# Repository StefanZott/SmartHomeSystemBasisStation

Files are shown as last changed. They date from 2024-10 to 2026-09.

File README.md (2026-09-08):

# SmartHomeSystemBasisStation

## Kurzbeschreibung

SmartHome-Basisstation auf Basis des **ESP32-S3** mit eigener Platine, ESP-IDF-Firmware und Web-Oberfläche zur WLAN-Konfiguration und Gerätediagnose. Das Repository bündelt Hardware (KiCad), Firmware und SPIFFS-Web-Assets in einem Projekt.

## Architektur-Überblick

| Pfad | Inhalt |
|---|---|
| `main/` | Firmware (ESP-IDF), Einstieg `main.c` |
| `spiffs/` | Web-UI (HTML, CSS, JS) → SPIFFS-Image |
| `pcb/` | KiCad-Schaltplan und Layout der Basisstation |
| `docs/` | Projektdokumentation und Anwenderdoku |

Stückliste und Pinout: [docs/project/hardware.md](docs/project/hardware.md)

## Toolchain

- **Firmware:** [ESP-IDF](https://docs.espressif.com/projects/esp-idf/) **v5.5.2** für ESP32-S3, Build über `idf.py`
- **IDE:** VS Code mit ESP-IDF-Erweiterung; optional Dev Container (`.devcontainer/`)
- **Hardware:** KiCad 8/9 — Projekt unter `pcb/BasisStation/`

## Deep Dive

Technische Architektur, Module, Startablauf und Verzeichnisstruktur:

→ [docs/project/architecture.md](docs/project/architecture.md)

Weitere Themen: [Kommunikation](docs/project/communication.md) · [Sicherheit](docs/project/security.md) · [Speicher-Layout](docs/project/memory_map.md)

## Deployment

Build, Flash und Monitor (Kurzfassung):

```text
idf.py set-target esp32s3
idf.py build
idf.py flash monitor
```

Ausführliche Anleitung, Partitionierung und Voraussetzungen:

→ [docs/project/architecture.md#deployment](docs/project/architecture.md#deployment)

## Release & Tags

Aktuelle Firmware-Version: siehe Datei [`version`](version) (Format `X.XX.XXX`, derzeit `0.00.001`).

| Tag (Beispiel) | Bedeutung |
|---|---|
| `v0.00.001` | Veröffentlichte bzw. testbare Firmware-Version |
| `release` | Marker für den aktuellen Release-Stand im Repository |

Kundenspezifische Builds: `v0.00.005-kundexyz`. Details: [docs/userdoc/git_guidelines.md](docs/userdoc/git_guidelines.md).

Agenten-Regeln und Workflow: [CLAUDE.md](CLAUDE.md)

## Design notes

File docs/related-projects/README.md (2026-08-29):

---
status: active
last_updated: 2026-06-02
type: placeholder
---

# Verzahnte Projekte

Schnittstellenverträge zu anderen Projekten (gemäß CLAUDE.md §7).

| Datei | Thema |
|---|---|
| [project-scope.md](project-scope.md) | Produktscope, Entscheidung NRT/UART, dokumentierte Schnittstellen |

Weitere Dateien (z. B. Cloud-Backend) folgen bei Bedarf.

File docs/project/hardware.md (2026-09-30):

---
status: active
last_updated: 2026-09-30
type: project-doc
---

# Hardware — SmartHome-Basisstation

KiCad-Layout und physische Schnittstellen der SmartHome-Basisstation auf Basis **ESP32-S3-WROOM-1U-N16R8**.

## Zielbild

Smart-Home-Basisstation mit Tastern, USB-C-Debuganschluss, PROG-Header, WLAN-Antenne, vier LEDs (Rot, Grün, Blau, Gelb) und **Ethernet** über W5500.

## Physische Schnittstellen

| Schnittstelle | Zweck |
|---|---|
| USB-C (`J1`) | Debug- und Datenanschluss: natives USB-Serial-JTAG des ESP32-S3. Flashen und On-Chip-Debugging über einen Stecker. Keine Stromversorgung über diesen Port. |
| PROG (`J6`) | 6-poliger Header: Firmware flashen über UART (alternativ über `J1`) |
| WLAN | Externe 2,4-GHz-Antenne über U.FL-Pigtail und RP-SMA-Gehäusebuchse (Modul **1U**) |
| Ethernet | Kabelgebundene Netzwerkverbindung über **WIZnet W5500** (SPI). Architektur und Begründung: [ethernet.md](ethernet.md). Schaltplan in Arbeit (SHBS-5), Layout offen (SHBS-10), Firmware offen (SHBS-11) |

**Separater JTAG-Header entfallen.** Der ESP32-S3 bringt USB-Serial-JTAG im Chip mit; On-Chip-Debugging läuft über `J1`. Der frühere 10-polige Header `J5` wurde deshalb aus dem Schaltplan entfernt — ein Steckverbinder und dessen Platinenfläche weniger.

## Steckverbinder (KiCad / BOM)

Im BOM werden u. a. Würth-Stecker **61201021621** (10-pol) und **61200621621** (6-pol) genannt — Details und Signalbelegung im jeweiligen KiCad-Schaltplan bzw. Datenblatt.

Ausführliche Stückliste mit Links: `README.md` (Abschnitt Hardware) — bei Änderungen auf **ESP32-S3-WROOM-1U-N16R8** abstimmen (README enthält teils gemischte Modulreferenzen).

## WLAN-Antenne (U6, ESP32-S3-WROOM-1U-N16R8)

Das Modul **1U** hat **keine PCB-Antenne**; der RF-Anschluss ist ein **IPEX/U.FL**-Stecker am Modul. Ohne externe Antenne ist WLAN nicht nutzbar.

### RF-Kette (mechanisch, kein Kupfer-RF auf der Platine)

```
U6 (IPEX) ←steckt→ ANT1 Pigtail ←SMA-Bulkhead→ Gehäusewand ←schraubt→ ANT2 Antenne (außen)
```

| Referenz | Teil | Funktion |
|---|---|---|
| **ANT1** | Taoglas **CAB.6061** | U.FL → RP-SMA female bulkhead, 100 mm Koax, mit O-Ring |
| **ANT2** | Taoglas **GW.20.A151** (Nachfolger der abgekündigten GW.20.5150) | 2,4 GHz Dipol, 2 dBi, RP-SMA male |

Beide Teile sind im Schaltplan `BasisStation_Layout.kicad_sch` als **mechanische BOM-Einträge** (`on_board no`) dokumentiert — sie werden **nicht** auf die Leiterplatte gelötet.

**Polarität:** Pigtail und Antenne müssen **RP-SMA** (Reverse Polarity) sein — nicht mit Standard-SMA mischen.

### Montage

1. Nach SMD-Bestückung: U.FL-Stecker von ANT1 vorsichtig auf den IPEX am Modul U6 aufklicken (gerade, ohne Zug auf dem Kabel).
2. RP-SMA-Bulkhead von ANT1 durch die **Gehäusebohrung** führen und mit der mitgelieferten Mutter fixieren (O-Ring zur Dichtung).
3. ANT2 von außen auf die Bulkhead-Buchse schrauben.

### Gehäuse und PCB — Platzierung

| Thema | Empfehlung |
|---|---|
| **SMA-Bohrung** | Ca. **6,5 mm** Durchmesser für RP-SMA-Bulkhead (exakter Wert im Datenblatt CAB.6061 prüfen). |
| **Bulkhead-Position** | **Rechte Gehäusewand**, auf Höhe des U.FL-Steckers (Platine y ≈ 96, seit SHBS-52). Der Kabelweg ist dann ca. 18 mm lang und gerade. Weit weg von Metallflächen und anderen HF-Quellen |
| **Abstand U6** | Kein dichtes Metall/Kupfer direkt am IPEX-Anschluss; Kabel nicht über USB-, Ethernet- oder Magnetics-Bereiche führen. |
| **PCB-Layout** | Kein RF-Routing auf der Platine nötig. U6 sitzt seit SHBS-52 rechts auf halber Höhe, der U.FL-Stecker zeigt zur rechten Wand. Zwischen Stecker und Wand liegt kein Bauteil, J6 sitzt 6 mm tiefer |

### BOM / Beschaffung

Mouser-Referenzen: CAB.6061 → **`960-CAB.6061`** (845 ab Lager, Stand 2026-09-22). Alternativ gleichwertige U.FL→RP-SMA-Bulkhead- und 2,4-GHz-RP-SMA-Antennen-Kombinationen — **Polarität und Steckertyp beibehalten**.

`ANT2` ist seit 2026-09-23 (SHBS-16) der Taoglas-Seriennachfolger
**`GW.20.A151`** (`960-GW.20.A151`); der ursprünglich vorgesehene `GW.20.5150`
ist abgekündigt. Form, Anschluss und Gewinn sind gleich (2 dBi, 2,4 GHz,
RP-SMA(M) gerade), eine weiße Variante `960-GW.20.A151W` gibt es ebenfalls.
Taoglas führt bei Mouser inzwischen das Präfix `960-` statt `742-`. `ANT1` und
`ANT2` sind mit `on_board no` reine BOM-Einträge; kein Footprint betroffen.
Aktuelle Preise und Lager: bestellfähige Stückliste (Abschnitt unten).

Symbol-Bibliothek: `pcb/Bauteile/Mechanical/mechanical.kicad_sym` (`WLAN_Pigtail`, `WLAN_Antenna`).

## Debug-/Datenanschluss J1 (SHBS-6)

`J1` ist eine **USB-C-Buchse** (Amphenol **12401598E4#2A**, dieselbe Bauform wie der Versorgungsport `J_PWR1` — eine BOM-Position für beide). Symbol: `Connector:USB_C_Receptacle_USB2.0_16P`, Footprint: `shbs_power:USB_C_Receptacle_Amphenol_12401598E4-2A`. Bis 2026-09-23 war die inzwischen abgekündigte `12401548E4#2A` vorgesehen; Unterschiede und Folgen fürs Layout siehe [power_supply.md](power_supply.md) (Abschnitt Buchsenwechsel).

| Eigenschaft | Umsetzung |
|---|---|
| Datenpfad | `J1` → ESD-Array `U1` (D3V3XA4B10LP-7) → `U6.14`/`U6.13` (GPIO20/GPIO19, USB_D+/USB_D−) |
| Steckrichtung | Beide Datenpaare gebrückt (`A6`+`B6` = D+, `A7`+`B7` = D−) — Stecker funktioniert in beiden Orientierungen |
| Rolle | **Sink/UFP**: je 5,1 kΩ **Rd** von `CC1` (`R21`) und `CC2` (`R22`) gegen GND |
| VBUS | Netz `VBUS_J1`, endet am ESD-Array. **Keine Versorgung über diesen Port** |
| SBU1/SBU2 | Unbeschaltet (No-Connect) |

**Zwei getrennte Ports.** Versorgung läuft ausschließlich über `J_PWR1` (siehe [power_supply.md](power_supply.md)), `J1` ist reiner Datenanschluss. Zum Flashen sind daher **zwei Kabel** nötig. Ein gemeinsamer Port und eine ORing-Lösung wurden verworfen; da `VBUS_J1` nirgends auf die Versorgungsschiene führt, besteht kein Rückspeise-Risiko zwischen den Ports.

Schaltplan: `pcb/BasisStation/BasisStation_Debugging.kicad_sch`.

**Layout (SHBS-22, 2026-09-27):**

- **U1 als Durchgangs-Bauteil:** Jede Leitung läuft gerade unter dem
  Gehäuse durch, von Pad 10→1 (USB−), 9→2 (USB+) und 7→4 (VBUS_J1). Neben
  den breiten GND-Pads 3/8 sind die Durchgänge für USB+ und VBUS_J1 nur
  0,15 mm breit. Der Footprint selbst hat nur 0,15 mm Padabstand; die
  5 DRC-Meldungen dazu sind footprint-bedingt und werden ausgeschlossen.
- **Brücken im Pad-Feld von J1:** D+ B6→A6 auf F.Cu. D− B7→A7 kreuzt D+
  geometrisch und läuft daher über ein Via oberhalb der B-Reihe
  (89,5 / 33,8) auf B.Cu zum USB−-Via (88,5 / 38,0). VBUS_J1: B4→A9 und
  B9→A4. Die Gruppe A4/B9 ist von CC1 eingeschlossen und geht über ein Via
  (90,85 / 37,6) auf B.Cu zu einem Via unter U1-Pin 4 (87,8 / 44,0).
- USB D+/D− sind seit der Verlegung von U6 (SHBS-52) 138 bzw. 124 mm lang,
  mit je 3 Vias. Für USB Full-Speed (12 Mbit/s, Anstiegszeit einige ns) sind
  Länge und Längenunterschied (14 mm, ca. 0,1 ns) unkritisch.

## Stromversorgung (SHBS-4)

Primäre Versorgung: **USB-C 5 V → AP3211 Buck → 3,3 V** (bis SHBS-17: MP2359, abgekündigt). PS2/+12V entfernt.

Ausführliche Dokumentation (Schaltplan, BOM, Pinbelegung, Verdrahtung): **[power_supply.md](power_supply.md)**.

**Layout-Stand (2026-09-26, SHBS-21):** Buck-Wandler kompakt um PS1 platziert, +3V3 zu U6 und zu den LED-Anoden geroutet. Details und Begründung der Leitungsführung: [power_supply.md](power_supply.md), Abschnitt „Platzierung Buck-Wandler“.

## Status-LEDs (SHBS-9)

Vier Status-LEDs, **direkt vom GPIO getrieben**: GPIO → Vorwiderstand →
LED-Anode, Kathoden gemeinsam auf GND. Ein GPIO auf **High** schaltet die
zugehörige LED **ein**.

| LED | Farbe | GPIO (Modul-Pad) | Vorwiderstand (0805) |
|-----|---|---|---|
| `D7` | Gelb | GPIO21 (23) | `R13`, 220 Ω |
| `D9` | Rot | GPIO38 (31) | `R15`, 220 Ω |
| `D10` | Grün | GPIO47 (24) | `R16`, 220 Ω |
| `D8` | Blau | GPIO48 (25) | `R14`, 100 Ω |

**Warum ohne Transistoren (SHBS-40, 2026-09-30):** Bis dahin schaltete je
ein NPN-Transistor BC337 (Q1–Q4, Basiswiderstände R23–R26) die LED gegen
GND, Vor- und Basiswiderstände waren 2-W-THT-Typen (DIN0617, 17 mm). Ein
Hardware-Review hat beides als überdimensioniert bewertet. Ein GPIO des
ESP32-S3 liefert bei der Standard-Treiberstufe rund 20 mA, bei der höchsten
rund 40 mA. Eine LED braucht hier etwa 5 mA, alle vier zusammen 20 mA. Der
Treiber entfällt damit ersatzlos; an den Widerständen fallen nur einige mW
ab, 0805 reicht mit großer Reserve.

**Symbol und Polarität (SHBS-16, 2026-09-23):** Alle vier LEDs nutzen
`Device:LED` (Pin 1 = Kathode, Pin 2 = Anode). Die beiden Würth-Footprints
`WL-TMRC_3MM` (D7, D10) und `WL-TMRW_3MM` (D8, D9) sind gleich nummeriert:
Pad 1 = Kathode (abgeflachte Seite), Pad 2 = Anode (`+` im Bestückungsdruck).
Das war nicht immer so — `WL-TMRC_3MM` kam vom Hersteller mit vertauschter
Nummerierung (Pad 1 = Anode). Zusammen mit `Device:LED` war **D10 dadurch
verpolt** und hätte nie geleuchtet; D7 war nur deshalb richtig, weil es das
Würth-eigene Symbol nutzte. Der Footprint ist jetzt umnummeriert, das
Würth-Symbol `WL-TMRC_3MM` entsprechend mitgezogen. Die Platine nutzt die
korrigierte Nummerierung (beim PCB-Abgleich SHBS-42 geprüft).

**Dimensionierung:** Am GPIO liegen bei High und rund 5 mA Last etwa 3,2 V.
Rot, Gelb und Grün haben ca. 2,0–2,2 V Flussspannung, 220 Ω ergeben rund
5 mA. Die blaue LED `151033BS03000` hat typ. 2,8 V (max. 3,6 V). Mit 220 Ω
blieben nur etwa 1–2 mA, sie leuchtete kaum (das galt schon mit Transistor
an +3V3). Mit 100 Ω fließen typ. 3–5 mA. Die blaue LED ist mit 3,8 cd
trotzdem deutlich heller als die anderen. Helligkeit per PWM (LEDC) in der
Firmware angleichen. Liegt ein Exemplar nahe an der maximalen
Flussspannung, bleibt es dunkel. Am Prototyp prüfen.

**Pinwahl:** Bewusst auf GPIOs **ohne** Strapping-, ADC- oder Touch-Funktion gelegt. Die Strapping-Pins GPIO3, GPIO45 und GPIO46 waren zuvor belegt und sind jetzt frei — ein an der LED hängender Pegel hätte beim Reset die Boot-Konfiguration beeinflussen können (GPIO45 = VDD_SPI-Spannung, GPIO46 = ROM-Log, GPIO3 = JTAG-Quellenwahl). GPIO3 bleibt auch nach dem Wegfall von `J5` unbelegt: Das Strapping wählt zwischen internem USB-Serial-JTAG und externen JTAG-Pins und darf beim Reset nicht verzogen werden.

**Nicht verwenden:** GPIO35, GPIO36 und GPIO37 erscheinen in der Netzliste als frei, sind beim Modul **N16R8** aber intern vom Octal-PSRAM belegt.

**Firmware:** Die Pinzuordnung in `main/LED.h` entspricht noch der alten
Belegung (GPIO46/3/45/21) und muss nachgezogen werden. Die Logik (High = an)
bleibt gleich.

**Liegende Montage (SHBS-42, 2026-09-30):** Die LEDs schauen durch die
Gehäusewand an der Unterkante heraus. Dazu werden die Beine um 90° gebogen,
die LED liegt parallel zur Platine. Footprint:
`LED_THT:LED_D3.0mm_Horizontal_O1.27mm_Z2.0mm` aus der KiCad-Bibliothek, mit
3D-Modell.

| Maß | Wert |
|-----|---|
| Biegung | 1,27 mm hinter der Pad-Reihe (Abstand Pad – Kragen) |
| LED-Mitte über Platine | 2,0 mm |
| Pad-Reihe | y 155,43, Kathode (Pad 1, eckig) links |
| Linsenspitze | y 162,0 = 2,0 mm vor der Kante, bündig mit der Außenseite der 2 mm dicken Wand |
| Lichtaustritt (x) | 112,0 / 123,73 / 134,73 / 144,73 (unverändert) |
| Gehäusebohrung | je LED ca. 3,2 mm, Mitte 2,0 mm über der Platinenoberseite |

Die Würth-LEDs bleiben, nur die Beine werden gebogen. Die Maße gehen von
der üblichen Bauform aus (5,3 mm vom Kragen bis zur Linsenspitze). Am
Muster prüfen und die Pad-Reihe notfalls verschieben.

Schaltplan: `pcb/BasisStation/BasisStation_Layout.kicad_sch`. Layout: die
Vorwiderstände (0805) sitzen direkt über der jeweiligen LED-Anode, die
Kathoden hängen an der GND-Fläche (SHBS-42).

## Ethernet (SHBS-5)

Kabelgebundene Netzwerkanbindung über **WIZnet W5500** am SPI-Bus, RJ45-Buchse
**Würth 7499011121A** mit integrierten Magnetics. Schaltplanblatt
`pcb/BasisStation/ethernet.kicad_sch`.

**Warum SPI und nicht RMII:** Der ESP32-S3 besitzt — anders als der
ursprüngliche ESP32 — keine EMAC-Peripherie. Ein RMII-PHY findet im SoC keine
Gegenstelle. Der W5500 bringt MAC und PHY selbst mit und hängt am SPI-Bus.

| Netz | W5500-Pin | GPIO | Modul-Pad |
|---|---|---|---|
| `ETH_RST` | 37 `RSTn` | 9 | 17 |
| `ETH_SCSn` | 32 `SCSn` | 10 | 18 |
| `ETH_MOSI` | 35 `MOSI` | 11 | 19 |
| `ETH_SCLK` | 33 `SCLK` | 12 | 20 |
| `ETH_MISO` | 34 `MISO` | 13 | 21 |
| `ETH_INT` | 36 `INTn` | 14 | 22 |

Gewählt wurden die nativen **FSPI-Pins** (IO-MUX statt GPIO-Matrix), die am
Modul zudem auf den zusammenhängenden Pads 17–22 liegen. Dadurch belegt sind
ADC1_CH8 und ADC1_CH9; **GPIO1–GPIO8 bleiben frei** für analoge Sensorik.

Die Versorgung ist in `+3V3` (digital) und `+3V3A` (analog) getrennt,
verbunden über eine Ferritperle.

Architektur, Bauteilliste, Beschaltung und Begründungen: **[ethernet.md](ethernet.md)**.

## Gesamt-Layout (SHBS-23, SHBS-10, SHBS-42 — Stand 2026-09-30)

Platine **160 × 132,55 mm** (Kontur x 50–210, y 27,45–160), 2 Lagen, 1,6 mm.
Fest vorgegeben waren T1, J1, J_PWR1 und D7–D10.

**Buchsen-Überstand für das Gehäuse:** Die obere Kante liegt so, dass
J_PWR1, J1 (Front bei y 26,22) und T1 (26,14) **1,2–1,3 mm über die
Platinenkante** hinausragen. Mehr lassen die USB-C-Buchsen nicht zu: Ihre
vorderen Befestigungslaschen (S1, Kupfer ab y 27,96) brauchen 0,5 mm
Randabstand. Mit 0,3 mm Randabstand (übliches Fertigungsminimum) wären
1,44 mm möglich, dafür müsste die Projektregel gelockert werden. Die
RJ45-Buchse allein könnte bis etwa 5,5 mm überstehen, bräuchte dafür aber
eine Stufe in der Kontur. Die Montagelöcher H1/H2 sind mit der Kante um
2,45 mm nach unten gewandert. Der Silkscreen-Umriss von T1 läuft über die
Kante und wird bei der Fertigung abgeschnitten.

| Bereich | Lage | Begründung |
|---|---|---|
| **U6** (ESP32-S3) | rechts, halbe Höhe (185 / 90), um 90° gedreht | U.FL zur rechten Wand, SPI-Pins nach links zum W5500, USB/EN nach oben. Verlegt mit SHBS-52 |
| **U7** (W5500) | rechts neben T1 | TX/RX-Pins zeigen zu T1, SPI und Quarz zu U6 |
| Y1, C25/C26 | rechts an U7 | Kurze XI/XO-Leitungen |
| Abblock-C, FB1 | unter U7 | Zwei Reihen, Spalten 4 mm, Reihen 5,5 mm (Handlötung), TOCAP/1V2O am nächsten an den Pins |
| Pull-ups R28–R32 | Reihe über U7 | Raster 4 mm |
| S2 | obere Kante zwischen T1 und U6, liegend | Reset von außen durch die Gehäusewand (SHBS-25, siehe unten) |
| R9 | links neben C7 über U6 | Pull-up EN, seit SHBS-42 0805 statt THT |
| J6 | rechter Rand, untere Hälfte (203 / 110) | Programmierstecker, von außen gut erreichbar; Leitungen zu U6 auf B.Cu |
| C8 | über U6 am 3V3-Pin | Lokaler Puffer am 3V3-Pin des Moduls |
| C10, C12 | unter U6 (178 / 108 und 118,5) | Puffer für +3V3 |
| C7 (EN-Kondensator) | über U6 am EN-Pin (178 / 74) | RC-Glied mit R9, Filter direkt am Pin. Die EN-Leitung zu S2 an der Oberkante ist dadurch lang, aber am Pin gefiltert |
| Buck-Wandler | linke Hälfte (PS1 bei 68 / 87,5) | Weg von den Buchsen, siehe [power_supply.md](power_supply.md) |
| R13–R16 | direkt über der LED-Anode | Vorwiderstände, seit SHBS-42 ohne Transistorstufe |
| D7–D10 | Unterkante, liegend | Schauen durch die Gehäusewand, siehe „Status-LEDs“ |

**Ethernet-Paare:** TX± und RX± sind von Hand geroutet und gesperrt. RX
verlässt T1 durch den Kanal zwischen den beiden Pad-Reihen, die
Koppel-Kondensatoren C30/C29 sitzen versetzt hintereinander. So kreuzen sich
die Paare nicht. Länge unter 20 mm. **Keine definierte Impedanz:** 100 Ω
differenziell ist auf 2 Lagen mit 1,6 mm Dielektrikum nicht einstellbar. Bei
diesen kurzen Wegen ist das für 100BASE-TX unkritisch, bei Problemen am
Prototyp wäre ein 4-Lagen-Aufbau die Abhilfe. Der Abschluss R36 (TD+) ist
über ein Via-Paar angebunden, weil TD− darüber liegt.

**Chassis-Fläche:** Zone `CHASSIS_RJ45` (beide Lagen, Priorität 5) unter der
Buchsenfront, x 104–130 / y 25,5–41,5. GND-Flächen halten 0,5 mm Abstand.
Die Kopplung erfolgt nur über R35 ‖ C28 links unter T1.

**Routing:** Die übrigen Netze hat Freerouting 2.4.1 geroutet, vorhandene
Leitungen waren gesperrt. Ein zweiter Durchgang (alles andere gesperrt)
hat USB− ergänzt. RXN → R40 ist von Hand über ein Via-Paar auf B.Cu
angebunden, weil R40.1 auf F.Cu von RCT eingeschlossen ist. Isolierte GND-Pads und Flächeninseln (vor allem die
inneren GND-Pins des W5500) sind über kurze Stiche auf GND-Vias zur
durchgehenden Rückseitenmasse angebunden. Unter U7 verbindet eine
Sammelleitung die +3V3A-Pins. DRC: **keine offenen Verbindungen**, keine
Abstandsfehler außer den footprint-bedingten an U1/J1.

**Verteilung (SHBS-42, 2026-09-30):** Nach einem Hardware-Review war die
Bestückung zu gedrängt: Fast alles saß in der oberen Hälfte, 22
Bauteilpaare lagen enger als 1 mm, mehrere berührten sich. Jetzt:

- Die Blöcke sind über die Platine verteilt. Der Buck-Wandler sitzt in der
  linken Hälfte, C7/C10/C12, R9 und J6 in der rechten Hälfte darunter.
- Oben bleibt nur, was an Buchsen oder ICs gebunden ist: T1, J1, J_PWR1, S2,
  U7 mit Abblock-Cs, Quarz und Pull-ups. U6 sitzt seit SHBS-52 rechts auf
  halber Höhe (siehe Tabelle). Die SPI-Leitungen zum W5500 sind dadurch
  61–66 mm lang. Den SPI-Takt in der Firmware zunächst auf 20 MHz setzen und
  höhere Takte am Prototyp prüfen.
- Zwischen den Bestückungsflächen sind überall mindestens 1 mm frei, meist
  1,5 mm und mehr. Die einzige Ausnahme außerhalb der MDI-Gruppe ist C16 an
  Y1 (1,03 mm): Er ist Abblock-C am W5500 und bleibt am Pin.
- Transistorstufe der LEDs entfallen, R9 und R13–R16 als 0805.

**Bewusst unverändert:** die Ethernet-MDI-Gruppe an T1 (R35–R40, C28–C30).
Dort liegen die von Hand gerouteten, gesperrten Paare. R36/R37 (0,2 mm) und
C29/C30 (0,45 mm) bleiben enger als 1 mm. Ein Verschieben hätte die
Paarführung aufgebrochen.

**Neu-Routing:** Die getrennten Netze (u. a. +3V3, +5V, SW, LED, EN, Quarz,
SPI zum W5500) hat Freerouting 2.4.1 neu geroutet. Die übrigen Leitungen des
alten Stands blieben erhalten, weil sie an unveränderten Bauteilen hängen.
Die GND-Stiche an U7 und J1/U1 sowie die +3V3A-Sammelleitung unter U7 sind
aus dem alten Stand übernommen. Unter U7 schloss die +3V3-Hauptleitung auf
B.Cu zusammen mit der XO-Leitung eine GND-Insel ein, in der Pin 29 und C16
hingen. Die Hauptleitung läuft deshalb dort auf y 53, das +3V3-Via für C16
und Pin 28 sitzt direkt unter C16. Pin 29 geht auf F.Cu an C16.2. Freerouting läuft im Dev-Container ohne
Installation: JRE 25 und das JAR in einem temporären Verzeichnis. Beim
Einlesen der SES-Datei ersetzt KiCad **alle** Leiterbahnen und verliert dabei
Handrouten. Deshalb wurden nur die neuen Leiterbahnen übernommen.

Montagelöcher heißen im PCB **H1–H4** (vorher alle `REF**`). Der
Specctra-Export braucht eindeutige Referenzen. Sie sind als
„nur Platine" markiert (kein Schaltplan-Symbol nötig).

### DRC: Regeln und Ausschlüsse (Stand 2026-09-30)

`kicad-cli pcb drc --schematic-parity`: **0 offene Verbindungen, 0
Schaltplan-Abweichungen, 0 offene Fehler.** Übrig sind 17 bewusst
ausgeschlossene Meldungen. Die Begründung steht jeweils als Kommentar in
`BasisStation.kicad_pro`:

| Meldung | Anzahl | Grund |
|---|---:|---|
| `copper_edge_clearance` J_PWR1, J1 | 4 | Hersteller-Landepattern Amphenol: A12/S1 liegen 0,30 mm am ovalen NPTH, KiCad behandelt NPTH als Kante |
| `starved_thermal` J1, J_PWR1 | 3 | Pad hat nur einen Thermal-Steg, ist aber zusätzlich per Leiterbahn oder Via an GND angebunden. Sechs weitere Ausschlüsse sind mit SHBS-42 entfallen, weil die Bauteile verschoben oder anders angebunden sind |
| `silk_edge_clearance` T1 | 2 | Silkscreen-Umriss ragt mit der Buchse über die Kante, wird bei der Fertigung abgeschnitten |
| `silk_edge_clearance` D7–D10 | 8 | Liegende LEDs ragen mit der Linse 2 mm über die Kante in die Gehäusewand, die Kontur wird abgeschnitten |

**Regeln statt Ausschluss:** Die Thermal-Stege an S2 siehe „Reset-Taster S2". Die fünf Padabstände von 0,15 mm am ESD-Array U1
sind eine Eigenschaft seines Landepatterns. `BasisStation.kicad_dru` erlaubt
sie ausschließlich innerhalb von U1.

**Hinweis für Skripte:** Ausschlüsse greifen nur bei exakter Marker-Position.
Diese liegt nicht immer auf einer Pad-Position, bei `starved_thermal` aber
schon.

### Reset-Taster S2 von außen (SHBS-25, 2026-09-29)

S2 (EN, Reset) ist ein **liegender Taster C&K PTS645VL58-2 LFS** an der oberen
Kante, auf derselben Seite wie USB-C und RJ45. Sein Stößel zeigt zur Kante und
wird **bündig mit der Gehäuseaußenseite** gedrückt.

| Maß | Wert |
|-----|---|
| Wandstärke Gehäuse | 2,0 mm, Innenseite an der Platinenkante (y 27,45) |
| Stößelspitze | y 25,45 = 2,0 mm vor der Kante, also in der Außenwand |
| Pins | (169,5 / 31,35) und (174,0 / 31,35), Stößelspitze 5,9 mm vor den Pins |
| Gehäusefront des Tasters | 1,05 mm hinter der Platinenkante |

Vorher war S2 ein stehender Bourns 1543-650-149 mitten auf der Platine, im
Gehäuse nicht erreichbar. Der PTS645 wurde gewählt, weil es für ihn Footprint
und Herstellermodell in der KiCad-Bibliothek gibt und er breit lieferbar ist
(Mouser 611-PTS645VL582, DigiKey CKN9116-ND). Die Bibliothek liegt in
`pcb/Bauteile/PTS645VL58-2LFS/`. Das Schaltsymbol `1543-650-149` (Taster,
2 Pins) wird weiterverwendet, nur Footprint und Bestellfelder sind umgestellt.

Das GND-Pad hat auf F.Cu nur einen Thermal-Steg, weil EN und USB− dicht
daneben laufen. Es ist durchkontaktiert und auf B.Cu voll angebunden.
`BasisStation.kicad_dru` erlaubt deshalb für S2 einen Steg. Ein Ausschluss war
nicht möglich: Bei diesem Pad liegt der DRC-Marker nicht auf der Pad-Mitte.

### 3D-Modelle (SHBS-24, 2026-09-29)

Alle Bauteile haben ein 3D-Modell, eingetragen im Bibliotheks-Footprint unter
`pcb/Bauteile/` und in der Platine.

| Bauteile | Modell | Hinweis |
|---|---|---|
| C7, C10, C12 | `Bauteile/WCAP-FTXX_P10/WCAP-FTXX_P10.step` | Hersteller-Modell, war vorhanden, aber nicht verknüpft. Ursprung in Bauteilmitte, daher **Z-Versatz 6 mm** (vom Bediener ermittelt) |
| J6 | `Bauteile/wuerth_6120XX21621/6120XX21621_61200621621.step` | dito, **Z-Versatz 4,5 mm** |
| S2 | `Bauteile/PTS645VL58-2LFS/SW_Tactile_SPST_Angled_PTS645Vx58-2LFS.step` | Herstellermodell aus der KiCad-3D-Bibliothek (seit SHBS-25). Das selbst erstellte Modell des früheren Bourns 1543-650-149 liegt weiter unter `Bauteile/1543-650-149/`, wird aber nicht mehr verwendet |
| C8 | KiCad `CP_Radial_D6.3mm_P2.50mm` | Ersatz mit passenden Maßen. Pin 1 (+) des Footprints liegt rechts, daher 180° gedreht und 1,25 mm versetzt |
| D7–D10 | `Bauteile/WL-TMRC_3MM/…step`, `Bauteile/WL-TMRW_3MM/…step` | Würth-Originalmodelle (waren vorhanden), ohne Versatz, mit ungekürzten Anschlussdrähten |
| PS1 | KiCad `SOT-23-6.step` | vorher veraltete Variable `KISYS3DMOD` mit `.wrl` |
| J1, J_PWR1 | KiCad `USB_C_Receptacle_Amphenol_12401610E4-2A` | Nachbarvariante, für die Gehäusepassung nur eine Näherung |

Die KiCad-Standardmodelle lassen sich im Dev-Container nicht rendern
(3D-Bibliothek nicht installiert); geprüft werden sie im 3D-Viewer unter
Windows.

## Repository-Ist-Stand (KiCad)

| Bereich | Pfad / Artefakt |
|---|---|
| Hauptprojekt | `pcb/BasisStation/BasisStation.kicad_pro` |
| Schaltpläne | `BasisStation.kicad_sch` (Root) mit den Unterblättern `BasisStation_Layout.kicad_sch`, `BasisStation_Debugging.kicad_sch`, `Stromversorgung.kicad_sch`, `ethernet.kicad_sch` |
| Leiterplatte | `BasisStation.kicad_pcb` |
| Bauteilbibliotheken | `pcb/Bauteile/<Bauteil>/` — **ein Ordner je Bauteil** mit Symbol, Footprint und 3D-Modell (SHBS-12) |
| Mechanische BOM-Teile | `pcb/Bauteile/Mechanical/mechanical.kicad_sym` (ANT1, ANT2) |
| Power (USB-C, Buck) | `pcb/Bauteile/Power/` (J_PWR, PS1) |
| Ethernet | `pcb/Bauteile/W5500/`, `pcb/Bauteile/wuerth_7499011121A/`, `pcb/Bauteile/wuerth_830059532/` (SHBS-5) |
| ERC-Bericht | `pcb/BasisStation/ERC.rpt` (Stand 18.09.2026 nach SHBS-5: **0 Fehler, 7 Warnungen**) |
| Architektur-Diagramm | `pcb/architektur_basisStation.drawio` (Neuauflage 2026-09-24) als Blockskizze; Kurzfassung als Textdiagramm in [architecture.md](architecture.md). Nur die `.drawio` wird versioniert — PNG/PDF-Exporte nicht einchecken, sonst laufen die Kopien wieder auseinander (so geschehen bei der ersten Fassung). Das Bild im Root-Blatt `BasisStation.kicad_sch` ist ein Export davon und bei Änderungen neu einzufügen |

## Abgrenzung Firmware

Die Firmware in `main/` beschreibt das **Laufzeitverhalten** (WLAN, Webserver, LEDs). Ethernet ist **schaltplanseitig fertig** (SHBS-5); das **PCB-Layout** steht als **SHBS-10** aus, die **Firmware-Anbindung** über `esp_eth` als **SHBS-11**. In der aktuellen Firmware gibt es keine Ethernet-Nutzung. Hintergrund: [ethernet.md](ethernet.md).

Netzwerk-Konfiguration über HTTP: [communication.md](communication.md).

## Bibliotheksstruktur (SHBS-12)

Symbol, Footprint und 3D-Modell eines Bauteils liegen **gemeinsam** in
`pcb/Bauteile/<Bauteil>/`. Die früheren Sammelordner `pcb/Symbol/`,
`pcb/Footprints/` und `pcb/3D-Model/` gibt es nicht mehr.

Je Bauteilordner ist ein Eintrag in `sym-lib-table` (falls ein eigenes Symbol
existiert) und in `fp-lib-table` gesetzt. Alle Pfade sind über `${KIPRJMOD}`
projektrelativ — absolute Pfade sind unzulässig, weil sie nur auf einem
Rechner funktionieren.

Neues Bauteil anlegen:

1. Ordner `pcb/Bauteile/<Bauteil>/` mit Symbol, Footprint und 3D-Modell.
2. 3D-Referenz im Footprint auf `${KIPRJMOD}/../Bauteile/<Bauteil>/<Datei>`.
   Modelle aus der KiCad-Standardbibliothek werden über
   `${KICAD10_3DMODEL_DIR}/…` referenziert (SHBS-32).
3. Eintrag in `sym-lib-table` und `fp-lib-table` ergänzen.
4. Footprint-Vorgabe im Symbol auf `<Bibliothek>:<Footprint>` setzen.
5. Symbol im **aktuellen KiCad-Dateiformat** ablegen (siehe unten).

### Dateiformat der Symbolbibliotheken (SHBS-14)

Alle `.kicad_sym` im Projekt liegen im KiCad-9-Format (`version 20241209`).
Seit dem Umstieg auf KiCad 10 (SHBS-30) gilt die Regel sinngemäß für das
KiCad-10-Format: Sobald der Schaltplan in KiCad 10 gespeichert ist, die
Bibliotheken mit `kicad-cli sym upgrade` nachziehen.

Das ist keine Kosmetik: Liegt eine Bibliothek in einem älteren Format vor,
während der Symbol-Cache im Schaltplan schon KiCad 9 ist, meldet die ERC für
jedes betroffene Bauteil `lib_symbol_mismatch` — auch wenn Pins und Geometrie
identisch sind. Die Warnungen verdecken dann echte Befunde.

Von Herstellern oder SnapEDA bezogene Symbole kommen häufig im Format
`20211014` (KiCad 6) oder `20220914` (KiCad 7). Vor dem Einchecken umwandeln:

```
kicad-cli sym upgrade --force pcb/Bauteile/<Bauteil>/<Datei>.kicad_sym
```

Der Befehl ändert ausschliesslich die Syntax — Pins, Pinnummern, Pintypen und
Geometrie bleiben unangetastet. Bei der Umstellung der sechs Altbestände
(SHBS-14) wurden Netzliste und Stückliste vorher und nachher verglichen und
waren bitweise identisch.

**Nicht ausreichend:** Der Upgrade der Bibliothek allein räumt eine bereits
bestehende `lib_symbol_mismatch`-Warnung nicht ab. Der Symbol-Cache im
Schaltplan muss zusätzlich über *Werkzeuge > Symbole aus Bibliothek
aktualisieren* in der GUI aufgefrischt werden — dafür gibt es keinen
CLI-Befehl. Dabei darf das Footprint-Feld **nicht** zurückgesetzt werden,
sonst gehen die instanzweise gesetzten Footprint-Zuweisungen verloren.

Nicht umgestellt sind zwei Archivdateien, die in keiner `sym-lib-table`
registriert sind und nirgends verwendet werden:
`pcb/Bauteile/W5500/KiCADv6/2026-09-17_19-45-49.kicad_sym` und
`pcb/Bauteile/wuerth_7499011121A/WE-RJ45_7499011121A.kicad_sym`.

## ERC: hinterlegte Ausnahmen und Entwurfsregeln (SHBS-14)

Der Schaltplan ist so gebaut, dass `kicad-cli sch erc` **0 Fehler und
0 Warnungen** meldet. Nur so fällt ein neuer Befund sofort auf.

### Prüfe immer beide Werkzeuge

GUI und CLI können auseinanderlaufen. Am 22.09.2026 meldete die GUI 0
Verstöße, während das CLI noch eine Warnung führte — die GUI hatte schlicht
eine andere Instanz derselben Warnung erzeugt als das CLI. Ein grünes
Ergebnis aus nur einem der beiden Werkzeuge ist kein Nachweis.

Alle Verstöße einschließlich der ausgeschlossenen sichtbar machen:

```
kicad-cli sch erc --severity-all --format json -o erc.json BasisStation.kicad_sch
```

### Einzige hinterlegte Ausnahme

`pin_to_pin` an `S2` Pin 1 (Bidirectional) gegen `#FLG04` (Power output).
Das ist das GND-`PWR_FLAG`. Mit dem Wechsel von `Connector:USB_B_Micro` auf
`Connector:USB_C_Receptacle_USB2.0_16P` (SHBS-6) entfiel der einzige
ERC-Treiber des globalen GND-Netzes — das alte Steckersymbol deklarierte
seinen GND-Pin als *Power output*, das neue als `power_in`. `#FLG04` stellt
den Treiber wieder her; das ist der KiCad-Standardweg.

### Keine versteckten Power-Pins mit abweichendem Namen

Ein **versteckter** `power_in`-Pin verbindet sich in KiCad implizit mit einem
globalen Netz, das nach dem **Pinnamen** heißt. Ist derselbe Pin zusätzlich
explizit verdrahtet, kollidieren zwei Netznamen → `multiple_net_names`.

Aufgetreten an `U6` Pin 41, das Exposed Pad des ESP32-S3-WROOM-Moduls: Der
Pin hieß `EPAD` und war zugleich auf GND verdrahtet. Erschwerend erzeugte
KiCad **mehrere Instanzen** dieser Warnung, die den Pin je nach
Durchlaufreihenfolge mit unterschiedlichen GND-Power-Symbolen paarten —
ein Ausschluss per UUID hätte also nie dauerhaft getragen.

Behoben durch Umbenennung des Pins auf `GND` in
`pcb/Bauteile/ESP32-S3-WROOM-1U-N16R8/`. Das implizite Netz heißt seitdem
`GND` und deckt sich mit der Verdrahtung. Die Pin**nummer** 41 ist
unverändert, die Zuordnung zum Footprint-Pad also ebenfalls. Dass Pin 41 das
Exposed Pad ist, steht jetzt in der Symbolbeschreibung.

**Regel für neue Symbole:** Versteckte Power-Pins tragen den Namen des Netzes,
auf dem sie tatsächlich liegen. Ein abweichender, sprechender Name gehört in
die Symbolbeschreibung, nicht in den Pinnamen.

## KiCad-CLI im Dev-Container (SHBS-13)

`kicad-cli` ist das Kommandozeilen-Binary von KiCad. Es erzeugt ERC-, DRC-,
Netzlisten- und BOM-Ausgaben ohne GUI und macht damit prüfbar, ob eine
Schaltplan-Änderung tatsächlich fehlerfrei ist — vorher mussten diese
Artefakte manuell in der KiCad-GUI erzeugt und eingecheckt werden.

Installation und Versionsbindung stehen im [Dockerfile](../../.devcontainer/Dockerfile).
Zwei Punkte sind dort entscheidend:

- **KiCad 10 ist Pflicht (SHBS-30).** Nur KiCad 10 erzeugt PDFs mit
  eingebettetem 3D-Modell (siehe unten). Container und Arbeitsplätze müssen
  dieselbe Hauptversion haben: Eine in KiCad 10 gespeicherte Datei kann
  KiCad 9 nicht mehr lesen. Ubuntu 24.04 liefert nur KiCad 8, deshalb das
  PPA `kicad/kicad-10.0-releases`.
- **`kicad-packages3d` ist installiert.** Das Paket wiegt 3,2 GB, liefert
  aber die Standard-3D-Modelle (Widerstände, Kondensatoren, USB-C, …). Ohne
  es fehlen diese Bauteile im 3D-Export stillschweigend — `kicad-cli` meldet
  fehlende Modelle nicht. Symbole und Footprints werden für ERC, Netzliste
  und BOM benötigt.
- **Globale Bibliothekstabellen werden vorbelegt.** `kicad-cli` legt beim
  ersten Aufruf nur `fp-lib-table` selbst an, nicht `sym-lib-table`. Ohne diese
  Datei gelten sämtliche Standardbibliotheken (`power`, `Device`, …) als
  unbekannt und der ERC-Report füllt sich mit `lib_symbol_issues`. Das
  Dockerfile kopiert deshalb beide Vorlagen aus `/usr/share/kicad/template/`
  nach `~/.config/kicad/10.0/`. In KiCad 10 stammen die Vorlagen aus den
  Paketen `kicad-symbols` und `kicad-footprints`.

Typische Aufrufe gegen `pcb/BasisStation/`:

| Zweck | Befehl |
|---|---|
| ERC prüfen | `kicad-cli sch erc --output ERC.rpt BasisStation.kicad_sch` |
| Netzliste | `kicad-cli sch export netlist --output BasisStation.net BasisStation.kicad_sch` |
| Stückliste | siehe unten (`sch export bom` mit Feldliste) |
| DRC prüfen | `kicad-cli pcb drc --output DRC.rpt BasisStation.kicad_pcb` |

Die Stückliste muss die GUI-Voreinstellungen explizit mitbekommen, sonst
weichen Spalten und Gruppierung von der eingecheckten `BasisStation.csv` ab:

```
kicad-cli sch export bom \
  --fields 'Reference,Value,Datasheet,Footprint,${QUANTITY},${DNP}' \
  --labels 'Reference,Value,Datasheet,Footprint,Qty,DNP' \
  --group-by 'Value,Footprint' --ref-range-delimiter '' \
  --output BasisStation.csv BasisStation.kicad_sch
```

Einziger verbleibender Unterschied zur GUI-Ausgabe ist die DNP-Spalte: die
deutschsprachige GUI schreibt dort `Nicht bestücken`, die CLI `DNP`.

### Bestellfähige Stückliste (`tmp/bom/`)

Für den Abgleich gegen den Schaltplan reicht der CLI-Export oben. Für eine
**bestellfähige** Stückliste reicht er nicht, aus einem Grund: Teilenummern
liegen in diesem Projekt unter uneinheitlichen Feldnamen, je nachdem woher ein
Symbol stammt (SnapEDA, Würth-Generator, handgepflegt). Dieselbe Information
heißt mal `Manufacturer_Part_Number`, mal `MP`, mal `Part Number`;
Mouser-Nummern mal `Mouser Part Number`, mal `MOUSER_PART_NUMBER`.
`--fields` nimmt aber nur einen festen Namen und liefert für die übrigen
still eine leere Spalte — der erste Export blieb deshalb ohne Teilenummern.

[`tmp/bom/generate_bom.py`](../../tmp/bom/generate_bom.py) liest die
Schaltplanblätter daher direkt (eigener S-Expression-Parser in
[`sexp.py`](../../tmp/bom/sexp.py)), löst die Feld-Aliase auf, fragt Preis,
Lagerbestand und Lebenszyklus **bei Mouser und DigiKey** ab
([`digikey.py`](../../tmp/bom/digikey.py), Product Information V4, 2-legged
OAuth) und schreibt die Mappe über
[`write_xlsx.py`](../../tmp/bom/write_xlsx.py) nach
`pcb/BasisStation_Stueckliste.xlsx` — fester Name neben `BasisStation.pdf`,
jeder Lauf überschreibt sie, der Verlauf steht in Git (bis SHBS-19 unter
`tmp/report/`; die frühere Handliste `pcb/STL.xlsx` ist entfernt). Zugangsdaten:
`secrets/mouser_api_key` und `secrets/digikey_api.json`.

```
python3 tmp/bom/generate_bom.py            # mit API-Abfrage
python3 tmp/bom/generate_bom.py --no-network   # nur aus dem lokalen Cache
```

Zwei Entwurfsentscheidungen, die beim Lesen sonst überraschen:

- **Gruppiert wird nach Herstellerteilenummer, nur ohne Nummer nach Wert +
  Footprint — nie nach `lib_id`.** `J1` und `J_PWR1` nutzen verschiedene
  Symbole für dieselbe Amphenol-Buchse; für eine Bestellung ist das eine
  Position mit Menge 2. Die Teilenummer hat Vorrang, weil Werte über die
  Blätter uneinheitlich geschrieben sind (`100 nF` / `100nF`, `10uF` / `10 µF`).
- **Antworten werden in `tmp/bom/mouser_cache.json` und
  `tmp/bom/digikey_cache.json` zwischengespeichert.** Das schont die
  Tageskontingente und macht Läufe ohne Netz reproduzierbar. `--refresh`
  verwirft die Caches.
- **Gerechnet wird mit dem günstigsten lieferbaren Angebot (SHBS-17).** Die
  Spalte „Bezugsquelle“ steht auf dem Anbieter mit dem niedrigeren Preis, der
  die Menge ab Lager liefern kann; bei Gleichstand auf DigiKey. Sie ist per
  Auswahlliste änderbar; Einzelpreis, Gesamtpreis und die Teilsummen je
  Anbieter rechnen sich daraus. Wer alles über einen Anbieter bestellen will,
  um Versandkosten zu sparen, stellt die Spalte entsprechend um. Dauerhafte Festlegungen, die
  die Preisregel übersteuern, stehen mit Begründung in `SOURCE_OVERRIDES` in
  `generate_bom.py` und erscheinen in der Hinweisspalte — derzeit `U6` →
  Mouser (DigiKey mit nur zweistelligem Lager, Mouser mehrere Tausend;
  Bediener 2026-09-24).
- **Beide Anbieter werden zweistufig abgefragt:** erst die exakte Nummer, dann
  eine Stichwortsuche, die Verpackungssuffixe (`D3V3XA4B10LP` → `-7`) und
  herstellerneutrale Typen (`SS34`) auflöst. Nennt der Schaltplan einen
  Hersteller, bevorzugt die DigiKey-Suche dessen Treffer — sonst landet bei
  Typen wie `SMAJ5.0A`, die ein Dutzend Hersteller fertigen, der billigste
  Doppelgänger in der Bestellung. Verpackungen, deren
  Mindestbestellmenge über der Stückzahl liegt (Rollen), zählen nicht als
  Angebot.
- **Teilevorschläge stehen im Skript, bis sie freigegeben sind.** Für
  Positionen, die im Schaltplan nur einen Wert oder ein abgekündigtes Teil
  tragen, kann `PROPOSED_PARTS` in `generate_bom.py` einen Vorschlag halten;
  die Mappe markiert ihn mit Status „Vorschlag“. Nach Freigabe wandern die
  Teile als Felder `Manufacturer`, `Manufacturer_Part_Number` und
  `Mouser Part Number` in den Schaltplan, und der Eintrag im Skript entfällt
  — der Schaltplan bleibt die maßgebliche Quelle. Die Liste ist seit
  2026-09-23 leer: alle 29 Vorschläge aus SHBS-17 sind übernommen.
- **Hausstandard für Passivteile (SHBS-17, freigegeben 2026-09-23):**
  Widerstände Dickschicht 0805, 1 %, 0,125 W; Kondensatoren bis 100 nF X7R
  50 V, ab 1 µF X5R/X7R 16–25 V; C0G für die Quarz-Lastkondensatoren
  `C25`/`C26` (27 pF, gegen C<sub>L</sub> = 18 pF von `Y1` nachgerechnet);
  `C28` 1 nF/2 kV in 1206 für den Ethernet-Schirmabschluss.

Gefundene Abweichungen überschreiben die Schaltplan-Felder **nicht**, sondern
landen als Befund im Blatt „Offene Punkte“ — eine veraltete Teilenummer gehört
im Schaltplan korrigiert, nicht bei jedem Export stillschweigend übertüncht.

Schlägt ein Export mit einem Display-Fehler fehl, hilft `xvfb-run kicad-cli …`
— einzelne Unterbefehle erwarten je nach Version noch einen X-Server.

### Stand der Verifikation

Gegen die eingecheckten Artefakte geprüft (2026-09-19):

| Artefakt | Ergebnis |
|---|---|
| ERC | deckungsgleich — 7 Verstöße, 0 Fehler, 7 Warnungen |
| Netzliste | deckungsgleich — 102 Netze, identische Namen |
| Stückliste | deckungsgleich bis auf die DNP-Beschriftung (Sprache) |
| DRC | **abweichend** — CLI meldet 418 Verstöße gegen 8 im eingecheckten Report |

Die DRC-Abweichung betrifft ausschließlich Konflikte mit den beiden
GND-Zonen (`clearance`, `solder_mask_bridge`, `hole_clearance`). Naheliegende
Ursache: die GUI füllt Zonen vor dem DRC neu, `kicad-cli` rechnet mit dem im
Board gespeicherten — inzwischen veralteten — Füllstand. Bis das geklärt ist,
bleibt der DRC in der GUI die verbindliche Quelle; die CLI wird für ERC,
Netzliste und Stückliste genutzt.

Nach einem Update des Dockerfiles muss der Container neu gebaut werden
(*Rebuild Container*), sonst fehlt das Binary weiterhin.

### Umstieg auf KiCad 10: Befunde und Behebung (SHBS-30, SHBS-35)

Mit KiCad 9 waren ERC und DRC ohne Befund. `kicad-cli` 10.0.6 meldete gegen
den unveränderten Stand neue Befunde; alle sind behoben, ERC und DRC stehen
wieder auf **0 Fehlern und 0 Warnungen**. Die Platine liegt seitdem im
KiCad-10-Format (`version 20260206`) und lässt sich mit KiCad 9 nicht mehr
öffnen.

| Befund unter KiCad 10 | Ursache | Behebung |
|---|---|---|
| 2× `copper_edge_clearance`: NPTH-Loch von J1 zur GND-Zone 0,25 mm statt 0,5 mm | KiCad 10 wertet NPTH-Bohrungen als Platinenkante; die Zonen waren noch mit KiCad 9 gefüllt | Zonen mit KiCad 10 neu gefüllt (`pcb drc --refill-zones --save-board`) |
| 56× `footprint_symbol_field_mismatch` `Datasheet` | Board `~`, Schaltplan leer | Board-Feld auf den Schaltplanwert gesetzt |
| 1× `footprint_symbol_field_mismatch` an S2 | Footprint trug keines der SnapEDA-Felder des Symbols | Felder aus dem Schaltplan übernommen (verborgen, F.Fab) |
| 1× `lib_symbol_mismatch` an J1 | Siehe unten | J1 auf projekteigenes Symbol umgestellt |

Die DRC meldet `footprint_symbol_field_mismatch` **nur für das erste
abweichende Feld** eines Bauteils. Nach jeder Korrektur erneut prüfen, bis
0 Abweichungen übrig sind.

#### J1: Schirm-Pin in KiCad 10 umnummeriert

KiCad 10 hat im Standardsymbol `Connector:USB_C_Receptacle_USB2.0_16P` den
Schirm-Pin von `S1` auf `SH` umnummeriert. Der Footprint
`shbs_power:USB_C_Receptacle_Amphenol_12401598E4-2A` hat vier Schirm-Pads
`S1`. *Symbol aus Bibliothek aktualisieren* hätte den Schirm von J1
stillschweigend von GND getrennt.

J1 verweist deshalb auf `shbs_power:USB_C_Receptacle_USB2.0_16P` — eine Kopie
des bisherigen Symbols mit Pin `S1` in
[`power.kicad_sym`](../../pcb/Bauteile/Power/power.kicad_sym). Netzliste vorher
und nachher identisch, `J1.S1` an GND.

**Regel:** Vor *Symbole aus Bibliothek aktualisieren* nach einem
KiCad-Update die Pinnummern von Standardsymbolen gegen die Footprints
prüfen. Ein Symbol, das eng an einen eigenen Footprint gebunden ist, gehört
in die Projektbibliothek.

## Dokumentations-PDF mit 3D-Modell (SHBS-30)

[`pcb/export_pdf.sh`](../../pcb/export_pdf.sh) erzeugt ein einziges PDF unter
`pcb/export/BasisStation.pdf` (git-ignoriert):

1. Schaltplan, alle Blätter (`sch export pdf`)
2. Leiterplatte, eine Seite je Lage (F.Cu, B.Cu, Bestückungsdruck, Fab),
   Platinenumriss auf jeder Seite (`pcb export pdf --mode-multipage`)
3. Interaktives 3D-Modell (`pcb export 3dpdf`, U3D) — ohne DNP-Bauteile

Zusammengeführt wird mit `qpdf`, das Seiten samt Annotationen kopiert; das
3D-Modell überlebt den Merge. KiCad 10.0.6 schreibt in die 3D-PDF fehlerhafte
xref-Einträge, die `qpdf` beim Merge repariert (Warnung, kein Fehler).

Das 3D-Modell lässt sich nur in **Adobe Acrobat Reader** oder **Foxit**
drehen. Browser, Poppler (Evince, Okular) und macOS Vorschau zeigen auf der
letzten Seite eine leere Fläche.

## Pflege

Änderungen an Schaltplan, BOM oder Schnittstellen hier und in [communication.md](communication.md) nachziehen.

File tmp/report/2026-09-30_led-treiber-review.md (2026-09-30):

---
type: code-review
created: 2026-09-30
jira: SHBS-40
status: final
---

# Review LED-Treiber und Layout (Hinweise Hardwareentwickler)

## Ausgangslage

Ein Hardwareentwickler hat drei Punkte angemerkt:

1. R13–R16 und R23–R26 sind viel zu groß.
2. Das Layout ist trotzdem sehr gequetscht.
3. Q1–Q4 sind unnötig, weil die GPIOs genug Strom liefern. Das soll geprüft werden.

## Befunde

### 1. Widerstände R13–R16, R23–R26

- Footprint `Resistor_THT:R_Axial_DIN0617_L17.0mm_D6.0mm_P20.32mm_Horizontal`,
  Bauteil Vishay **PR02** (2-W-Metallschicht, 17 mm Körper, 20,32 mm Raster).
- Tatsächliche Verlustleistung: 220 Ω bei 5 mA ≈ 5,5 mW, 4,7 kΩ bei 0,55 mA
  ≈ 1,4 mW. Überdimensioniert um Faktor > 300.
- Alle übrigen 20 Widerstände sind SMD 0805. R9 (EN-Pull-up) ist als einziger
  weiterer THT-Widerstand (DIN0207) bestückt.
- **Bestätigt.** 0805 (125 mW) reicht mit großer Reserve und passt zum Rest.

### 2. Layout

Render der Oberseite: Die obere Hälfte (Versorgung, USB, Ethernet, U6) ist
dicht gepackt (Raster 3,5 mm, Beschriftungen überlappen teils). Die untere
Hälfte der Platine (160 × 132,55 mm) enthält nur die LED-Treiberkette und ist
sonst leer. Die Enge ist also eine Frage der Verteilung, nicht der Fläche.

- **Bestätigt.** Nach Wegfall der LED-Treiber wird zusätzlich Platz frei.

### 3. Transistoren Q1–Q4

- ESP32-S3 GPIO (Datenblatt ESP32-S3, DC-Kennwerte): Source-Strom bis ca.
  40 mA bei höchster Treiberstufe, Sink bis ca. 28 mA. Standard-Treiberstufe
  (Stufe 2) ca. 20 mA.
- Benötigt: ca. 5 mA je LED, 4 LEDs = 20 mA gesamt. Deutlich unter den Grenzen.
- Direktansteuerung `GPIO → Vorwiderstand → LED → GND` bleibt **aktiv High**,
  die Firmware-Logik ändert sich nicht.
- **Bestätigt: Q1–Q4 und R23–R26 können entfallen.**

### Nebenbefunde

- **Blaue LED D8 (151033BS03000):** Flussspannung blauer LEDs liegt typ. bei
  ca. 3 V. An 3,3 V (bisher über Q, künftig über GPIO-High ≈ 3,2 V) bleibt am
  Vorwiderstand kaum Spannung — D8 leuchtet mit 220 Ω nur sehr schwach. Das
  Problem besteht bereits im heutigen Entwurf. Vorwiderstand für Blau kleiner
  wählen (Wert nach Datenblatt, am Prototyp prüfen).
- **Firmware passt nicht zur Hardware:** `main/LED.h` nutzt noch GPIO46/3/45/21
  (alte Strapping-Pin-Belegung), der Schaltplan seit SHBS-9 GPIO48/21/47/38.
  Separates Ticket nötig.

## Empfehlungen

- Q1–Q4, R23–R26 entfernen, LEDs direkt über Vorwiderstand am GPIO.
- R13–R16 als 0805 SMD, Blau mit angepasstem Wert. Optional R9 ebenfalls 0805.
- Layout entzerren: Bauteilgruppen der oberen Hälfte in den freien Bereich
  verteilen; feste Positionen (T1, J1, J_PWR1, D7–D10) bleiben.

## Umsetzung (SHBS-41 bis SHBS-44)

- Schaltplan: Q1–Q4, R23–R26 entfernt, LEDs direkt am GPIO. R13/R15/R16
  220 Ω, R14 (blau) 100 Ω, R9 10 kΩ, alle YAGEO RC0805. ERC 0/0.
- Layout, erste Fassung: nur Abstände auf ≥ 1 mm gebracht. Der Bediener hat
  bemängelt, dass die Bauteile weiter in der oberen Hälfte sitzen.
- Layout, zweite Fassung: Blöcke über die Platine verteilt (Buck-Wandler
  links, C7/C10/C12/R9/J6 rechts unten). Oben bleiben nur Bauteile, die an
  Buchsen oder ICs gebunden sind. U7 und die MDI-Gruppe bleiben nach Wahl des
  Bedieners unverändert.
- LEDs D7–D10 liegend (Beine 90° gebogen), Linse bündig in der 2 mm dicken
  Gehäusewand an der Unterkante.
- DRC mit Schaltplanabgleich 0/0/0. 17 begründete Ausschlüsse (vorher 15:
  sechs starved_thermal entfallen, acht silk_edge_clearance für die LEDs neu).
- Draufsicht: [2026-09-30_layout-top-shbs42.png](2026-09-30_layout-top-shbs42.png)
- Doku: `docs/project/hardware.md`, `docs/project/power_supply.md`,
  Stückliste neu erzeugt.
- `pcb/export/BasisStation.pdf` neu erzeugt (nicht versioniert).

## Nachtrag SHBS-52: U6 in die rechte Hälfte

- U6 sitzt jetzt bei 185 / 90 und ist um 90° gedreht. Der U.FL-Stecker zeigt
  zur rechten Wand (Kabelweg ca. 18 mm).
- C8 und C7/R9 sitzen über U6, C10/C12 darunter.
- USB 124–138 mm, SPI 61–66 mm. Für USB Full-Speed ist das unkritisch, den
  SPI-Takt zunächst auf 20 MHz setzen.
- Neu entstandene GND-Inseln an U1 (USB+ auf B.Cu) sind behoben, J6-Pad 4
  ist über ein Via angebunden. DRC 0/0/0, 17 Ausschlüsse (unverändert).
- Draufsicht: [2026-09-30_layout-top-shbs52.png](2026-09-30_layout-top-shbs52.png)

## Offen

- Firmware `main/LED.h` nutzt noch GPIO46/3/45/21 (eigenes Ticket, vom
  Bediener zurückgestellt).
- Blaue LED D8 am Prototyp prüfen (Helligkeit, Exemplarstreuung der
  Flussspannung).
- Biegemaß und Länge der liegenden Würth-LEDs am Muster prüfen (Annahme:
  5,3 mm vom Kragen bis zur Linsenspitze).
- Gehäuse: RP-SMA-Buchse an die rechte Wand, auf Höhe des U.FL-Steckers.

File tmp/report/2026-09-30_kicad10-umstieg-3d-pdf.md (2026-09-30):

---
type: investigation
created: 2026-09-30
jira: SHBS-30
status: final
---

# Umstieg auf KiCad 10 und 3D-PDF-Export

## Ausgangslage

Gewünscht ist ein PDF mit Schaltplan, Leiterplatte und interaktivem 3D-Modell.
KiCad 9 kann kein 3D-PDF erzeugen; KiCad 10 bringt `pcb export 3dpdf` (U3D) mit.
Host läuft auf KiCad 10.0.6, der Devcontainer noch auf 9.0.9. Ohne Root-Rechte
im Container wurden die KiCad-10-Pakete aus dem PPA im Scratchpad entpackt und
`kicad-cli` 10.0.6 damit gegen das Projekt ausgeführt.

## Ergebnis / Befunde

- **PPA:** `ppa:kicad/kicad-10.0-releases` liefert für noble `10.0.6~ubuntu24.04.1`
  (= Host-Version). `kicad-packages3d`: 280 MB Download, 3,2 GB installiert.
- **Bibliothekstabellen:** `/usr/share/kicad/template/{sym,fp}-lib-table` kommen
  in KiCad 10 aus `kicad-symbols`/`kicad-footprints` — der Config-Seed im
  Dockerfile funktioniert unverändert (nur Pfad `10.0`).
- **Abhängigkeit:** `_eeschema.kiface` benötigt in KiCad 10 WebKitGTK
  (`libwebkit2gtk-4.1-0`); `apt` zieht das im Container automatisch nach.
- **Modellpfade:** KiCad 10 löst `${KICAD9_3DMODEL_DIR}` weiterhin auf
  (identisches 3D-PDF, 792 902 Byte). Umstellung auf `KICAD10_3DMODEL_DIR`
  daher nur Konsistenz. Vergleich: nur Platine 79 KB, ohne Standardmodelle
  612 KB, vollständig 793 KB. `kicad-cli` meldet fehlende Modelle **nicht**.
- **3D-PDF:** KiCad 10.0.6 schreibt xref-Einträge mit Offset 0 (`qpdf --check`
  warnt). `qpdf`-Merge repariert das; Exit-Code 3 → `--warning-exit-0`.
  3D-Annotation (`/3DA /A /PO`, Toolbar) und U3D-Stream mit 4 Ansichten bleiben
  erhalten, `/P` zeigt auf die richtige Seite. Gesamt-PDF: 12 Seiten, 1,8 MB.
- **ERC/DRC unter KiCad 10** (gegen unveränderten KiCad-9-Stand):
  - ERC: 1× `lib_symbol_mismatch` J1 (Standardsymbol USB-C geändert)
  - DRC: 2× `copper_edge_clearance` NPTH J1 ↔ GND-Zone 0,25 mm < 0,5 mm
  - DRC: 57× `footprint_symbol_field_mismatch` (fast alle `Datasheet` `~` vs. leer)

## Empfehlungen

- In KiCad 10: Zonen neu füllen, *Leiterplatte aus Schaltplan aktualisieren*,
  J1-Symbol aus Bibliothek aktualisieren; danach ERC/DRC erneut bewerten.
  Eigenes Ticket.
- Projektdateien erst in KiCad 10 speichern, wenn alle Rechner und der
  Container auf KiCad 10 stehen.

## Nächste Schritte

- Container-Rebuild durch Bediener, Done-Bedingung SHBS-31 prüfen.
- 3D-Seite in Acrobat Reader prüfen (SHBS-33).

## Nachtrag: Behebung (SHBS-35)

- Zonen per `kicad-cli pcb drc --refill-zones --save-board` neu gefüllt →
  `copper_edge_clearance` weg; Board jetzt Format `20260206`.
- Speichern über die `pcbnew`-Python-API verworfen: sortiert Segmente um
  (≈6400 Zeilen Diff) und schreibt KiCad-10-Defaults in `.kicad_pro`.
  Feldabgleich stattdessen textbasiert (389 Zeilen Diff).
- DRC meldet `footprint_symbol_field_mismatch` nur für das erste
  abweichende Feld je Footprint — S2 fehlten tatsächlich 22 Felder.
- **J1-Falle:** KiCad 10 nummeriert im Standardsymbol den Schirm-Pin
  `S1` → `SH`; der Footprint hat 4 Pads `S1`. Bibliotheks-Update hätte den
  Schirm von GND getrennt. Lösung: Symbol-Kopie mit `S1` in `shbs_power`.
  Netze vorher/nachher byte-identisch, `J1.S1` an GND.
- Endstand: ERC 0/0, DRC 0 Verstöße, 0 Paritätsabweichungen; mit
  `--severity-all` nur hinterlegte Ausnahmen (ERC 1, DRC 14; vorher 17).

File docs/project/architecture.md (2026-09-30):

---
status: active
last_updated: 2026-09-30
type: project-doc
---

# Architektur — SmartHomeSystemBasisStation

ESP-IDF-Firmware auf **ESP32-S3**, KiCad-Hardware und SPIFFS-Web-UI für die Konfiguration der SmartHome-Basisstation.

## Systemüberblick

```text
Stromversorgung              Rechenkern / Peripherie
─────────────────            ─────────────────────────────────────────

  [USB-C J_PWR1 → Buck
   AP3211 auf 3,3 V] ───────► ESP32-S3-WROOM-1U-N16R8
                                      │
  [Reset-Taster S2] ──────────────────┤
                                      ├──► [4 LEDs, RGBY]
  [USB-C J1, Debug] ──────────────────┤
  [PROG J6] ──────────────────────────┤
                                      ├──► [WLAN-Antenne am Modul 1U]
                                      │
                                      └─SPI─► [W5500] ──► [RJ45 T1] ──► Netzwerk
```

Der separate JTAG-Header ist entfallen — der ESP32-S3 bringt USB-Serial-JTAG
im Chip mit, On-Chip-Debugging läuft über `J1`.

Blockskizze: `pcb/architektur_basisStation.drawio`. Hardware-Details: [hardware.md](hardware.md). Kommunikation (WLAN, HTTP): [communication.md](communication.md).

## Verzeichnisstruktur (Repository)

| Pfad | Rolle |
|---|---|
| `main/` | ESP-IDF-Firmware (Ausnahme: statt `embedded/` laut CLAUDE.md) |
| `spiffs/` | Web-Assets (HTML, CSS, JS) → SPIFFS-Image |
| `pcb/` | KiCad-Projekt Basisstation; Bauteildaten je Bauteil in `pcb/Bauteile/<Bauteil>/` (SHBS-12) |
| `docs/project/` | Technische Projektdokumentation |
| `docs/userdoc/` | Anwenderdokumentation |
| `partitions.csv` | Flash-Partitionen (App, SPIFFS, NVS) |
| `version` | Zentrale Versionsnummer (`X.XX.XXX`), Sync mit CMake und sdkconfig |
| `tests/` | Unity-Tests (ESP-IDF, `idf.py -T tests`) — siehe unten |

## Firmware — Laufzeitdiagramm

Startsequenz in `app_main`, persistente Konfiguration und Tasks. **Nur Standard-Markdown:** Diagramm als Text im Code-Block (kein Mermaid).

```text
app_main – Startsequenz (von oben nach unten)
──────────────────────────────────────────────
  NVS Flash
       |
       v
  esp_netif + Default Event Loop
       |
       v
  SPIFFS (/spiffs)
       |
       v
  startWebServer
       |-------------------------> WebServer.c --> FileManagement.c
       |                                                    |
       v                                                    v
  xTaskCreatePinnedToCore (3 Tasks)              configuration.json
       |
       +-- ledControlTask -----> LED.c
       +-- executeTaskControl --> TaskControl.c
       +-- wifiControlTask ---> WLAN.c --> FileManagement.c --> configuration.json
       |
       v
  configuration.json laden oder anlegen
       |
       v
  wifi_init_sta_and_softap()
```

## Entwicklungsumgebung (Dev Container)

Die Toolchain ist vollständig im Dev Container unter `.devcontainer/` beschrieben:
ESP-IDF 5.5.2, KiCad 10 (`kicad-cli` für ERC/DRC/BOM und Dokumentations-PDF
inkl. 3D-Bibliothek, `qpdf`), LibreOffice Calc (headless,
rechnet erzeugte Mappen durch) und der Claude-Code-CLI.

**Persistenz über Rebuilds hinweg.** Das Home-Verzeichnis `/home/esp` liegt im
Container-Dateisystem und wird bei jedem Rebuild neu aus dem Image erzeugt.
Persistiert wird gezielt nur `/home/esp/.claude` über das Named Volume
`shbs-claude-state` — dort liegen Login-Token, Sitzungsprotokolle und
Shell-Snapshots des Agenten. Das übrige Home bleibt bewusst flüchtig, weil das
Dockerfile `~/.bashrc` und `~/.config/kicad/10.0/` seedet; diese Dateien müssen
bei Image-Änderungen neu entstehen dürfen.

Nicht persistiert wird `~/.claude.json`. Darin stehen unter anderem die pro
Projekt erteilten Werkzeug-Freigaben — diese gehören stattdessen versioniert in
`.claude/settings.json`, damit sie einen Rebuild überstehen und für alle
Beteiligten gleich sind. Secrets kommen über `secrets/.env` (git-ignoriert) per
`--env-file` in den Container.

## Build & Metadaten

- Root: `CMakeLists.txt` — `PROJECT_VER` aus `version` (aktuell **0.00.001**), `project(SmartHomeSystemBasisStation)`.
- UI/Laufzeit: `sdkconfig` — `CONFIG_APP_PROJECT_VER` (identisch zu `version`).
- Komponente: `main/CMakeLists.txt` — Quellen und eingebettete SPIFFS-Assets (HTML/CSS/JS/Icons).

Versions-Sync: siehe [struktur-anpassung-agents.md](struktur-anpassung-agents.md) §6.

## Deployment

Voraussetzung: [ESP-IDF](https://docs.espressif.com/projects/esp-idf/) für **ESP32-S3**.

```text
idf.py set-target esp32s3
idf.py build
idf.py flash monitor
```

Partitionierung und SPIFFS: `partitions.csv`, `sdkconfig`.

## Testing

Unity-Tests unter `tests/` (Smoke-Tests, eigenständige Test-Komponente ohne `main/`).

```text
idf.py set-target esp32s3
idf.py -T tests build
idf.py -T tests flash monitor
```

Details: [tests/README.md](../../tests/README.md).

## Code style (C/C++)

Formatting and static analysis: `.clang-format` and `.clang-tidy` in the project root (`main/`, excluding vendored `cJSON`).

## Startablauf (`main/main.c`)

1. **NVS** initialisieren (ggf. Erase bei Versions-/Seitenkonflikt).
2. **Netzwerk-Stack:** `esp_netif_init()`, Default-Event-Loop.
3. **Synchronisation:** Mutex und Binary-Semaphore für LED-Logik.
4. **SPIFFS** unter `/spiffs` mounten (`initSpiffs`).
5. **HTTP-Server** starten (`startWebServer("/spiffs", &http_server)` → `esp_err_t`).
6. **FreeRTOS-Tasks** (Core-Zuordnung über `PRO_CPU` / `APP_CPU` in `main.h`):
   - `ledControlTask` — LED-Steuerung
   - `executeTaskControl` — TaskControl
   - `wifiControlTask` — WLAN
7. **WLAN-Konfiguration:** Datei `/spiffs/configuration.json` anlegen oder laden, danach `wifi_init_sta_and_softap()`.

## Module (Überblick)

| Modul | Rolle |
|---|---|
| `main.c` | Einstieg, SPIFFS, Task-Start, Config-Bootstrap |
| `WLAN.c` / `WLAN.h` | Station + SoftAP, Scan, Persistenz in `configuration.json` |
| `WebServer.c` / `WebServer.h` | `esp_http_server`, statische Inhalte + REST-ähnliche URIs |
| `LED.c` / `LED.h` | LED modes (`led_mode_t` in `main.h`) |
| `TaskControl.c` / `TaskControl.h` | Steuerlogik (siehe Quellcode) |
| `FileManagement.c` | Dateizugriff auf SPIFFS (Existenz, Lesen, JSON schreiben) |
| `cJSON` | JSON für Konfiguration |
| `ProjectConfig.h` | Projektweite Schalter (derzeit u. a. `TaskListOutput`) |

## Globale Symbole (Auszug)

- `productName` in `main.c` (SoftAP SSID: `"SmartHome-Basisstation"`). `CONFIG_LWIP_LOCAL_HOSTNAME` in `sdkconfig` identisch. HTTP `/FWversion` liefert `app_desc->version` aus `CONFIG_APP_PROJECT_VER` / `version`.
- `config` (`cJSON*`) — WLAN-Konfiguration im RAM, synchron mit Datei.

## Bekannte Code-Stelle (Review-Hinweis)

In `main.c` wird nach `file_isExisting(wifiConfigFile)` zwischen `cJSON_IsNull(config)` und einem `else`-Zweig verzweigt. **Review empfohlen:** Logik und gewünschtes Verhalten bei fehlender/ungültiger Datei explizit festlegen.

## Ethernet

Angebunden über **WIZnet W5500** am SPI-Bus — der ESP32-S3 hat keine
EMAC-Peripherie, RMII ist deshalb nicht möglich. ESP-IDF betreibt den Baustein
im MACRAW-Modus unter lwIP; firmwareseitig entsteht ein reguläres
`esp_netif`-Interface neben WLAN. Erwarteter Durchsatz 15–20 Mbit/s, begrenzt
durch den SPI-Bus.

| Thema | Ticket | Stand |
|---|---|---|
| Schaltplan und BOM | SHBS-5 | fertig |
| PCB-Layout | SHBS-10 | fertig (2026-09-29, siehe [hardware.md](hardware.md) „Gesamt-Layout") |
| Firmware-Anbindung | SHBS-11 | offen — keine `ETH_`-Nutzung in `main/` |

Architektur und Begründung: **[ethernet.md](ethernet.md)**. Hardware-Stand:
[hardware.md](hardware.md).

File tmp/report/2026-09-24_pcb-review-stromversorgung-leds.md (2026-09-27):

---
type: code-review
created: 2026-09-24
status: draft
---

# PCB-Review: Stromversorgung und Status-LEDs

## Ausgangslage

Der Bediener hat im Leiterplatteneditor die Stromversorgung (J_PWR1, F1, D12,
PS1, L1, D11, C13–C15, R17–R20) und die Status-LEDs (D7–D10, Q1–Q4, R13–R16,
R23–R26) platziert und geroutet. Geprüft wurde
`pcb/BasisStation/BasisStation.kicad_pcb` (Stand 2026-09-24 19:55) mit
`kicad-cli pcb drc --schematic-parity --severity-all` (KiCad 9.0.9, CLI) und
einer Auswertung der Leiterbahnen direkt aus der Datei.

Die Zonen ließen sich per CLI nicht neu füllen: `kicad-cli` hat dafür keine
Option, und das Python-Modul `pcbnew` ist im Container nicht installiert.

## Ergebnis / Befunde

### DRC-Gesamtbild (561 Meldungen)

| Kategorie | Anzahl | Bewertung |
|---|---:|---|
| `clearance` (Zone, Abstand 0 mm) | 268 | Artefakt: GND-Füllung stammt von vor dem Routing |
| `hole_clearance` (Zone) | 76 | dito |
| `solder_mask_bridge` (Zone) | 144 | dito |
| `unconnected_items` | 144 | Großteil: Bauteile noch außerhalb der Platine (x < 50 mm) |
| `silk_*`, `text_height` | 63 | Kosmetik, außerhalb des Review-Bereichs |
| `extra_footprint` / `duplicate_footprints` | 7 | 4 Montagelöcher `REF**` ohne Schaltplan-Symbol |
| `copper_edge_clearance` | 4 | USB-C-Buchsen J1/J_PWR1 am Rand — konstruktionsbedingt |
| `clearance` 0,15 < 0,2 mm | 5 | U1 (ESD-Array, Debug-USB) — Pad-Pitch des Footprints |

Die GND-Zonen (F.Cu und B.Cu) enthalten nur Aussparungen für die Montagelöcher.
Die Füllung ist also veraltet. Nach **`B`** (alle Zonen füllen) verschwinden
die rund 490 Zonenmeldungen oder werden zu echten Befunden.

### B1 — USB-C J_PWR1: B4/B9 (VBUS) und A12/B12 (GND) nicht angeschlossen — hoch

Das Symbol `shbs_power:USB_C_Receptacle_Power` hat nur die Pins A1, B1, A4,
A9, A5, B5 und S1. Auf dem PCB sind deshalb **B4, B9, A12 und B12 ohne Netz**.
In Standard-Steckern sind die VBUS- und GND-Kontakte zwar intern verbunden,
die Versorgung funktioniert also. Der Strom verteilt sich aber nur auf die
Hälfte der Kontakte, und das entspricht nicht der USB-C-Spezifikation.

Empfehlung: Im Symbol B4/B9 als gestapelte VBUS-Pins und A12/B12 als GND-Pins
ergänzen (oder die Pins als `passive` stacken), danach mit F8 übernehmen.

### B2 — Alle Leiterbahnen 0,2 mm, nur Netzklasse `Default` — hoch

VBUS, +5V, +3V3, GND und der Schaltknoten sind mit 0,2 mm geroutet. Die
Last liegt bei bis zu ca. 0,5 A (ESP32-S3 beim WLAN-Senden, dazu W5500
ca. 130 mA). Der AP3211 kann bis 1,5 A liefern. 0,2 mm bei 35 µm sind grenzwertig
und erzeugen unnötigen Spannungsabfall. Beim Buck-Wandler kommt die
Induktivität langer, dünner Leitungen hinzu.

Empfehlung: Netzklasse **`Power`** anlegen (0,6–0,8 mm, Abstand 0,2 mm) und
per Muster zuweisen: `/Stromversorgung/VBUS`, `/Stromversorgung/+5V`, `+3V3`,
`GND`, `Net-(D11-K)` (SW). Danach die Leiterbahnen neu verlegen oder
per *Bearbeiten → Leiterbahn- und Via-Eigenschaften bearbeiten* aufweiten.

### B3 — Buck-Wandler zu weit auseinander platziert — hoch

Abstände zum Mittelpunkt von PS1 (66,0 / 53,5):

| Bauteil | Funktion | Abstand | Soll |
|---|---|---:|---|
| C13 | Eingangskondensator VIN–GND | 10,7 mm | < 3 mm, direkt an VIN/GND |
| C15 | Bootstrap BST–SW | 9,0 mm | direkt an den Pins |
| D11 | Freilaufdiode | 10,3 mm | direkt an SW |
| L1 | Speicherdrossel | 17,7 mm | direkt neben SW/D11 |
| C14 | Ausgangskondensator | 16,1 mm | nahe L1 und D11-Anode (GND) |

Leiterbahnlänge des Schaltknotens `Net-(D11-K)` (SW): **40,7 mm**, BST 12,8 mm,
FB 15,5 mm. Der Schaltknoten ist die Hauptquelle für Störabstrahlung und
sollte nur wenige Millimeter lang, dafür breit sein. Die heiße Schleife
C13 → PS1 → D11 → GND muss möglichst klein ausfallen. Die FB-Leitung gehört
kurz und weg vom Schaltknoten (R17/R18 nahe am FB-Pin).

### B4 — +3V3 noch nicht vollständig geroutet — mittel (erwartet)

Offene Luftlinien: vom Buck-Ausgang (Track bei 73,5 / 66,5) zu `U6.2` sowie
zwischen den LED-Anoden D7, D10, D8 und D9 (je Pin 2) und zu U6.2.

### B5 — LED-Zweig — niedrig

- Die LED-Pins sind nach dem F8-Abgleich korrekt: GPIO21, GPIO47, GPIO48 und
  GPIO38 (Pads 23, 24, 25, 31). Die Leitungen R23–R26 → Q-Basis sowie
  Q-Kollektor → R13–R16 → LED-Kathode sind geroutet.
- Die Emitter hängen über THT-Pads an der GND-Zone. Nach dem Füllen prüfen,
  ob Thermal-Spokes entstehen.
- R13–R16 und R23–R26 sind laut Stückliste **Vishay PR02** (2 W) mit dem
  Footprint DIN0617 (Rastermaß 20,32 mm). Bei ca. 5 mA bzw. 0,55 mA sind
  0207/0,25 W oder SMD 0805 ausreichend und sparen viel Fläche. Die
  Mischbestückung steht bereits als offener Punkt in der Stückliste.

### B6 — Kosmetik / Hinweise

- Footprint von PS1 heißt noch `shbs_power:MP2359DJ`. Das Gehäuse (SOT-23-6)
  passt, der Schaltplan-Abgleich (Parity) ist fehlerfrei. Die Pad-Zuordnung
  sollte trotzdem einmal gegen das AP3211-Datenblatt geprüft und der
  Footprint für die Nachvollziehbarkeit umbenannt werden.
- Die vier Montagelöcher erzeugen `extra_footprint`: im Footprint
  *Nicht in Schaltplan* setzen oder Symbole `MountingHole` ergänzen.
- `track_dangling` GND bei (21,76 / 90,33): 0,07-mm-Stummel löschen.

## Empfehlungen

1. Zonen füllen (`B`), DRC erneut laufen lassen.
2. Symbol J_PWR1 um B4/B9/A12/B12 ergänzen (B1).
3. Netzklasse `Power` anlegen und Versorgungsleitungen aufweiten (B2).
4. Buck-Wandler kompakt um PS1 neu platzieren: C13 und C15 direkt an den
   Pins, D11/L1 am SW-Pin, C14 dicht dahinter (B3).
5. +3V3 zu U6 und zu den LED-Anoden routen (B4).

## Nächste Schritte

- Die Punkte B1 (Symboländerung) und B2 (Netzklasse) betreffen Projektdateien.
  Die Umsetzung erfolgt nach Freigabe über JIRA-Ticket und Task.
- Nach der Umplatzierung erneut reviewen.

## Nachtrag 2026-09-27: Debug-USB J1, U1, R21, R22

Der Bediener hat J1, das ESD-Array U1 und die CC-Widerstände R21/R22
platziert und verdrahtet. Die Prüfung erfolgte per `kicad-cli` (DRC mit
Schaltplan-Abgleich) und durch Auswertung der Leiterbahnen. Die Zonenfüllung
war erneut veraltet (82 Zonenmeldungen).

### D1 — Durchgangs-Pads an U1 nicht verbunden — hoch

U1 (UDFN-10) ist als Durchgangs-Bauteil beschaltet: 10/1 = USB−, 9/2 = USB+,
7/4 = VBUS_J1. Von J1 kommend endet jede Leitung am oberen Pad (10, 9, 7),
zu U6 geht jeweils eine Leitung ab dem unteren Pad (1, 2). Die kurze
Verbindung **quer durch das Bauteil** (10→1, 9→2, 7→4) fehlt. Damit ist der
USB-Datenpfad zwischen J1 und U6 unterbrochen.

### D2 — Brücken im Pad-Feld von J1 fehlen — hoch

- **D+ B6→A6** und **D− B7→A7** fehlen. Ohne diese Brücken funktioniert
  USB nur in einer Steckrichtung. Die beiden Paare kreuzen sich
  geometrisch (B6 links von B7, A6 rechts von A7), eines braucht deshalb ein
  Via. Vorschlag: D+ direkt auf F.Cu, D− von B7 kurz nach oben auf ein Via,
  auf B.Cu zum vorhandenen USB−-Via (88,5 / 38,0).
- **VBUS_J1:** B4→A9 fehlt, A4 und B9 sind nicht angebunden. Die
  Gruppe A4/B9 kommt nur über B.Cu an den übrigen VBUS_J1-Zweig, weil CC1
  (A5) zwischen A4 und dem Rest liegt.

### D3 — Hinweise ohne Handlungsbedarf

- Die USB-Leitungen haben je 4 Vias und 76–78 mm Länge. Für USB
  Full-Speed (12 Mbit/s) ist das unkritisch. Die Lagenwechsel kreuzen die
  +3V3-Leitung bei y 62,1.
- R21/R22 (CC, 5,1 kΩ) korrekt angeschlossen. Die GND-Leitungen laufen
  über (102 / 34,0) bzw. (102 / 37,5) zu einem GND-Via bei (102 / 36,0).
- 5× Abstand 0,15 mm an U1 (Pad-Raster des Footprints) und 2× Kantenabstand
  an J1 (Hersteller-Landepattern, wie J_PWR1) → im DRC ausschließen.

### Umsetzung (SHBS-22)

D1 und D2 hat der Agent per Skript geroutet (21 Segmente, 3 Vias; Details
in `docs/project/hardware.md`, Abschnitt Debug-/Datenanschluss J1). DRC:
offene Verbindungen 120 → 112, an J1/U1 keine mehr. Keine neuen
Abstandsfehler außer gegen die veraltete Zonenfüllung.

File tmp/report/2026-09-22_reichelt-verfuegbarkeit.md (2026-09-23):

---
type: analysis
created: 2026-09-22
jira: SHBS-15
status: final
---

# Reichelt als Bezugsquelle: Abdeckungsprüfung

## Ausgangslage

Nach dem Mouser-Abgleich ([2026-09-22_mouser-abgleich-stueckliste.md](2026-09-22_mouser-abgleich-stueckliste.md))
blieben 29 Positionen ohne Teilenummer, dazu `ANT2` ohne Bezugsweg und `PS1`
mit Lagerbestand 0. Frage des Bedieners: Deckt Reichelt die fehlenden Teile ab,
und ist einer der Taoglas-Nachfolger dort gelistet?

Geprüft am 2026-09-22 über die Reichelt-Shopsuche aus dem Dev-Container.
Werkzeug: [check_reichelt.py](../bom/check_reichelt.py). Reichelt bietet keine
öffentliche API; die Prüfung liest die Trefferzahl aus dem Seitentitel und ist
damit eine **Abdeckungsprüfung, keine Preisquelle**.

## Ergebnis / Befunde

### B1 — Reichelt führt keine Taoglas-Produkte

Die Suche nach „Taoglas" liefert **einen** Treffer, und der ist ein
Video-Übertragungssystem, keine Antenne. Weder `GW.20.5150` noch die
Nachfolger `GW.20.A151` oder `GW.22.5151` sind gelistet.

Damit ist die Frage beantwortet: **Nein**, kein Taoglas-Nachfolger bei
Reichelt. Reichelt führt allerdings 147 Treffer unter „WLAN Antenne RP-SMA
2,4" — ein gleichwertiger Ersatz ist dort also beschaffbar, nur eben nicht von
Taoglas. Das ist eine Produktentscheidung, keine reine Beschaffungsfrage.

### B2 — Der ESP32 ist bei Reichelt die falsche Variante

Das ist der Befund mit der größten Tragweite. Reichelt führt zwei
ESP32-S3-Module:

| Artikel | Teilenummer | Preis |
| --- | --- | ----- |
| WiFi-Modul 802.11/BT (364574) | `ESP32-S3-WROOM-1-N16R8` | 4,94 € |
| WiFi-Modul 802.11/BT (364571) | `ESP32-S3-WROOM-1-N16R2` | 5,12 € |

Beide sind die **`-1`-Variante mit PCB-Antenne**. Das Projekt verwendet
`ESP32-S3-WROOM-1U-N16R8`, also die Ausführung mit **U.FL-Anschluss für eine
externe Antenne** — daran hängt die gesamte Antennenkette `ANT1` (Pigtail) und
`ANT2` (RP-SMA-Antenne).

Ein Tausch auf die `-1`-Variante wäre keine Beschaffungsoptimierung, sondern
eine Designänderung: Pigtail und Antenne entfielen, dafür bräuchte die
Leiterplatte Freiraum für die PCB-Antenne und das Gehäuse dürfte an der Stelle
nicht abschirmen. **Nicht stillschweigend tauschen.**

### B3 — Herstellerspezifische Teile fehlen durchgängig

Keine Treffer für: Würth `890334023023`, `870235673001`, `151031YS05900`,
`7499011121A`, `830059532`, `61200621621`; Amphenol `12401548E4#2A`; Bourns
`1543-650-149`; MPS `MP2359`; Diodes `D3V3XA4B10LP`.

Das ist erwartbar — Reichelt ist kein Katalogdistributor im Sinne von Mouser
oder DigiKey. Für diese Positionen bleibt Mouser beziehungsweise eine
Zweitquelle nötig.

### B4 — Generische Passivteile und Standard-Halbleiter sind gut abgedeckt

Genau der Bereich, in dem die 29 offenen Positionen liegen:

| Suchbegriff | Treffer |
| --- | --- |
| Widerstand SMD 0805 | 632 |
| X7R 0805 100n | 4 |
| WLAN Antenne RP-SMA 2,4 | 147 |
| RP-SMA | 442 |
| BC337 | 7 |
| SS34 | 4 |
| SMAJ5.0A | 2 |
| Quarz 25 MHz SMD | 7 |
| SMD Induktivität 10 µH | 1 |
| W5500 (Ethernet-IC, nicht nur Boards) | 11 |

### B5 — Methodischer Hinweis: die Suche erzeugt leicht Fehlalarme

Erste Durchläufe meldeten 0 Treffer für „SMD 0805 10k" und „SMD-Widerstand
0805 10K", während „Widerstand SMD 0805" 632 Treffer liefert. Reichelts Suche
versteht bei generischen Teilen keine Wertangaben in Kombination mit der
Bauform. **Eine Null ist erst nach einer zweiten, breiteren Formulierung
belastbar** — dieser Hinweis steht auch im Kopf des Prüfskripts.

## Empfehlungen

1. **Reichelt als Zweitquelle für Passivteile nutzen**, nicht als Hauptquelle.
   Die 29 offenen Positionen sind dort beschaffbar und in Prototypenmengen
   häufig günstiger.
2. **`U6` weiterhin über Mouser** (`356-ESP32S3WM1UN16R8`, 5,93 €, 6174 ab
   Lager) — die `-1U`-Variante gibt es bei Reichelt nicht, und ein Wechsel auf
   `-1` wäre eine Designänderung.
3. **Antennenkette bewusst entscheiden:** entweder Taoglas-Nachfolger über
   Mouser/DigiKey, oder ein gleichwertiges RP-SMA-Set von Reichelt. Beides ist
   möglich, aber es ist eine Produktentscheidung (Gewinn, Abstrahlverhalten,
   Zulassung).
4. **Keine Einquellen-Strategie.** Keiner der geprüften Distributoren deckt die
   Stückliste allein ab: Reichelt fehlen die Herstellerteile, Mouser fehlt die
   Antenne.

## Nächste Schritte

- Zweiten Distributor mit API anbinden (TME oder DigiKey), damit Preis- und
  Verfügbarkeitsvergleich automatisch läuft — siehe Folge-Ticket.
- Reichelt bleibt manuell: ohne öffentliche API ist nur die Abdeckungsprüfung
  automatisierbar, keine Preisübernahme.

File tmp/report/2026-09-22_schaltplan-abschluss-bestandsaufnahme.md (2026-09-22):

---
type: analysis
created: 2026-09-22
status: draft
---

# Schaltplan-Abschluss: Bestandsaufnahme

## Ausgangslage

Der Bediener will den Schaltplan vollstaendig abschliessen, bevor das
PCB-Layout begonnen wird. Diese Analyse erfasst, was dafuer noch offen ist.

Werkzeug: `kicad-cli` 9.0.9 im Dev-Container (SHBS-13). Geprueft wurden ERC,
Netzliste, Stueckliste, Symbolbibliotheken und die Projekteinstellungen.

## Ergebnis / Befunde

### Gesamtbild: der Schaltplan ist elektrisch fertig

| Pruefung | Ergebnis |
| --- | --- |
| ERC | **0 Fehler**, 7 Warnungen |
| Netze | 102, davon 0 ohne Pin |
| Bauteile | 76 auf dem Board, alle mit Footprint |
| Werte | vollstaendig gesetzt |
| ERC-Schweregrade | KiCad-Standard, **keine Ausnahmen** hinterlegt |

Die 4 auf `ignore` gesetzten ERC-Regeln (`footprint_filter`,
`four_way_junction`, `simulation_model_issue`, `single_global_label`) sind
KiCad-9-Standardwerte. Es wurde nichts unterdrueckt, um Probleme zu
verstecken — die Null bei den Fehlern ist belastbar.

Alle 40 Ein-Pin-Netze tragen den automatisch vergebenen Namen
`unconnected-*`, sind also bewusst unbeschaltete Pins (freie GPIOs an `U6`,
NC/RSVD an `U7`, `SBU1`/`SBU2` an `J1`). Kein einziges regulaer benanntes Netz
haengt in der Luft.

### Die 7 ERC-Warnungen im Einzelnen

**A — 4x `lib_symbol_mismatch` (`S2`, `C7`, `C10`, `C12`)**

Ursache gefunden: Die Bibliotheken `1543-650-149` und `WCAP-FTXX_P10` liegen
noch im **KiCad-6-Dateiformat** (`version 20211014`), der Symbol-Cache im
Schaltplan dagegen im KiCad-9-Format. Ein Vergleich der beiden Fassungen
zeigt ausschliesslich Formatunterschiede — `(id N)` in den Properties,
`hide` statt `(hide yes)`, fehlendes `exclude_from_sim`/`embedded_fonts`,
`Description` statt `Description_1`. **Pins und Geometrie sind identisch**,
elektrisch aendert sich nichts.

Betroffen vom alten Format sind insgesamt sechs Bibliotheken:

| Bibliothek | Format | Meldet aktuell Mismatch |
| --- | --- | --- |
| `1543-650-149` | 20211014 (v6) | ja (`S2`) |
| `WCAP-FTXX_P10` | 20211014 (v6) | ja (`C7`, `C10`, `C12`) |
| `WCAP-PT5H_6.3X5.2` | 20211014 (v6) | nein |
| `WL-TMRC_3MM` | 20211014 (v6) | nein |
| `wuerth_7499011121A` | 20220914 (v7) | nein |
| `wuerth_830059532` | 20220914 (v7) | nein |

Testlauf mit `kicad-cli sym upgrade --force` auf `WCAP-FTXX_P10`: das Ergebnis
deckt sich bis auf drei Restpunkte mit dem Cache im Schaltplan — das
`Footprint`-Feld (Cache leer, Bibliothek gefuellt), ein `justify bottom` und
umgebrochene Zeilenumbrueche im `Description_1`. Der Upgrade allein raeumt die
Warnung also **nicht** ab; der Cache im Schaltplan muss zusaetzlich aus der
Bibliothek aufgefrischt werden (GUI: *Werkzeuge > Symbole aus Bibliothek
aktualisieren*). Dabei darf das Footprint-Feld **nicht** ueberschrieben
werden, weil die Zuweisungen pro Instanz gewollt sind.

**B — 1x `unconnected_wire_endpoint`** in `BasisStation_Layout.kicad_sch`

Am Netz `EN` haengt ein Leitungsstummel: Die Leitung laeuft von
(52,07 / 55,88) nach (62,23 / 55,88), das Label `EN` sitzt bei
(59,69 / 55,88). Die letzten 2,54 mm stehen ins Leere. Rein kosmetisch,
elektrisch folgenlos — als Textaenderung korrigierbar (Endpunkt auf die
Label-Position ziehen).

**C — 1x `pin_to_pin`: `S2` Pin 1 (Bidirectional) + `#FLG04` (Power output)**

Das ist das GND-`PWR_FLAG`, das in Task 0003 (SHBS-6) bewusst gesetzt wurde,
nachdem mit dem Wechsel von `USB_B_Micro` auf `USB_C_Receptacle` der einzige
ERC-Treiber des GND-Netzes entfallen war. Verhalten by design.

**D — 1x `multiple_net_names`: GND und EPAD an `U6`**

Der versteckte Pin 41 (`EPAD`) des ESP32-S3-Moduls traegt einen eigenen
Netznamen und liegt auf GND. KiCad nimmt GND in die Netzliste — korrekt.
Verhalten by design.

### Weitere Befunde (ausserhalb der ERC)

**E — verwaiste Schaltplan-Datei**

`pcb/BasisStation/BasisStation_architektur.kicad_sch` (1271 Zeilen) ist in
der Hierarchie **nicht referenziert**. Die Datei wurde zuletzt bei der
Verzeichnis-Umbenennung (`27de25b`, SHBS-1) mitgenommen. Sie geht weder in
ERC noch in Netzliste oder Stueckliste ein. Zu klaeren: Altlast (loeschen)
oder bewusst aufgehobener Entwurf (dann als solcher kennzeichnen).

**F — Zeilenenden `ethernet.kicad_sch`**

Die Datei steht im Arbeitsverzeichnis als geaendert, der Diff enthaelt
**keine inhaltliche Aenderung** — nur CRLF gegen LF. Alle sechs
Schaltplan-Dateien sind im Arbeitsverzeichnis CRLF (KiCad unter Windows);
`.gitattributes` normalisiert auf LF. Bei `ethernet.kicad_sch` liegt noch
eine CRLF-Fassung im Index. Ein `git add` normalisiert das einmalig.

**G — offene Detailfrage `U7` Pin 18 (`VBG`)**

Der Bandgap-Pin des W5500 ist unbeschaltet. In den WIZnet-Referenzdesigns ist
das ueblich, sollte vor dem Layout aber einmal gegen das Datenblatt
gegengeprueft werden — im Layout ist es nachtraeglich teurer.

**H — `R35` (0 Ohm) ist als DNP markiert**

Bewusst? Falls der Bestueckungsausschluss nicht mehr gewollt ist, jetzt
klaeren — die Stueckliste fuer die Fertigung haengt daran.

## Empfehlungen

Einzig **A** und **B** sind echte Restarbeiten am Schaltplan; **C** und **D**
sind gewolltes Verhalten und sollten als ERC-Ausnahme dokumentiert werden,
damit kuenftige Laeufe eine saubere Null zeigen. **E**–**H** sind
Klaerungen, keine Konstruktionsfehler.

Reihenfolge:

1. **A** — sechs Bibliotheken per `kicad-cli sym upgrade` auf v9 heben
   (Agent), danach Symbol-Cache in der GUI auffrischen (Bediener).
2. **B** — Leitungsstummel am `EN`-Netz kuerzen (Agent, Textaenderung).
3. **C**/**D** — als ERC-Ausnahme im Projekt hinterlegen, mit Begruendung in
   `docs/project/hardware.md` (Bediener in der GUI, da Ausnahmen an
   UUIDs haengen).
4. **E**–**H** — Entscheidungen des Bedieners einholen.
5. Abschluss-ERC: Ziel **0 Fehler, 0 Warnungen**.

## Naechste Schritte

Nach Freigabe: Jira-Ticket anlegen, Tasks unter `tmp/tasks/open/` erzeugen.
Erst danach beginnt das PCB-Layout — die Netzliste wird dann genau einmal
ins Board uebernommen.

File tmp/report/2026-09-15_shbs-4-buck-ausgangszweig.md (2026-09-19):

---
type: investigation
created: 2026-09-15
jira: SHBS-4
status: final
---

# Buck-Ausgangszweig MP2359 — Ist/Soll-Verdrahtung (Befund B12)

## Ausgangslage

Nach Behebung von B1, B3, B9, B10, B11 und C8 meldet der ERC-Lauf vom
2026-09-15 21:43 noch **einen** Fehler:

```
[pin_to_pin] Pins vom Typ Output und Power output sind verbunden ; error
    Symbol PS1 Pin 6 [SW, Output, Line]
    Symbol #FLG03 Pin 1 [Power output, Line]
```

Dieser Fehler ist ein Symptom, keine Ursache. Der Ausgangszweig des
MP2359-Buckwandlers in `pcb/BasisStation/Stromversorgung.kicad_sch` ist
falsch verdrahtet. Der Bericht hält die vollständige Ist-Verdrahtung fest,
damit die Korrektur in der KiCad-GUI zielgerichtet erfolgen kann.

Methode: Pinpositionen aus den eingebetteten `lib_symbols` mit der
Platzierungstransformation (`at`, Rotation, Spiegelung) in Blattkoordinaten
umgerechnet und gegen alle 48 Drahtsegmente geschnitten.

## Ergebnis / Befunde

### Der Knoten `SW` schluckt den halben Ausgangszweig

Alle folgenden Pins liegen auf **einem** Netz — dem Schaltknoten `SW`:

| Pin | Position (mm) | Soll-Netz |
| --- | --- | --- |
| `PS1.6` (SW, Output) | 158,75 / 86,36 | SW ✅ |
| `PS1.1` (BST, Input) | 138,43 / 83,82 | **BST** |
| `C15.2` | 147,32 / 113,03 | SW ✅ |
| `L1.2` | 177,8 / 113,03 | SW ✅ |
| `C14.2` | 182,88 / 129,54 | **GND** |
| `R17.1` | 124,46 / 101,6 | **VOUT** |
| `#PWR100` (`+3V3`) | 190,5 / 138,43 | **VOUT** |
| `#FLG03` (PWR_FLAG) | 181,61 / 143,51 | **VOUT** |

Die Verbindung `PS1.1` → SW entsteht über den Draht
(138,43 / 83,82) → (109,22 / 83,82) → (109,22 / 113,03) und dort in die
horizontale Schiene bei y = 113,03.

### Hinter `L1` hängt nichts als die Diode

| Pin | Position (mm) | Ist |
| --- | --- | --- |
| `L1.1` | 185,42 / 113,03 | nur `D11.2` |
| `D11.2` (A, Anode) | 191,77 / 113,03 | `L1.1` |
| `D11.1` (K, Kathode) | 199,39 / 113,03 | GND (`#PWR013`) |

Der eigentliche Ausgangsknoten **existiert nicht**. Was als `+3V3` benannt
ist, ist elektrisch `SW`.

### Vier konkrete Defekte

1. **`D11` verpolt und am falschen Knoten.** Anode am Induktivitätsausgang,
   Kathode an GND. In dieser Lage leitet die Schottky-Diode vom Ausgang nach
   GND — Dauerkurzschluss, sobald der Wandler anläuft.
   *Soll:* Kathode an `SW`, Anode an GND.
2. **`C15` liegt gegen GND** (Pin 1 → `#PWR011`), statt zwischen `BST` und `SW`.
3. **`BST` liegt direkt auf `SW`.** Ohne Bootstrap-Kondensator kann der
   MP2359 sein High-Side-Gate nicht treiben — der Wandler schaltet nicht.
4. **`C14` und `R17` hängen am Schaltknoten.** Die Ausgangsglättung fehlt,
   und der Feedback-Teiler regelt auf die ungeglättete Rechteckspannung.

Der Spannungsteiler selbst ist korrekt aufgebaut: `R17.2` und `R18.2` treffen
sich mit `PS1.3` (FB) bei y = 86,36, `R18.1` geht auf GND. Nur sein oberer
Abgriff sitzt am falschen Knoten.

## Empfehlungen

Ziel-Topologie (asynchroner Buck, MP2359-Datenblatt):

```
PS1.6 SW ──┬── C15 ── PS1.1 BST
           ├── D11 Kathode (Anode → GND)
           └── L1 ──┬── C14 ── GND
                    ├── R17 ── FB ── R18 ── GND
                    └── +3V3  (#PWR100, #FLG03)
```

Daraus die Soll-Netze:

| Netz | Pins |
| ---- | ---- |
| `SW` | `PS1.6`, `C15.2`, `D11.1` (K), `L1.2` |
| `BST` | `PS1.1`, `C15.1` |
| `VOUT` = `+3V3` | `L1.1`, `C14.1`, `R17.1`, `#PWR100`, `#FLG03` |
| `GND` | `D11.2` (A), `C14.2`, `R18.1`, `PS1.2` |
| `FB` | `PS1.3`, `R17.2`, `R18.2` (bereits korrekt) |

Umsetzung **in der KiCad-GUI**, nicht per Skript: der Eingriff verschiebt ein
Bauteil und ersetzt rund zehn Drahtsegmente. Ein Skript könnte das erzeugen,
das Ergebnis wäre aber visuell nicht mehr nachvollziehbar prüfbar — und bei
einem Topologiefehler ist genau die Sichtprüfung der Punkt.

Alle Koordinaten in mm, Blatt `Stromversorgung.kicad_sch`. Raster **1,27 mm**
einstellen, sonst rasten die Punkte nicht ein. Der Stand vor dem Eingriff ist
mit Commit `5cc0191` gesichert — bei einem Fehlgriff `git checkout` darauf.

### Schritt 1 — Löschen (8 Elemente)

Jeweils anklicken und `Entf`.

| # | Element | Von | Bis | Warum |
| - | --- | --- | --- | ----- |
| L1 | Draht | 172,72 / 113,03 | 172,72 / 129,54 | Trunk, verbindet SW mit C14 |
| L2 | Draht | 172,72 / 129,54 | 182,88 / 129,54 | zu C14 Pin 2 |
| L3 | Draht | 172,72 / 129,54 | 172,72 / 138,43 | Trunk zur `+3V3`-Schiene |
| L4 | Draht | 109,22 / 113,03 | 147,32 / 113,03 | zieht BST auf die SW-Schiene |
| L5 | Draht | 147,32 / 120,65 | 147,32 / 125,73 | C15 gegen GND |
| L6 | GND-Symbol `#PWR011` | 147,32 / 125,73 | — | gehört zu L5 |
| L7 | Draht | 185,42 / 113,03 | 191,77 / 113,03 | L1-Ausgang zur D11-Anode |
| L8 | Draht | 199,39 / 113,03 | 204,47 / 113,03 | D11-Kathode nach GND |

Nach L1–L3 verschwindet der Knoten bei 172,72 / 129,54 vollständig. Die
`+3V3`-Schiene bei y = 138,43 (mit `R17`, `#PWR100`, `#FLG03`) hängt jetzt
frei — das ist beabsichtigt, sie wird in Schritt 4 zum Ausgangsknoten.

### Schritt 2 — `D11` an den Schaltknoten setzen

`D11` anklicken, `M` (verschieben), **einmal `R`** (dreht gegen den
Uhrzeigersinn: Kathode zeigt danach nach oben), absetzen bei:

| Pin | Ziel |
| --- | ---- |
| Kathode (`K`, Pin 1) | **160,02 / 113,03** — auf der SW-Schiene |
| Anode (`A`, Pin 2) | 160,02 / 120,65 |

Das freigewordene GND-Symbol `#PWR013` (204,47 / 113,03) nach
**160,02 / 123,19** verschieben und mit einem Draht an die Anode hängen
(N3 unten). Position ist frei: `C15` sitzt bei x = 147,32, der Trunk bei
x = 172,72.

### Schritt 3 — `C15` als Bootstrap zwischen BST und SW

`C15` bleibt, wo es ist. Pin 2 (oben, 147,32 / 113,03) liegt bereits auf der
SW-Schiene. Pin 1 (unten) bekommt eine Leitung zu `BST` — der Draht von
`PS1.1` nach unten existiert noch und endet nach L4 frei bei 109,22 / 113,03.

### Schritt 4 — Ausgangsknoten hinter `L1` bilden

Der neue Pfad führt links an `C14` vorbei nach unten auf die `+3V3`-Schiene.

### Neue Drähte (7 Segmente)

| # | Von | Bis | Netz |
| - | --- | --- | ---- |
| N1 | 147,32 / 120,65 | 109,22 / 120,65 | BST |
| N2 | 109,22 / 120,65 | 109,22 / 113,03 | BST (an den `PS1.1`-Draht) |
| N3 | 160,02 / 120,65 | 160,02 / 123,19 | GND (D11-Anode) |
| N4 | 185,42 / 113,03 | 185,42 / 116,84 | VOUT (aus `L1` Pin 1) |
| N5 | 185,42 / 116,84 | 182,88 / 116,84 | VOUT (links an `C14` vorbei) |
| N6 | 182,88 / 116,84 | 182,88 / 129,54 | VOUT (an `C14` Pin 2) |
| N7 | 182,88 / 129,54 | 182,88 / 138,43 | VOUT (auf die `+3V3`-Schiene) |

N5 liegt bei y = 116,84 knapp **unter** dem `L1`-Symbolkörper, N6 bei
x = 182,88 knapp **links** vom `C14`-Körper — beide Wege sind frei.

### Schritt 5 — Junctions prüfen

Punkte, an denen ein Pin oder Drahtende mitten auf einem Draht landet.
KiCad setzt den Punkt meist automatisch; fehlt er, mit `J` nachsetzen:

- **160,02 / 113,03** — D11-Kathode auf der SW-Schiene
- **182,88 / 129,54** — `C14` Pin 2 zwischen N6 und N7
- **182,88 / 138,43** — N7 trifft die `+3V3`-Schiene

### Soll-Ergebnis zur Kontrolle

Netzliste (Werkzeuge → Netzliste erzeugen) oder Hover über die Netze:

| Netz | Pins |
| ---- | ---- |
| `SW` | `PS1.6`, `C15.2`, `D11.1` (K), `L1.2` |
| `BST` | `PS1.1`, `C15.1` |
| `+3V3` | `L1.1`, `C14.2`, `R17.1`, `#PWR100`, `#FLG03` |
| `GND` | `D11.2` (A), `C14.1`, `R18.1`, `PS1.2` |
| `FB` | `PS1.3`, `R17.2`, `R18.2` — unverändert |

Danach ERC: der `pin_to_pin`-Fehler an `PS1.6`/`#FLG03` muss entfallen, weil
`#FLG03` dann auf `+3V3` liegt und dort kein Pin vom Typ *Output* mehr sitzt.
Erwartet: **0 Fehler**, 9 unkritische Warnungen.

### Optional, rein kosmetisch

`C14` ist als `Device:C` unpolarisiert — die Zuordnung Pin 1 = GND,
Pin 2 = `+3V3` ist elektrisch einwandfrei. Wird später ein polarisierter Typ
eingesetzt, das Symbol um 180° drehen, damit Pin 1 am Pluspol liegt.

## Ergebnis (2026-09-15 22:27)

Korrektur in der KiCad-GUI durchgeführt. Netzprüfung aus der Schaltplandatei:

| Netz | Pins | Status |
| ---- | ---- | --- |
| `SW` | `PS1.6`, `C15.2`, `D11.1` (K), `L1.2` | wie geplant |
| `BST` | `PS1.1`, `C15.1` | wie geplant |
| `+3V3` | `L1.1`, `C14.2`, `R17.1`, `#PWR100`, `#FLG03` | wie geplant |
| `GND` | `D11.2` (A) über `#PWR013`, `C14.1`, `R18.1`, `PS1.2` | wie geplant |
| `FB` | `PS1.3`, `R17.2`, `R18.2` | unverändert |

Kein unverbundener Pin im Power-Zweig. **ERC: 0 Fehler, 9 unkritische
Warnungen.**

Abweichungen von den vorgeschlagenen Koordinaten (D11 bei 165,10 statt
160,02; `C15`-Anbindung anders geroutet) sind elektrisch ohne Belang — die
Netze sind identisch.

## Nächste Schritte

1. B12 gemäß obiger Liste korrigieren.
2. ERC gegenprüfen (erwartet: 0 Fehler, 9 unkritische Warnungen).
3. Netzliste `BasisStation.net` neu exportieren — der aktuelle Stand ist vom
   2026-06-09 und enthält noch `PS2` und `+12V`.
4. PCB nachziehen (F8), Power-Bauteile platzieren, DRC.

Footprints für `F1` und `R17`–`R20` (Befund B13) sind am 2026-09-15
zugewiesen und blockieren Schritt 3 nicht mehr.

## Verifikation (2026-09-19)

Unabhängig nachgerechnet, ohne auf den Eintrag vom 2026-09-15 zu vertrauen:
Pinkoordinaten erneut aus den `lib_symbols` mit Platzierungstransformation
(`at`, Rotation, `mirror`) in Blattkoordinaten umgerechnet, gegen alle
Drahtsegmente geschnitten, inklusive T-Verbindungen. Ergebnis identisch zur
Soll-Tabelle — alle fünf Netze (`SW`, `BST`, `+3V3`, `GND`, `FB`) stimmen,
alle sechs `PS1`-Pins sind belegt.

ERC-Stand `pcb/BasisStation/ERC.rpt` (Lauf 2026-09-18 23:42):
**0 Fehler, 7 Warnungen.** Das Blatt `/Stromversorgung/` erzeugt keine
einzige Meldung. Der frühere `pin_to_pin`-Fehler `PS1.6` ↔ `#FLG03` ist
entfallen.

**Befund B12 ist damit geschlossen.** Tasks `0005_shbs4-buck-topologie-korrektur`
und der davon blockierte `0003_shbs4-b3-pwrflag-platzierung` liegen in
`tmp/tasks/done/`.

### Nebenbefund — Netznamen der Eingangsseite

Bei der Rekonstruktion fiel auf, dass die 5-V-Schiene hinter `F1` im
Schaltplan das globale Label **`PW_EN`** trägt, nicht `+5V` wie in
`docs/project/power_supply.md` beschrieben. Ursache: `PS1.4` (EN) ist über
dasselbe Label an VIN gelegt, statt über einen Draht. Elektrisch ist das die
dokumentierte Absicht (Wandler dauerhaft aktiv), der Netzname beschreibt aber
den Enable-Pin statt der Leistungsschiene. Das VBUS-Netz vor `F1` ist
unbenannt.

Empfehlung: Schiene hinter `F1` in `+5V` umbenennen, EN separat als
kurzes Label `PW_EN` oder direkt per Draht an VIN führen, und vor `F1` ein
Label `VBUS` setzen. Rein kosmetisch — Topologie und ERC bleiben unberührt,
aber Netzliste, Routing-Ansicht und BOM werden lesbar. In
`power_supply.md`, Abschnitt „Netze", als Restposten festgehalten.

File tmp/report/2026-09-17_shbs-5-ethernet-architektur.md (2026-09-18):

---
type: analysis
created: 2026-09-17
jira: SHBS-5
status: final
---

# SHBS-5 — Ethernet-Anbindung: Architekturentscheidung

## Ausgangslage

Task `tmp/tasks/open/0002_ethernet-schnittstelle.md` fordert eine kabelgebundene
Ethernet-Schnittstelle auf der Basisstation. Die Task-Datei nennt als Ist-Stand:

> ESP32-S3-WROOM-1U-N16R8: RMII-fähig; externer PHY (z. B. LAN8720, IP101) + RJ45/Magnetics üblich.

Diese Annahme wurde vor der Planung überprüft.

## Ergebnis / Befunde

### B1 — Der ESP32-S3 hat keinen internen Ethernet-MAC (blockierend)

Die RMII-Annahme der Task-Datei trifft **nicht** zu. Der ESP32-S3 besitzt im
Gegensatz zum ursprünglichen ESP32 **keine EMAC-Peripherie** und damit keine
RMII-Schnittstelle. Ein externer RMII-PHY (LAN8720, IP101) lässt sich nicht
anbinden — es fehlt die Gegenstelle im SoC.

Nachweis im lokalen ESP-IDF (v5.5.2):

| Datei | Befund |
| ----- | --- |
| `components/soc/esp32/include/soc/soc_caps.h:78` | `#define SOC_EMAC_SUPPORTED 1` |
| `components/soc/esp32s3/include/soc/soc_caps.h` | Symbol **nicht vorhanden** |

Folge: Aufgabenpunkte 1–4 und die Akzeptanzkriterien der Task-Datei müssen
umgeschrieben werden, bevor Schaltplanarbeit beginnt.

### B2 — Machbarer Weg: SPI-Ethernet-Controller mit integriertem MAC+PHY

ESP-IDF v5.5.2 liefert für SoCs ohne EMAC drei Treiber
(`components/esp_eth/src/spi/`), die über die reguläre `esp_eth`-API und
`esp_netif` eingebunden werden — aus Firmware-Sicht verhält sich das Ergebnis
wie ein normales Ethernet-Interface.

| Controller | Kconfig-Schalter | Bewertung |
| --- | --- | --- |
| **W5500** (WIZnet) | `ETH_SPI_ETHERNET_W5500` | Sehr gut verfügbar, breite Community, MAC+PHY integriert, SPI bis 80 MHz (praktisch 33–40 MHz). **Empfehlung.** |
| DM9051 (Davicom) | `ETH_SPI_ETHERNET_DM9051` | Funktional gleichwertig, im DACH-Raum schlechter beschaffbar. |
| KSZ8851SNL (Microchip) | `ETH_SPI_ETHERNET_KSZ8851SNL` | Ältestes der drei, Verfügbarkeit rückläufig. |

Der W5500 bringt zwar einen Hardware-TCP/IP-Stack mit; der ESP-IDF-Treiber
betreibt ihn im **MACRAW-Modus** als reinen MAC, sodass lwIP wie gewohnt
darüber läuft. Das ist der vom Hersteller unterstützte Standardfall.

Durchsatz-Erwartung über SPI: realistisch **ca. 15–20 Mbit/s** statt 100 Mbit/s.
Für Konfigurations-Web-UI und Smart-Home-Telemetrie unkritisch — als
Festlegung aber zu dokumentieren.

Nebeneffekt gegenüber RMII: statt ~9 belegten GPIOs werden nur **6** benötigt
(SCLK, MOSI, MISO, CS, INT, RST), und die kritische 50-MHz-RMII-Taktführung
im Layout entfällt vollständig.

### B3 — GPIO-Budget ist ausreichend

Laut Netzliste (`PCB/BasisStation/BasisStation.net`) sind aktuell frei:
GPIO1–GPIO18, GPIO45, GPIO46.

Einschränkungen bei der Auswahl:

- **GPIO35/36/37** erscheinen frei, sind beim Modul **N16R8** aber intern vom
  Octal-PSRAM belegt — nicht verwenden (bereits in `hardware.md` vermerkt).
- **GPIO3, GPIO45, GPIO46** sind Strapping-Pins und sollten frei bleiben,
  insbesondere GPIO3 wegen der JTAG-Quellenwahl (`J5`).
- **GPIO19/GPIO20** sind durch USB (`J1`) belegt.

Damit bleiben GPIO4–GPIO18 als unkritischer Pool — mehr als ausreichend für
sechs Signale.

### B4 — PCB-Layout ist noch nicht vollständig

Der Schaltplan führt ~41 Bauteile, die Leiterplatte
(`BasisStation.kicad_pcb`) enthält erst **21 platzierte Footprints**.
Platinenumriss: **160 × 135 mm** (Edge.Cuts 50/25 → 210/160) — für eine
RJ45-Buchse mit integrierten Magnetics reichlich Platz.

Das Akzeptanzkriterium „RJ45 platziert **und geroutet**" aus der Task-Datei
greift damit der allgemeinen Layout-Phase vor. Empfehlung: Schaltplan +
Symbol/Footprint/BOM in SHBS-5 abschliessen, Platzierung und Routing im
gemeinsamen Layout-Durchgang für die gesamte Platine erledigen.

### B5 — Auswirkung auf das Leistungsbudget

Versorgung laut [power_supply.md](../../docs/project/power_supply.md):
MP2359DJ Buck bis **1,2 A**, eingangsseitig Polyfuse `F1` **1,1 A** bei 5 V.

| Verbraucher | Annahme 3,3 V |
| --- | --- |
| ESP32-S3 mit WLAN-TX (Spitze) | ~350 mA |
| W5500 inkl. Link-LEDs | ~150 mA |
| LEDs D7–D10 (4 × 5 mA) | ~20 mA |
| **Summe (Worst Case)** | **~520 mA** |

Bei ~85 % Wandlerwirkungsgrad entspricht das rund **400 mA** am 5-V-Eingang —
innerhalb der 1,1 A von `F1` und der 1,2 A des MP2359. Kein Redesign nötig,
der Wert gehört aber in `power_supply.md`.

**Abhängigkeit:** Der Ausgangszweig des Buck-Wandlers ist laut offenem Task
`0005_shbs4-buck-topologie-korrektur.md` noch fehlerhaft. Ethernet erhöht die
Last auf einer Schiene, die noch nicht verifiziert ist — SHBS-4 sollte vor dem
Hardware-Test abgeschlossen sein (für die Schaltplanarbeit an SHBS-5 aber
nicht blockierend).

## Empfehlungen

1. **RMII verwerfen.** Task-Datei `0002_ethernet-schnittstelle.md` auf
   SPI-Ethernet umschreiben, inkl. Akzeptanzkriterien.
2. **W5500** als Controller festlegen (Verfügbarkeit + IDF-Treiber + Community).
3. **RJ45 mit integrierten Magnetics** wählen — entkoppelt das Layout von
   diskreten Übertrager-Platzierungsregeln.
4. Schaltplan-Scope für SHBS-5: W5500-Block (25-MHz-Quarz, Entkopplung,
   Reset, INT, SPI), RJ45 inkl. Bob-Smith-Terminierung, ESD, Link-LEDs.
5. **Layout/Routing** als eigenen Task ausgliedern (siehe B4).
6. **Firmware** (`esp_eth` + `esp_netif`, Koexistenz mit WLAN-Station) als
   eigenen Task nach Abschluss der Hardware — die aktuelle
   `WLAN.c`/`WebServer.c`-Struktur kennt nur ein Netif.

## Nächste Schritte

### Entscheidungen (Bediener, 17.09.2026)

| Punkt | Festlegung |
| ----- | --- |
| Controller | **W5500** |
| Buchse | RJ45 mit integrierten Magnetics |
| Scope SHBS-5 | **Schaltplan + BOM** — Layout und Firmware als eigene Tickets |
| Alte Task-Datei | `0002_ethernet-schnittstelle.md` ersetzt durch Serie `shbs5` |

### Umgesetzt

**Jira:**

- **SHBS-5** — Titel und Beschreibung auf SPI/W5500 korrigiert, Scope
  eingegrenzt, Kommentar mit EMAC-Befund und verworfenen Alternativen.
- **SHBS-10** (neu, Subtask von SHBS-3) — Ethernet-Sektion im PCB-Layout
  platzieren und routen.
- **SHBS-11** (neu, eigenständiger Task) — Ethernet-Anbindung in der Firmware.
  Bewusst kein Subtask von SHBS-3, da dieses Ticket das KiCad-Layout bündelt.
- Verlinkung: SHBS-5 *blocks* SHBS-10 und SHBS-11; SHBS-10 *relates to* SHBS-11.

**Tasks** unter `tmp/tasks/`:

| Task | Status | Inhalt |
| ---- | --- | --- |
| `0001_shbs5-architektur-spi-ethernet.md` | done | Architekturentscheidung (dieser Report) |
| `0002_shbs5-symbol-footprint-bibliothek.md` | open | Datenblätter, RJ45-Auswahl, Symbole, Footprints |
| `0003_shbs5-w5500-schaltplan.md` | open | W5500-Block, GPIO-Belegung |
| `0004_shbs5-rj45-magnetics-schaltplan.md` | open | RJ45, Terminierung, Schirm, Link-LEDs |
| `0005_shbs5-bom-netzliste-doku.md` | open | BOM, Netzliste, ERC, Doku |

### Offen

- Task `0002`: Auswahl des konkreten RJ45-Typs — Beschaffungsentscheidung.
- Report auf `status: final` setzen, sobald die Erkenntnisse über Task `0005`
  nach `docs/project/` überführt sind.

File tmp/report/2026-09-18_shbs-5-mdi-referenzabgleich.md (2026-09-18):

---
type: analysis
created: 2026-09-18
jira: SHBS-5
status: final
---

# Abgleich der MDI-Sektion gegen das WIZnet-Referenzschaltbild

## Ausgangslage

Der W5500-Block im Blatt `ethernet.kicad_sch` ist vollständig beschaltet
(Task 0003, abgeschlossen). Auf der RJ45-Seite (Task 0004) sind Signalpaare,
LEDs und Schirmung gezeichnet; offen blieben die Mittelanzapfungen `CTD`
(`T1.2`) und `CRD` (`T1.5`).

Beim Beschaffen des Referenzschaltbilds fiel auf, dass WIZnet rund um die
MDI-Leitungen deutlich mehr Bauteile vorsieht als unser Entwurf. Dieser Bericht
gleicht beide ab.

**Quelle:** `pcb/Datasheets/wiznet_W5500_ref-schematic_RJ45-with-magnetics.pdf`
(WIZnet, *W5500-Ref-RJ45WithMag*, Rev. C, 25.09.2015). Die Topologie wurde aus
der gerenderten Zeichnung abgelesen, nicht aus der PDF-Textebene — die
Textkoordinaten stimmen dort nicht mit der Darstellung überein.

## Ergebnis / Befunde

### Referenz-Topologie

**Sendezweig**

| Bauteil | von | nach |
| --- | --- | ---- |
| `R1` 49,9 Ω 1 % | `3V3A` | `TXN` |
| `R2` 49,9 Ω 1 % | `3V3A` | `TXP` |
| `R3` 10 Ω 1 % | `3V3A` | Knoten `TCT` |
| `C8` 22 nF | Knoten `TCT` | `GND` |

Der Sendetreiber des W5500 arbeitet stromgesteuert. Die Mittelanzapfung wird
deshalb aus `3V3A` **gespeist** — über 10 Ω, abgeblockt mit 22 nF. Die beiden
49,9 Ω an `TXP`/`TXN` bilden die Abschlussimpedanz.

**Empfangszweig**

| Bauteil | von | nach |
| --- | --- | ---- |
| `C9` 6,8 nF | `RXP` (Chip) | `RD+` (Buchse) — **in Serie** |
| `C10` 6,8 nF | `RXN` (Chip) | `RD−` (Buchse) — **in Serie** |
| `R6` 49,9 Ω 1 % | `RXP` (Chip) | Knoten `RCT` |
| `R7` 49,9 Ω 1 % | `RXN` (Chip) | Knoten `RCT` |
| `C15` 10 nF | Knoten `RCT` | `GND` |

Der Empfänger arbeitet spannungsgesteuert und bringt seine Vorspannung selbst
mit. Deshalb **keine** Speisung der Mittelanzapfung, sondern zwei
Serienkondensatoren, die den Gleichanteil trennen. Der Mittelpunkt der beiden
49,9 Ω liegt auf `RCT` und ist über 10 nF wechselstrommässig auf Masse gelegt.

**Versorgung**

`3V3D` und `3V3A` sind **getrennt** und über die Ferritperle `L1`
(HH-1M1608-121JT) verbunden. Der EMV-Hinweis auf dem Blatt verlangt 100–2000 Ω
bei 100 MHz. Die Analogseite ist mit `C1`–`C6` (je 0,1 µF) und `C7` (10 µF)
abgeblockt.

**Schirm**

`GHs_GND` (8), `CH_GND1` (13) und `CH_GND2` (14) liegen auf `CGND`; `CGND` ist
über `C16` 1 nF/2 kV mit `GND` verbunden.

### Abgleich mit unserem Stand

| Thema | Referenz | `ethernet.kicad_sch` | Bewertung |
| ----- | --- | --- | --- |
| Abschluss `TXP`/`TXN` | 2 × 49,9 Ω nach `3V3A` | **fehlt** | ergänzen |
| Mittelanzapfung Sendezweig | 10 Ω nach `3V3A`, 22 nF nach `GND` | `T1.2` auf No-Connect | ergänzen |
| Serienkondensatoren `RXP`/`RXN` | 2 × 6,8 nF | **fehlt**, direkt verbunden | ergänzen |
| Abschluss `RXP`/`RXN` | 2 × 49,9 Ω auf `RCT`-Knoten | **fehlt** | ergänzen |
| Mittelanzapfung Empfangszweig | `RCT` auf 49,9-Ω-Mittelpunkt, 10 nF nach `GND` | `T1.5` auf No-Connect | ergänzen |
| Getrennte Analogversorgung | `3V3D`/`3V3A` über Ferritperle | ein einziges `+3V3` | prüfen |
| Schirmung | `CGND`, 1 nF/2 kV nach `GND` | `CHASSIS`, `C28` 1 nF/2 kV | **stimmt überein** |
| LED-Vorwiderstände | 330 Ω, kathodenseitig | 220 Ω, anodenseitig | unkritisch |
| Quarz-Lastkondensatoren | 18 pF | 27 pF | siehe unten |

### Bewertung

Die fehlende MDI-Beschaltung ist **kein Schönheitsfehler**. Ohne die
Abschlusswiderstände stimmt die Leitungsimpedanz nicht, ohne die
Serienkondensatoren liegt der Gleichanteil des Chips auf dem Übertrager. Beides
verschlechtert die Signalqualität, ohne dass ERC oder ein einfacher
Funktionstest darauf hinweist — Symptome wären sporadische Paketfehler oder
Verbindungsabbrüche bei längeren Kabeln.

Die getrennte Analogversorgung ist der zweitwichtigste Punkt. Sie hält die
Schaltströme des Digitalteils aus der analogen Sendeendstufe heraus und ist bei
PHYs Standard.

**Widerspruch bei den Quarz-Lastkondensatoren:** Das Referenzdesign nutzt
18 pF, unsere Rechnung ergibt 27 pF (CL = 18 pF, ca. 4 pF Streukapazität). Die
Rechnung ist die lehrbuchmässige; 18 pF im Referenzdesign würde bedeuten, dass
die effektive Lastkapazität nur etwa 13 pF beträgt und der Quarz zu schnell
läuft. Möglich, dass die Referenz einen Quarz mit anderer Lastkapazität
verwendet. **Entschieden am 18.09.2026: bei 27 pF bleiben.** Die Rechnung hat Vorrang vor
der Referenz; die Frequenz wird am ersten Prototyp gemessen und die
Kondensatoren bei Bedarf nachgezogen.

## Empfehlungen

1. MDI-Sektion nach der Referenz-Topologie ergänzen: 4 × 49,9 Ω 1 %,
   2 × 6,8 nF, 10 Ω 1 %, 22 nF, 10 nF.
2. Mittelanzapfungen entsprechend anschliessen — `T1.2` an den gespeisten
   Knoten, `T1.5` an den Mittelpunkt der Empfangs-Abschlusswiderstände.
3. Versorgung in `+3V3` (digital) und `+3V3A` (analog) trennen, verbunden über
   eine Ferritperle mit 100–2000 Ω bei 100 MHz. Die sieben Abblockkondensatoren
   des W5500 wandern dabei auf die Analogseite, soweit sie an `AVDD` liegen.
4. Quarz-Lastkondensatoren bei 27 pF belassen, am Prototyp verifizieren.

## Nächste Schritte

- Punkt 1 und 2 in Task `0004` als Sollbeschaltung ausformulieren.
- Punkt 3 **entschieden am 18.09.2026: Trennung erfolgt in SHBS-5.** Späteres
  Nachrüsten würde bedeuten, die sieben Abblockkondensatoren aus Task 0003 ein
  zweites Mal umzuhängen. Der Buck-Zweig aus SHBS-4 bleibt unberührt, die
  Ferritperle sitzt auf dem Ethernet-Blatt. Spezifikation in Task 0004.
- Offen bleibt die Auswahl des HV-Kondensators (`C28`, 1 nF/2 kV) als
  konkretes Bauteil mit Bestellnummer.

**Vorbehalt:** Das Referenzdesign nutzt die Buchse CETUS **J1B1211CCD**, wir
die Würth **7499011121A**. Die Topologie wird vom analogen Frontend des W5500
bestimmt und sollte übertragbar sein; die Würth-Buchse bringt die
Bob-Smith-Terminierung zusätzlich intern mit. Vor der Fertigung gegen das
Würth-Datenblatt gegenprüfen.

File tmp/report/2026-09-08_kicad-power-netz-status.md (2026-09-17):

---
type: analysis
created: 2026-09-08
jira: SHBS-4
status: draft
---

# KiCad-Stromversorgung — Statusanalyse (Fortsetzung von SHBS-4)

## Ausgangslage

Der Jira-Kommentar zu SHBS-4 (06.09.2026) referenziert einen Report
`tmp/report/2026-09-06_kicad-power-netz-analyse.md`. Diese Datei existiert im
aktuellen Checkout **nicht** — `tmp/` ist laut `.gitignore` nicht versioniert,
die Vorarbeit blieb also lokal auf einer anderen Maschine/Session und ist hier
nicht verfügbar. Diese Datei ersetzt den fehlenden Report auf Basis einer
Neuanalyse des aktuellen Repository-Stands (Commit `1d263fa`, sauberer
Working Tree bis auf `~BasisStation.kicad_sch.lck`).

**Wichtige Einschränkung dieser Umgebung:** Der Devcontainer (`.devcontainer/`)
enthält ausschließlich ESP-IDF-Tooling, kein KiCad/`kicad-cli`. Änderungen an
`.kicad_sch`-Dateien erfolgen als reine Text-/S-Expression-Edits ohne ERC- oder
Netzlisten-Verifikation. Der Bediener muss nach jedem Schritt in KiCad ERC
laufen lassen und die Netzliste neu erzeugen.

## Ergebnis / Befunde

### B9 — Projektbibliothek „power" verdeckt KiCad-Standardbibliothek

**Status hier: offen**, entgegen der Kommentar-Angabe „erledigt".
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

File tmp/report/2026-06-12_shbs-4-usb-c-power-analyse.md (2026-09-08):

---
type: analysis
created: 2026-06-12
jira: SHBS-4
status: draft
---

# SHBS-4 — USB-C Power-Eingang: Ist-Analyse

## Ausgangslage

Task `tmp/tasks/open/0001_usb-c-12v-stromversorgung.md`: +12-V-Versorgung über globale `+12V`-Labels durch USB-C ersetzen.

## Power-Kette (Ist)

```
[+12V] (virtuell, 2× power:+12V + PWR_FLAG) ──► PS2 (+VIN)
                                                    │
                                              TSR 1-2433E
                                                    │
                                                    ▼
                                              +3V3 ──► U6, LEDs, J5/J6, …
```
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

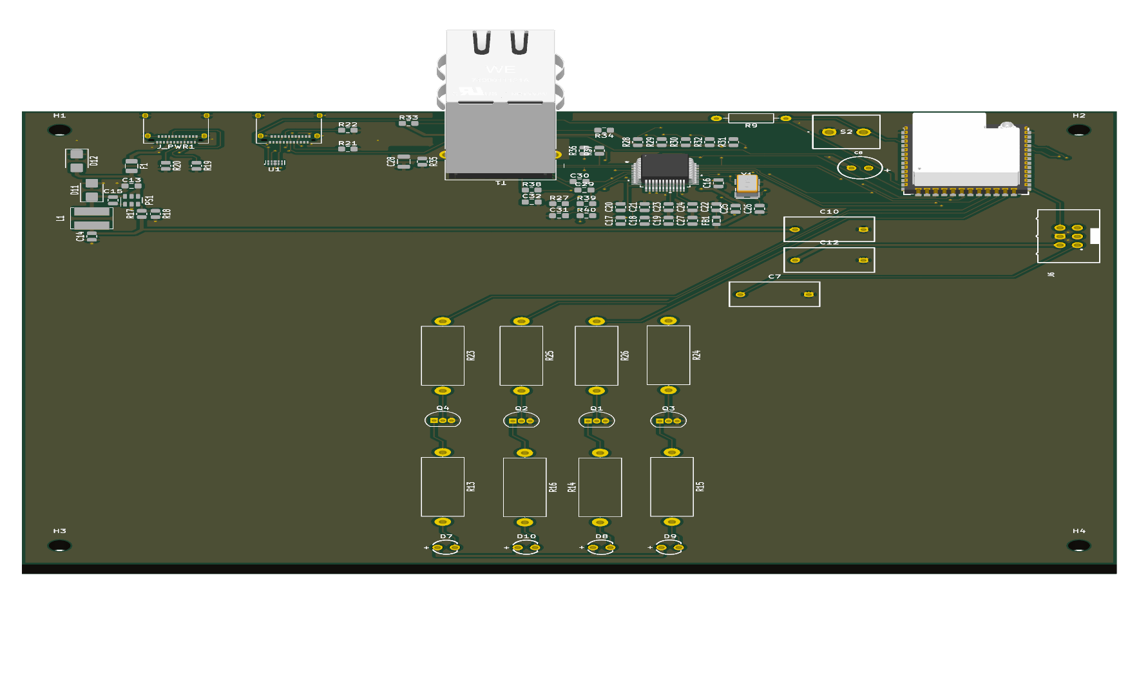
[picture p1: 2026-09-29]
tmp/report/2026-09-29_layout-buchsen.png

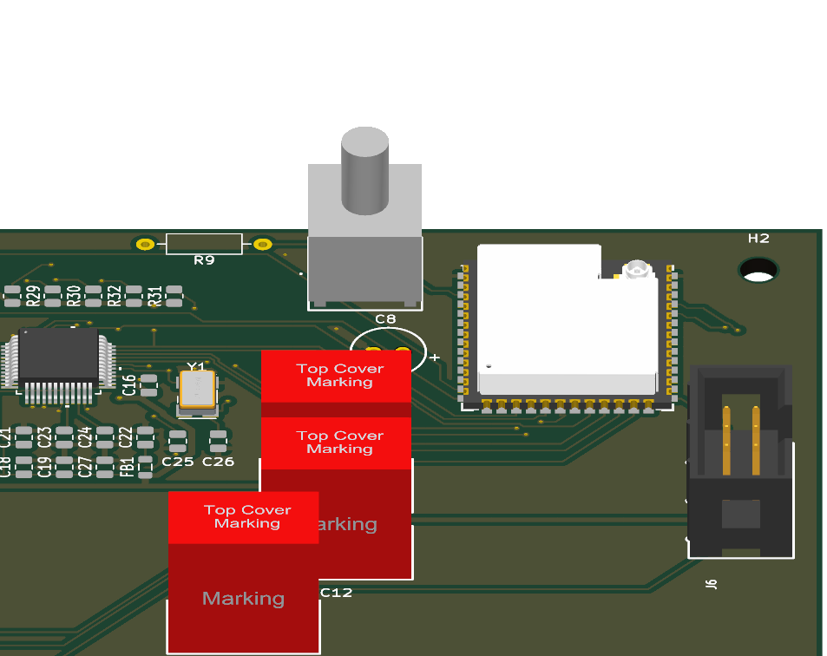
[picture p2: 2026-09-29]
tmp/report/2026-09-29_layout-3d-modelle.png

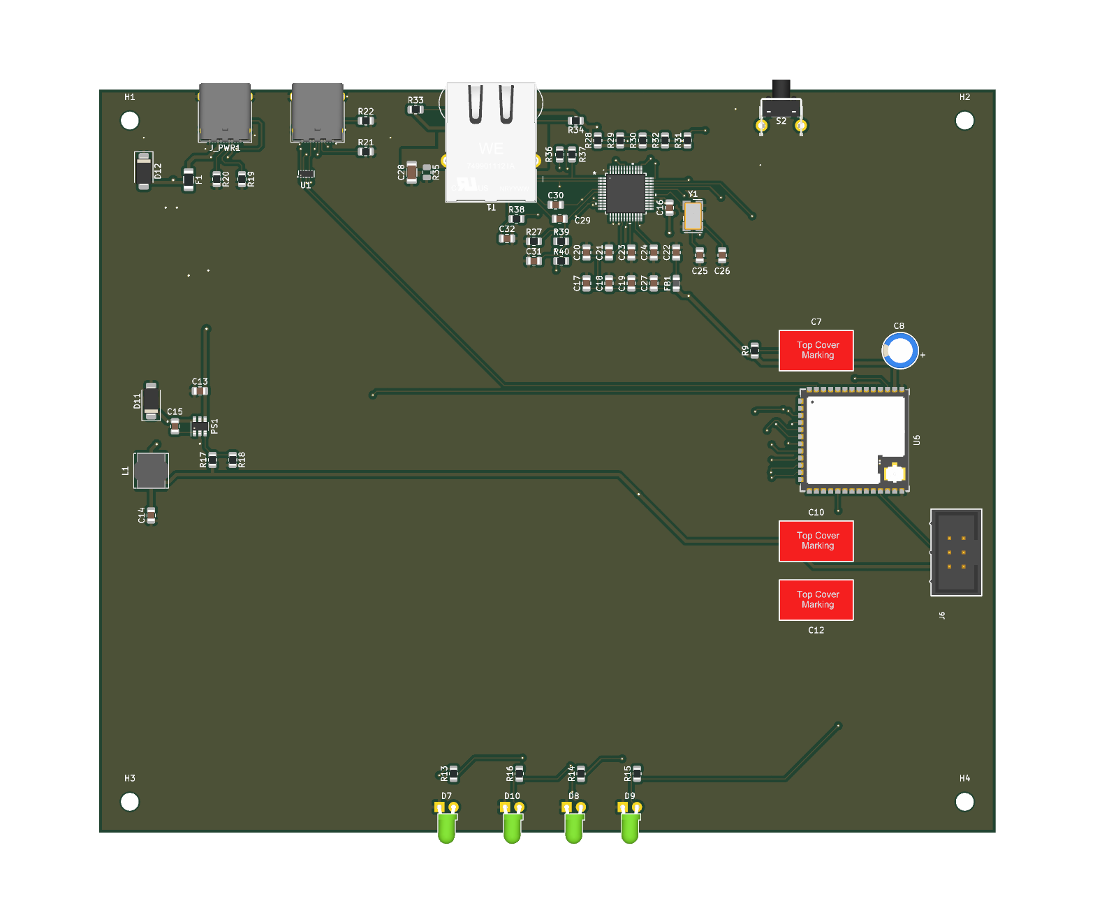
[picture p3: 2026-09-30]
tmp/report/2026-09-30_layout-top-shbs52.png

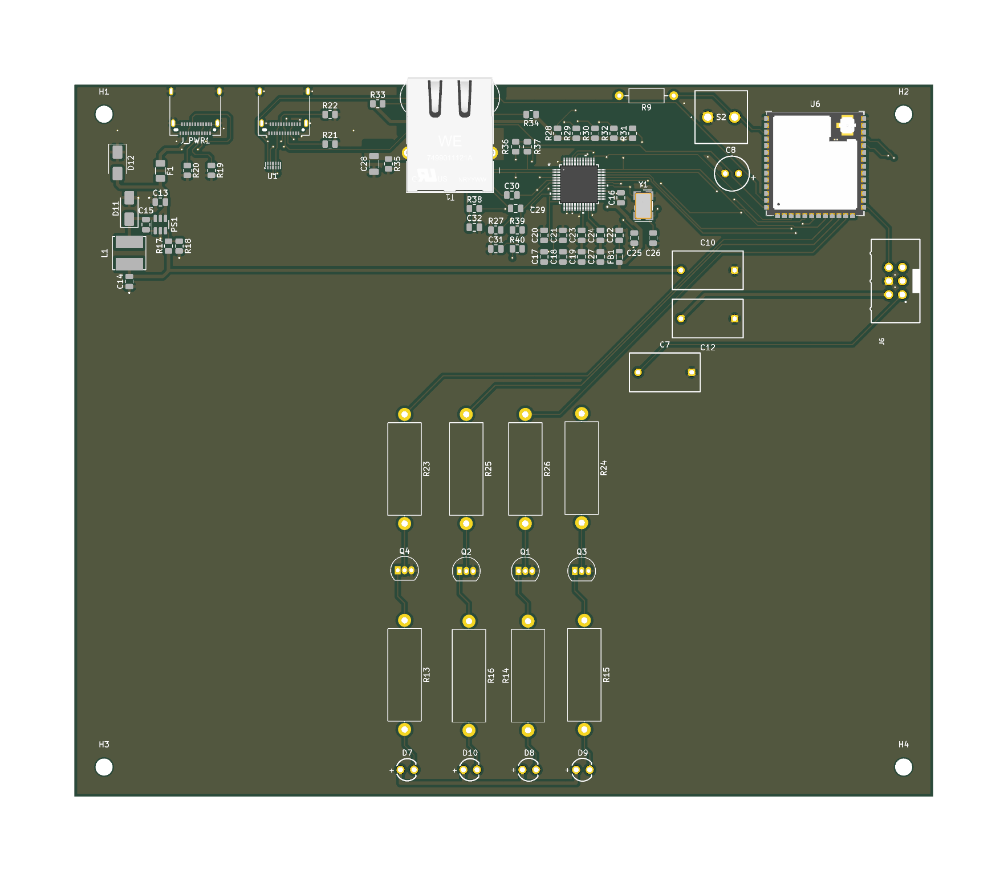
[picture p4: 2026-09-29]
tmp/report/2026-09-29_layout-top.png

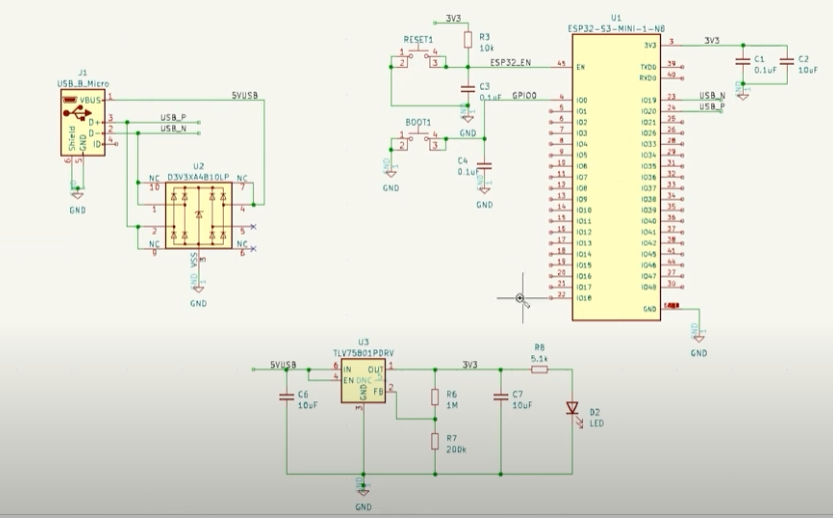
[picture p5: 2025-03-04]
pcb/esp32-s3_schematic_with_micro-b.png

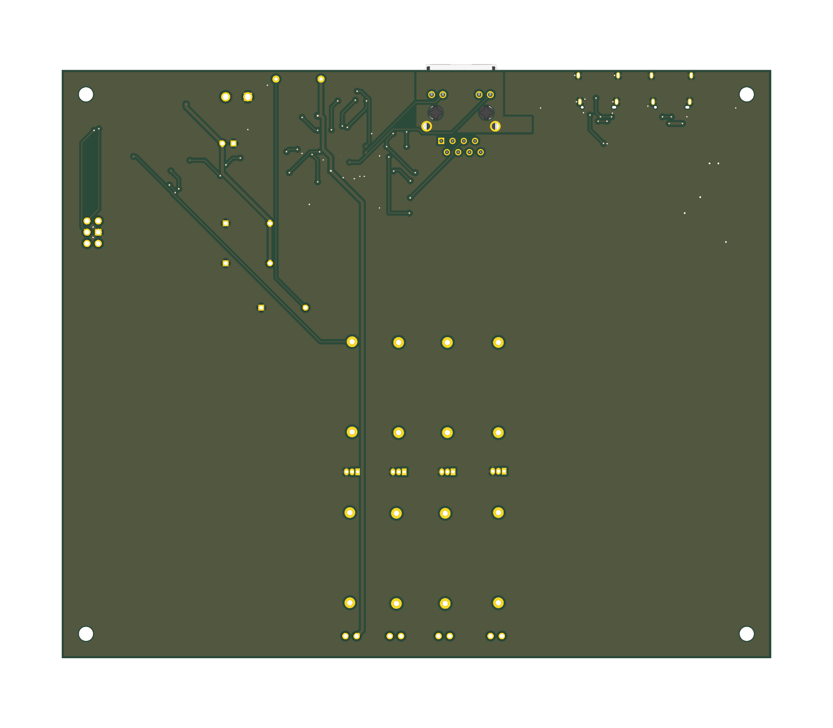
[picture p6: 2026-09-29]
tmp/report/2026-09-29_layout-bottom.png

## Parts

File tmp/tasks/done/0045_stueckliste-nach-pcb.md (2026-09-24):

---
title: Stückliste unter pcb/ statt tmp/report/ ablegen, alte STL.xlsx entfernen
created: 2026-09-24
jira: SHBS-19
priority: low
type: docs
status: done
---

## Kontext

Die bestellfähige Stückliste landete in `tmp/report/` mit festem Datum im
Namen. Das ist ein Hardware-Artefakt, kein Analysebericht. Zusätzlich lag in
`pcb/` noch die alte Handliste `STL.xlsx` (u. a. mit dem entfallenen PS2).

## Umsetzung

- `OUTPUT_PATH` in `tmp/bom/generate_bom.py` auf
  `pcb/BasisStation_Stueckliste.xlsx` umgestellt (fester Name, ohne Datum).
- Bestehende Mappe per `git mv` dorthin verschoben und mit
  `--no-network` neu erzeugt (44 Positionen, alle mit Preis).
- `pcb/STL.xlsx` gelöscht.
- `docs/project/hardware.md`: Ablageort ergänzt.

## Done-Bedingung

- [x] Skript schreibt nach `pcb/`
- [x] Alte Mappe verschoben, `STL.xlsx` entfernt
- [x] Doku aktualisiert

## Commits

- `a6bf592` Stückliste nach pcb/ verlegt, STL.xlsx entfernt

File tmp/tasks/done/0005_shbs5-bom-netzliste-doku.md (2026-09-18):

---
status: done
priority: high
type: docs
created: 2026-09-17
jira: SHBS-5
parent_jira: SHBS-3
---

# BOM, Netzlisten-Export und Dokumentation der Ethernet-Sektion

## Ziel

Abschluss von SHBS-5: Stückliste vervollständigen, Netzliste exportieren und
die Projektdokumentation auf den neuen Stand bringen.

Setzt Tasks `0002`–`0004` voraus.

## Aufgaben

1. **BOM-Felder** an allen neuen Bauteilen pflegen, Konvention aus
   `power_supply.md` übernehmen: Herstellernummer und Mouser-Referenz.
   Betrifft W5500, RJ45, 25-MHz-Quarz, Bias-Widerstand (1 %),
   HV-Kondensator, Terminierungswiderstände, Entkopplung.
2. **Netzliste** neu exportieren (`pcb/BasisStation/BasisStation.net`) und
   `pcb/BasisStation/BasisStation.csv` aktualisieren.
3. **ERC** abschliessend laufen lassen, `ERC.rpt` committen. Ziel: keine neuen
   Fehler gegenüber dem Stand 17.09.2026 (0 Fehler, 9 Warnungen).
4. **`docs/project/ethernet.md`** existiert bereits (angelegt 17.09.2026,
   Architektur und Begründung SPI statt RMII). Hier **ergänzen statt
   duplizieren**: finale Bauteilwerte, gewählter RJ45-Typ, Stand aktualisieren.
5. **`docs/project/hardware.md`:**
   - Zeile „Ethernet" in der Schnittstellen-Tabelle von „Ziel" auf den
     tatsächlichen Stand setzen
   - Neuer Abschnitt „Ethernet (SHBS-5)": W5500 über SPI, GPIO-Belegung als
     Tabelle, RJ45-Typ, Begründung SPI statt RMII (kein EMAC im ESP32-S3)
   - ERC-Stand in „Repository-Ist-Stand" nachziehen
   - Abschnitt „Abgrenzung Firmware" präzisieren: Schaltplan vorhanden,
     Layout offen (**SHBS-10**), Firmware offen (**SHBS-11**)
6. **`docs/project/communication.md`:** Abschnitt „Abgrenzung" korrigieren —
   Ethernet schaltplanseitig vorhanden, in der Firmware-Kommunikationsschicht
   noch nicht angebunden (**SHBS-11**). Erwarteten Durchsatz (15–20 Mbit/s über
   SPI) nennen.
7. **`docs/project/architecture.md`:** Systemüberblick-Diagramm — Ethernet ist
   kein blosses „Ziel" mehr; Abschnitt „Ethernet" am Dateiende auf den neuen
   Stand bringen.
8. **`docs/project/power_supply.md`:** Lastbudget-Tabelle ergänzen
   (ESP32-S3 WLAN-TX ~350 mA, W5500 inkl. LEDs ~150 mA, Status-LEDs ~20 mA →
   ~520 mA @ 3,3 V, entspricht ca. 400 mA am 5-V-Eingang; innerhalb `F1` 1,1 A
   und MP2359 1,2 A).
9. ~~`pcb/architektur_basisStation.drawio` um den Ethernet-Zweig ergänzen~~ —
   **entschieden 18.09.2026: Diagramm gestrichen.** Es lag in drei Dateien
   (`.drawio`, `.png`, `.pdf`) vor, war an vier Stellen veraltet (+24V,
   USB-UART-Bridge, JTAG-Header, fehlendes Ethernet) und duplizierte das
   Textdiagramm in `architecture.md`, das versioniert und im Diff sichtbar ist.
10. Erkenntnisse aus
   [tmp/report/2026-09-17_shbs-5-ethernet-architektur.md](../../report/2026-09-17_shbs-5-ethernet-architektur.md)
   sind damit in `docs/` überführt; Report auf `status: final` setzen.

## Fortschritt (18.09.2026)

### Erledigt — Dokumentation

| Datei | Änderung |
| ----- | --- |
| `ethernet.md` | Bauteilliste (herstellerspezifisch + Beschaltung), toleranzkritische Werte, Schirmung, Stand je Ticket |
| `hardware.md` | Neuer Abschnitt „Ethernet (SHBS-5)" mit GPIO-Tabelle und Begründung SPI statt RMII; ERC-Stand; Abgrenzung Firmware auf SHBS-10/SHBS-11 präzisiert; Quarz-Bauteilordner ergänzt |
| `communication.md` | Abgrenzung korrigiert, Durchsatz 15–20 Mbit/s, MACRAW-Betrieb, offene Koexistenzfragen für SHBS-11 benannt |
| `architecture.md` | Systemdiagramm neu — Ethernet-Zweig statt „Ziel", JTAG-Header entfernt, `J1`/`J6` benannt; Ethernet-Abschnitt mit Ticket-Tabelle |
| `power_supply.md` | **Lastbudget** ergänzt: ~515 mA @ 3,3 V Worst Case, ~400 mA am 5-V-Eingang, ~36 % von `F1` und ~43 % von `PS1`. Kein Redesign nötig |

Report `2026-09-17_shbs-5-ethernet-architektur.md` auf `status: final`.

### Erledigt — BOM-Felder

| Ref | Hersteller | Herstellernummer | Mouser |
| --- | --- | --- | --- |
| `T1` | Würth Elektronik | 7499011121A | `710-7499011121A` — **ungeprüft** |
| `Y1` | Würth Elektronik | 830059532 | `710-830059532` — **ungeprüft** |
| `U7` | WIZnet | W5500 | **fehlt** |

Die beiden Würth-Nummern sind aus dem üblichen Mouser-Präfix abgeleitet, nicht
verifiziert. Die W5500-Nummer konnte nicht ermittelt werden — Mouser blockiert
automatisierte Zugriffe (Zeitüberschreitung). **Alle drei vor der Bestellung
prüfen.**

Generische Passive (Widerstände, Kondensatoren) tragen projektkonform **keine**
Bestellnummern — wie `R13`, `R23`, `C13`, `C15` im übrigen Projekt auch.

### Erledigt — Footprints (18.09.2026)

Die BOM-Auswertung zeigte **13 Kondensatoren ohne Footprint**. Ohne den
kommen sie beim Übertragen der Netzliste nicht aufs Board.

| Referenzen | Wert | Footprint |
| --- | ---- | --- |
| `C16`–`C22` | 100 nF | `Capacitor_SMD:C_0805_2012Metric` |
| `C23` | 4,7 µF | `Capacitor_SMD:C_0805_2012Metric` |
| `C24` | 10 nF | `Capacitor_SMD:C_0805_2012Metric` |
| `C25`, `C26` | 27 pF | `Capacitor_SMD:C_0805_2012Metric` |
| `C27` | 10 µF | `Capacitor_SMD:C_0805_2012Metric` |
| `C28` | 1 nF/2 kV | `Capacitor_SMD:C_1206_3216Metric` — **vorläufig** |

`C28` hat wegen der 2 kV bewusst die grössere Bauform 1206 bekommen. Der Wert
ist ein Platzhalter: Sobald der konkrete Typ feststeht, gegen dessen Datenblatt
prüfen — 2-kV-Typen verlangen je nach Hersteller 1210 oder grösser.

Alle **35 Bauteile** des Ethernet-Blatts tragen jetzt einen Footprint.

### Erledigt — Export und Verifikation (18.09.2026)

Netzliste, Stückliste und ERC vom Bediener neu erzeugt, vom Agenten gegen die
Sollbeschaltung geprüft.

| Artefakt | Ergebnis |
| --- | --- |
| `BasisStation.net` | **0 Abweichungen** — Versorgung, Masse, MDI-Paare, Mittelanzapfungen, Schirm und LEDs alle wie spezifiziert |
| `BasisStation.csv` | 46 Positionen, **alle mit Footprint** ausser `ANT1`/`ANT2` (mechanische BOM-Positionen, korrekt ohne) |
| `ERC.rpt` | **0 Fehler, 7 Warnungen** — Niveau vor SHBS-5, keine aus der Ethernet-Sektion |

Die sechs SPI-Netze liegen paarweise richtig:

| Netz | Knoten |
| ---- | --- |
| `ETH_SCSn` | `U6.18` (GPIO10), `U7.32` |
| `ETH_SCLK` | `U6.20` (GPIO12), `U7.33` |
| `ETH_MISO` | `U6.21` (GPIO13), `U7.34` |
| `ETH_MOSI` | `U6.19` (GPIO11), `U7.35` |
| `ETH_INT` | `U6.22` (GPIO14), `U7.36`, `R31` |
| `ETH_RST` | `U6.17` (GPIO9), `U7.37`, `R32` |

Der Empfangszweig ist korrekt gleichstromgetrennt: `U7.6` (`RXP`) → `C29`
→ `T1.4` (`RD+`), `U7.5` (`RXN`) → `C30` → `T1.6` (`RD−`), die
Abschlusswiderstände `R39`/`R40` chipseitig auf `RCT`.

### Zwischenfall: Kurzschluss SCLK/SCSn

Ein beim Verschieben der Labels entstandener Draht verband `ETH_SCLK` und
`ETH_SCSn` direkt. Der Fehler steckte zwischenzeitlich auch in der exportierten
Netzliste — vier Pins auf einem Netz, Takt und Chip-Select kurzgeschlossen.
Gefunden durch den Netzliesten-Abgleich, nicht durch ERC: Die Meldung
`multiple_net_names` ist nur eine Warnung, keine Fehlermeldung. Behoben.

**Lehre für künftige Runden:** Korrekturen an einer Datei, die KiCad geöffnet
hält, werden beim nächsten Speichern überschrieben. Der Fix musste dreimal
angewendet werden, bis KiCad geschlossen war.

### Offen — kosmetisch aus Task 0004

- `FB1` trägt ein Widerstandssymbol, sollte `Device:FerriteBead` werden.
- `+3V3A` ist ein lokales Label statt eines Power-Symbols.
- `C28` (1 nF / ≥ 2 kV) braucht einen konkreten Typ mit Bestellnummer.

## Akzeptanzkriterien

- [x] Herstellernummern vollständig. **Mouser-Referenzen offen:** `T1` und
      `Y1` aus dem üblichen Würth-Präfix abgeleitet und ungeprüft, `U7` fehlt
      — Mouser blockiert automatisierte Zugriffe. Bei der Bestellung prüfen.
- [x] `BasisStation.net` und `BasisStation.csv` neu exportiert.
- [x] ERC ohne neue Fehler.
- [x] `ethernet.md`, `hardware.md`, `communication.md`, `architecture.md` und
      `power_supply.md` aktualisiert, `last_updated` gesetzt.
- [x] Architektur-Diagramm: drawio gestrichen, Textdiagramm in `architecture.md` zeigt den Ethernet-Zweig.
- [x] Report auf `status: final`.

## Hinweise

Keine Firmware-Änderung in SHBS-5 — daher **keine Versionserhöhung** und kein
Eintrag in `docs/userdoc/releases.md` (vgl. CLAUDE.md, Abweichungen).

## Betroffene Dateien

- `pcb/BasisStation/BasisStation.net`, `BasisStation.csv`, `ERC.rpt`
- `docs/project/ethernet.md`, `hardware.md`, `communication.md`,
  `architecture.md`, `power_supply.md`
- ~~`pcb/architektur_basisStation.drawio`, `.png`, `.pdf`~~ (gestrichen)
- `tmp/report/2026-09-17_shbs-5-ethernet-architektur.md`

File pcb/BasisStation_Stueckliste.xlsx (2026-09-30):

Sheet: Stückliste
Stückliste SmartHome-Basisstation
Quelle: pcb/BasisStation/*.kicad_sch · Stand 2026-09-30 · 41 Positionen · 70 Bauteile
Grün = Preis aus Mouser- bzw. DigiKey-API (Tagespreis, unverbindlich, Staffel passend zur Menge). Fett = günstigerer lieferbarer Preis. Gelb = von Hand zu füllen. Die Bezugsquelle steht auf dem günstigsten Anbieter mit ausreichend Lager und ist per Auswahlliste änderbar; Einzel-, Gesamtpreis und Summen rechnen sich daraus.
Pos | Menge | Referenzen | Wert (Schaltplan) | Technik | Footprint | Hersteller | Hersteller-Teilenr. | Mouser-Teilenr. | Mouser EUR | Mouser Lager | DigiKey-Teilenr. | DigiKey EUR | DigiKey Lager | Lebenszyklus | Bezugsquelle | Einzelpreis EUR | Gesamtpreis EUR | Mouser | DigiKey | Datenblatt | Status | Hinweis
1 | 1 | ANT1 | CAB.6061 |  |  | Taoglas | CAB.6061 | 960-CAB.6061 | 4.47 € | 845 | 931-CAB.6061-ND | 4.45 € | 897 | New Product | DigiKey |  |  | Mouser (https://www.mouser.de/de/ProductDetail/Taoglas/CAB.6061?qs=efUn273yAhcczE0Xmis3Vw%3D%3D) | DigiKey (https://www.digikey.de/de/products/detail/taoglas-limited/CAB-6061/26766272) | PDF (https://www.taoglas.com/datasheets/Taoglas_Cable_Assembly_Catalog.pdf) | eindeutig
2 | 1 | ANT2 | GW.20.A151 |  |  | Taoglas | GW.20.A151 | 960-GW.20.A151 | 8.46 € | 650 | 931-GW.20.A151-ND | 8.42 € | 59 | Aktiv | DigiKey |  |  | Mouser (https://www.mouser.de/de/ProductDetail/Taoglas/GW.20.A151?qs=P1JMDcb91o7bSzryErDemw%3D%3D) | DigiKey (https://www.digikey.de/de/products/detail/taoglas-limited/GW-20-A151/28263398) | PDF (https://cdn.taoglas.com/datasheets/GW.20.A151.pdf) | eindeutig
3 | 3 | C7, C10, C12 | WCAP-FTXX_P10 | SMD | WCAP-FTXX_P10:WCAP-FTXX_P10L13W7H13 | Würth Elektronik | 890334023023 | 710-890334023023 | 0.35 € | 1350 | 732-5833-ND | 0.35 € | 2491 | Aktiv | DigiKey |  |  | Mouser (https://www.mouser.de/de/ProductDetail/Wurth-Elektronik/890334023023?qs=pceeu5JH%2FH%252Bn7WWQMu8xaA%3D%3D) | DigiKey (https://www.digikey.de/de/products/detail/würth-elektronik/890334023023/5038958) | PDF (https://www.we-online.com/components/products/datasheet/890334023023.pdf) | eindeutig
4 | 1 | C8 | WCAP-PT5H_6.3X5.2 | SMD | WCAP-PT5H_6.3X5.2:WCAP-PT5H_6.3X5.2_DXL_ | Wurth Elektronik | 870235673001 | 710-870235673001 | 1.36 € | 2394 | 732-870235673001CT-ND | 1.35 € | 1017 | Aktiv | DigiKey |  |  | Mouser (https://www.mouser.de/de/ProductDetail/Wurth-Elektronik/870235673001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) | DigiKey (https://www.digikey.de/de/products/detail/würth-elektronik/870235673001/8556591) | PDF (https://www.we-online.com/components/products/datasheet/870235673001.pdf) | eindeutig
5 | 2 | C13, C27 | 10uF | SMD | Capacitor_SMD:C_0805_2012Metric | Samsung | CL21B106KOQNNNE | 187-CL21B106KOQNNNE | 0.42 € | 323680 | 1276-2872-1-ND | 0.24 € | 277103 | Aktiv | DigiKey |  |  | Mouser (https://www.mouser.de/de/ProductDetail/Samsung-Electro-Mechanics/CL21B106KOQNNNE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) | DigiKey (https://www.digikey.de/de/products/detail/samsung-electro-mechanics/CL21B106KOQNNNE/3888530) | PDF | eindeutig
6 | 1 | C14 | 22uF | SMD | Capacitor_SMD:C_0805_2012Metric | Samsung | CL21A226MOQNNNE | 187-CL21A226MOQNNNE | 0.55 € | 2519 | 1276-2909-1-ND | 0.27 € | 25218 | Aktiv | DigiKey |  |  | Mouser (https://www.mouser.de/de/ProductDetail/Samsung-Electro-Mechanics/CL21A226MOQNNNE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) | DigiKey (https://www.digikey.de/de/products/detail/samsung-electro-mechanics/CL21A226MOQNNNE/3888567) | PDF | eindeutig
7 | 8 | C15, C16, C17, C18, C19, C20, C21, C22 | 100 nF | SMD | Capacitor_SMD:C_0805_2012Metric | YAGEO | CC0805KRX7R9BB104 | 603-CC805KRX7R9BB104 | 0.12 € | 1217786 | 311-1140-1-ND | 0.15 € | 1635243 | Aktiv | Mouser |  |  | Mouser (https://www.mouser.de/de/ProductDetail/YAGEO/CC0805KRX7R9BB104?qs=vTakOoo5QyLx0lXWgVtRhQ%3D%3D) | DigiKey (https://www.digikey.de/de/products/detail/yageo/CC0805KRX7R9BB104/302874) | PDF | eindeutig
8 | 1 | C23 | 4,7 µF | SMD | Capacitor_SMD:C_0805_2012Metric | Samsung | CL21A475KAQNNNE | 187-CL21A475KAQNNNE | 0.14 € | 201 | 1276-1244-1-ND | 0.11 € | 0 | Aktiv | Mouser |  |  | Mouser (https://www.mouser.de/de/ProductDetail/Samsung-Electro-Mechanics/CL21A475KAQNNNE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) | DigiKey (https://www.digikey.de/de/products/detail/samsung-electro-mechanics/CL21A475KAQNNNE/3886902) | PDF | eindeutig | Bei DigiKey nicht ausreichend ab Lager (0) — nur über Mouser.
9 | 2 | C24, C31 | 10nF | SMD | Capacitor_SMD:C_0805_2012Metric | YAGEO | CC0805KRX7R9BB103 | 603-CC805KRX7R9BB103 | 0.15 € | 358983 | 311-1136-1-ND | 0.12 € | 234857 | Aktiv | DigiKey |  |  | Mouser (https://www.mouser.de/de/ProductDetail/YAGEO/CC0805KRX7R9BB103?qs=AgBp2OyFlx%252BOmOw2rEcWJw%3D%3D) | DigiKey (https://www.digikey.de/de/products/detail/yageo/CC0805KRX7R9BB103/302870) | PDF | eindeutig
10 | 2 | C25, C26 | 27 pF | SMD | Capacitor_SMD:C_0805_2012Metric | YAGEO | CC0805JRNPO9BN270 | 603-CC805JRNPO9BN270 | 0.10 € | 40719 | 311-1104-1-ND | 0.14 € | 0 | Aktiv | Mouser |  |  | Mouser (https://www.mouser.de/de/ProductDetail/YAGEO/CC0805JRNPO9BN270?qs=AgBp2OyFlx9Odvxw0B3RXQ%3D%3D) | DigiKey (https://www.digikey.de/de/products/detail/yageo/CC0805JRNPO9BN270/302838) | PDF | eindeutig | Bei DigiKey nicht ausreichend ab Lager (0) — nur über Mouser.
11 | 1 | C28 | 1nF/2kV | SMD | Capacitor_SMD:C_1206_3216Metric | KEMET | C1206C102KGRACTU | 80-C1206C102KGR | 1.33 € | 196492 | 399-C1206C102KGRACTUCT-ND | 1.33 € | 605024 | Aktiv | DigiKey |  |  | Mouser (https://www.mouser.de/de/ProductDetail/KEMET/C1206C102KGRACTU?qs=WyvL69DJJa9tcDzmkCOQcQ%3D%3D) | DigiKey (https://www.digikey.de/de/products/detail/kemet/C1206C102KGRACTU/1086603) | PDF | eindeutig
12 | 2 | C29, C30 | 6,8nF | SMD | Capacitor_SMD:C_0805_2012Metric | YAGEO | CC0805KRX7R9BB682 | 603-CC805KRX7R9BB682 | 0.11 € | 23242 | 311-1135-1-ND | 0.12 € | 1630 | Aktiv | Mouser |  |  | Mouser (https://www.mouser.de/de/ProductDetail/YAGEO/CC0805KRX7R9BB682?qs=AgBp2OyFlx9eO1H25iC9KQ%3D%3D) | DigiKey (https://www.digikey.de/de/products/detail/yageo/CC0805KRX7R9BB682/302869) | PDF | eindeutig
13 | 1 | C32 | 22nF | SMD | Capacitor_SMD:C_0805_2012Metric | Samsung | CL21B223KBANNNC | 187-CL21B223KBANNNC | 0.14 € | 3047 | 1276-1081-1-ND | 0.09 € | 9435 | Aktiv | DigiKey |  |  | Mouser (https://www.mouser.de/de/ProductDetail/Samsung-Electro-Mechanics/CL21B223KBANNNC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) | DigiKey (https://www.digikey.de/de/products/detail/samsung-electro-mechanics/CL21B223KBANNNC/3886739) | PDF | eindeutig
14 | 1 | D7 | YELLOW | SMD | LED_THT:LED_D3.0mm_Horizontal_O1.27mm_Z2.0mm | Wurth Electronics | 151031YS05900 | 710-151031YS05900 | 0.15 € | 1693 | 732-5009-ND | 0.15 € | 3781 | Aktiv | Mouser |  |  | Mouser (https://www.mouser.de/de/ProductDetail/Wurth-Elektronik/151031YS05900?qs=LlUlMxKIyB2uWWsOjTR3Fw%3D%3D) | DigiKey (https://www.digikey.de/de/products/detail/würth-elektronik/151031YS05900/4489991) | PDF (https://www.we-online.com/components/products/datasheet/151031YS05900.pdf) | eindeutig
15 | 1 | D8 | BLUE | SMD | LED_THT:LED_D3.0mm_Horizontal_O1.27mm_Z2.0mm | Würth Elektronik | 151033BS03000 | 710-151033BS03000 | 0.23 € | 7884 | 732-5011-ND | 0.22 € | 9093 | Aktiv | DigiKey |  |  | Mouser (https://www.mouser.de/de/ProductDetail/Wurth-Elektronik/151033BS03000?qs=2kOmHSv6VfSefdpzrMLWSw%3D%3D) | DigiKey (https://www.digikey.de/de/products/detail/würth-elektronik/151033BS03000/4489997) | PDF | eindeutig
16 | 1 | D9 | RED | SMD | LED_THT:LED_D3.0mm_Horizontal_O1.27mm_Z2.0mm | Würth Elektronik | 151033RS03000 | 710-151033RS03000 | 0.15 € | 34357 | 732-5013-ND | 0.15 € | 57977 | Aktiv | Mouser |  |  | Mouser (https://www.mouser.de/de/ProductDetail/Wurth-Elektronik/151033RS03000?qs=LlUlMxKIyB1%252BAw6bWFN43w%3D%3D) | DigiKey (https://www.digikey.de/de/products/detail/würth-elektronik/151033RS03000/4490003) | PDF | eindeutig
17 | 1 | D10 | GREEN | SMD | LED_THT:LED_D3.0mm_Horizontal_O1.27mm_Z2.0mm | Würth Elektronik | 151031VS06000 | 710-151031VS06000 | 0.14 € | 23526 | 732-5008-ND | 0.14 € | 53301 | Aktiv | Mouser |  |  | Mouser (https://www.mouser.de/de/ProductDetail/Wurth-Elektronik/151031VS06000?qs=LlUlMxKIyB01ggED1iKswA%3D%3D) | DigiKey (https://www.digikey.de/de/products/detail/würth-elektronik/151031VS06000/4489988) | PDF | eindeutig
18 | 1 | D11 | SS34 | SMD | Diode_SMD:D_SMA | Comchip Technology | SS34-HF | 750-SS34-HF | 0.46 € | 22099 | 641-2115-1-ND | 0.46 € | 53701 | Aktiv | DigiKey |  |  | Mouser (https://www.mouser.de/de/ProductDetail/Comchip-Technology/SS34-HF?qs=%252B6g0mu59x7Kt0FF4l3l3pg%3D%3D) | DigiKey (https://www.digikey.de/de/products/detail/comchip-technology/SS34-HF/10279693) | PDF (https://www.vishay.com/docs/88751/ss32.pdf) | eindeutig
19 | 1 | D12 | SMAJ5.0A | SMD | Diode_SMD:D_SMA | Littelfuse | SMAJ5.0A | 576-SMAJ5.0A | 0.38 € | 24423 | SMAJ5.0ALFCT-ND | 0.43 € | 167714 | Aktiv | Mouser |  |  | Mouser (https://www.mouser.de/de/ProductDetail/Littelfuse/SMAJ5.0A?qs=2VFNtWizgicfetZVA4gWHA%3D%3D) | DigiKey (https://www.digikey.de/de/products/detail/littelfuse-inc/SMAJ5-0A/762250) | PDF (https://www.littelfuse.com/media?itemid=75e32973-b177-4ee3-a0ff-cedaf1abdb93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) | eindeutig
20 | 1 | F1 | 1.1A | SMD | Fuse:Fuse_1206_3216Metric | Bourns | MF-NSMF110-2 | 652-MF-NSMF110-2 | 0.28 € | 11988 | MF-NSMF110-2CT-ND | 0.33 € | 41044 | Aktiv | Mouser |  |  | Mouser (https://www.mouser.de/de/ProductDetail/Bourns/MF-NSMF110-2?qs=78xkMtwow2zgSbc2Qx8dhg%3D%3D) | DigiKey (https://www.digikey.de/de/products/detail/bourns-inc/MF-NSMF110-2/662810) | PDF | eindeutig
21 | 1 | FB1 | Ferrit 600R@100MHz | SMD | Inductor_SMD:L_0805_2012Metric | Murata | BLM21PG601SN1D | 81-BLM21PG601SN1D | 0.10 € | 0 | 490-BLM21PG601SN1DCT-ND | 0.10 € | 4446 | Aktiv | DigiKey |  |  | Mouser (https://www.mouser.de/de/ProductDetail/Murata-Electronics/BLM21PG601SN1D?qs=iLKYxzqNS74FEXcdq8OVUQ%3D%3D) | DigiKey (https://www.digikey.de/de/products/detail/murata-electronics/BLM21PG601SN1D/24763118) | PDF | eindeutig | Bei Mouser nicht ausreichend ab Lager (0) — nur über DigiKey.
22 | 2 | J1, J_PWR1 | 12401598E4-2A | THT | shbs_power:USB_C_Receptacle_Amphenol_12401598E4-2A | Amphenol | 12401598E4#2A | 523-12401598E4#2A | 1.62 € | 9245 | 12401598E4#2ACT-ND | 1.64 € | 39568 | Aktiv | Mouser |  |  | Mouser (https://www.mouser.de/de/ProductDetail/Amphenol-Commercial-Products/12401598E42A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) | DigiKey (https://www.digikey.de/de/products/detail/amphenol-cs-commercial-products/12401598E4-2A/6051823) | PDF (https://www.usb.org/sites/default/files/documents/usb_type-c.zip) | eindeutig
23 | 1 | J6 | 61200621621 | THT | wuerth_6120XX21621:61200621621 | Würth Elektronik | 61200621621 | 710-61200621621 | 0.40 € | 46778 | 732-5394-ND | 0.43 € | 20950 | Aktiv | Mouser |  |  | Mouser (https://www.mouser.de/de/ProductDetail/Wurth-Elektronik/61200621621?qs=PhR8RmCirEbjX8n1RKw4Jw%3D%3D) | DigiKey (https://www.digikey.de/de/products/detail/würth-elektronik/61200621621/4846913) | PDF | eindeutig
24 | 1 | L1 | 10uH | SMD | Inductor_SMD:L_Bourns_SRN6045TA | Bourns | SRN6045TA-100M | 652-SRN6045TA-100M | 0.43 € | 4297 | SRN6045TA-100MCT-ND | 0.43 € | 4355 | Aktiv | DigiKey |  |  | Mouser (https://www.mouser.de/de/ProductDetail/Bourns/SRN6045TA-100M?qs=Vt59ZOdFuWZBf9gWI0WHQg%3D%3D) | DigiKey (https://www.digikey.de/de/products/detail/bourns-inc/SRN6045TA-100M/6155107) | PDF | eindeutig
25 | 1 | PS1 | AP3211 | SMD | shbs_power:MP2359DJ | Diodes Incorporated | AP3211KTR-G1 | 621-AP3211KTR-G1 | 0.46 € | 18260 | AP3211KTR-G1DICT-ND | 0.47 € | 32678 | Aktiv | Mouser |  |  | Mouser (https://www.mouser.de/de/ProductDetail/Diodes-Incorporated/AP3211KTR-G1?qs=x6A8l6qLYDBtUEamkYz8cA%3D%3D) | DigiKey (https://www.digikey.de/de/products/detail/diodes-incorporated/AP3211KTR-G1/4470864) | PDF (https://www.diodes.com/assets/Datasheets/AP3211.pdf) | eindeutig
26 | 6 | R9, R28, R29, R30, R31, R32 | 10kΩ | SMD | Resistor_SMD:R_0805_2012Metric | YAGEO | RC0805FR-0710KL | 603-RC0805FR-0710KL | 0.09 € | 3453672 | 311-10.0KCRCT-ND | 0.09 € | 1935589 | Aktiv | Mouser |  |  | Mouser (https://www.mouser.de/de/ProductDetail/YAGEO/RC0805FR-0710KL?qs=7bY8808IzHq6vrU3BeiiYw%3D%3D) | DigiKey (https://www.digikey.de/de/products/detail/yageo/RC0805FR-0710KL/727535) | PDF (https://www.yageo.com/upload/media/product/productsearch/datasheet/rchip/PYu-RC_Group_51_RoHS_L_12.pdf) | eindeutig
27 | 5 | R13, R15, R16, R33, R34 | 220Ω | SMD | Resistor_SMD:R_0805_2012Metric | YAGEO | RC0805FR-07220RL | 603-RC0805FR-07220RL | 0.09 € | 218894 | 311-220CRCT-ND | 0.09 € | 380504 | Aktiv | Mouser |  |  | Mouser (https://www.mouser.de/de/ProductDetail/YAGEO/RC0805FR-07220RL?qs=KCkj9j0IqmXa4o%252BHKR6RGw%3D%3D) | DigiKey (https://www.digikey.de/de/products/detail/yageo/RC0805FR-07220RL/727741) | PDF (https://www.yageo.com/upload/media/product/productsearch/datasheet/rchip/PYu-RC_Group_51_RoHS_L_12.pdf) | eindeutig
28 | 1 | R14 | 100Ω | SMD | Resistor_SMD:R_0805_2012Metric | YAGEO | RC0805FR-07100RL | 603-RC0805FR-07100RL | 0.09 € | 471173 | 311-100CRCT-ND | 0.09 € | 1407631 | Aktiv | Mouser |  |  | Mouser (https://www.mouser.de/de/ProductDetail/YAGEO/RC0805FR-07100RL?qs=8Y8p%252BasKcI6MtXUgG4E6SQ%3D%3D) | DigiKey (https://www.digikey.de/de/products/detail/yageo/RC0805FR-07100RL/727543) | PDF (https://www.yageo.com/upload/media/product/productsearch/datasheet/rchip/PYu-RC_Group_51_RoHS_L_12.pdf) | eindeutig
29 | 1 | R17 | 49,9 kΩ | SMD | Resistor_SMD:R_0805_2012Metric | YAGEO | RC0805FR-0749K9L | 603-RC0805FR-0749K9L | 0.09 € | 195715 | 311-49.9KCRCT-ND | 0.09 € | 950283 | Aktiv | Mouser |  |  | Mouser (https://www.mouser.de/de/ProductDetail/YAGEO/RC0805FR-0749K9L?qs=VLOqbHBAO5cDWH1fFfdblw%3D%3D) | DigiKey (https://www.digikey.de/de/products/detail/yageo/RC0805FR-0749K9L/727985) | PDF | eindeutig
30 | 1 | R18 | 16,2 kΩ | SMD | Resistor_SMD:R_0805_2012Metric | YAGEO | RC0805FR-0716K2L | 603-RC0805FR-0716K2L | 0.09 € | 12535 | 311-16.2KCRCT-ND | 0.09 € | 38373 | Aktiv | Mouser |  |  | Mouser (https://www.mouser.de/de/ProductDetail/YAGEO/RC0805FR-0716K2L?qs=8Y8p%252BasKcI6jseI9MyaaYA%3D%3D) | DigiKey (https://www.digikey.de/de/products/detail/yageo/RC0805FR-0716K2L/727622) | PDF | eindeutig
31 | 4 | R19, R20, R21, R22 | 5,1 kΩ | SMD | Resistor_SMD:R_0805_2012Metric | YAGEO | RC0805FR-075K1L | 603-RC0805FR-075K1L | 0.10 € | 36518 | 311-5.10KCRCT-ND | 0.09 € | 0 | Aktiv | Mouser |  |  | Mouser (https://www.mouser.de/de/ProductDetail/YAGEO/RC0805FR-075K1L?qs=TvbiuNL4H85i1jCYhRJkKQ%3D%3D) | DigiKey (https://www.digikey.de/de/products/detail/yageo/RC0805FR-075K1L/727988) | PDF | eindeutig | Bei DigiKey nicht ausreichend ab Lager (0) — nur über Mouser.
32 | 1 | R27 | 12,4kΩ, 1% | SMD | Resistor_SMD:R_0805_2012Metric | YAGEO | RC0805FR-0712K4L | 603-RC0805FR-0712K4L | 0.09 € | 9810 | 311-12.4KCRCT-ND | 0.09 € | 13307 | Aktiv | Mouser |  |  | Mouser (https://www.mouser.de/de/ProductDetail/YAGEO/RC0805FR-0712K4L?qs=8Y8p%252BasKcI6kosjhKovvuQ%3D%3D) | DigiKey (https://www.digikey.de/de/products/detail/yageo/RC0805FR-0712K4L/727572) | PDF | eindeutig
33 | 1 | R35 | 0Ω | SMD | Resistor_SMD:R_0805_2012Metric | YAGEO | RC0805JR-070RL | 603-RC0805JR-070RL | 0.21 € | 2669469 | 311-0.0ARCT-ND | 0.09 € | 2861448 | Aktiv | DigiKey |  |  | Mouser (https://www.mouser.de/de/ProductDetail/YAGEO/RC0805JR-070RL?qs=3ldFlDWnkKyEhdaPjQHEFA%3D%3D) | DigiKey (https://www.digikey.de/de/products/detail/yageo/RC0805JR-070RL/728216) | PDF | eindeutig
34 | 4 | R36, R37, R39, R40 | 49,9Ω 1% | SMD | Resistor_SMD:R_0805_2012Metric | YAGEO | RC0805FR-0749R9L | 603-RC0805FR-0749R9L | 0.09 € | 308094 | 311-49.9CRCT-ND | 0.09 € | 376340 | Aktiv | Mouser |  |  | Mouser (https://www.mouser.de/de/ProductDetail/YAGEO/RC0805FR-0749R9L?qs=VLOqbHBAO5fOTWOXSZvQ2A%3D%3D) | DigiKey (https://www.digikey.de/de/products/detail/yageo/RC0805FR-0749R9L/727984) | PDF | eindeutig
35 | 1 | R38 | 10Ω 1% | SMD | Resistor_SMD:R_0805_2012Metric | YAGEO | RC0805FR-0710RL | 603-RC0805FR-0710RL | 0.09 € | 119285 | 311-10.0CRCT-ND | 0.10 € | 601024 | Aktiv | Mouser |  |  | Mouser (https://www.mouser.de/de/ProductDetail/YAGEO/RC0805FR-0710RL?qs=8Y8p%252BasKcI5T5bn0nqNRsw%3D%3D) | DigiKey (https://www.digikey.de/de/products/detail/yageo/RC0805FR-0710RL/727534) | PDF | eindeutig
36 | 1 | S2 | PTS645VL58-2 LFS | THT | PTS645VL58-2LFS:SW_Tactile_SPST_Angled_PTS645Vx58-2LFS | C&K | PTS645VL58-2 LFS | 611-PTS645VL582 | 0.28 € | 290 | CKN9116-ND | 0.36 € | 19085 | Aktiv | Mouser |  |  | Mouser (https://www.mouser.de/de/ProductDetail/CK/PTS645VL58-2-LFS?qs=rqnA19JZHeQ3WAdYuSwH%2Fg%3D%3D) | DigiKey (https://www.digikey.de/de/products/detail/c-k/PTS645VL58-2-LFS/1146769) | PDF (https://www.ckswitches.com/media/1471/pts645.pdf) | eindeutig
37 | 1 | T1 | 7499011121A | THT | wuerth_rj45:T_Wurth_WE-RJ45LAN_7499011121A | Wurth Elektronik | 7499011121A | 710-7499011121A | 6.26 € | 1259 | 732-4509-5-ND | 5.92 € | 2673 | Aktiv | DigiKey |  |  | Mouser (https://www.mouser.de/de/ProductDetail/Wurth-Elektronik/7499011121A?qs=SaTeGCoDkn2VpWS6B7hWdg%3D%3D) | DigiKey (https://www.digikey.de/de/products/detail/würth-elektronik/7499011121A/4031599) | PDF (https://www.we-online.com/catalog/datasheet/7499011121A.pdf?ki) | eindeutig
38 | 1 | U1 | D3V3XA4B10LP | SMD | Package_DFN_QFN:Diodes_UDFN-10_1x2.5mm_P0.5mm | Diodes Incorporated | D3V3XA4B10LP-7 | 621-D3V3XA4B10LP-7 | 0.37 € | 11929 | 31-D3V3XA4B10LP-7CT-ND | 0.39 € | 11467 | Aktiv | Mouser |  |  | Mouser (https://www.mouser.de/de/ProductDetail/Diodes-Incorporated/D3V3XA4B10LP-7?qs=gZXFycFWdAPojYkoyRsLeQ%3D%3D) | DigiKey (https://www.digikey.de/de/products/detail/diodes-incorporated/D3V3XA4B10LP-7/10295141) | PDF (https://www.diodes.com/assets/Datasheets/D3V3XA4B10LP.pdf) | eindeutig
39 | 1 | U6 | ESP32-S3-WROOM-1U-N16R8 | SMD | ESP32-S3-WROOM-1U-N16R8:ESP32-S3-WROOM-1U | Espressif Systems | ESP32-S3-WROOM-1U-N16R8 | 356-ESP32S3WM1UN16R8 | 5.93 € | 6109 | 1965-ESP32-S3-WROOM-1U-N16R8CT-ND | 5.79 € | 66 | Aktiv | Mouser |  |  | Mouser (https://www.mouser.de/de/ProductDetail/Espressif-Systems/ESP32-S3-WROOM-1U-N16R8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) | DigiKey (https://www.digikey.de/de/products/detail/espressif-systems/ESP32-S3-WROOM-1U-N16R8/16162641) | PDF (https://www.espressif.com/sites/default/files/documentation/esp32-s3-wroom-1_wroom-1u_datasheet_en.pdf) | eindeutig | Bezugsquelle Mouser festgelegt (Bediener, 2026-09-24): DigiKey hat nur zweistelligen Lagerbestand, Mouser mehrere Tausend — sicherer fuer groessere Stueckzahlen, Aufpreis rund 0,14 EUR.
40 | 1 | U7 | W5500 | SMD | W5500:48LQFP_W5500_WIZ | WIZnet | W5500 | 950-W5500 | 2.98 € | 43173 | 1278-W5500CT-ND | 3.18 € | 62550 | Aktiv | Mouser |  |  | Mouser (https://www.mouser.de/de/ProductDetail/WIZnet/W5500?qs=2vh%252B45pPFtzthUpYPd4pqA%3D%3D) | DigiKey (https://www.digikey.de/de/products/detail/wiznet/W5500/4425702) | PDF (https://docs.wiznet.io/img/products/w5500/W5500_ds_v110e.pdf) | eindeutig
41 | 1 | Y1 | 25 MHz | SMD | wuerth_830059532:Y_Wurth_WE-XTAL_Quartz-CFPX-104 | Wurth Elektronik | 830059532 | 710-830059532 | 0.76 € | 3563 | 1923-830059532CT-ND | 0.75 € | 3667 | Aktiv | DigiKey |  |  | Mouser (https://www.mouser.de/de/ProductDetail/Wurth-Elektronik/830059532?qs=2WXlatMagcG66pWFk6sRpA%3D%3D) | DigiKey (https://www.digikey.de/de/products/detail/würth-elektronik/830059532/13900377) | PDF (https://www.we-online.com/catalog/datasheet/830059532.pdf?ki) | eindeutig
 |  |  |  |  |  |  |  |  |  |  |  |  |  |  | Summe erfasster Positionen
 |  |  |  |  |  |  |  |  |  |  |  |  |  |  | davon DigiKey
 |  |  |  |  |  |  |  |  |  |  |  |  |  |  | davon Mouser
Von 41 Positionen tragen 41 einen Preis aus der API (16 über DigiKey, 25 über Mouser).
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

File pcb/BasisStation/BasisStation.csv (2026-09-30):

Reference | Value | Datasheet | Footprint | Qty | DNP
ANT1 | CAB.6061 |  |  | 1
ANT2 | GW.20.A151 |  |  | 1
C7,C10,C12 | WCAP-FTXX_P10 |  | WCAP-FTXX_P10:WCAP-FTXX_P10L13W7H13 | 3
C8 | WCAP-PT5H_6.3X5.2 |  | WCAP-PT5H_6.3X5.2:WCAP-PT5H_6.3X5.2_DXL_ | 1
C13 | 10uF |  | Capacitor_SMD:C_0805_2012Metric | 1
C14 | 22uF |  | Capacitor_SMD:C_0805_2012Metric | 1
C15 | 100 nF |  | Capacitor_SMD:C_0805_2012Metric | 1
C16,C17,C18,C19,C20,C21,C22 | 100nF |  | Capacitor_SMD:C_0805_2012Metric | 7
C23 | 4,7 µF |  | Capacitor_SMD:C_0805_2012Metric | 1
C24,C31 | 10nF |  | Capacitor_SMD:C_0805_2012Metric | 2
C25,C26 | 27 pF |  | Capacitor_SMD:C_0805_2012Metric | 2
C27 | 10 µF |  | Capacitor_SMD:C_0805_2012Metric | 1
C28 | 1nF/2kV |  | Capacitor_SMD:C_1206_3216Metric | 1
C29,C30 | 6,8nF |  | Capacitor_SMD:C_0805_2012Metric | 2
C32 | 22nF |  | Capacitor_SMD:C_0805_2012Metric | 1
D7 | YELLOW |  | LED_THT:LED_D3.0mm_Horizontal_O1.27mm_Z2.0mm | 1
D8 | BLUE |  | LED_THT:LED_D3.0mm_Horizontal_O1.27mm_Z2.0mm | 1
D9 | RED |  | LED_THT:LED_D3.0mm_Horizontal_O1.27mm_Z2.0mm | 1
D10 | GREEN |  | LED_THT:LED_D3.0mm_Horizontal_O1.27mm_Z2.0mm | 1
D11 | SS34 | https://www.vishay.com/docs/88751/ss32.pdf | Diode_SMD:D_SMA | 1
D12 | SMAJ5.0A | https://www.littelfuse.com/media?itemid=75e32973-b177-4ee3-a0ff-cedaf1abdb93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 | Diode_SMD:D_SMA | 1
F1 | 1.1A |  | Fuse:Fuse_1206_3216Metric | 1
FB1 | Ferrit 600R@100MHz |  | Inductor_SMD:L_0805_2012Metric | 1
J1,J_PWR1 | 12401598E4-2A | https://www.amphenol-cs.com/products/usb/type-c,https://www.usb.org/sites/default/files/documents/usb_type-c.zip | shbs_power:USB_C_Receptacle_Amphenol_12401598E4-2A | 2
J6 | 61200621621 |  | wuerth_6120XX21621:61200621621 | 1
L1 | 10uH |  | Inductor_SMD:L_Bourns_SRN6045TA | 1
PS1 | AP3211 | https://www.diodes.com/assets/Datasheets/AP3211.pdf | shbs_power:MP2359DJ | 1
R9,R28,R29,R30,R31,R32 | 10kΩ | https://www.yageo.com/upload/media/product/productsearch/datasheet/rchip/PYu-RC_Group_51_RoHS_L_12.pdf | Resistor_SMD:R_0805_2012Metric | 6
R13,R15,R16,R33,R34 | 220Ω | https://www.yageo.com/upload/media/product/productsearch/datasheet/rchip/PYu-RC_Group_51_RoHS_L_12.pdf | Resistor_SMD:R_0805_2012Metric | 5
R14 | 100Ω | https://www.yageo.com/upload/media/product/productsearch/datasheet/rchip/PYu-RC_Group_51_RoHS_L_12.pdf | Resistor_SMD:R_0805_2012Metric | 1
R17 | 49,9 kΩ |  | Resistor_SMD:R_0805_2012Metric | 1
R18 | 16,2 kΩ |  | Resistor_SMD:R_0805_2012Metric | 1
R19,R20,R21,R22 | 5,1 kΩ |  | Resistor_SMD:R_0805_2012Metric | 4
R27 | 12,4kΩ, 1% |  | Resistor_SMD:R_0805_2012Metric | 1
R35 | 0Ω |  | Resistor_SMD:R_0805_2012Metric | 1 | DNP
R36,R37,R39,R40 | 49,9Ω 1% |  | Resistor_SMD:R_0805_2012Metric | 4
R38 | 10Ω 1% |  | Resistor_SMD:R_0805_2012Metric | 1
S2 | PTS645VL58-2 LFS | https://www.ckswitches.com/media/1471/pts645.pdf | PTS645VL58-2LFS:SW_Tactile_SPST_Angled_PTS645Vx58-2LFS | 1
T1 | 7499011121A | https://www.we-online.com/catalog/datasheet/7499011121A.pdf?ki | wuerth_rj45:T_Wurth_WE-RJ45LAN_7499011121A | 1
U1 | D3V3XA4B10LP | https://www.diodes.com/assets/Datasheets/D3V3XA4B10LP.pdf | Package_DFN_QFN:Diodes_UDFN-10_1x2.5mm_P0.5mm | 1
U6 | ESP32-S3-WROOM-1U-N16R8 | https://www.espressif.com/sites/default/files/documentation/esp32-s3-wroom-1_wroom-1u_datasheet_en.pdf | ESP32-S3-WROOM-1U-N16R8:ESP32-S3-WROOM-1U | 1
U7 | W5500 | https://docs.wiznet.io/img/products/w5500/W5500_ds_v110e.pdf | W5500:48LQFP_W5500_WIZ | 1
Y1 | 25 MHz | https://www.we-online.com/catalog/datasheet/830059532.pdf?ki | wuerth_830059532:Y_Wurth_WE-XTAL_Quartz-CFPX-104 | 1

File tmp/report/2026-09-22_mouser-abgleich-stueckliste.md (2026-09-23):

---
type: analysis
created: 2026-09-22
jira: SHBS-15
status: final
---

# Mouser-Abgleich der Stückliste

## Ausgangslage

Der erste Stücklisten-Export (Commit `5877d96`) blieb ohne Preise und ohne
Mouser-Teilenummern — zu dem Zeitpunkt lag kein API-Schlüssel vor. Seit Task
0038 sind Schlüssel, LibreOffice und `openpyxl` im Container verfügbar. Dieser
Abgleich holt die Beschaffungsdaten nach und prüft dabei, ob die im Schaltplan
gepflegten Teilenummern überhaupt noch gültig sind.

## Ergebnis / Befunde

### B1 — Teilenummern liegen unter uneinheitlichen Feldnamen

Je nach Herkunft eines Symbols (SnapEDA, Würth-Generator, handgepflegt) heißt
dasselbe Feld anders:

| Bedeutung | Vorkommende Feldnamen |
| --- | --- |
| Mouser-Teilenr. | `Mouser Part Number`, `MOUSER_PART_NUMBER` |
| Hersteller-Teilenr. | `Manufacturer_Part_Number`, `MANUFACTURER_PART_NUMBER`, `MP`, `Part Number` |
| Hersteller | `Manufacturer`, `MANUFACTURER`, `MF`, `Manufacturer_Name`, `MANUFACTURER_NAME` |

`kicad-cli sch export bom --fields MPN` liefert dafür eine leere Spalte, ohne
zu warnen — das Feld `MPN` existiert im Projekt gar nicht. **Das ist die
Ursache, warum der erste Export ohne Teilenummern blieb.** Konsequenz: die
Schaltplanblätter werden direkt geparst statt über den CLI-Export.

### B2 — Vier im Schaltplan gepflegte Mouser-Nummern sind nicht mehr gültig

Das war der eigentliche Fund. Die Nummern wurden nicht blind übernommen,
sondern gegen die API geprüft:

| Bauteil | Im Schaltplan | Tatsächlich | Bewertung |
| --- | --- | --- | --- |
| `ANT1` | `742-CAB.6061` | `960-CAB.6061`, 845 ab Lager | Nummer gewechselt |
| `ANT2` | `742-GW.20.5150` | **kein Treffer** | Typ abgekündigt, Nachfolger siehe Nachtrag |
| `J1`, `J_PWR1` | `640-12401548E42A` | `523-12401548E4#2A`, nicht bevorratet | Nummer gewechselt |
| `U1` | *(keine)* | `D3V3XA4B10LP` ist `N/A`, bestellbar nur als `D3V3XA4B10LP-7` | Gurtvariante nötig |

`ANT2` sah zunächst nach dem kritischsten Punkt aus. Der Nachtrag unten
entschärft das.

### Nachtrag 2026-09-23 — Korrektur zu ANT2 und ein neuer Befund

**Die Aussage „für ANT2 gibt es bei Mouser keinen Bezugsweg" war zu weit
gefasst.** Sie galt für die exakte Nummer, nicht für das Bauteil. Eine
Stichwortsuche statt einer Teilenummernsuche zeigt: Taoglas ist bei Mouser auf
das `960-`-Präfix umgezogen, und der Seriennachfolger ist verfügbar.

| Position | Mouser-Nr. | Lager | Preis @1 |
| --- | --- | ----- | --- |
| ANT2 Nachfolger | `960-GW.20.A151` (2 dBi, 2,4 GHz, RP-SMA(M) gerade) | 650 | 8,46 € |
| dito, weiß | `960-GW.20.A151W` | 480 | 8,27 € |
| ANT1 Pigtail | `960-CAB.6061` | 845 | 4,47 € |

Form, Anschluss und Gewinn stimmen mit `GW.20.5150` überein. Die Antennenkette
ist damit **vollständig über Mouser beschaffbar** — es bleibt eine
Teilenummernpflege, keine Produktentscheidung.

**Lehre für die Methode:** Eine erfolglose Teilenummernsuche belegt nur, dass
*diese Nummer* nicht mehr gilt — nicht, dass das Bauteil fehlt. Vor dem Schluss
„nicht beschaffbar" gehört eine Stichwortsuche über Hersteller und Serie dazu.
Derselbe Fehler wäre bei Reichelt fast passiert (siehe
[Reichelt-Report](2026-09-22_reichelt-verfuegbarkeit.md), B5).

**Neuer Befund — `J1`/`J_PWR1` sind ebenfalls abgekündigt.** Die Amphenol-Buchse
`12401548E4#2A` ist laut DigiKey „no longer manufactured, substitute products
are available". Das erklärt den Lagerbestand 0 bei Mouser und ist kein
Distributorproblem, sondern ein Abkündigungsfall. **Hier ist wirklich ein Ersatz
zu wählen** — und anders als bei der Antenne hängt daran ein Footprint, der
möglicherweise angepasst werden muss.

### B3 — `PS1` ist gelistet, aber nicht verfügbar

Der Buck-Regler `MP2359DJ-LF-Z` (`946-MP2359DJLFZ`, 2,06 €) hat
**Lagerbestand 0**. Das betrifft den Termin für den Prototypenaufbau, nicht
die Schaltung.

### B4 — `J1` und `J_PWR1` waren als zwei Positionen geführt

Beide nutzen dieselbe Amphenol-Buchse und denselben Footprint, aber
verschiedene Symbole (`Connector:USB_C_Receptacle_USB2.0_16P` gegenüber
`shbs_power:USB_C_Receptacle_Power`). Eine Gruppierung nach `lib_id` trennt
sie deshalb künstlich. [hardware.md](../../docs/project/hardware.md) beschreibt
sie ausdrücklich als *eine* BOM-Position. Gruppierung auf Wert + Footprint
umgestellt: 47 → 46 Positionen.

### Abdeckung

| Kennzahl | Wert |
| --- | ---- |
| Bestückte Referenzen | 78 |
| Bestellpositionen | 46 |
| Mit Preis aus der API | 15 |
| Ohne Teilenummer (überwiegend generische Passivteile) | 29 |
| Teilsumme der erfassten Positionen | 28,65 € |

Die Teilsumme ist **kein** Baugruppenpreis — zwei Drittel der Positionen sind
noch nicht spezifiziert.

## Empfehlungen

1. **Schaltplan-Felder korrigieren** (`ANT1`, `J1`, `J_PWR1`): veraltete
   Mouser-Nummern eintragen, sonst liefert jeder neue Export wieder die alte
   Nummer. Gleicher Zug: `FB1` auf ein Ferrit-Symbol, `J6`-Wert auf die
   Würth-Bestellbezeichnung.
2. **Ersatz für `ANT2` festlegen** — Bediener, weil es eine Produktentscheidung
   ist (Polarität und Steckertyp müssen bleiben).
3. **Generische Passivteile spezifizieren** — 29 Positionen. Vorrang haben
   `C25`/`C26` am 25-MHz-Quarz (Lastkapazität) und die 1-%-Widerstände im
   Ethernet-Zweig.
4. **Lieferzeit für `PS1` klären**, bevor ein Aufbautermin zugesagt wird.

## Nächste Schritte

- Commit der Stückliste und der Werkzeuge (Task 0039).
- Folgetask für die Schaltplan-Korrekturen aus Empfehlung 1 — eigenes Problem,
  eigenes Ticket.
- Entscheidungen zu Empfehlung 2 und 3 liegen beim Bediener; ohne sie bleibt
  die Stückliste unvollständig.

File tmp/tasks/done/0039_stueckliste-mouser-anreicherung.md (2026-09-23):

---
title: Stueckliste reproduzierbar erzeugen und mit Mouser-Daten anreichern
created: 2026-09-22
jira: SHBS-15
priority: high
type: feature
---

## Kontext

Der erste Stuecklisten-Export ([2026-09-22_stueckliste-basisstation.xlsx](../../report/2026-09-22_stueckliste-basisstation.xlsx),
Commit `5877d96`) entstand ad hoc; ein Skript dazu existiert nicht. Die Spalten
Mouser-Teilenummer und Einzelpreis blieben leer, weil zu dem Zeitpunkt kein
API-Schluessel vorlag. Seit Task 0038 sind Schluessel, LibreOffice und
`openpyxl` im Container verfuegbar.

Bei der Bestandsaufnahme fuer diesen Task kam ein Befund dazu, den der erste
Export uebersehen hat: **Teilenummern liegen im Schaltplan unter
uneinheitlichen Feldnamen**, je nachdem woher das Symbol stammt
(SnapEDA, Wuerth-Generator, handgepflegt):

| Bedeutung | Vorkommende Feldnamen |
| --- | --- |
| Mouser-Teilenr. | `Mouser Part Number`, `MOUSER_PART_NUMBER` |
| Hersteller-Teilenr. | `Manufacturer_Part_Number`, `MANUFACTURER_PART_NUMBER`, `MP`, `Part Number` |
| Hersteller | `Manufacturer`, `MANUFACTURER`, `MF`, `Manufacturer_Name`, `MANUFACTURER_NAME` |

`kicad-cli sch export bom --fields MPN` findet davon nichts, weil das Feld
`MPN` im Projekt gar nicht existiert. Deshalb wird der Schaltplan direkt
geparst statt ueber den CLI-Export.

Ausgangslage nach dem Feld-Abgleich (78 Instanzen):

- **9 mit Mouser-Teilenr.** — direkt abfragbar: `ANT1`, `ANT2`, `J1`,
  `J_PWR1`, `PS1`, `S2`, `T1`, `U6`, `Y1`
- **6 nur mit Hersteller-Teilenr.** — Suche ueber MPN: `C7`, `C8`, `C10`,
  `C12`, `D7`, `U7`
- **63 ohne Teilenummer** — davon rund 50 generische Passivteile; hier kann
  die API nichts liefern, die Felder bleiben zum Ausfuellen offen

## Ziel

Ein versioniertes Skript erzeugt die Stueckliste reproduzierbar aus dem
Schaltplan und fuellt Preis, Lagerbestand und Mouser-Teilenummer fuer alle
Positionen, zu denen eine Teilenummer bekannt ist. Die Mappe rechnet in
LibreOffice fehlerfrei durch.

## Schritte

- [x] S-Expression-Parser fuer KiCad-Dateien (`tmp/bom/sexp.py`)
- [x] Feld-Aliase ermittelt und dokumentiert (siehe Kontext)
- [x] Extraktion der 78 Instanzen inkl. Alias-Aufloesung, Gruppierung nach
      **Wert + Footprint** (nicht `lib_id`, siehe Fortschritt 2026-09-22)
- [x] Mouser-Client: Abfrage ueber Mouser-Teilenr. mit Rueckfall auf
      MPN-Stichwortsuche, Ergebnisse in `tmp/bom/mouser_cache.json`
- [x] xlsx-Erzeugung: Blaetter Stueckliste / Einzelpositionen / Offene Punkte,
      Preisstaffel und Lagerbestand aus der API, Formeln fuer Gesamtpreis
- [x] Gegenprobe: 78 Referenzen, jede in genau einer Gruppe, Mengensumme 78,
      beide Blaetter deckungsgleich
- [x] Mappe mit LibreOffice durchgerechnet — 0 Formelfehler, Summe 28,65 EUR
      stimmt mit den Zeilenwerten ueberein
- [x] Doku: `docs/project/hardware.md` aktualisiert (veraltete Mouser-Nummern,
      neuer Abschnitt zur bestellfaehigen Stueckliste)
- [x] Commit-Vorschlag an Bediener, nach Freigabe lokal committet

## Fortschritt

- 2026-09-22: Task angelegt. Vorarbeit bereits erledigt: Parser steht,
  Feld-Aliase sind ermittelt, Abfrage-Kandidaten (15 von 78) stehen fest.
  Naechster Schritt: Extraktion und Gruppierung im Skript.
- 2026-09-22 (2): Skript erstellt (`generate_bom.py`, `write_xlsx.py`,
  `sexp.py`). Erster Lauf: 13 von 47 Positionen mit Preis.
- 2026-09-22 (3): **Befund — vier Abfragen liefen ins Leere, Ursache waren
  veraltete Mouser-Nummern im Schaltplan**, nicht das Skript. Nachgefasst per
  Stichwortsuche: `742-CAB.6061` → `960-CAB.6061`; `640-12401548E42A` →
  `523-12401548E4#2A`; `GW.20.5150` wird von Mouser nicht mehr gefuehrt;
  `D3V3XA4B10LP` ist nur als `-7`-Variante (Tape & Reel) bestellbar.
  Daraufhin Rueckfall auf MPN-Stichwortsuche eingebaut, Abweichungen werden
  markiert statt still ueberschrieben. Ergebnis: 15 von 46 Positionen.
- 2026-09-22 (4): Gruppierung von `lib_id` auf Wert+Footprint umgestellt —
  `J1` (Symbol `USB_C_Receptacle_USB2.0_16P`) und `J_PWR1` (Symbol
  `USB_C_Receptacle_Power`) sind dieselbe Amphenol-Buchse und waren als zwei
  Positionen gefuehrt. `hardware.md` beschreibt sie ausdruecklich als *eine*
  BOM-Position. Dadurch 47 → 46 Positionen.
- 2026-09-22 (5): Validierung abgeschlossen. LibreOffice rechnet die Mappe
  fehlerfrei durch (0 Formelfehler), Teilsumme 28,65 EUR ueber 15 Positionen,
  78 Referenzen in beiden Blaettern deckungsgleich. Doku nachgezogen.
  **Naechster Schritt:** Commit-Vorschlag, dann Folgetask fuer die Korrektur
  der Schaltplan-Felder (FB1, J6, veraltete Mouser-Nummern).

## Commits

- 3021dc2 Stueckliste reproduzierbar erzeugt und mit Mouser-Daten angereichert

## Offene Fragen

- Keine blockierenden. Die inhaltlichen Entscheidungen zu den generischen
  Passivteilen (Toleranz, Spannung, Dielektrikum) sind bewusst **nicht** Teil
  dieses Tasks — sie gehoeren zum Bediener und stehen im Blatt
  "Offene Punkte".

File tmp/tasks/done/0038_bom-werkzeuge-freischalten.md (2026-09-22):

---
status: done
priority: high
type: feature
created: 2026-09-22
jira: SHBS-15
---

# Werkzeuge fuer die Stuecklisten-Erstellung freischalten

## Kontext

Fuer eine bestellfaehige Stueckliste fehlten zwei Dinge: Zugriff auf
Mouser-Daten und eine Moeglichkeit, erzeugte `.xlsx` durchzurechnen.

## Befund zur Erreichbarkeit

Die urspruengliche Annahme "Mouser ist nicht erreichbar" war zu pauschal.
Gemessen aus dem Container:

| Ziel | Ergebnis |
| ---- | --- |
| `api.mouser.com` | **HTTP 302 in 0,25 s** — erreichbar |
| `www.mouser.de` | HTTP 000 — geblockt (Bot-Schutz) |
| `pypi.org` | HTTP 200 — erreichbar |

Geblockt ist also nur die **Webseite**, nicht die API. Eine
Firewall-Freigabe ist nicht noetig. Abfragen laufen ueber die Search-API,
nicht ueber Scraping der Produktseiten.

## Schritte

- [x] Mouser **Search**-API-Schluessel unter `secrets/mouser_api_key`
      abgelegt, Rechte `600`, per `.gitignore` (`secrets/*`) ausgeschlossen.
- [x] Funktionstest gegen `api.mouser.com/api/v2/search/partnumber` mit
      `652-1543-650-149` (Bourns-Taster `S2`): HTTP 200, 1 Treffer,
      **EUR-Preisstaffel**, Lagerbestand, deutsche Beschreibung,
      `mouser.de`-Produktlink. Der Schluessel haengt korrekt am deutschen Shop.
- [x] `.devcontainer/Dockerfile`: `libreoffice-calc`, `libreoffice-core` und
      `fonts-liberation` ergaenzt (vor dem `USER`-Wechsel).
- [x] `.devcontainer/Dockerfile`: `openpyxl` und `pandas` ins IDF-venv
      aufgenommen — ueber den `current`-Symlink, damit ein IDF-Versionswechsel
      es nicht bricht.
- [x] Paketnamen vorab gegen den Ubuntu-noble-Index geprueft (alle drei
      HTTP 200). Lehre aus SHBS-13, wo `kicad-templates` im PPA nicht
      existierte und den Build gebrochen haette.
- [x] **Bediener: Container neu bauen.**
- [x] Danach verifiziert: `soffice --version` → LibreOffice 24.2.7.2, und
      `python3 -c "import openpyxl, pandas"` → openpyxl 3.1.5, pandas 3.0.6.
      Mouser-API-Funktionstest erneut bestätigt: HTTP 200, 1 Treffer,
      deutsche Beschreibung, `mouser.de`-Produktlink.

## Groessenabschaetzung

Direkte Downloadgroesse der drei Pakete zusammen rund **51 MB**
(`libreoffice-core` 41 MB, `libreoffice-calc` 8,4 MB, `fonts-liberation`
1,5 MB). Die Abhaengigkeiten kommen obendrauf; ohne `apt` im Container laesst
sich der Baum hier nicht aufloesen, eine belastbare Gesamtzahl gibt es daher
erst nach dem Build. Bewusst **nicht** installiert wurde das Metapaket
`libreoffice` (zieht Writer, Impress und Java nach).

## Done-Bedingung

Nach dem Rebuild laufen `soffice --version` und der `openpyxl`-Import, und
die Mouser-API liefert mit dem hinterlegten Schluessel Treffer.

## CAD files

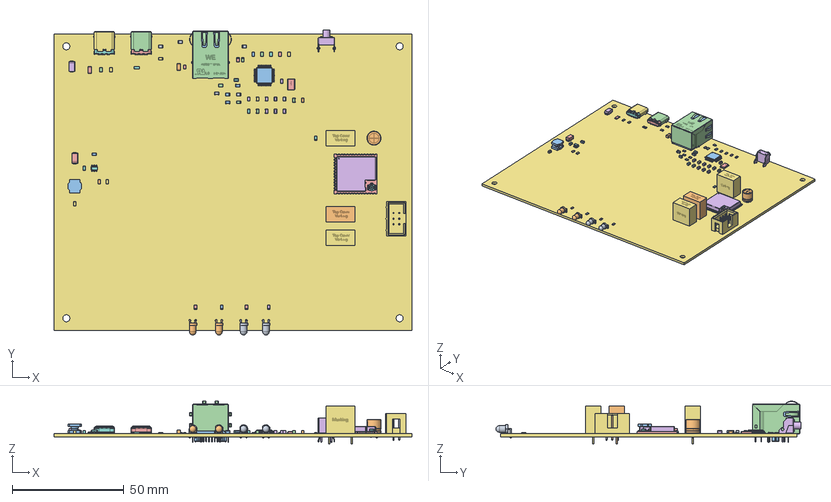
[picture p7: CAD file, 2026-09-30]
enclosure/basisstation_enclosure.FCStd
160.0 x 136.4 x 19.1 mm
C_0805_2012Metric
C_0805_2012Metric002
C_0805_2012Metric004
USB_C_Receptacle_Amphenol_12401610E4-2A
USB_C_Receptacle_Amphenol_12401610E4-2A001
USB_C_Receptacle_Amphenol_12401610E4-2A002
USB_C_Receptacle_Amphenol_12401610E4-2A003
USB_C_Receptacle_Amphenol_12401610E4-2A004
USB_C_Receptacle_Amphenol_12401610E4-2A005
USB_C_Receptacle_Amphenol_12401610E4-2A006
USB_C_Receptacle_Amphenol_12401610E4-2A007
USB_C_Receptacle_Amphenol_12401610E4-2A008
USB_C_Receptacle_Amphenol_12401610E4-2A009
USB_C_Receptacle_Amphenol_12401610E4-2A010
USB_C_Receptacle_Amphenol_12401610E4-2A011
USB_C_Receptacle_Amphenol_12401610E4-2A012
USB_C_Receptacle_Amphenol_12401610E4-2A013
USB_C_Receptacle_Amphenol_12401610E4-2A014
USB_C_Receptacle_Amphenol_12401610E4-2A015
USB_C_Receptacle_Amphenol_12401610E4-2A016
USB_C_Receptacle_Amphenol_12401610E4-2A017
USB_C_Receptacle_Amphenol_12401610E4-2A018
USB_C_Receptacle_Amphenol_12401610E4-2A019
USB_C_Receptacle_Amphenol_12401610E4-2A020
USB_C_Receptacle_Amphenol_12401610E4-2A021
USB_C_Receptacle_Amphenol_12401610E4-2A022
USB_C_Receptacle_Amphenol_12401610E4-2A023
USB_C_Receptacle_Amphenol_12401610E4-2A024
USB_C_Receptacle_Amphenol_12401610E4-2A025
USB_C_Receptacle_Amphenol_12401610E4-2A026
USB_C_Receptacle_Amphenol_12401610E4-2A027
USB_C_Receptacle_Amphenol_12401610E4-2A028
USB_C_Receptacle_Amphenol_12401610E4-2A029
USB_C_Receptacle_Amphenol_12401610E4-2A030
USB_C_Receptacle_Amphenol_12401610E4-2A031
USB_C_Receptacle_Amphenol_12401610E4-2A032
USB_C_Receptacle_Amphenol_12401610E4-2A033
USB_C_Receptacle_Amphenol_12401610E4-2A034
USB_C_Receptacle_Amphenol_12401610E4-2A035
USB_C_Receptacle_Amphenol_12401610E4-2A036
USB_C_Receptacle_Amphenol_12401610E4-2A037
USB_C_Receptacle_Amphenol_12401610E4-2A038
C_0805_2012Metric006
R_0805_2012Metric
Fuse_1206_3216Metric
R_0805_2012Metric002
R_0805_2012Metric004
R_0805_2012Metric006
LED_D3.0mm_Horizontal_O1.27mm_Z2.0mm
R_0805_2012Metric008
T_Wurth_WE-RJ45LAN_7499011121A
T_Wurth_WE-RJ45LAN_7499011121A001
R_0805_2012Metric010
C_0805_2012Metric008
Diodes_UDFN-10_1.0x2.5mm_P0.5mm
R_0805_2012Metric012
C_0805_2012Metric010
R_0805_2012Metric014
C_0805_2012Metric012
R_0805_2012Metric016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

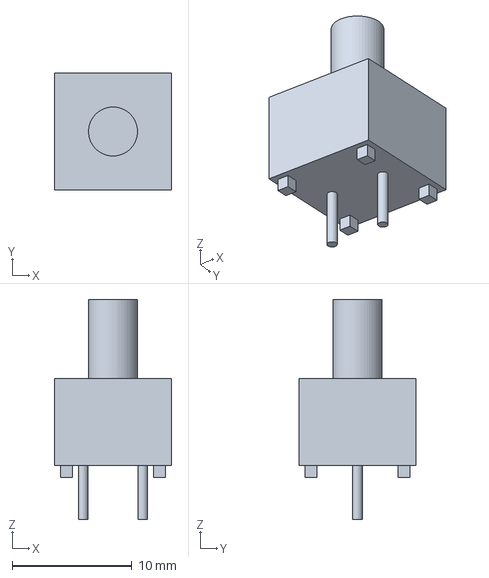
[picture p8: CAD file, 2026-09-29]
pcb/Bauteile/1543-650-149/1543-650-149.step
9.80 x 9.80 x 18.4 mm

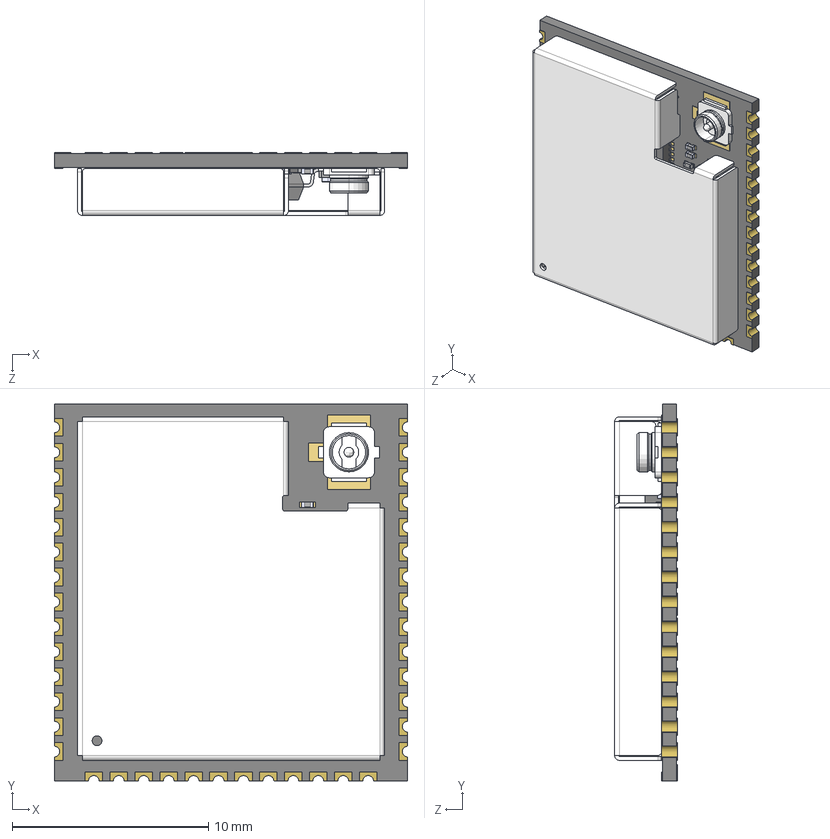
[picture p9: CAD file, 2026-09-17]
pcb/Bauteile/ESP32-S3-WROOM-1U-N16R8/ESP32-S3-WROOM-1U.STEP
18.0 x 19.2 x 3.20 mm
R0201_20210301.STEP^R0201_20210301.STEP_Submodel-R0201_part_DesignRootModel_ESP32-S3-WROOM-1U(2)_ESP32-S3-WROOM-1U_2 x 8
L0201_20210301.STEP^L0201_20210301.STEP_Submodel-L0201_part_DesignRootModel_ESP32-S3-WROOM-1U(2)_ESP32-S3-WROOM-1U_2 x 2
C0201_20210301.STEP^C0201_20210301.STEP_Submodel-C0201_part_DesignRootModel_ESP32-S3-WROOM-1U(2)_ESP32-S3-WROOM-1U_2 x 13
C0402_20210301.STEP^C0402_20210301.STEP_Submodel-C0402_part_DesignRootModel_ESP32-S3-WROOM-1U(2)_ESP32-S3-WROOM-1U_2
I-IPEX.STEP^I-IPEX.STEP_Submodel-IPEX_3P_part_DesignRootModel_ESP32-S3-WROOM-1U(2)_ESP32-S3-WROOM-1U_2
DFN1006.STEP^DFN1006.STEP_Submodel-SOD882_part_DesignRootModel_ESP32-S3-WROOM-1U(2)_ESP32-S3-WROOM-1U_2
SOP8_rev1_20210308.STEP^SOP8_rev1_20210308.STEP_Submodel-SOP8_1P27_6P6_part_DesignRootModel_ESP32-S3-WROOM-1U(2)_ESP32-S3-WROOM-1U_2
ESP32-S3_20210301.STEP^ESP32-S3_20210301.STEP_Submodel-QFN56_0P4_7_part_DesignRootModel_ESP32-S3-WROOM-1U(2)_ESP32-S3-WROOM-1U_2
XTAL3225_20210301.STEP^XTAL3225_20210301.STEP_Submodel-XTAL3225_part_DesignRootModel_ESP32-S3-WROOM-1U(2)_ESP32-S3-WROOM-1U_2
uid__4-111^DesignRootModel_ESP32-S3-WROOM-1U(2)_ESP32-S3-WROOM-1U_2
uid__4-112^DesignRootModel_ESP32-S3-WROOM-1U(2)_ESP32-S3-WROOM-1U_2
uid__4-113^DesignRootModel_ESP32-S3-WROOM-1U(2)_ESP32-S3-WROOM-1U_2
uid__4-130^DesignRootModel_ESP32-S3-WROOM-1U(2)_ESP32-S3-WROOM-1U_2
uid__4-131^DesignRootModel_ESP32-S3-WROOM-1U(2)_ESP32-S3-WROOM-1U_2
uid__4-132^DesignRootModel_ESP32-S3-WROOM-1U(2)_ESP32-S3-WROOM-1U_2
uid__4-148^DesignRootModel_ESP32-S3-WROOM-1U(2)_ESP32-S3-WROOM-1U_2
uid__4-149^DesignRootModel_ESP32-S3-WROOM-1U(2)_ESP32-S3-WROOM-1U_2
uid__4-150^DesignRootModel_ESP32-S3-WROOM-1U(2)_ESP32-S3-WROOM-1U_2
uid__1-253^DesignRootModel_ESP32-S3-WROOM-1U(2)_ESP32-S3-WROOM-1U_2
uid__1-254^DesignRootModel_ESP32-S3-WROOM-1U(2)_ESP32-S3-WROOM-1U_2
uid__1-256^DesignRootModel_ESP32-S3-WROOM-1U(2)_ESP32-S3-WROOM-1U_2
uid__1-257^DesignRootModel_ESP32-S3-WROOM-1U(2)_ESP32-S3-WROOM-1U_2
uid__1-266^DesignRootModel_ESP32-S3-WROOM-1U(2)_ESP32-S3-WROOM-1U_2
uid__1-269^DesignRootModel_ESP32-S3-WROOM-1U(2)_ESP32-S3-WROOM-1U_2
uid__1-270^DesignRootModel_ESP32-S3-WROOM-1U(2)_ESP32-S3-WROOM-1U_2
uid__1-271^DesignRootModel_ESP32-S3-WROOM-1U(2)_ESP32-S3-WROOM-1U_2
uid__1-272^DesignRootModel_ESP32-S3-WROOM-1U(2)_ESP32-S3-WROOM-1U_2
uid__1-273^DesignRootModel_ESP32-S3-WROOM-1U(2)_ESP32-S3-WROOM-1U_2
uid__1-274^DesignRootModel_ESP32-S3-WROOM-1U(2)_ESP32-S3-WROOM-1U_2
uid__1-275^DesignRootModel_ESP32-S3-WROOM-1U(2)_ESP32-S3-WROOM-1U_2
uid__1-276^DesignRootModel_ESP32-S3-WROOM-1U(2)_ESP32-S3-WROOM-1U_2
uid__1-277^DesignRootModel_ESP32-S3-WROOM-1U(2)_ESP32-S3-WROOM-1U_2
uid__1-280^DesignRootModel_ESP32-S3-WROOM-1U(2)_ESP32-S3-WROOM-1U_2
uid__1-292^DesignRootModel_ESP32-S3-WROOM-1U(2)_ESP32-S3-WROOM-1U_2
uid__1-293^DesignRootModel_ESP32-S3-WROOM-1U(2)_ESP32-S3-WROOM-1U_2
uid__1-297^DesignRootModel_ESP32-S3-WROOM-1U(2)_ESP32-S3-WROOM-1U_2
uid__1-300^DesignRootModel_ESP32-S3-WROOM-1U(2)_ESP32-S3-WROOM-1U_2
uid__1-301^DesignRootModel_ESP32-S3-WROOM-1U(2)_ESP32-S3-WROOM-1U_2
uid__1-302^DesignRootModel_ESP32-S3-WROOM-1U(2)_ESP32-S3-WROOM-1U_2
uid__1-303^DesignRootModel_ESP32-S3-WROOM-1U(2)_ESP32-S3-WROOM-1U_2
uid__1-307^DesignRootModel_ESP32-S3-WROOM-1U(2)_ESP32-S3-WROOM-1U_2
uid__1-313^DesignRootModel_ESP32-S3-WROOM-1U(2)_ESP32-S3-WROOM-1U_2
uid__1-319^DesignRootModel_ESP32-S3-WROOM-1U(2)_ESP32-S3-WROOM-1U_2
uid__1-320^DesignRootModel_ESP32-S3-WROOM-1U(2)_ESP32-S3-WROOM-1U_2
uid__1-321^DesignRootModel_ESP32-S3-WROOM-1U(2)_ESP32-S3-WROOM-1U_2
uid__1-328^DesignRootModel_ESP32-S3-WROOM-1U(2)_ESP32-S3-WROOM-1U_2
uid__1-332^DesignRootModel_ESP32-S3-WROOM-1U(2)_ESP32-S3-WROOM-1U_2
uid__1-333^DesignRootModel_ESP32-S3-WROOM-1U(2)_ESP32-S3-WROOM-1U_2
uid__1-334^DesignRootModel_ESP32-S3-WROOM-1U(2)_ESP32-S3-WROOM-1U_2
uid__1-335^DesignRootModel_ESP32-S3-WROOM-1U(2)_ESP32-S3-WROOM-1U_2
uid__1-336^DesignRootModel_ESP32-S3-WROOM-1U(2)_ESP32-S3-WROOM-1U_2
uid__1-337^DesignRootModel_ESP32-S3-WROOM-1U(2)_ESP32-S3-WROOM-1U_2
uid__1-338^DesignRootModel_ESP32-S3-WROOM-1U(2)_ESP32-S3-WROOM-1U_2
uid__1-339^DesignRootModel_ESP32-S3-WROOM-1U(2)_ESP32-S3-WROOM-1U_2
uid__1-340^DesignRootModel_ESP32-S3-WROOM-1U(2)_ESP32-S3-WROOM-1U_2
uid__1-341^DesignRootModel_ESP32-S3-WROOM-1U(2)_ESP32-S3-WROOM-1U_2
uid__1-342^DesignRootModel_ESP32-S3-WROOM-1U(2)_ESP32-S3-WROOM-1U_2
uid__1-343^DesignRootModel_ESP32-S3-WROOM-1U(2)_ESP32-S3-WROOM-1U_2
uid__1-344^DesignRootModel_ESP32-S3-WROOM-1U(2)_ESP32-S3-WROOM-1U_2
uid__1-345^DesignRootModel_ESP32-S3-WROOM-1U(2)_ESP32-S3-WROOM-1U_2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

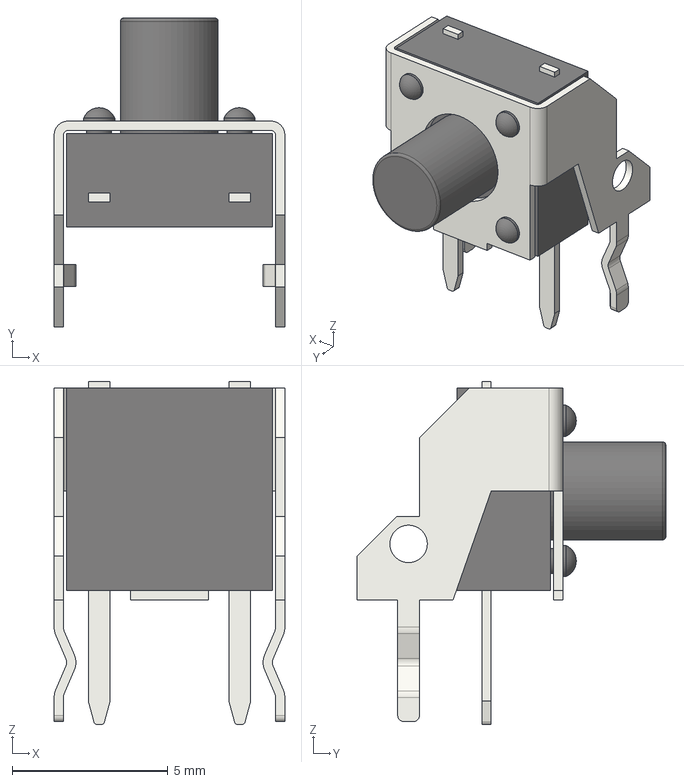
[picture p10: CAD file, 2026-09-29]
pcb/Bauteile/PTS645VL58-2LFS/SW_Tactile_SPST_Angled_PTS645Vx58-2LFS.step
7.40 x 9.90 x 11.0 mm

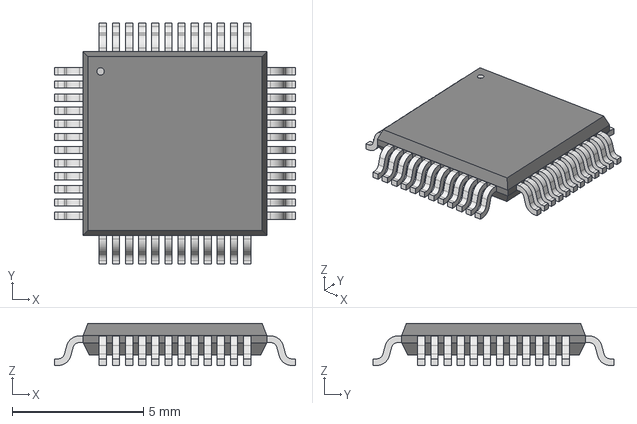
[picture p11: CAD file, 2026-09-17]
pcb/Bauteile/W5500/48LQFP_W5500_WIZ.step
9.19 x 9.19 x 1.60 mm

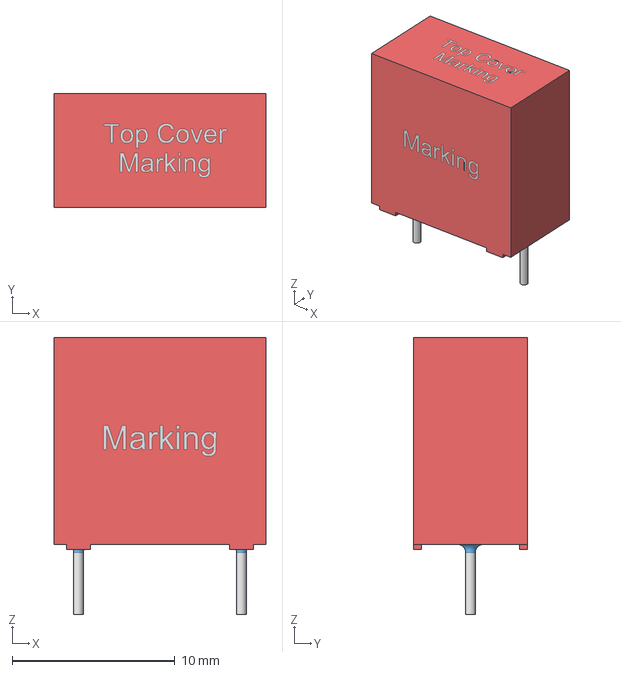
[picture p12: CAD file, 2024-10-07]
pcb/Bauteile/WCAP-FTXX_P10/WCAP-FTXX_P10.step
13.0 x 7.00 x 17.0 mm

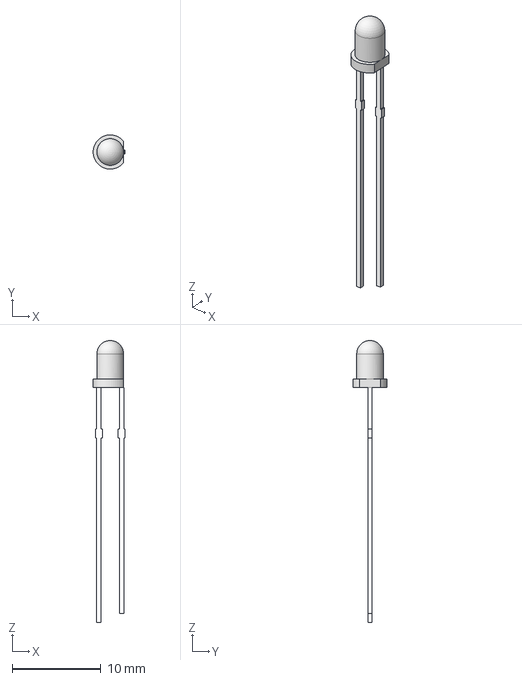
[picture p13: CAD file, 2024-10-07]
pcb/Bauteile/WL-TMRC_3MM/WL-TMRC_3MM.step
3.57 x 3.85 x 31.7 mm

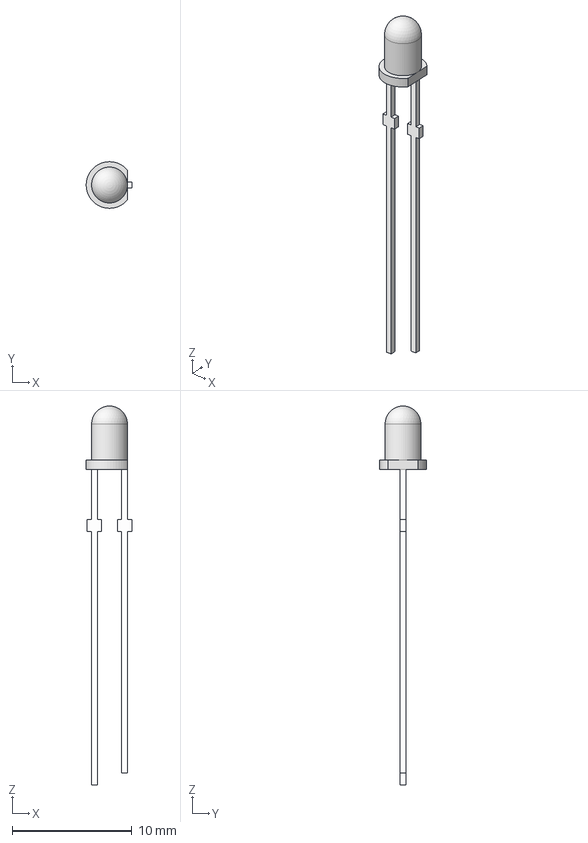
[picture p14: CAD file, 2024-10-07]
pcb/Bauteile/WL-TMRW_3MM/WL-TMRW_3MM.step
3.82 x 3.90 x 31.7 mm

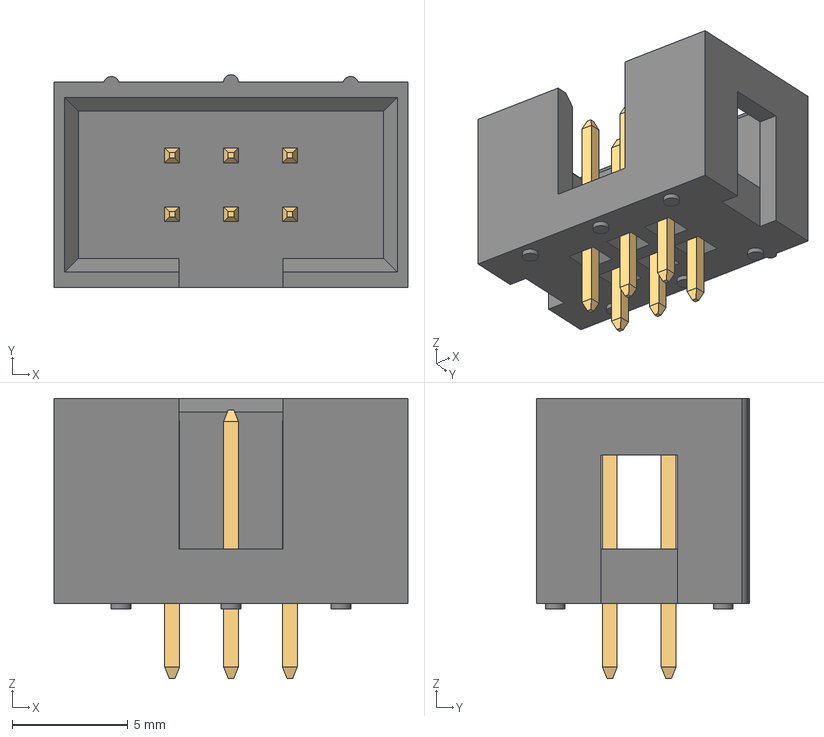
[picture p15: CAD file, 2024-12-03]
pcb/Bauteile/wuerth_6120XX21621/6120XX21621_61200621621.step
15.3 x 9.18 x 12.1 mm
6120xx21621_PIN x 6

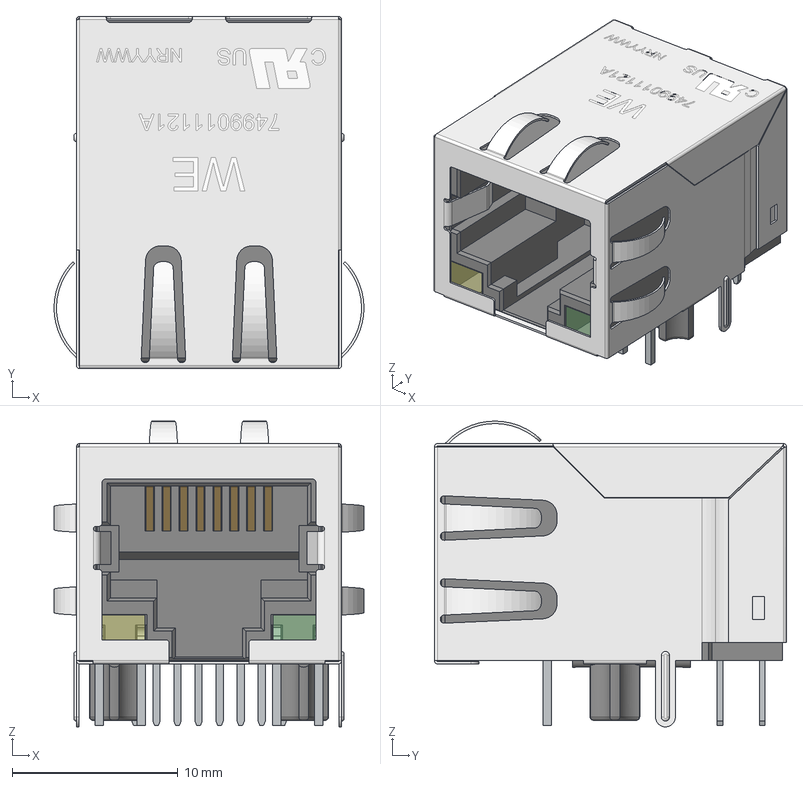
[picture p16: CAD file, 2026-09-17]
pcb/Bauteile/wuerth_7499011121A/WE-RJ45_7499011121A.step
18.7 x 21.2 x 18.5 mm

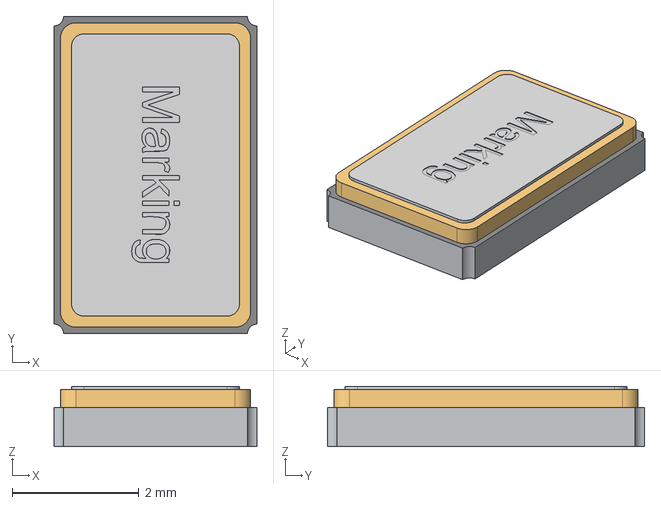
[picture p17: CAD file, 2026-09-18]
pcb/Bauteile/wuerth_830059532/Y_Wurth_WE-XTAL_Quartz-CFPX-104.step
3.20 x 5.00 x 0.95 mm

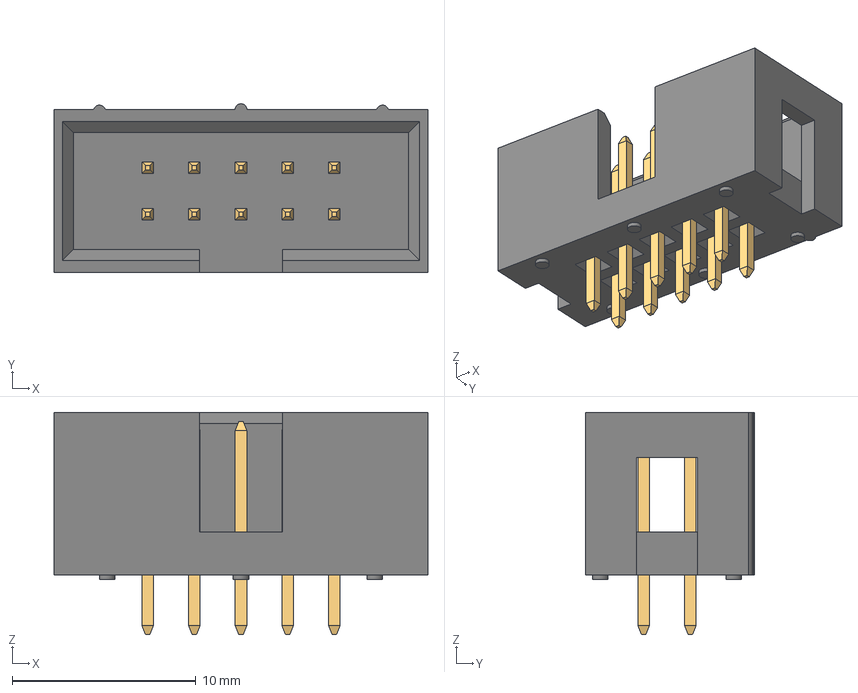
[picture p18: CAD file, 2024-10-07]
pcb/Bauteile/wuerth_6120XX21621/6120XX21621_61201021621.step
20.4 x 9.18 x 12.1 mm
6120xx21621_PIN x 10

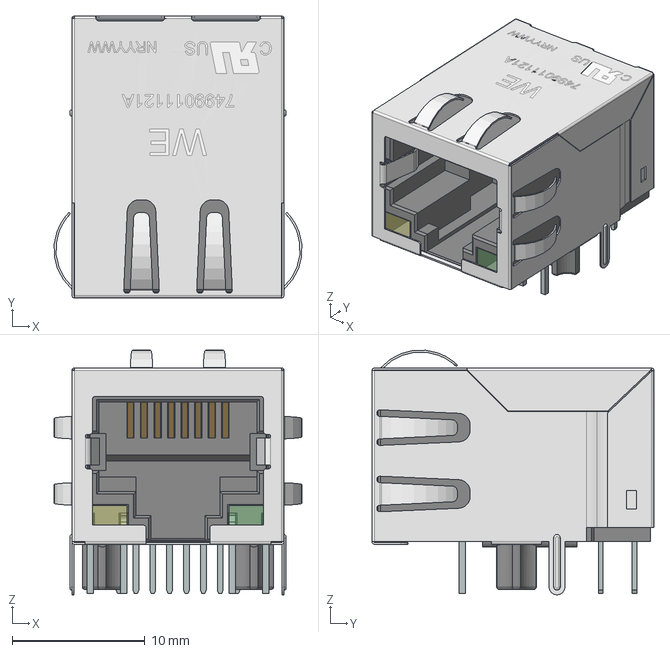
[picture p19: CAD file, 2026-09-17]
pcb/Bauteile/wuerth_7499011121A/T_Wurth_WE-RJ45LAN_7499011121A.step
18.7 x 21.2 x 18.4 mm

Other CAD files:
enclosure/reference/basisstation_pcb.step

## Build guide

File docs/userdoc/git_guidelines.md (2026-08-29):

---
status: active
last_updated: 2026-06-02
type: userdoc
---

# Git-Richtlinien — SmartHomeSystemBasisStation

Projektspezifische Git-Vorgaben für Entwickler und KI-Agenten. Ergänzt die globalen Regeln in `CLAUDE.md` §6 und die unternehmensweiten Vorgaben (intern ggf. als PDF bei Zott-IT/TGE).

## Commit-Nachrichten

- **Format:** Conventional Commits, Beschreibung auf **Deutsch**.
- **Versionspräfix:** Wert aus Root-Datei `version` (Format `X.XX.XXX`, z. B. `0.00.001`) als Tag-Präfix `v0.00.001`.
- **JIRA-Scope:** Jedes Commit referenziert genau ein Ticket: `v0.00.001 <type>(SHBS-123): Beschreibung`.

**Typen:** `feat`, `fix`, `docs`, `test`, `chore`, …

**Beispiele:**

```text
v0.00.001 docs(SHBS-1): README als Onboarding-Dokument neu gefasst
v0.00.001 test(SHBS-1): Unity-Testgrundgerüst unter tests/ angelegt
v0.00.001 fix(SHBS-42): WLAN-Reconnect bei Timeout behoben
```

- **Atomar:** Ein Task / ein Problem = ein Commit.
- **WIP:** Erlaubt, in der Nachricht mit `(WIP)` markieren.

## Tagging und Versionsnummer

Jeder Stand, der **herausgegeben** wird (interne Tests, Release-Kandidaten, Produktions-Firmware), muss mit der **Versionsnummer** als Git-Tag gekennzeichnet werden.

| Tag | Bedeutung |
|-----|---|
| `v0.00.001` | Normale Versions-Freigabe (entspricht `version` / Firmware-Version) |
| `v0.00.005-kundexyz` | Kundenspezifische Test- oder Lieferversion |
| `release` | In jedem Projekt üblicher Marker für den aktuellen Release-Stand (siehe README) |

**Regeln:**

- Die **aktuellste Version** in Entwicklungs- bzw. Produktivumgebung soll als Tag im Repository nachvollziehbar sein — Hinweis dazu in der [README](../../README.md).
- **Alle veröffentlichten Versionen** müssen mit einem Versions-Tag versehen werden.
- Applikationsspezifische Zusatz-Tags (z. B. `release_pe`, `release_ta` bei Cloud-Komponenten) sind in der README zu dokumentieren, sofern sie für dieses Projekt genutzt werden. Für die reine Firmware-Basisstation gelten primär Versions-Tags (`vX.XX.XXX`) und ggf. `release`.

**Synchronisation Firmware (dieses Projekt):**

Bei Versionserhöhung zusätzlich pflegen: `version`, `CMakeLists.txt` (`PROJECT_VER`), `sdkconfig` (`CONFIG_APP_PROJECT_VER`) — nur nach Bediener-Freigabe bei ESP32-Quellcode-Änderung.

## Branching-Strategie

### Historisch: `develop` und `master`

Früher wurde ein `develop`-Branch (häufige, möglichst tägliche Commits) und ein `master`-Branch (veröffentlichte Versionen) gepflegt. Das ist für einfache Projekte tragfähig, stößt bei paralleler Pflege mehrerer Versionsstände (z. B. v1.3 und v1.4) an Grenzen.

### Aktuell: `main` und Release-Zweige

| Branch | Zweck |
|---|---|
| `main` | **Arbeitszweig** — laufende Entwicklung; veröffentlichte Versionen werden hier per **Tag** markiert |
| `release/x.y` | Pflege einer **bereits veröffentlichten** Minor-Version (Bugfixes, Sicherheitsupdates), während `main` weiterentwickelt wird |
| `fix/<name>` | Bugfixes, die mehrere Branches betreffen |
| `feature/<name>` | Größere, ausgekoppelte Funktionalitäten |

**Release-Zweige im Detail:**

- Spätestens kurz bevor eine Änderungsmitteilung geschlossen wird, wird für eine veröffentlichte Version ein Branch `release/x.y` angelegt (z. B. `release/0.0` für Versionslinie `0.0.x`).
- In `release/x.y` erfolgen **nur** Bugfixes und Pflege; in `main` die Weiterentwicklung.
- Eine **neue Release-Version** (neue Minor/Major-Linie) wird **immer aus `main`** erzeugt und getaggt.

## Fixes (`fix/`)

Fehler, die in mehreren `release/`-Branches behoben werden müssen, werden in einem **`fix/`-Branch** entwickelt.

1. **Startpunkt:** in der Regel `main`; in Ausnahmefällen der betroffene `release/`-Branch.
2. **Benennung:** aussagekräftig, z. B. `fix/nat-bug` oder `fix/SHBS-42` (JIRA-ID).
3. **Implementierung:** Fix im `fix/`-Branch fertigstellen.
4. **Merge:** Fix in `main` und ggf. alle betroffenen `release/`-Branches mergen.
5. **Branch behalten:** `fix/`-Branch zur Nachvollziehbarkeit **nicht löschen**.

**Einfache Fixes:** können als einzelner Commit direkt auf `main` landen und per **Cherry-Pick** auf weitere Branches übertragen werden. Das ist weniger nachvollziehbar als ein Merge, überschreibt den Code aber nicht vollständig. **Pflicht:** im Cherry-Pick-Commit vermerken:

```text
Cherry Pick <commit-hash>
```

## Features (`feature/`)

Analog zu komplexen Bugfixes für **neue Funktionalität**:

1. Entwicklung in `feature/<name>` (z. B. `feature/ethernet-driver`).
2. **Parallelarbeit:** jederzeit Merge von `main` in den `feature/`-Branch, um Konflikte früh zu erkennen.
3. **Abschluss:** fertiges Feature in `main` mergen; den `feature/`-Branch danach nicht weiterverwenden (Branch darf archiviert bleiben).

## Cherry-Picks

Übertragung eines Commits auf andere Branches ohne vollständigen Merge:

- Im Commit-Text **zwingend:** `Cherry Pick <commit-hash>`
- Typisch für kleine Fixes auf mehrere `release/`-Branches

## Projektspezifische Abweichungen

| Thema | Regel |
|---|---|
| **Firmware-Version** | Inkrement nur bei ESP32-Quellcode + Bediener-Freigabe |
| **Release Notes** | Nur bei Versionserhöhung: [releases.md](releases.md) |
| **Push** | Nur durch Bediener — Agent committet lokal nach Freigabe |
| **Agent-Commits** | Siehe `CLAUDE.md` §9 und Pro-Prompt-Workflow |

## Pull / Review

- Änderungen vor Merge reviewen (Bediener).
- Kein Force-Push auf `main`.

## Referenzen

- [CLAUDE.md](../../CLAUDE.md) — globale und projektspezifische Agenten-Regeln
- [releases.md](releases.md) — Changelog
- [README.md](../../README.md) — aktuelle Release-/Versions-Tags

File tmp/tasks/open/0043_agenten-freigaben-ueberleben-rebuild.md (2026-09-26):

---
title: Werkzeug-Freigaben und Agenten-Zustand ueberleben einen Container-Rebuild
created: 2026-09-23
jira: -
priority: medium
type: bugfix
---

## Kontext

Nach dem Container-Rebuild vom 2026-09-22 (ausgeloest durch die `--env-file`-
Umstellung in `.devcontainer/devcontainer.json`) fragt der Agent wieder bei
jedem einzelnen Bash-Befehl nach Bestaetigung.

Ursache: Die pro Projekt erteilten Freigaben ("nicht mehr fragen") stehen in
`~/.claude.json` unter dem Schluessel `projects`. Dieser Schluessel fehlt in der
Datei inzwischen vollstaendig. `/home/esp` liegt ohne Volume im
Container-Dateisystem (`mount | grep home` ist leer) und wurde beim Rebuild neu
aus dem Image erzeugt. Mit verloren gingen Login-Token und alle
Sitzungsprotokolle bis auf zwei.

Verschaerfend: `.claude/settings.json` fuehrt in der Allowlist nur die vier
Atlassian-MCP-Werkzeuge, kein einziges Bash-Muster. `.claude/settings.local.json`
existiert nicht. Es gab also gar keine versionierte Freigabe, die den Rebuild
haette ueberstehen koennen.

## Ziel

Zwei voneinander unabhaengige Absicherungen:

1. Die projektueblichen Bash-Befehle sind in `.claude/settings.json`
   freigegeben — versioniert, im Workspace-Mount, damit rebuild-fest und fuer
   alle Beteiligten identisch.
2. Der Agenten-Zustand unter `~/.claude` (Login, Protokolle) liegt in einem
   Named Volume und ueberlebt kuenftige Rebuilds.

## Schritte

- [x] `.claude/settings.json`: Allowlist um lesende Shell-Befehle, lesende
      Git-Befehle, `idf.py build/size/fullclean/reconfigure`, `kicad-cli`,
      `soffice --headless` und `python3` erweitern.
      **Bewusst ausgenommen:** `git commit`, `git push`, `idf.py flash`, `rm` —
      CLAUDE.md §9 verlangt dafuer eine ausdrueckliche Freigabe des Bedieners.
      *Der Agent kann diese Datei nicht selbst schreiben (Selbstmodifikations-
      Schutz des Auto-Modus). Der Bediener fuegt den Inhalt ein oder erteilt
      die Freigaben ueber `/permissions`.* — vom Bediener eingefuegt.
- [x] `.devcontainer/devcontainer.json`: Named Volume `shbs-claude-state` auf
      `/home/esp/.claude` gemountet.
- [x] `.devcontainer/Dockerfile`: `~/.claude` bereits im Image anlegen, damit
      Docker das leere Volume mit korrektem Eigentuemer (`esp`) befuellt statt
      als `root:root`.
- [x] Doku: Abschnitt "Entwicklungsumgebung (Dev Container)" in
      [architecture.md](../../../docs/project/architecture.md) ergaenzt —
      was persistiert wird, was bewusst nicht, und warum die Freigaben in
      `.claude/settings.json` gehoeren.
- [ ] Rebuild durch den Bediener, danach Gegenprobe: Volume vorhanden,
      `~/.claude` dem User `esp` gehoerend, Freigaben greifen.
- [x] Commits erstellt — der Bediener hat ausdruecklich "kein Ticket"
      freigegeben (Ausnahme nach CLAUDE.md Pro-Prompt-Workflow Schritt 4).

## Fortschritt

- 2026-09-23: Ursache eingegrenzt und belegt (fehlender `projects`-Schluessel,
  kein Home-Volume, leere Bash-Allowlist). Container-Konfiguration und Doku
  angepasst. Die Aenderung an `.claude/settings.json` blieb offen, weil der
  Auto-Modus dem Agenten das Schreiben der eigenen Rechtekonfiguration
  verweigert — der Vorschlag liegt dem Bediener vor.

## Commits

- fef1ec5 Workflow-Hook auf Bash umgestellt (Vorarbeit, eigener Commit)
- 21ddec7 secrets/.env per --env-file laden (Vorarbeit, eigener Commit)
- c7388a7 Werkzeug-Freigaben und Agenten-Zustand rebuild-fest gemacht

## Offene Fragen

- Ohne JIRA-Ticket abgewickelt, nach ausdruecklicher Freigabe des Bedieners.
- `~/.claude.json` (Login-Konto, Projektzustand) wird weiterhin nicht
  persistiert. Ein Symlink ins Volume waere riskant, weil die Anwendung die
  Datei atomar per Rename schreibt und den Symlink dabei ersetzen wuerde; die
  Binary warnt ausserdem selbst vor dem Ueberschreiben dieser Datei
  (GH #3117). Solange die Freigaben versioniert im Workspace liegen, bleibt
  als Rest nur ein einmaliges Neu-Login nach einem Rebuild.
- 2026-09-23 (2): Allowlist vom Bediener eingefuegt. Drei atomare Commits
  erstellt (Hook-Umstellung, --env-file, Volume + Freigaben). Der Task bleibt
  offen, bis der Rebuild gelaufen und die Gegenprobe erfolgt ist.

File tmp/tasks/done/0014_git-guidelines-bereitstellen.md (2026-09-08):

---
status: done
priority: low
type: docs
created: 2026-06-02
phase: C
jira: SHBS-1
---

# `git_guidelines.pdf` bereitstellen oder Referenz anpassen

## Ziel

Git-Richtlinie verfügbar machen oder Referenz anpassen — Inhalt in `docs/userdoc/git_guidelines.md`.

## Done-Kriterien

- [x] Kein broken Link/Verweis auf nicht existierende `git_guidelines.pdf`.
- [x] Git-Workflow für das Projekt ist für Entwickler auffindbar.
- [x] Unternehmensvorgaben Tagging, Branching, Fix/Feature-Branches ergänzt (2026-06-02).
- [x] Bediener-Freigabe / Review der erweiterten Richtlinie.

## Ergebnis

- `docs/userdoc/git_guidelines.md` — erweitert um Tagging, Versionsnummer, Branching-Strategie, Fixes, Features, Cherry-Picks
- `README.md` — Abschnitt **Release & Tags**
- `AGENTS.md` — Verlinkung auf `git_guidelines.md`
- `docs/project/struktur-anpassung-agents.md` — Phase-C-Checkliste aktualisiert

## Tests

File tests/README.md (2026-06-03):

# Unit tests (ESP-IDF / Unity)

Smoke tests for the SmartHomeSystemBasisStation firmware project.

## Framework

[Unity](https://github.com/ThrowTheSwitch/Unity) via ESP-IDF component `unity`.

## Run (target ESP32-S3)

From the project root, with ESP-IDF environment active (e.g. Dev Container):

```text
idf.py set-target esp32s3
idf.py -T tests build
idf.py -T tests flash monitor
```

`-T tests` builds the `tests/` component as the application (instead of `main/`).

Expected output: all `[smoke]` tests pass via `unity_run_all_tests()`.

## Layout

| File | Purpose |
|---|---|
| `CMakeLists.txt` | ESP-IDF test component registration |
| `test_smoke.c` | Unity test cases and `app_main` |
| `test_helpers.c/h` | Small testable helper (version patch validation) |

## Notes

- Production firmware: `idf.py build` (uses `main/` as usual).
- Tests are self-contained in `tests/` — no link to `main/` (avoids duplicate `app_main`).

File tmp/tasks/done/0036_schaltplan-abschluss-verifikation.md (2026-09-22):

---
status: done
priority: high
type: test
created: 2026-09-22
jira: SHBS-14
---

# Abschluss-Verifikation Schaltplan

## Kontext

Letzter Task zu SHBS-14. Belegt, dass der Schaltplan als Referenzstand fuer
das PCB-Layout taugt — und dass die Aufraeumarbeiten der Tasks 0030-0035
**elektrisch nichts verschoben** haben.

Das ist der eigentliche Zweck der Uebung: Ab hier wird die Netzliste ins
Board uebernommen, und jede unbemerkte Abweichung waere dann teuer.

## Referenzwerte (Stand 2026-09-22, vor den Aenderungen)

| Groesse | Wert |
| --- | ---- |
| ERC-Fehler | 0 |
| ERC-Warnungen | 7 (Ziel danach: 0) |
| Netze | 102 |
| Bauteile auf dem Board | 76 |
| Bauteile ohne Footprint | 0 (ausser `ANT1`/`ANT2`, "Excluded from board") |
| Ein-Pin-Netze | 40, alle `unconnected-*` |

## Schritte

- [ ] `kicad-cli sch erc` — **0 Fehler, 0 Warnungen**.
- [ ] **Gegenprobe in der GUI:** Auch dort 0 Verstoesse. Am 2026-09-22 zeigte
      die GUI bereits 0, waehrend das CLI noch eine Warnung meldete (siehe
      [Task 0037](0037_epad-netzname-u6.md)). Ein gruenes Ergebnis aus nur
      einem der beiden Werkzeuge genuegt als Nachweis nicht.
- [ ] `kicad-cli sch export netlist` — 102 Netze, Namen und Knoten
      identisch zum Referenzstand.
- [ ] `kicad-cli sch export bom` — 76 Bauteile, Footprint-Spalte identisch,
      `R35` weiterhin DNP.
- [ ] Ein-Pin-Netze erneut zaehlen: 40, alle mit `unconnected-`-Praefix.
      Taucht ein regulaer benanntes Netz mit nur einem Pin auf, ist beim
      Aufraeumen eine Verbindung verloren gegangen.
- [ ] `ERC.rpt` und `BasisStation.net` im Repo aktualisieren.
- [ ] `docs/project/hardware.md` und `docs/project/ethernet.md`
      gegenlesen.

## Done-Bedingung

ERC sauber auf Null, Netzliste und Stueckliste nachweislich unveraendert,
Artefakte eingecheckt.

## Abschluss

- 2026-09-22: **Erledigt.** Endstand gegen die Referenzwerte:

| Groesse | Ziel | Ist |
| --- | ---- | --- |
| ERC-Fehler | 0 | **0** |
| ERC-Warnungen | 0 | **0** |
| Verstoesse gesamt (inkl. ausgeschlossener) | — | **1** (`pin_to_pin`, bewusst) |
| Netze | 102 | **102** |
| Konnektivitaet | unveraendert | **bitweise identisch** |
| Stueckliste | unveraendert | **identisch** (78 Zeilen) |
| Bauteile ohne Footprint | 0 | **0** (ausser `ANT1`/`ANT2`) |

- Der Schaltplan taugt damit als Referenzstand fuer das PCB-Layout.

## Offen fuer den Bediener

- `pcb/BasisStation/BasisStation.net` und `ERC.rpt` stammen aus der
  Windows-GUI (`source`-Pfad `C:\Projekte\…`, deutschsprachig). Sie wurden
  **bewusst nicht** im Container neu erzeugt, weil sonst Pfad und Sprache bei
  jedem Export hin- und herspringen. Inhaltlich ist nur die `pinfunction` von
  `U6.41` veraltet (`EPAD` statt `GND`) — die Konnektivitaet stimmt.
  Beim Start des PCB-Layouts ohnehin neu exportieren.

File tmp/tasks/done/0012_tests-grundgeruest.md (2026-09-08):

---
status: done
priority: high
type: test
created: 2026-06-02
completed: 2026-06-02
phase: C
jira: SHBS-1
---

# `tests/` Grundgerüst + mindestens ein Smoke-Test

## Done-Kriterien

- [x] `tests/` enthält lauffähiges Grundgerüst.
- [x] Mindestens ein Test läuft erfolgreich durch. _(Struktur validiert; Lauf in Dev Container / mit ESP-IDF empfohlen)_
- [x] Ausführung ist in Doku beschrieben.

## Ergebnis

| Datei | Zweck |
|---|---|
| `tests/CMakeLists.txt` | ESP-IDF-Komponente, `REQUIRES unity` |
| `tests/test_smoke.c` | 3 Unity-Tests + `app_main` → `unity_run_all_tests()` |
| `tests/test_helpers.c/h` | Hilfsfunktion `version_patch_is_valid()` |
| `tests/README.md` | Ausführung `idf.py -T tests build flash monitor` |

Doku: Abschnitt **Testing** in [architecture.md](../../../docs/project/architecture.md).

**Hinweis:** Build nicht in dieser Shell (`IDF_PATH` nicht gesetzt) — Verifikation im Dev Container (ESP-IDF 5.3).

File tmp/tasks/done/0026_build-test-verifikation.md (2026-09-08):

---
status: done
priority: high
type: test
created: 2026-06-02
jira: SHBS-2
---

# Build und Tests verifizieren

## Done-Kriterien

- [x] `idf.py build` — **nicht ausgeführt** (`idf.py` nicht im PATH, kein Docker/Dev-Container auf diesem Host). Verifikation durch Bediener nach Push.
- [x] `idf.py -T tests build` — **nicht ausgeführt** (gleicher Grund).

## Hinweis für Bediener

```text
idf.py set-target esp32s3
idf.py build
idf.py -T tests build
```

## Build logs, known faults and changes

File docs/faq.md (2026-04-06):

# FAQ

## Wo finde ich die Projektziele und Agent-Regeln?

In `AGENTS.md` im Repository-Root.

## Wo liegt die Hardware?

KiCad-Projekt unter `PCB/BasisStation/`. Stückliste und Links: `README.md` (Abschnitt Hardware).

## Wo liegt die Firmware?

Verzeichnis `main/` — Einstieg `main.c`.

## Wo ist die Web-Konfiguration?

- Dateien unter `spiffs/` (HTML, CSS, JS).
- Laufzeit: HTTP-Server bedient SPIFFS unter `/spiffs`; Details zu URIs: `docs/firmware/communication.md`.

## Unterstützt die Firmware Ethernet?

Laut Projektkontext (`AGENTS.md`) ist Ethernet ein Ziel. In der bisher analysierten Firmware gibt es **keine** Ethernet-Implementierung in `main/`.

## Welche WLAN-Konfigurationsdatei wird genutzt?

`/spiffs/configuration.json` (Konstante `wifiConfigFile` in `WLAN.c`).

## Widerspricht die README der Ziel-Hardware?

Die README enthält noch Text vom ESP-IDF-Beispielprojekt und eine BOM mit teils gemischten Modulreferenzen. Bei Arbeit an Hardware/README: auf **ESP32-S3-WROOM-1U-N16R8** laut `AGENTS.md` abstimmen.

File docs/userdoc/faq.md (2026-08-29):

---
status: active
last_updated: 2026-06-02
type: userdoc
---

# FAQ

## Wo finde ich die Projektziele und Agent-Regeln?

In `CLAUDE.md` im Repository-Root.

## Wo liegt die Hardware?

KiCad-Projekt unter `pcb/BasisStation/`. Details: [hardware.md](../project/hardware.md). Stückliste: `README.md` (Abschnitt Hardware).

## Wo liegt die Firmware?

Verzeichnis `main/` — Einstieg `main.c`. Architektur: [architecture.md](../project/architecture.md).

## Wo ist die Web-Konfiguration?

- Dateien unter `spiffs/` (HTML, CSS, JS).
- Laufzeit: HTTP-Server bedient SPIFFS unter `/spiffs`; Details zu URIs: [communication.md](../project/communication.md).

## Unterstützt die Firmware Ethernet?

Laut Projektkontext (`CLAUDE.md`) ist Ethernet ein Ziel. In der bisher analysierten Firmware gibt es **keine** Ethernet-Implementierung in `main/`.

## Welche WLAN-Konfigurationsdatei wird genutzt?

`/spiffs/configuration.json` (Konstante `wifiConfigFile` in `WLAN.c`).

## Widerspricht die README der Ziel-Hardware?

Die README enthält noch Text vom ESP-IDF-Beispielprojekt und eine BOM mit teils gemischten Modulreferenzen. Bei Arbeit an Hardware/README: auf **ESP32-S3-WROOM-1U-N16R8** laut `CLAUDE.md` abstimmen.

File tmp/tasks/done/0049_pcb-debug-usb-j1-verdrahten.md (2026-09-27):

---
title: PCB — Debug-USB J1, ESD-Array U1, CC-Widerstände R21/R22 verdrahten
created: 2026-09-27
jira: SHBS-22
priority: high
type: feature
status: done
---

## Kontext

Der Bediener hat J1, U1, R21 und R22 platziert und verdrahtet. Das Review
(Nachtrag D1–D3 im
[Report](../../report/2026-09-24_pcb-review-stromversorgung-leds.md)) ergab:
Die Durchgänge unter U1 fehlen, der USB-Datenpfad ist unterbrochen. An J1
fehlen die Brücken zwischen den Pad-Reihen.

## Ziel

USB J1 → U1 → U6 in beiden Steckrichtungen verbunden, alle VBUS_J1-Pads
angebunden, footprint-bedingte DRC-Meldungen ausgeschlossen.

## Schritte

- [x] Durchgänge U1 10→1, 9→2, 7→4 (Agent)
- [x] Brücken J1: B6→A6, B7→A7 (über Via/B.Cu), B4→A9, B9→A4, A4-Gruppe über B.Cu (Agent)
- [x] DRC per CLI: keine offene Verbindung an J1/U1
- [x] `docs/project/hardware.md` ergänzt
- [x] `B` und DRC-Ausschlüsse (5× U1, 2× J1) — in die DRC-Schlussrunde des Gesamt-Layouts verschoben
- [x] Commit

## Fortschritt

- 2026-09-27: Ticket SHBS-22 angelegt. 21 Segmente und 3 Vias per Skript
  gesetzt (KiCad geschlossen). U1-Durchgänge USB+ und VBUS_J1 mit 0,15 mm
  wegen der breiten GND-Pads 3/8, sonst 0,2 mm. DRC: offene Verbindungen
  120 → 112, keine an J1/U1. Keine neuen Abstandsfehler außer gegen die
  veraltete Zonenfüllung. Nächster Schritt: Bediener `B` und Ausschlüsse.
- 2026-09-27: Bediener gibt das restliche Layout frei (Agent platziert und
  routet alles außer T1, J1, J_PWR1, D7–D10). Zonenfüllung und
  DRC-Ausschlüsse erfolgen dort gesammelt am Ende. Task abgeschlossen.

## Commits

- 23b1277 Debug-USB J1/U1 fertig verdrahtet

## Offene Fragen

- Keine.

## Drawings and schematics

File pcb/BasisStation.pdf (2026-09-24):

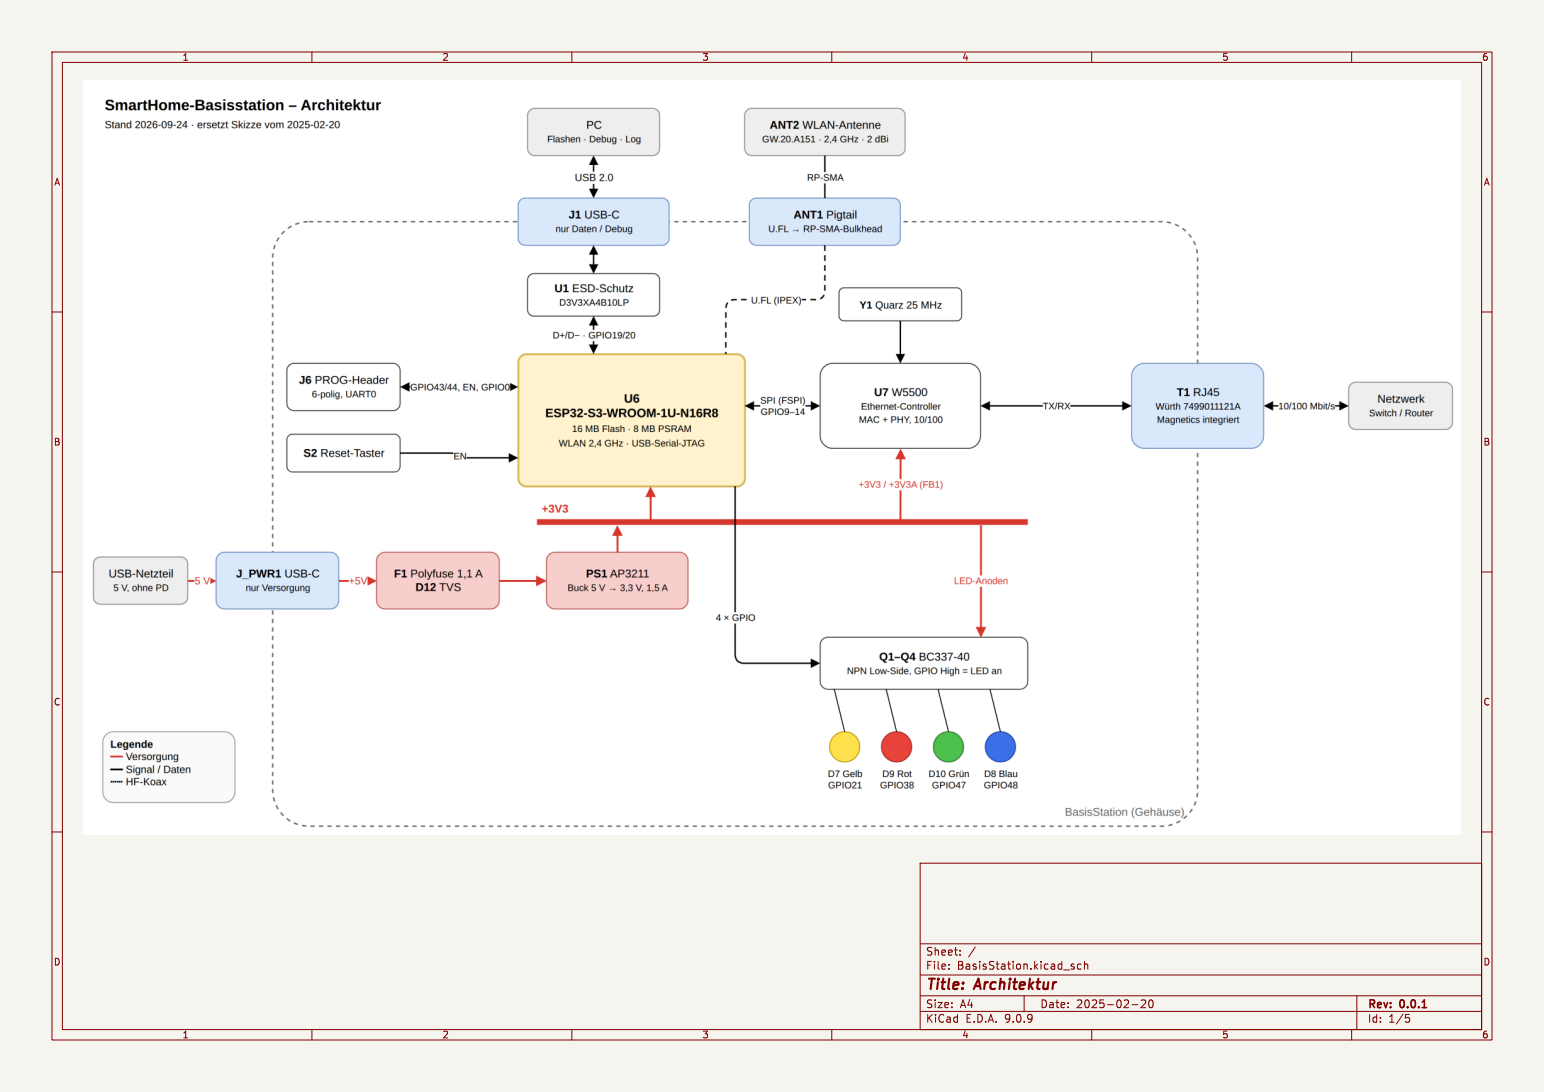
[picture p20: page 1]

Id: 1/5 Title: Architektur File: BasisStation.kicad_sch Sheet: /

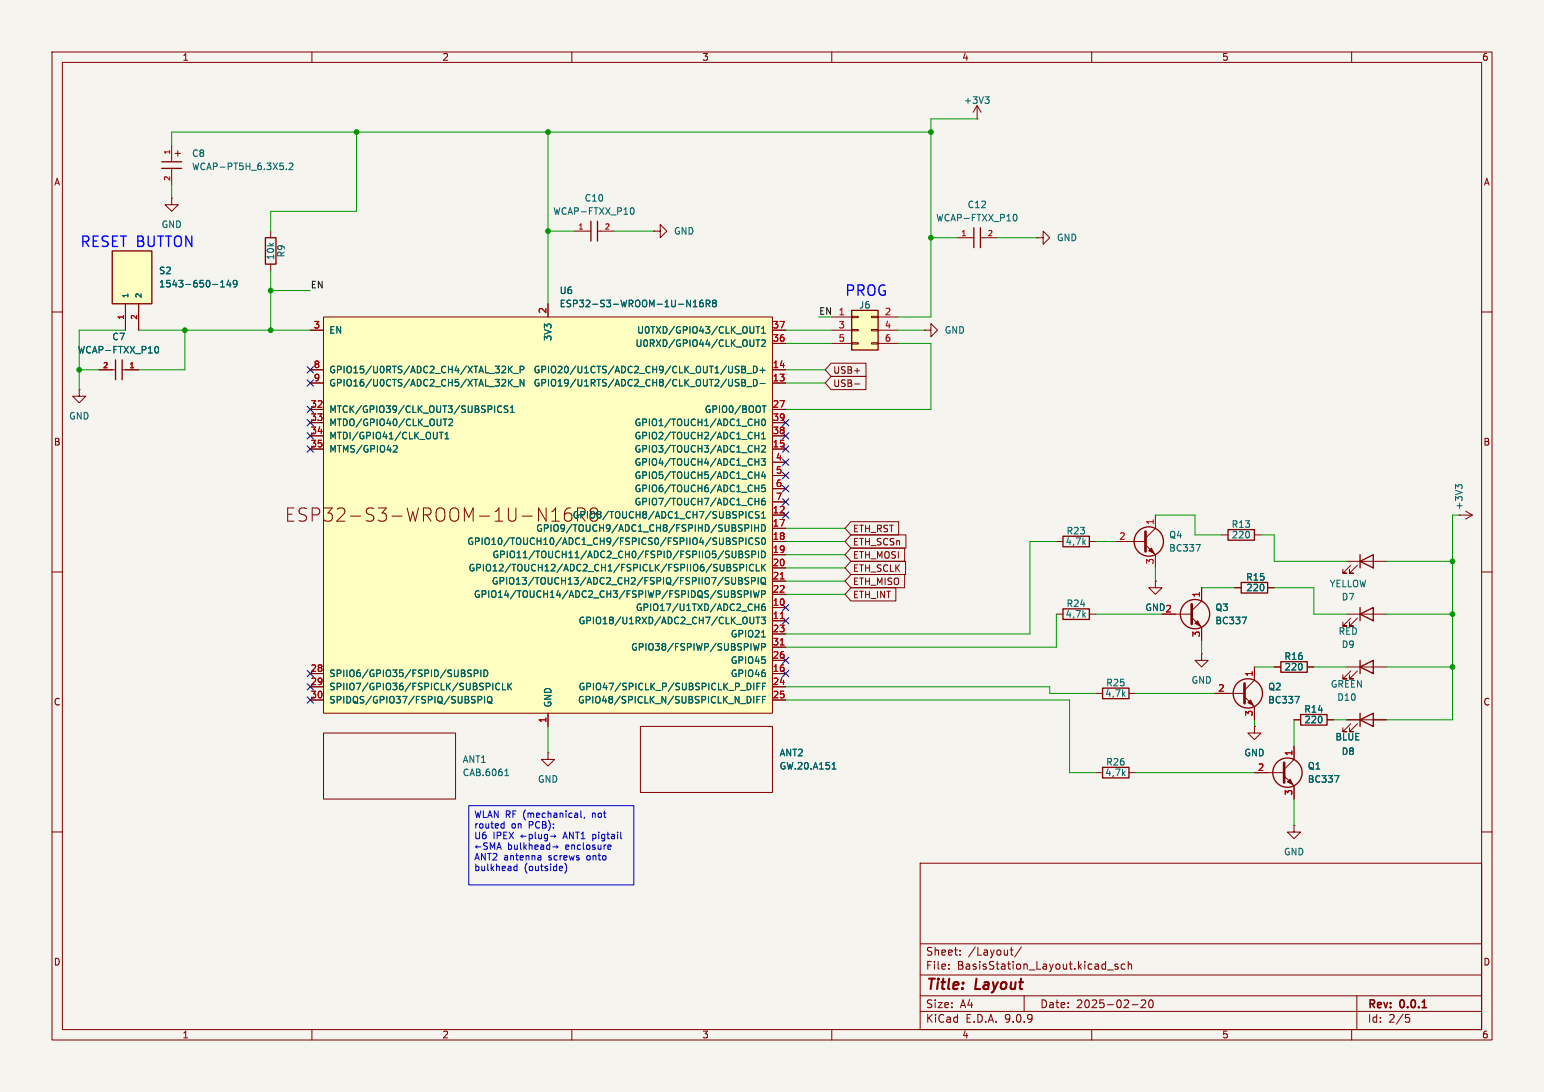
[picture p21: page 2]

1 U0TXD/GPIO43/CLK_OUT1 37 U0RXD/GPIO44/CLK_OUT2 36 GPIO20/U1CTS/ADC2_CH9/CLK_OUT1/USB_D+ 14 GPIO19/U1RTS/ADC2_CH8/CLK_OUT2/USB_D- 13 GPIO0/BOOT 27 GPIO1/TOUCH1/ADC1_CH0 39 GPIO2/TOUCH2/ADC1_CH1 38 GPIO3/TOUCH3/ADC1_CH2 15 GPIO4/TOUCH4/ADC1_CH3 4 GPIO5/TOUCH5/ADC1_CH4 5 GPIO6/TOUCH6/ADC1_CH5 6 GPIO7/TOUCH7/ADC1_CH6 7 GPIO8/TOUCH8/ADC1_CH7/SUBSPICS1 12 GPIO9/TOUCH9/ADC1_CH8/FSPIHD/SUBSPIHD 17 GPIO10/TOUCH10/ADC1_CH9/FSPICS0/FSPIIO4/SUBSPICS0 18 GPIO11/TOUCH11/ADC2_CH0/FSPID/FSPIIO5/SUBSPID 19 GPIO12/TOUCH12/ADC2_CH1/FSPICLK/FSPIIO6/SUBSPICLK 20 GPIO13/TOUCH13/ADC2_CH2/FSPIQ/FSPIIO7/SUBSPIQ 21 GPIO14/TOUCH14/ADC2_CH3/FSPIWP/FSPIDQS/SUBSPIWP 22 GPIO17/U1TXD/ADC2_CH6 10 GPIO18/U1RXD/ADC2_CH7/CLK_OUT3 11 GPIO21 23 GPIO38/FSPIWP/SUBSPIWP 31 GPIO45 26 GPIO46 16 GPIO47/SPICLK_P/SUBSPICLK_P_DIFF 24 GPIO48/SPICLK_N/SUBSPICLK_N_DIFF 25 U6ESP32-S3-WROOM-1U-N16R8 ANT2 GW.20.A151

1 U0TXD/GPIO43/CLK_OUT1 37 U0RXD/GPIO44/CLK_OUT2 36 GPIO20/U1CTS/ADC2_CH9/CLK_OUT1/USB_D+ 14 GPIO19/U1RTS/ADC2_CH8/CLK_OUT2/USB_D- 13 GPIO0/BOOT 27 GPIO1/TOUCH1/ADC1_CH0 39 GPIO2/TOUCH2/ADC1_CH1 38 GPIO3/TOUCH3/ADC1_CH2 15 GPIO4/TOUCH4/ADC1_CH3 4 GPIO5/TOUCH5/ADC1_CH4 5 GPIO6/TOUCH6/ADC1_CH5 6 GPIO7/TOUCH7/ADC1_CH6 7 GPIO8/TOUCH8/ADC1_CH7/SUBSPICS1 12 GPIO9/TOUCH9/ADC1_CH8/FSPIHD/SUBSPIHD 17 GPIO10/TOUCH10/ADC1_CH9/FSPICS0/FSPIIO4/SUBSPICS0 18 GPIO11/TOUCH11/ADC2_CH0/FSPID/FSPIIO5/SUBSPID 19 GPIO12/TOUCH12/ADC2_CH1/FSPICLK/FSPIIO6/SUBSPICLK 20 GPIO13/TOUCH13/ADC2_CH2/FSPIQ/FSPIIO7/SUBSPIQ 21 GPIO14/TOUCH14/ADC2_CH3/FSPIWP/FSPIDQS/SUBSPIWP 22 GPIO17/U1TXD/ADC2_CH6 10 GPIO18/U1RXD/ADC2_CH7/CLK_OUT3 11 GPIO21 23 GPIO38/FSPIWP/SUBSPIWP 31 GPIO45 26 GPIO46 16 GPIO47/SPICLK_P/SUBSPICLK_P_DIFF 24 GPIO48/SPICLK_N/SUBSPICLK_N_DIFF 25ANT2 GW.20.A151 D8 BLUE R16

þÿ!•SMAþÿbulkhead!’ enclosure ANT2 antenna screws onto

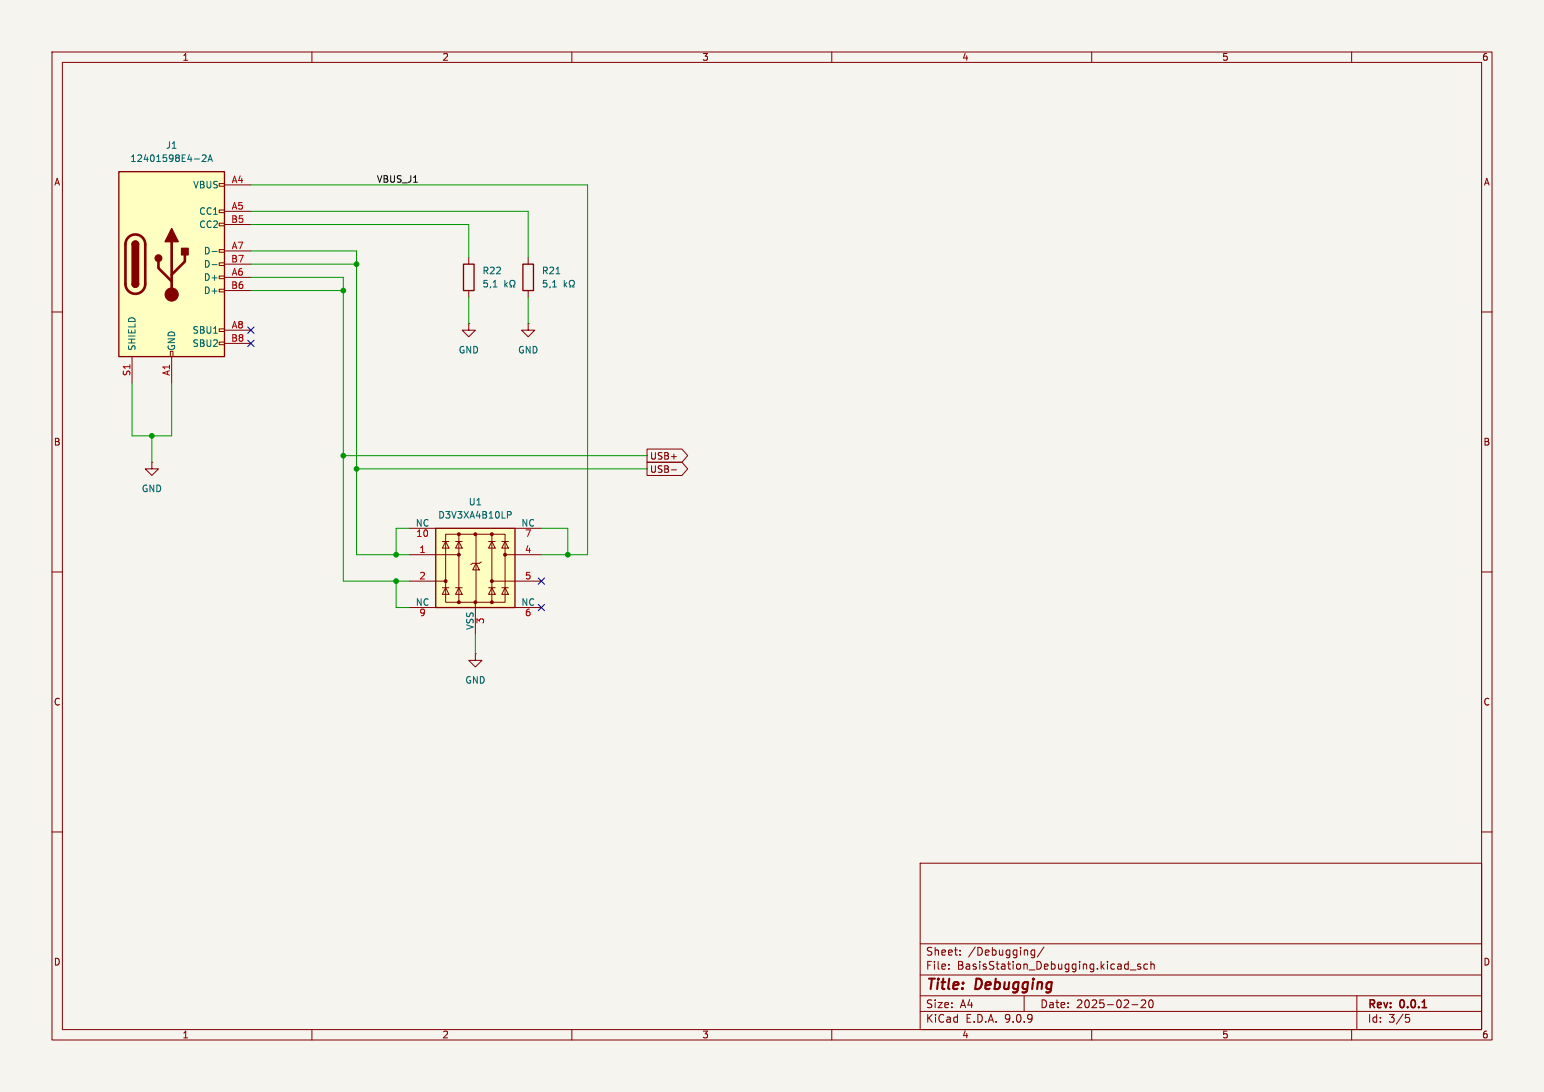
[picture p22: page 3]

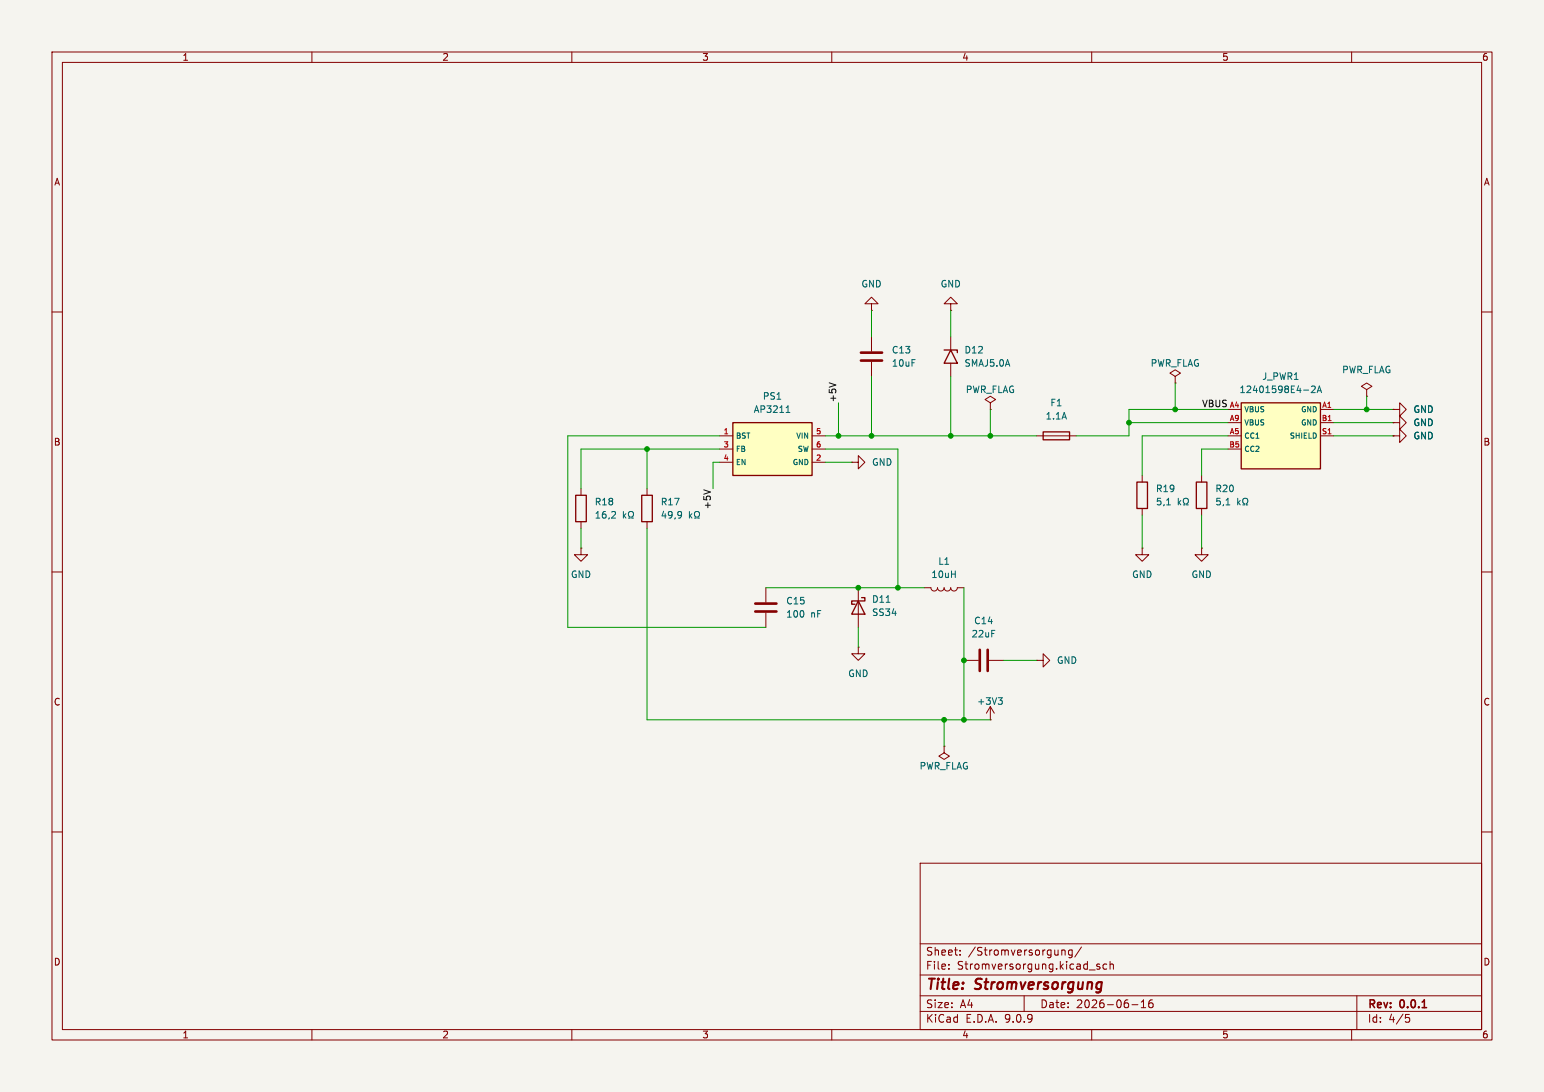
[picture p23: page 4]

File: Stromversorgung.kicad_sch Sheet: /Stromversorgung/
Id: 4/5 Title: Stromversorgung

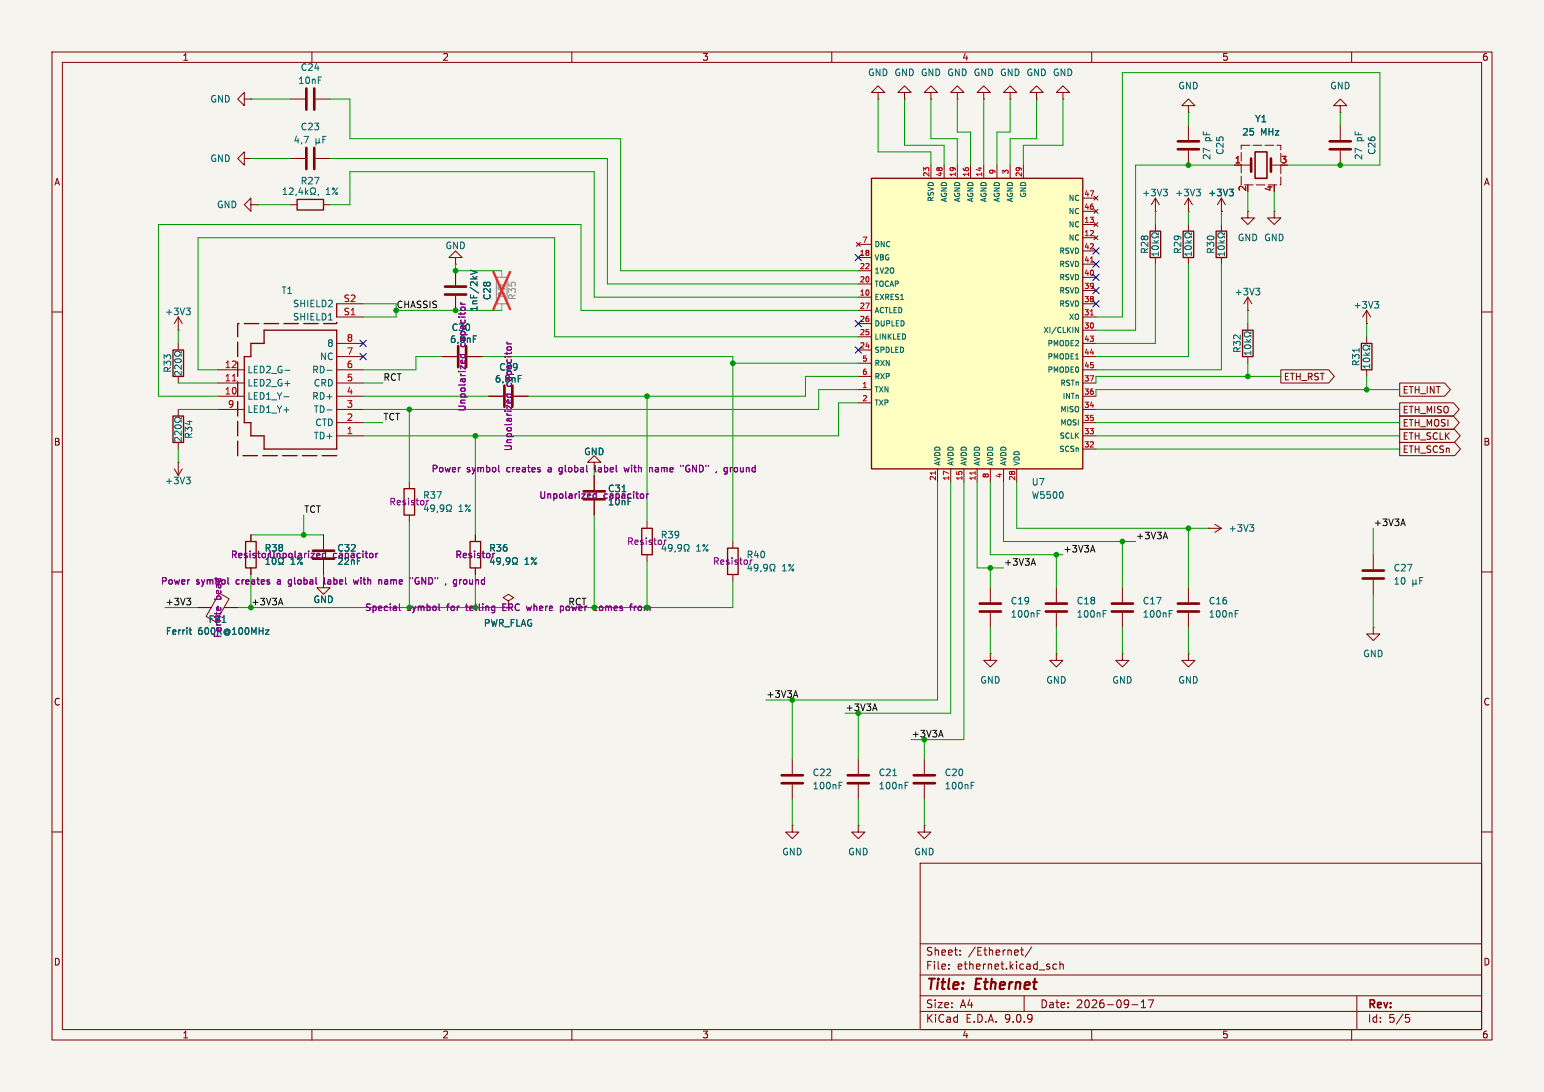
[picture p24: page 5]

8 AGND 14 AVDD 11 AGND 16 AVDD 15 AGND 19 AVDD 17 AGND 48 AVDD 21 RSVD 23 TXP 2 TXN 1 RXP 6 RXN 5 SPDLED 24

LINKLED 25 DUPLED 26 ACTLED 27 EXRES1 10 TOCAP 20

Power symbol creates a global label with name "GND" , ground C30

100nF GND R33 þÿ220©
Power symbol creates a global label with name "GND" , ground C29

SCSn 32 SCLK 33 MOSI 35 MISO 34

Power symbol creates a global label with name "GND" , ground R38

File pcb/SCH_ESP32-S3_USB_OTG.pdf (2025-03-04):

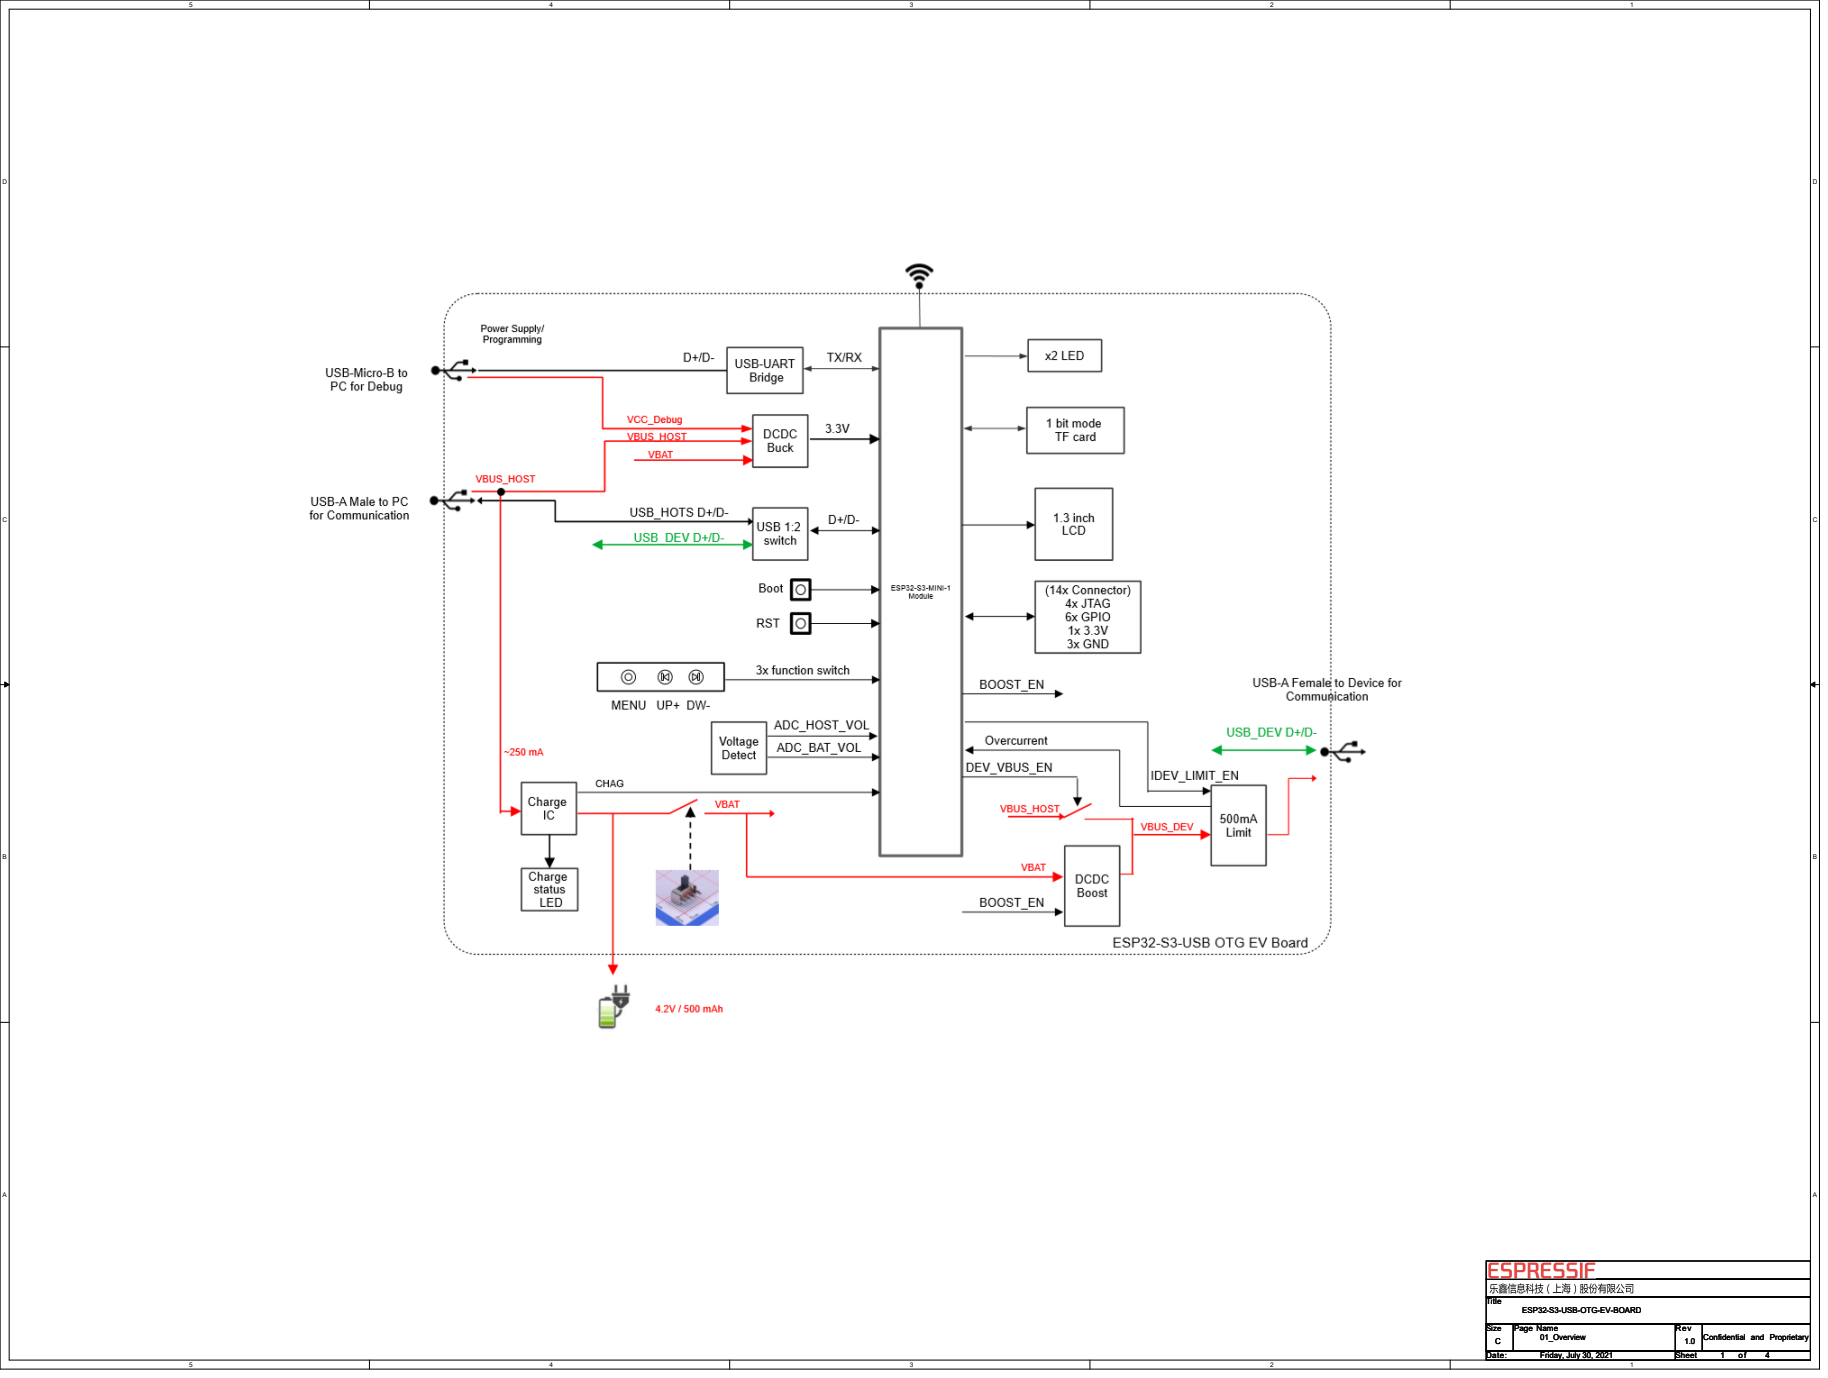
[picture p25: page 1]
Title; Size Page Name; Rev; Date:; Sheet; 01_Overview; Friday, July 30, 2021

ESP32-S3-USB-OTG-EV-BOARD

Confidential and Proprietary

# 3V3 Buck DC/DC

USB-Micro-B Debug: | USB-A-Male to PC:

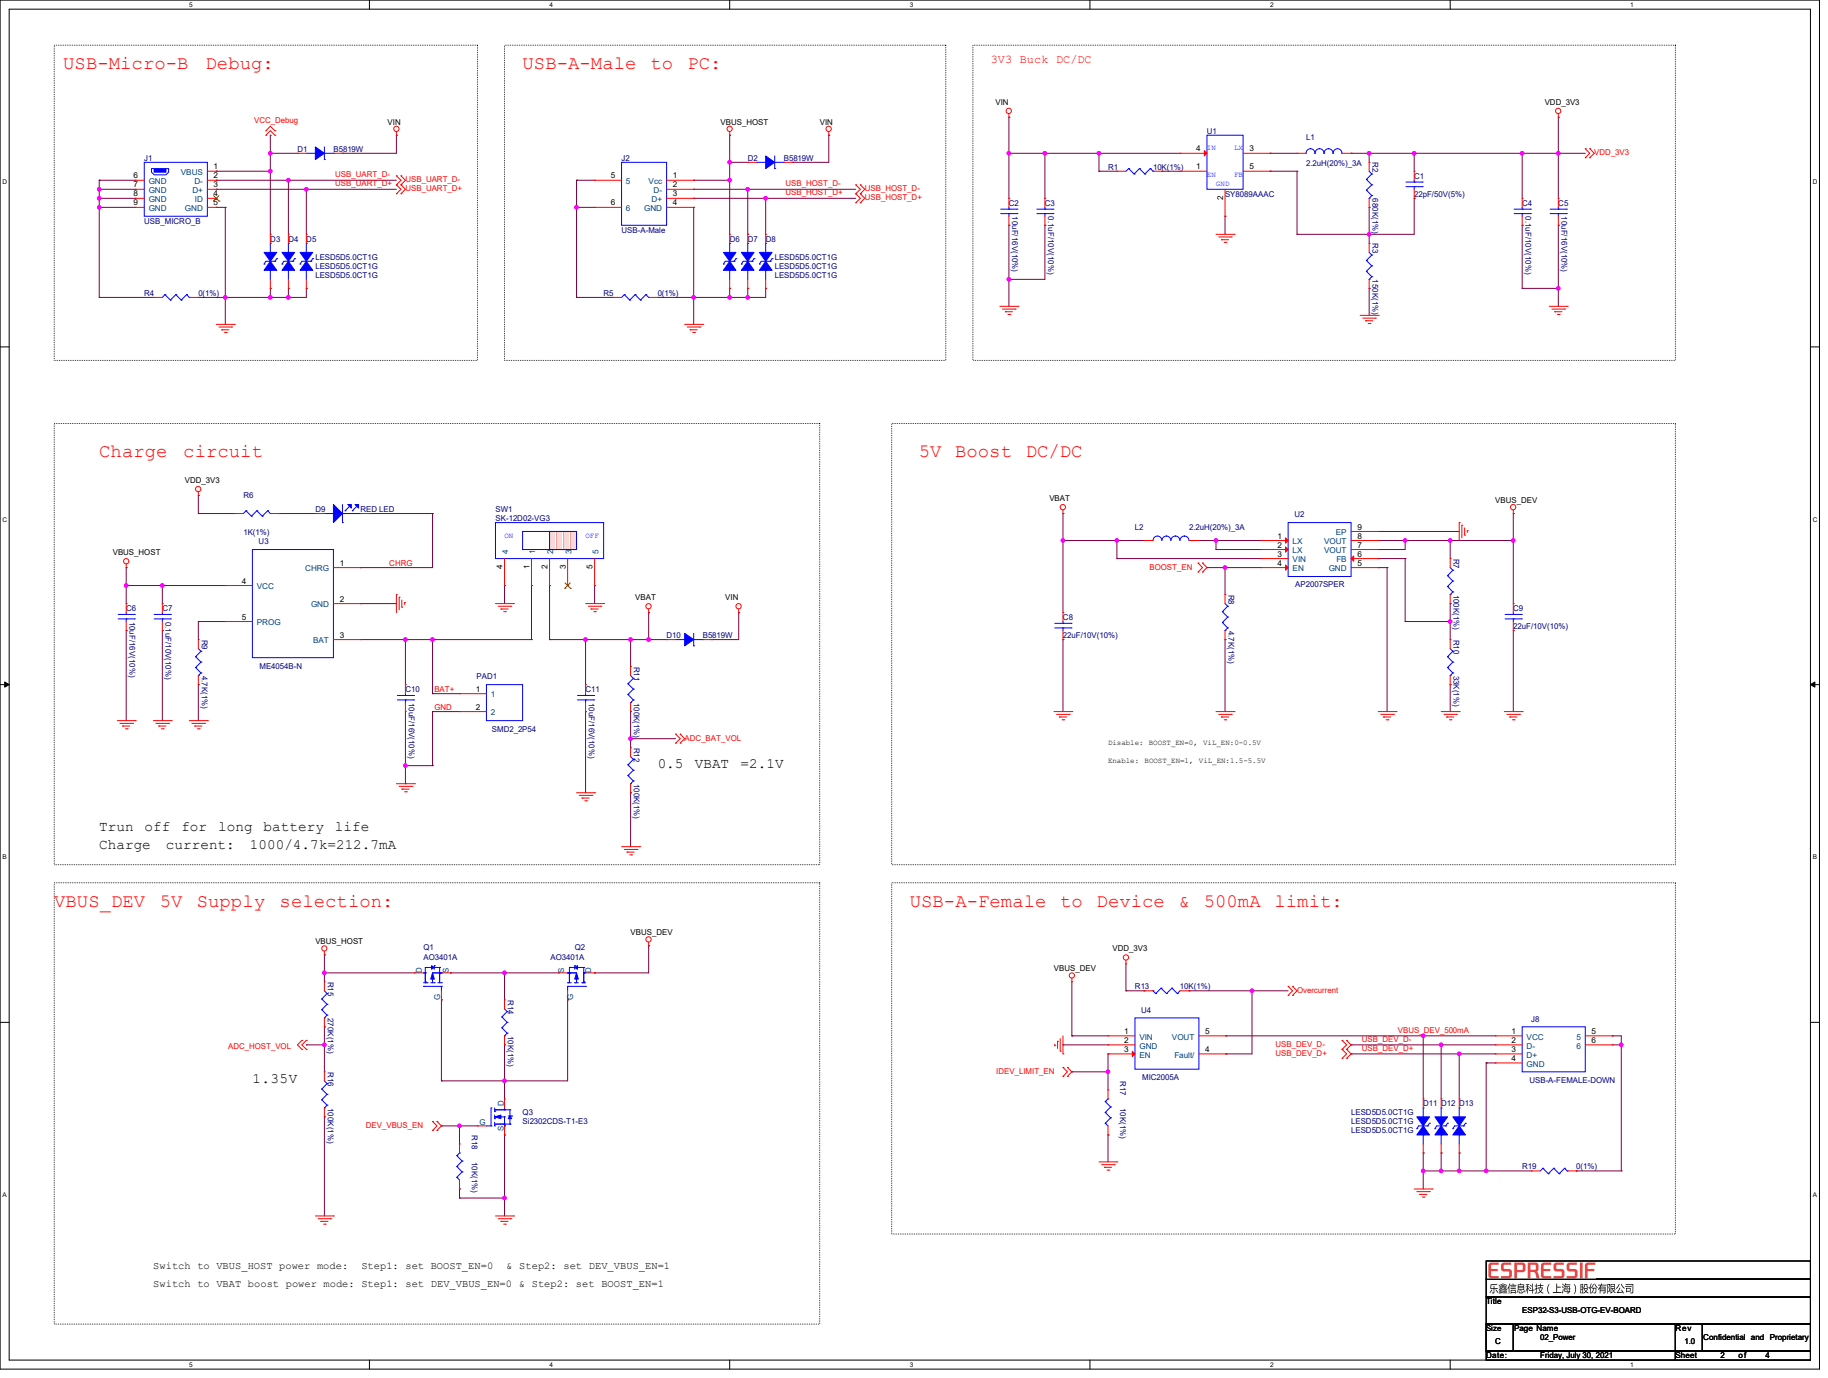
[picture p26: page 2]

Trun off for long battery life
Charge current: 1000/4.7k=212.7mA

Switch to VBUS_HOST power mode: Step1: set BOOST_EN=0 & Step2: set DEV_VBUS_EN=1
Switch to VBAT boost power mode: Step1: set DEV_VBUS_EN=0 & Step2: set BOOST_EN=1

# ESP32-S3FN8

# RF Matching

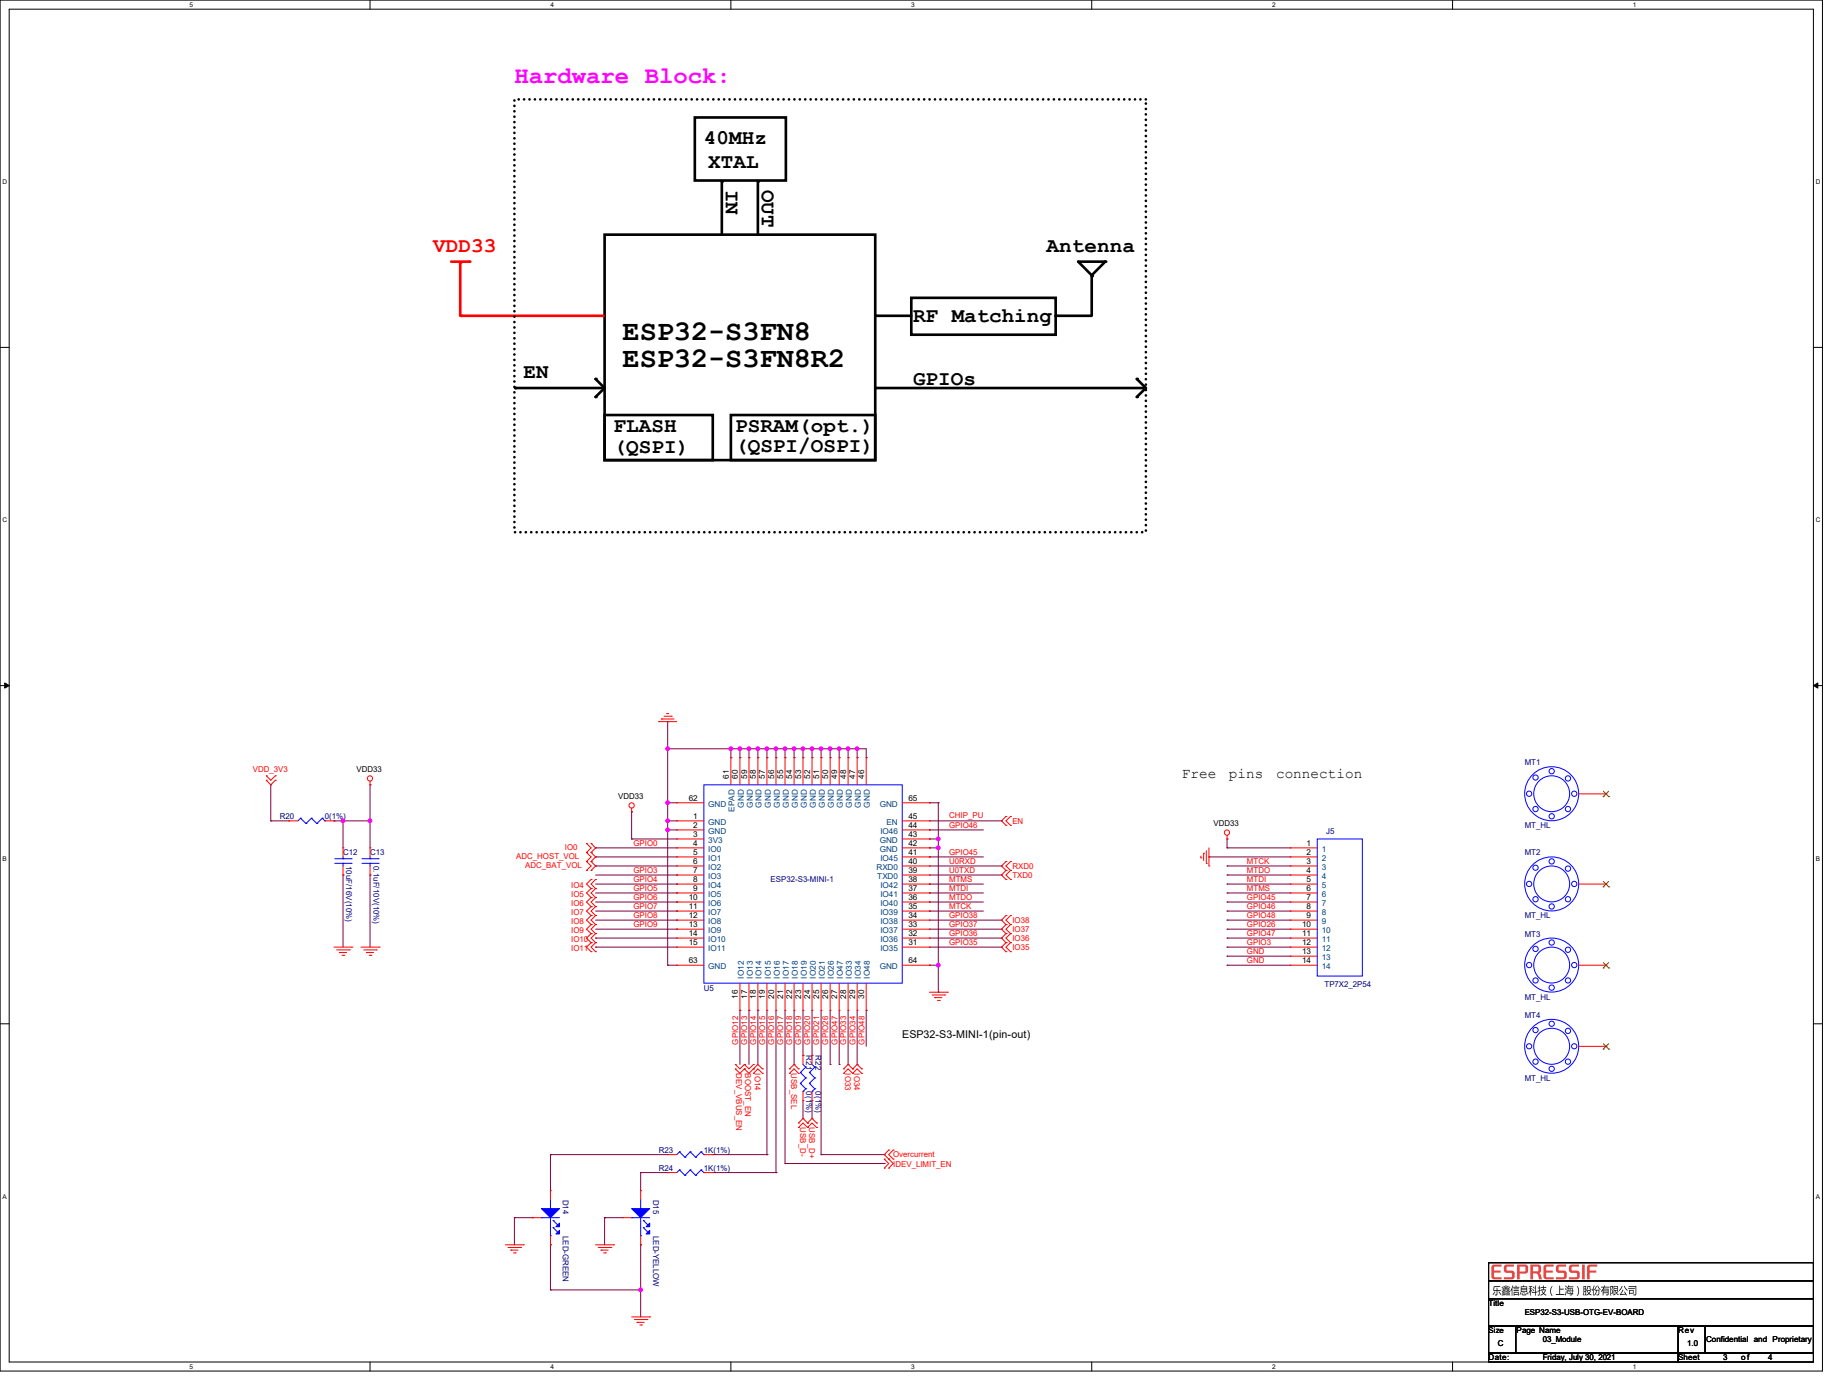
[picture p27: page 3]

# USB & USB=>UART

# USB Switch:

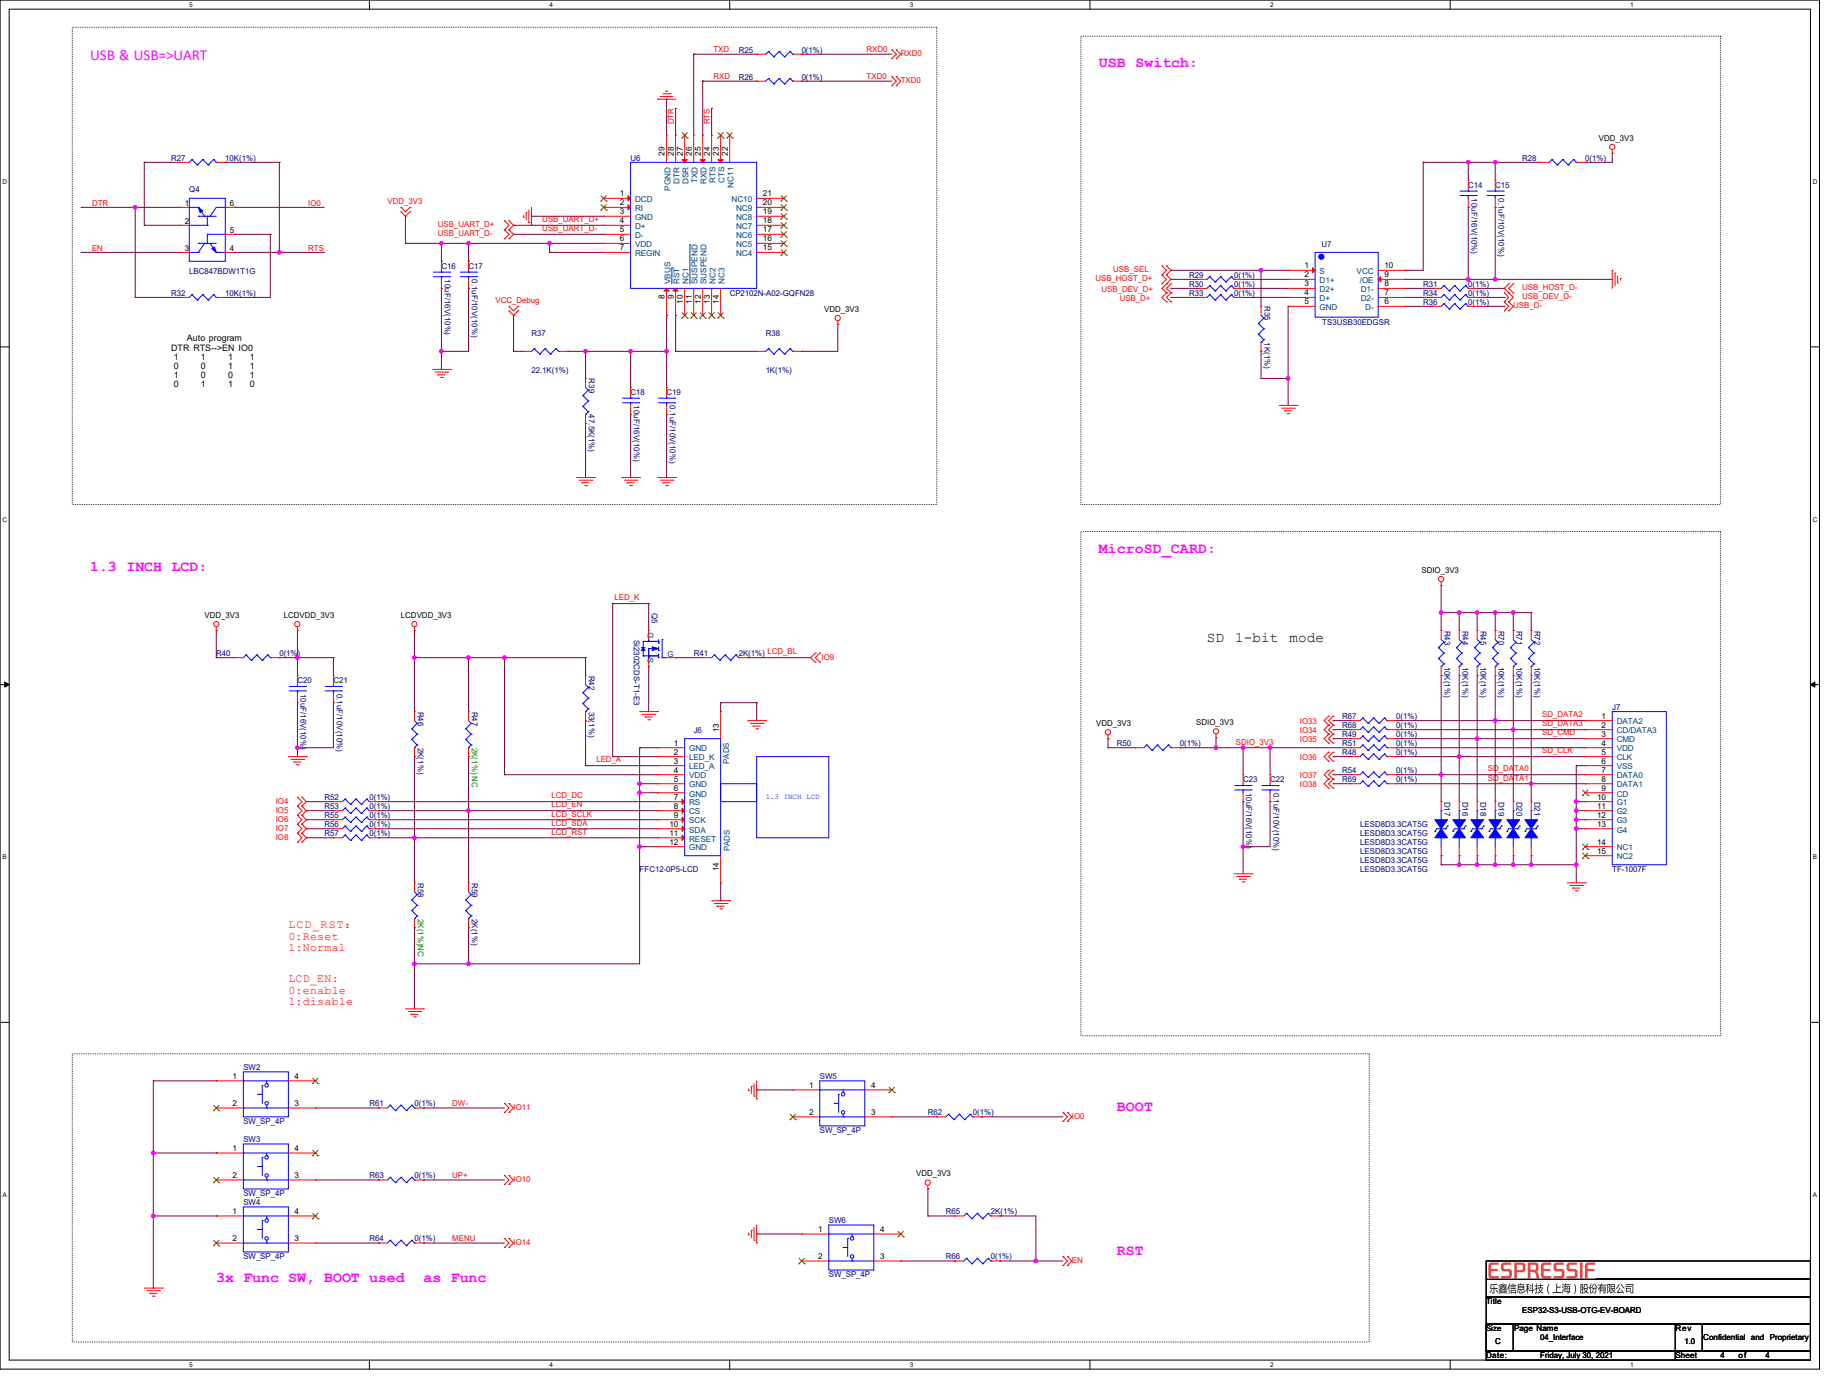
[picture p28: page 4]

LCD_RST | 11

3x Func SW, BOOT used as Func

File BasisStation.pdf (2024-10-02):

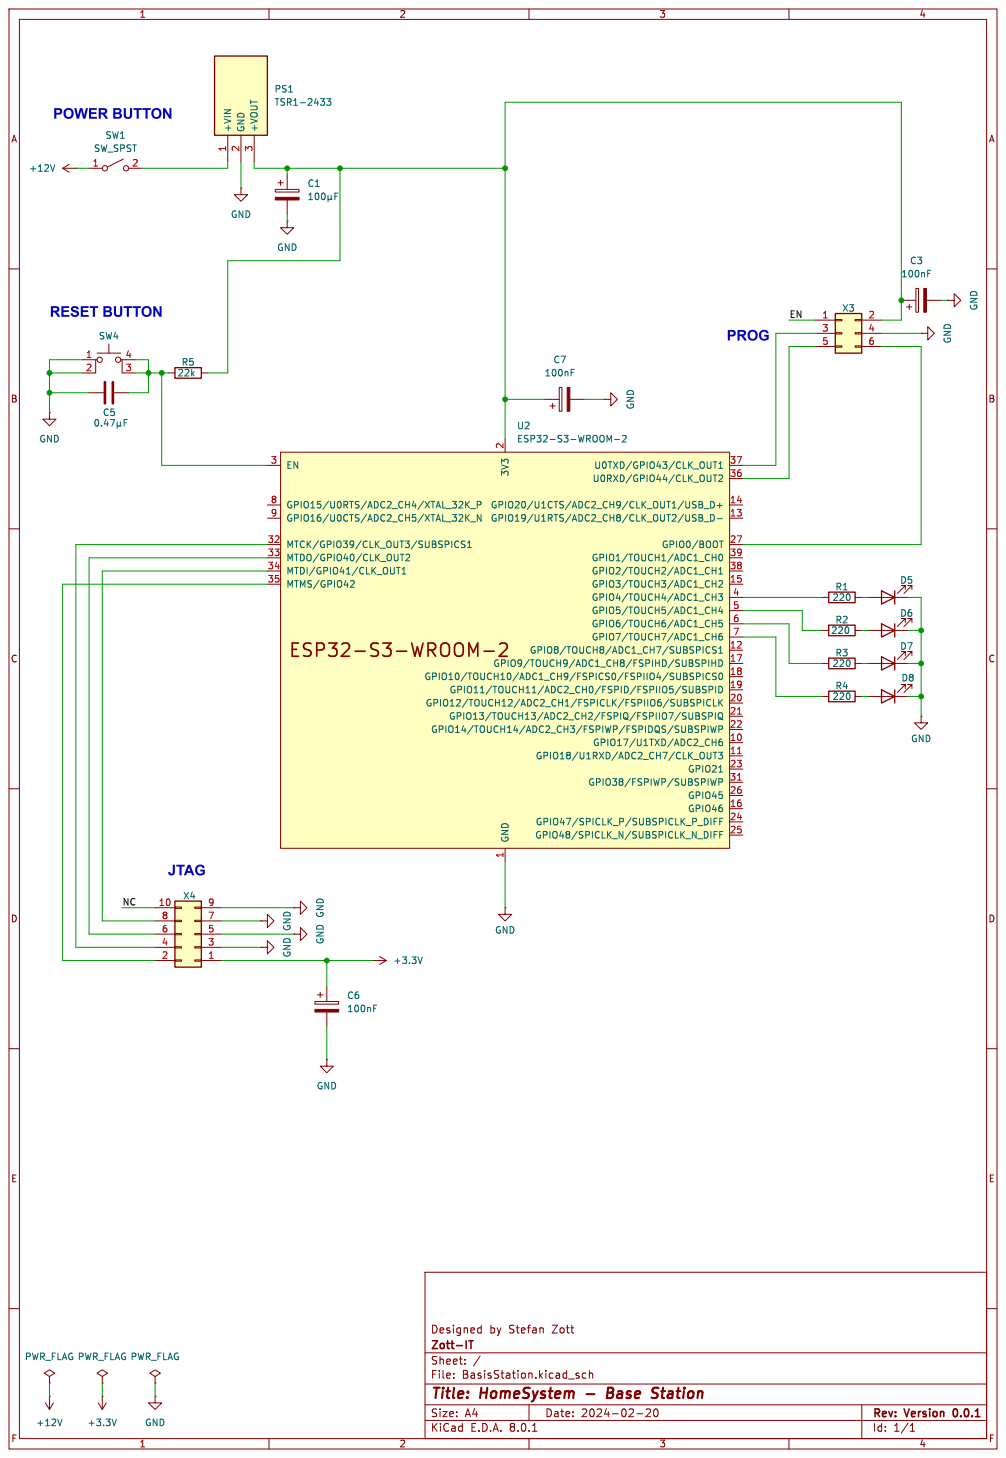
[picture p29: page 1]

2 GPIO12/TOUCH12/ADC2_CH1/FSPICLK/FSPIIO6/SUBSPICLK 20 GPIO13/TOUCH13/ADC2_CH2/FSPIQ/FSPIIO7/SUBSPIQ 21 GPIO14/TOUCH14/ADC2_CH3/FSPIWP/FSPIDQS/SUBSPIWP 22 GPIO21 23 GPIO47/SPICLK_P/SUBSPICLK_P_DIFF 24 GPIO48/SPICLK_N/SUBSPICLK_N_DIFF 25 GPIO45 26 GPIO0/BOOT 27 EN 3 GPIO38/FSPIWP/SUBSPIWP 31 MTCK/GPIO39/CLK_OUT3/SUBSPICS1 32 MTDO/GPIO40/CLK_OUT2 33 MTDI/GPIO41/CLK_OUT1 34 MTMS/GPIO42 35 U0RXD/GPIO44/CLK_OUT2 36 U0TXD/GPIO43/CLK_OUT1 37 GPIO2/TOUCH2/ADC1_CH1 38 GPIO1/TOUCH1/ADC1_CH0 39 GPIO4/TOUCH4/ADC1_CH3 4 GPIO5/TOUCH5/ADC1_CH4 5 GPIO6/TOUCH6/ADC1_CH5 6 GPIO7/TOUCH7/ADC1_CH6 7 GPIO15/U0RTS/ADC2_CH4/XTAL_32K_P 8 GPIO16/U0CTS/ADC2_CH5/XTAL_32K_N 9 U2ESP32-S3-WROOM-2 R3

1 GPIO17/U1TXD/ADC2_CH6 10 GPIO18/U1RXD/ADC2_CH7/CLK_OUT3 11 GPIO8/TOUCH8/ADC1_CH7/SUBSPICS1 12 GPIO19/U1RTS/ADC2_CH8/CLK_OUT2/USB_D- 13 GPIO20/U1CTS/ADC2_CH9/CLK_OUT1/USB_D+ 14 GPIO3/TOUCH3/ADC1_CH2 15 GPIO46 16 GPIO9/TOUCH9/ADC1_CH8/FSPIHD/SUBSPIHD 17 GPIO10/TOUCH10/ADC1_CH9/FSPICS0/FSPIIO4/SUBSPICS0 18 GPIO11/TOUCH11/ADC2_CH0/FSPID/FSPIIO5/SUBSPID 19 3V3

Id: 1/1 Title: HomeSystem - Base Station

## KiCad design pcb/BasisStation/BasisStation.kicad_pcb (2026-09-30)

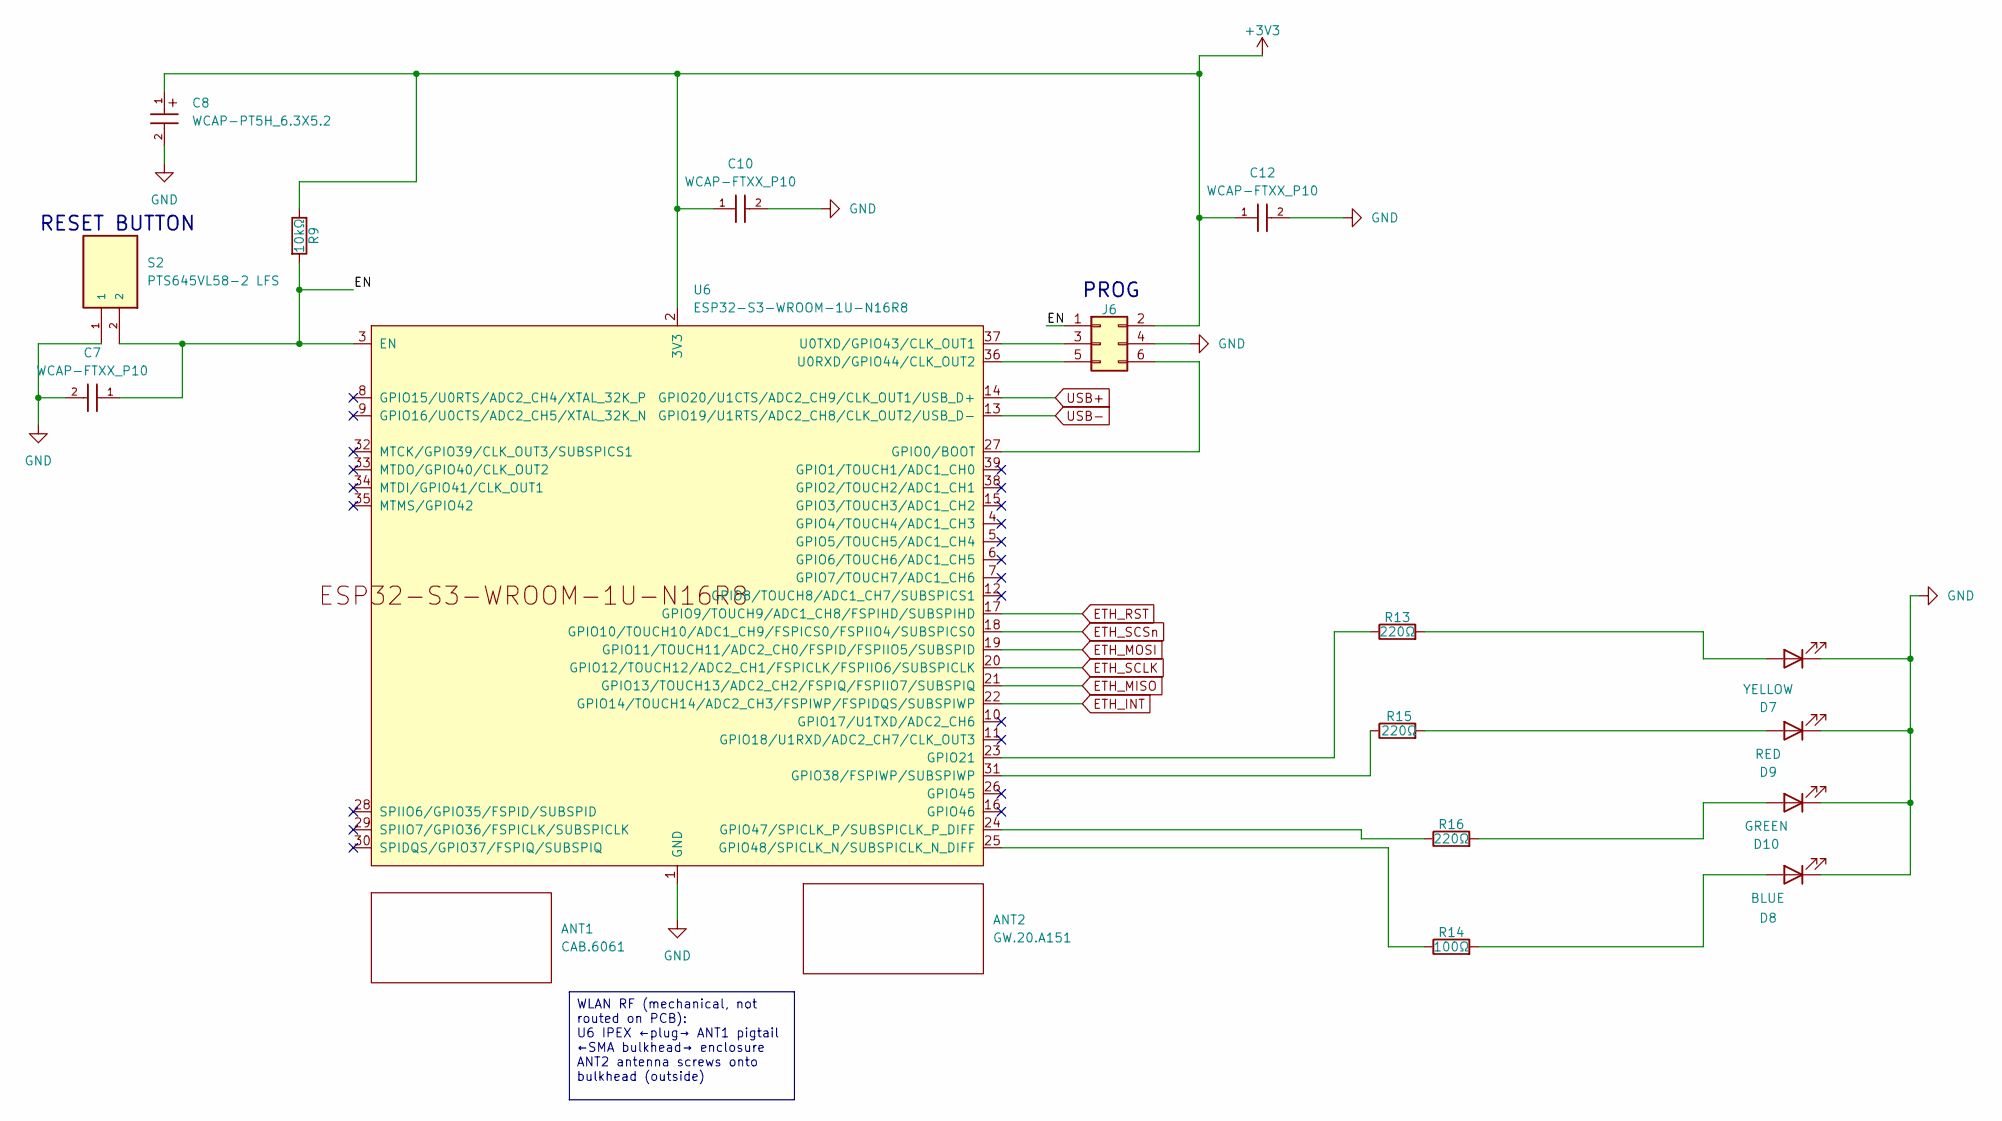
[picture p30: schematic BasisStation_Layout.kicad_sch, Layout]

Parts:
ANT1: CAB.6061; Manufacturer_Part_Number CAB.6061; Mouser Part Number 960-CAB.6061
ANT2: GW.20.A151; Manufacturer_Part_Number GW.20.A151; Mouser Part Number 960-GW.20.A151
C7, C10, C12: WCAP-FTXX_P10; WCAP-FTXX_P10L13W7H13
C8: WCAP-PT5H_6.3X5.2; WCAP-PT5H_6.3X5.2_DXL_
D7: YELLOW; LED_D3.0mm_Horizontal_O1.27mm_Z2.0mm
D8: BLUE; LED_D3.0mm_Horizontal_O1.27mm_Z2.0mm; Manufacturer_Part_Number 151033BS03000; Mouser Part Number 710-151033BS03000
D9: RED; LED_D3.0mm_Horizontal_O1.27mm_Z2.0mm; Manufacturer_Part_Number 151033RS03000; Mouser Part Number 710-151033RS03000
D10: GREEN; LED_D3.0mm_Horizontal_O1.27mm_Z2.0mm; Manufacturer_Part_Number 151031VS06000; Mouser Part Number 710-151031VS06000
J6: 61200621621; Manufacturer_Part_Number 61200621621; Mouser Part Number 710-61200621621
R9: 10kΩ; R_0805_2012Metric; Manufacturer_Part_Number RC0805FR-0710KL; Mouser Part Number 603-RC0805FR-0710KL
R13, R15, R16: 220Ω; R_0805_2012Metric; Manufacturer_Part_Number RC0805FR-07220RL; Mouser Part Number 603-RC0805FR-07220RL
R14: 100Ω; R_0805_2012Metric; Manufacturer_Part_Number RC0805FR-07100RL; Mouser Part Number 603-RC0805FR-07100RL
S2: PTS645VL58-2 LFS; SW_Tactile_SPST_Angled_PTS645Vx58-2LFS; MOUSER_PART_NUMBER 611-PTS645VL582
U6: ESP32-S3-WROOM-1U-N16R8; ESP32-S3-WROOM-1U; Mouser Part Number 356-ESP32S3WM1UN16R8

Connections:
+3V3: C8.1, C10.1, C12.1, J6.2, R9.1, U6.2 (3V3); also elsewhere on the board
/Layout/EN: C7.1, J6.1, R9.2, S2.2, U6.3 (EN)
ETH_INT: U6.22 (GPIO14/TOUCH14/ADC2_CH3/FSPIWP/FSPIDQS/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); also elsewhere on the board
ETH_MISO: U6.21 (GPIO13/TOUCH13/ADC2_CH2/FSPIQ/FSPIIO7/S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); also elsewhere on the board
ETH_MOSI: U6.19 (GPIO11/TOUCH11/ADC2_CH0/FSPID/FSPIIO5/S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); also elsewhere on the board
ETH_RST: U6.17 (GPIO9/TOUCH9/ADC1_CH8/FSPIHD/SUBSPIHD); also elsewhere on the board
ETH_SCLK: U6.20 (GPIO12/TOUCH12/ADC2_CH1/FSPICLK/FSPIIO6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); also elsewhere on the board
ETH_SCSn: U6.18 (GPIO10/TOUCH10/ADC1_CH9/FSPICS0/FSPIIO4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); also elsewhere on the board
GND: C7.2, C8.2, C10.2, C12.2, D7.1 (K), D8.1 (K), D9.1 (K), D10.1 (K), J6.4, S2.1, U6.1 (GND), U6.40 (GND), U6.41 (GND); also elsewhere on the board
unnamed: D7.2 (A), R13.2
unnamed: D8.2 (A), R14.2
unnamed: D9.2 (A), R15.2
unnamed: D10.2 (A), R16.2
unnamed: J6.3, U6.37 (U0TXD/GPIO43/CLK_OUT1)
unnamed: J6.5, U6.36 (U0RXD/GPIO44/CLK_OUT2)
unnamed: J6.6, U6.27 (GPIO0/BOOT)
unnamed: R13.1, U6.23 (GPIO21)
unnamed: R15.1, U6.31 (GPIO38/FSPIWP/SUBSPIWP)
unnamed: R16.1, U6.24 (GPIO47/SPICLK_P/SUBSPICLK_P_DIFF)
unnamed: R14.1, U6.25 (GPIO48/SPICLK_N/SUBSPICLK_N_DIFF)
USB+: U6.14 (GPIO20/U1CTS/ADC2_CH9/CLK_OUT1/USB_D+); also elsewhere on the board
USB-: U6.13 (GPIO19/U1RTS/ADC2_CH8/CLK_OUT2/USB_D-); also elsewhere on the board

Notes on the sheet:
RESET BUTTON
PROG
WLAN RF (mechanical, not routed on PCB): U6 IPEX ←plug→ ANT1 pigtail ←SMA bulkhead→ enclosure ANT2 antenna screws onto bulkhead (outside)

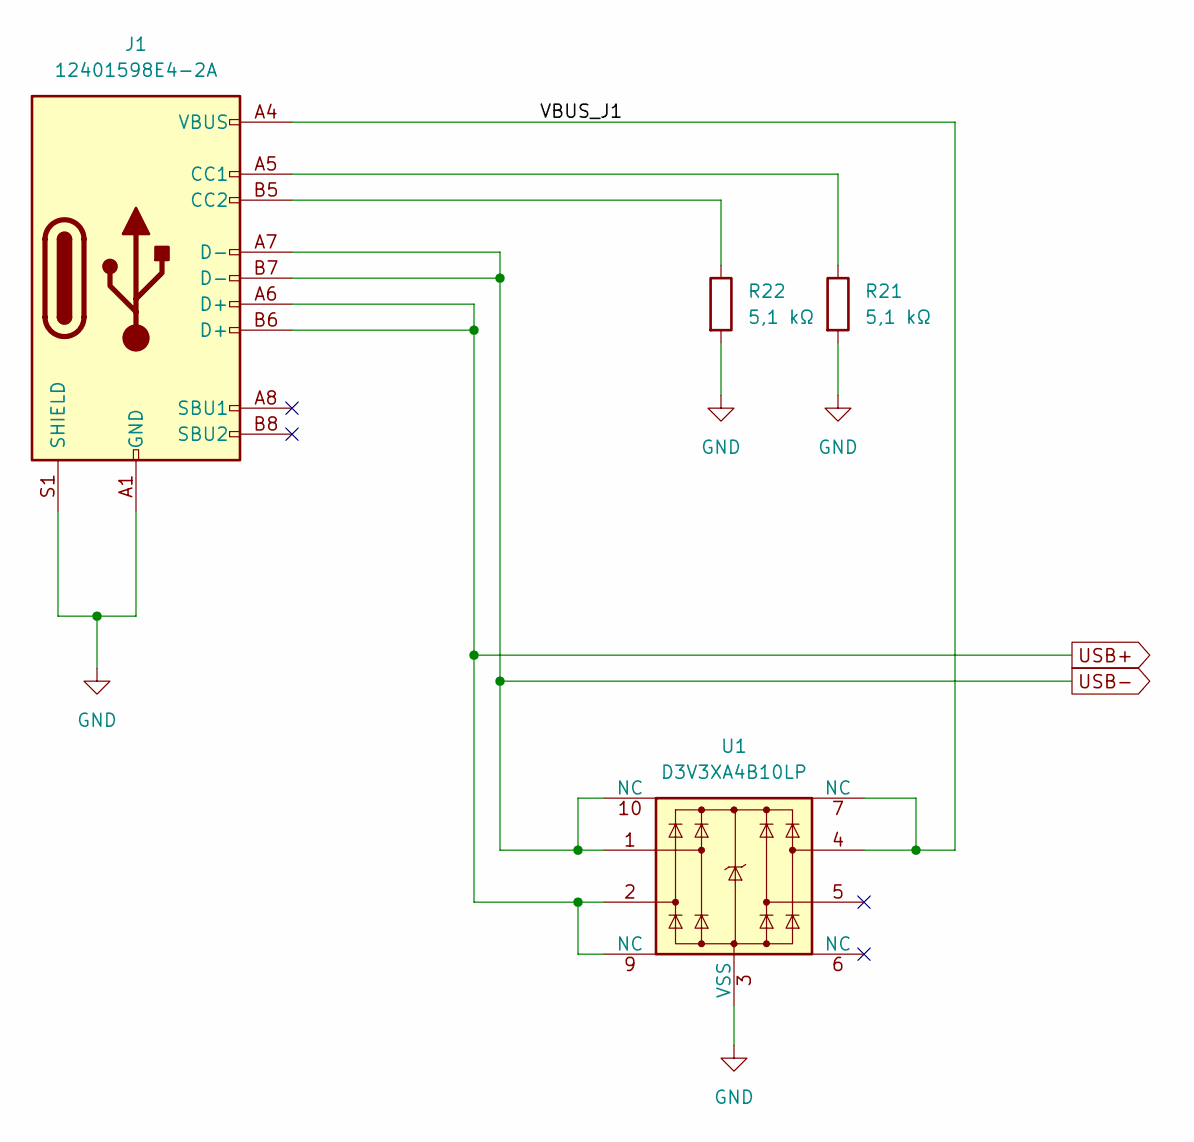
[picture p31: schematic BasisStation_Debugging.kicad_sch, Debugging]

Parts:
J1: 12401598E4-2A; USB_C_Receptacle_Amphenol_12401598E4-2A; Manufacturer_Part_Number 12401598E4#2A; Mouser Part Number 523-12401598E4#2A
R21, R22: 5,1 kΩ; R_0805_2012Metric; Manufacturer_Part_Number RC0805FR-075K1L; Mouser Part Number 603-RC0805FR-075K1L
U1: D3V3XA4B10LP; Diodes_UDFN-10_1x2.5mm_P0.5mm; Manufacturer_Part_Number D3V3XA4B10LP-7; Mouser Part Number 621-D3V3XA4B10LP-7

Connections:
/Debugging/VBUS_J1: J1.A4 (VBUS), J1.A9 (VBUS), J1.B4 (VBUS), J1.B9 (VBUS), U1.4, U1.7 (NC)
GND: J1.A1 (GND), J1.A12 (GND), J1.B1 (GND), J1.B12 (GND), J1.S1 (SHIELD), R21.2, R22.2, U1.3 (VSS), U1.8 (VSS); also elsewhere on the board
unnamed: J1.A5 (CC1), R21.1
unnamed: J1.B5 (CC2), R22.1
USB+: J1.A6 (D+), J1.B6 (D+), U1.2, U1.9 (NC); also elsewhere on the board
USB-: J1.A7 (D-), J1.B7 (D-), U1.1, U1.10 (NC); also elsewhere on the board

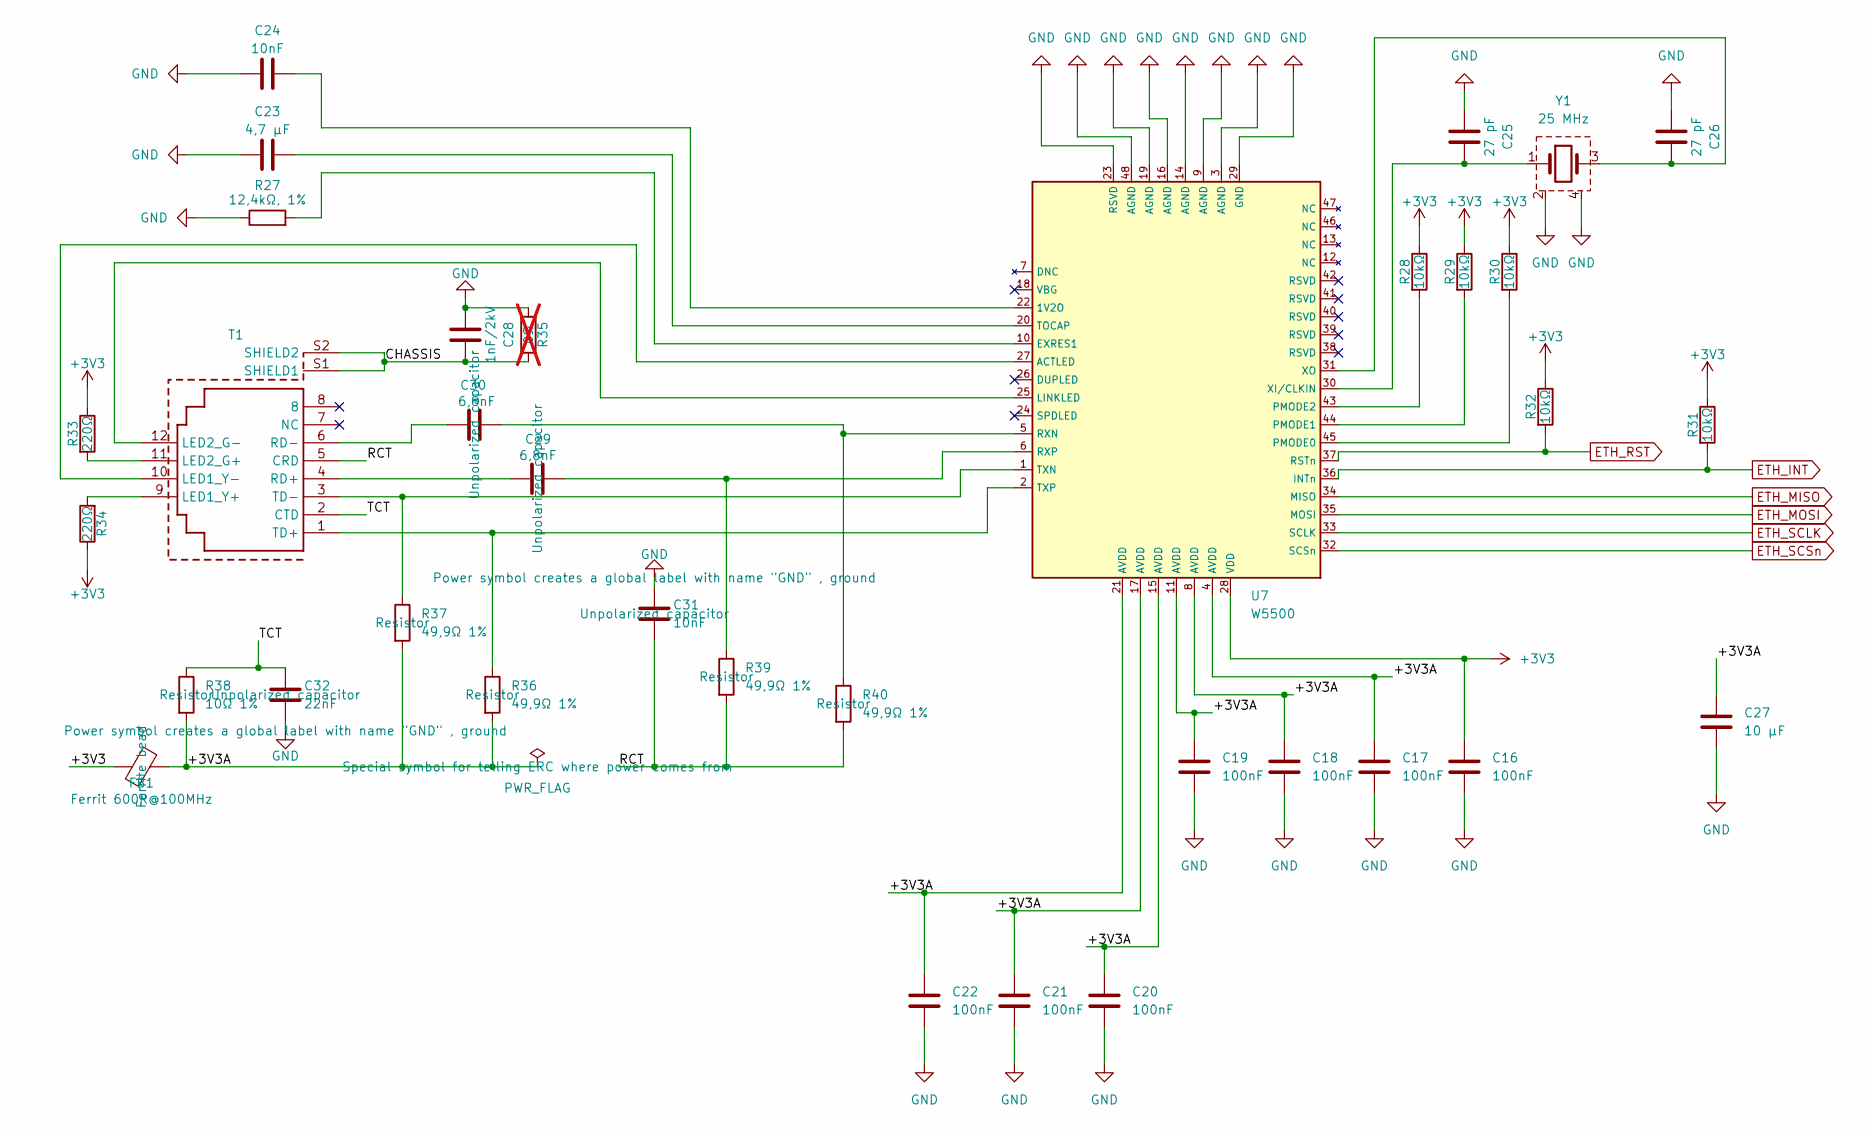
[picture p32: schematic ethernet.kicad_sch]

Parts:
C16, C17, C18, C19, C20, C21, C22: 100nF; C_0805_2012Metric; Manufacturer_Part_Number CC0805KRX7R9BB104; Mouser Part Number 603-CC805KRX7R9BB104
C23: 4,7 µF; C_0805_2012Metric; Manufacturer_Part_Number CL21A475KAQNNNE; Mouser Part Number 187-CL21A475KAQNNNE
C24, C31: 10nF; C_0805_2012Metric; Manufacturer_Part_Number CC0805KRX7R9BB103; Mouser Part Number 603-CC805KRX7R9BB103
C25, C26: 27 pF; C_0805_2012Metric; Manufacturer_Part_Number CC0805JRNPO9BN270; Mouser Part Number 603-CC805JRNPO9BN270
C27: 10 µF; C_0805_2012Metric; Manufacturer_Part_Number CL21B106KOQNNNE; Mouser Part Number 187-CL21B106KOQNNNE
C28: 1nF/2kV; C_1206_3216Metric; Manufacturer_Part_Number C1206C102KGRACTU; Mouser Part Number 80-C1206C102KGR
C29, C30: 6,8nF; C_0805_2012Metric; Manufacturer_Part_Number CC0805KRX7R9BB682; Mouser Part Number 603-CC805KRX7R9BB682
C32: 22nF; C_0805_2012Metric; Manufacturer_Part_Number CL21B223KBANNNC; Mouser Part Number 187-CL21B223KBANNNC
FB1: Ferrit 600R@100MHz; L_0805_2012Metric; Manufacturer_Part_Number BLM21PG601SN1D; Mouser Part Number 81-BLM21PG601SN1D
R27: 12,4kΩ, 1%; R_0805_2012Metric; Manufacturer_Part_Number RC0805FR-0712K4L; Mouser Part Number 603-RC0805FR-0712K4L
R28, R29, R30, R31, R32: 10kΩ; R_0805_2012Metric; Manufacturer_Part_Number RC0805FR-0710KL; Mouser Part Number 603-RC0805FR-0710KL
R33, R34: 220Ω; R_0805_2012Metric; Manufacturer_Part_Number RC0805FR-07220RL; Mouser Part Number 603-RC0805FR-07220RL
R35: 0Ω; R_0805_2012Metric; Manufacturer_Part_Number RC0805JR-070RL; Mouser Part Number 603-RC0805JR-070RL; not fitted
R36, R37, R39, R40: 49,9Ω 1%; R_0805_2012Metric; Manufacturer_Part_Number RC0805FR-0749R9L; Mouser Part Number 603-RC0805FR-0749R9L
R38: 10Ω 1%; R_0805_2012Metric; Manufacturer_Part_Number RC0805FR-0710RL; Mouser Part Number 603-RC0805FR-0710RL
T1: 7499011121A; T_Wurth_WE-RJ45LAN_7499011121A; Part Number 7499011121A; Mouser Part Number 710-7499011121A
U7: W5500; 48LQFP_W5500_WIZ; Manufacturer_Part_Number W5500
Y1: 25 MHz; Y_Wurth_WE-XTAL_Quartz-CFPX-104; Part Number 830059532; Mouser Part Number 710-830059532

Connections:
+3V3: C16.1, FB1.1, R28.1, R29.1, R30.1, R31.1, R32.1, R33.1, R34.1, U7.28 (VDD); also elsewhere on the board
/Ethernet/+3V3A: C17.1, C18.1, C19.1, C20.1, C21.1, C22.1, C27.1, FB1.2, R36.2, R37.2, R38.2, U7.4 (AVDD), U7.8 (AVDD), U7.11 (AVDD), U7.15 (AVDD), U7.17 (AVDD), U7.21 (AVDD)
/Ethernet/CHASSIS: C28.2, R35.1, T1.S1 (SHIELD1), T1.S2 (SHIELD2)
/Ethernet/RCT: C31.2, R39.2, R40.2, T1.5 (CRD)
/Ethernet/TCT: C32.1, R38.1, T1.2 (CTD)
ETH_INT: R31.2, U7.36 (INTn); also elsewhere on the board
ETH_MISO: U7.34 (MISO); also elsewhere on the board
ETH_MOSI: U7.35 (MOSI); also elsewhere on the board
ETH_RST: R32.2, U7.37 (RSTn); also elsewhere on the board
ETH_SCLK: U7.33 (SCLK); also elsewhere on the board
ETH_SCSn: U7.32 (SCSn); also elsewhere on the board
GND: C16.2, C17.2, C18.2, C19.2, C20.2, C21.2, C22.2, C23.1, C24.1, C25.1, C26.1, C27.2, C28.1, C31.1, C32.2, R27.1, R35.2, U7.3 (AGND), U7.9 (AGND), U7.14 (AGND), U7.16 (AGND), U7.19 (AGND), U7.23 (RSVD), U7.29 (GND), U7.48 (AGND), Y1.2 (GND), Y1.4 (GND1); also elsewhere on the board
unnamed: R34.2, T1.9 (LED1_Y+)
unnamed: T1.10 (LED1_Y-), U7.27 (ACTLED)
unnamed: R33.2, T1.11 (LED2_G+)
unnamed: T1.12 (LED2_G-), U7.25 (LINKLED)
unnamed: C29.1, T1.4 (RD+)
unnamed: C30.1, T1.6 (RD-)
unnamed: R36.1, T1.1 (TD+), U7.2 (TXP)
unnamed: R37.1, T1.3 (TD-), U7.1 (TXN)
unnamed: C24.2, U7.22 (1V2O)
unnamed: R27.2, U7.10 (EXRES1)
unnamed: R30.2, U7.45 (PMODE0)
unnamed: R29.2, U7.44 (PMODE1)
unnamed: R28.2, U7.43 (PMODE2)
unnamed: C30.2, R40.1, U7.5 (RXN)
unnamed: C29.2, R39.1, U7.6 (RXP)
unnamed: C23.2, U7.20 (TOCAP)
unnamed: C25.2, U7.30 (XI/CLKIN), Y1.1
unnamed: C26.2, U7.31 (XO), Y1.3

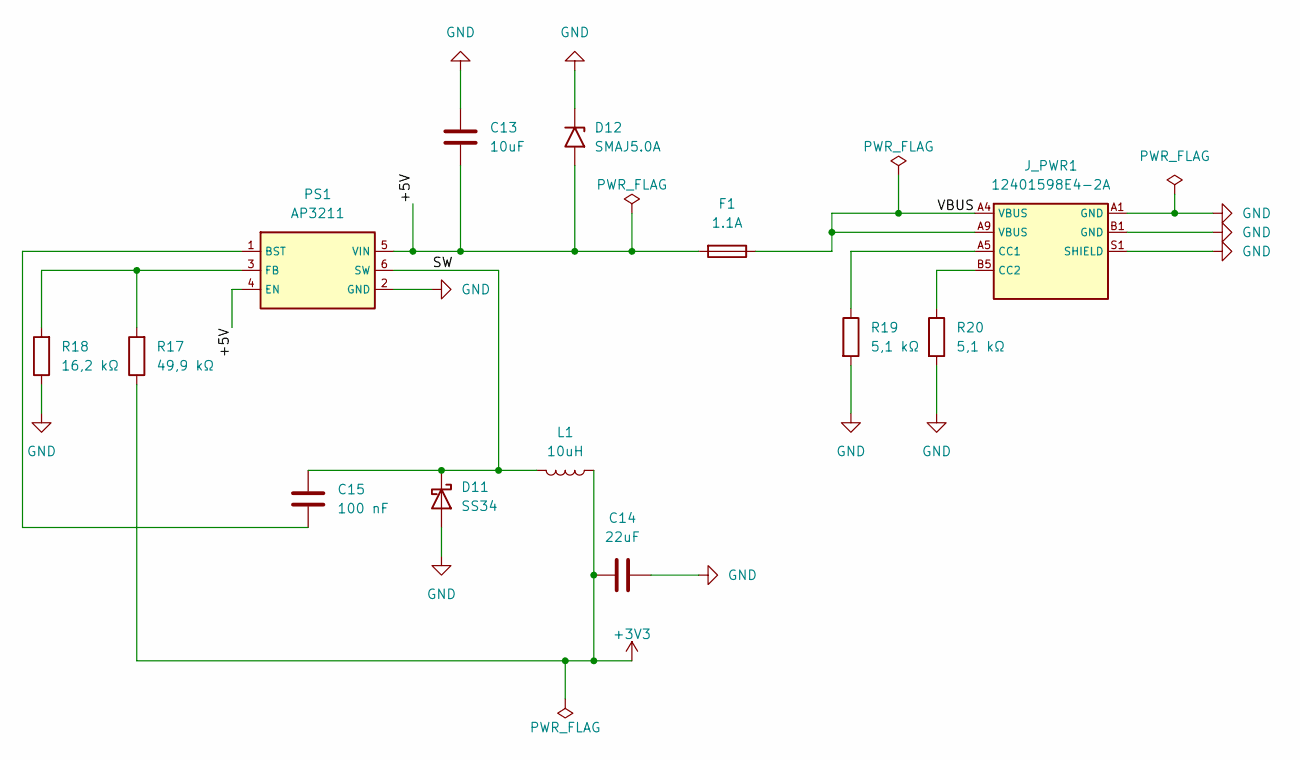
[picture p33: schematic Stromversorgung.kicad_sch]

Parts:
C13: 10uF; C_0805_2012Metric; Manufacturer_Part_Number CL21B106KOQNNNE; Mouser Part Number 187-CL21B106KOQNNNE
C14: 22uF; C_0805_2012Metric; Manufacturer_Part_Number CL21A226MOQNNNE; Mouser Part Number 187-CL21A226MOQNNNE
C15: 100 nF; C_0805_2012Metric; Manufacturer_Part_Number CC0805KRX7R9BB104; Mouser Part Number 603-CC805KRX7R9BB104
D11: SS34; D_SMA; Manufacturer_Part_Number SS34-HF; Mouser Part Number 750-SS34-HF
D12: SMAJ5.0A; D_SMA; Manufacturer_Part_Number SMAJ5.0A; Mouser Part Number 576-SMAJ5.0A
F1: 1.1A; Fuse_1206_3216Metric; Manufacturer_Part_Number MF-NSMF110-2; Mouser Part Number 652-MF-NSMF110-2
J_PWR1: 12401598E4-2A; USB_C_Receptacle_Amphenol_12401598E4-2A; Manufacturer_Part_Number 12401598E4#2A; Mouser Part Number 523-12401598E4#2A
L1: 10uH; L_Bourns_SRN6045TA; Manufacturer_Part_Number SRN6045TA-100M; Mouser Part Number 652-SRN6045TA-100M
PS1: AP3211; MP2359DJ; Manufacturer_Part_Number AP3211KTR-G1; Mouser Part Number 621-AP3211KTR-G1
R17: 49,9 kΩ; R_0805_2012Metric; Manufacturer_Part_Number RC0805FR-0749K9L; Mouser Part Number 603-RC0805FR-0749K9L
R18: 16,2 kΩ; R_0805_2012Metric; Manufacturer_Part_Number RC0805FR-0716K2L; Mouser Part Number 603-RC0805FR-0716K2L
R19, R20: 5,1 kΩ; R_0805_2012Metric; Manufacturer_Part_Number RC0805FR-075K1L; Mouser Part Number 603-RC0805FR-075K1L

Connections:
+3V3: C14.2, L1.1, R17.1; also elsewhere on the board
/Stromversorgung/+5V: C13.2, D12.2 (A2), F1.2, PS1.4 (EN), PS1.5 (VIN)
/Stromversorgung/SW: C15.2, D11.1 (K), L1.2, PS1.6 (SW)
/Stromversorgung/VBUS: F1.1, J_PWR1.A4 (VBUS), J_PWR1.A9 (VBUS), J_PWR1.B4 (VBUS), J_PWR1.B9 (VBUS)
GND: C13.1, C14.1, D11.2 (A), D12.1 (A1), J_PWR1.A1 (GND), J_PWR1.A12 (GND), J_PWR1.B1 (GND), J_PWR1.B12 (GND), J_PWR1.S1 (SHIELD), PS1.2 (GND), R18.1, R19.2, R20.2; also elsewhere on the board
unnamed: J_PWR1.A5 (CC1), R19.1
unnamed: J_PWR1.B5 (CC2), R20.1
unnamed: C15.1, PS1.1 (BST)
unnamed: PS1.3 (FB), R17.2, R18.2

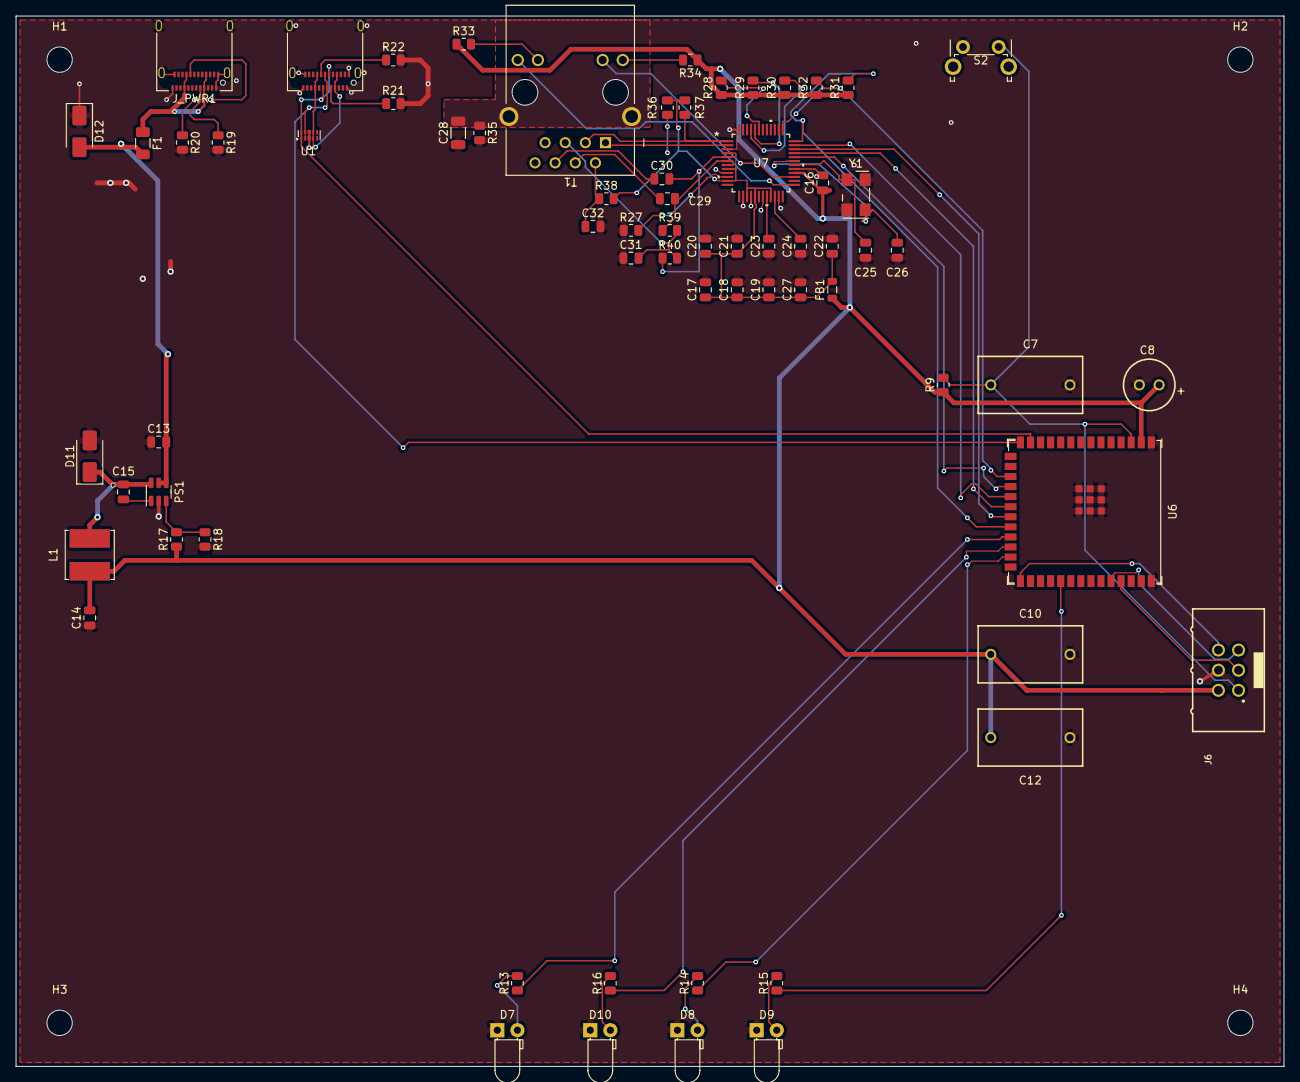
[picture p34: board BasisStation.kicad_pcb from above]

Board: 2 copper layers, 160.0 x 132.6 mm, 72 parts (0 on the bottom side), 54 nets.

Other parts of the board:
H1, H2, H3, H4: MountingHole_3.2mm_M3

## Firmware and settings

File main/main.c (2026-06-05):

#include <stdio.h>
#include "nvs_flash.h"
#include "freertos/FreeRTOS.h"
#include "freertos/FreeRTOSConfig.h"
#include "freertos/task.h"
#include "freertos/semphr.h"
#include "esp_event.h"
#include "esp_spiffs.h"
#include "esp_log.h"

#include "main.h"
#include "TaskControl.h"
#include "LED.h"
#include "WLAN.h"
#include "WebServer.h"
#include "FileManagement.h"

SemaphoreHandle_t xLedMutex;
SemaphoreHandle_t xLedSemaphore;

const char *productName = "SmartHome-Basisstation";
cJSON* config;

static int ret;

static esp_err_t initSpiffs(void) {
    printf("EVENT: Main -> Initializing SPIFFS\n");

    esp_vfs_spiffs_conf_t conf = {
      .base_path = "/spiffs",
      .partition_label = NULL,
      .max_files = 20,   // This decides the maximum number of files that can be created on the storage
      .format_if_mount_failed = true
    };

    ret = esp_vfs_spiffs_register(&conf);

    if (ret != ESP_OK) {
        if (ret == ESP_FAIL) {
             printf("EVENT: Main -> Failed to mount or format filesystem\n");
        } else if (ret == ESP_ERR_NOT_FOUND) {
             printf("EVENT: Main -> Failed to find SPIFFS partition\n");
        } else {
             printf("EVENT: Main -> Failed to initialize SPIFFS (%s)\n", esp_err_to_name(ret));
        }
        return ESP_FAIL;
    }

    size_t total = 0, used = 0;

    ret = esp_spiffs_info(conf.partition_label, &total, &used);

    if (ret != ESP_OK) {
         printf("EVENT: Main -> Failed to get SPIFFS partition information (%s)\n", esp_err_to_name(ret));
        return ESP_FAIL;
    }

     printf("EVENT: Main -> Partition size: total: %d, used: %d\n", total, used);
    return ESP_OK;
}

static const char *TAG = "main";

void app_main(void) {
    //Initialize NVS
    esp_err_t ret = nvs_flash_init();
    if (ret == ESP_ERR_NVS_NO_FREE_PAGES || ret == ESP_ERR_NVS_NEW_VERSION_FOUND) {
        ESP_ERROR_CHECK_WITHOUT_ABORT(nvs_flash_erase());
        ret = nvs_flash_init();
    }
    ESP_ERROR_CHECK_WITHOUT_ABORT(ret);

    ESP_ERROR_CHECK(esp_netif_init());
    ESP_ERROR_CHECK(esp_event_loop_create_default());

    xLedMutex = xSemaphoreCreateMutex();
    xLedSemaphore = xSemaphoreCreateBinary();

    initSpiffs();

    httpd_handle_t http_server = NULL;
    ret = startWebServer("/spiffs", &http_server);
    if (ret != ESP_OK) {
        ESP_LOGE(TAG, "Failed to start web server: %s", esp_err_to_name(ret));
    }

    xTaskCreatePinnedToCore( ledControlTask, "ledControlTask", 4096, NULL, 1, NULL, PRO_CPU );
    xTaskCreatePinnedToCore( executeTaskControl, "TaskControl", 2048, NULL, 1, NULL, PRO_CPU );
    xTaskCreatePinnedToCore( wifiControlTask, "wifiControlTask", 8192, NULL, 1, NULL, APP_CPU );

    if(file_isExisting(wifiConfigFile)) {
        if(cJSON_IsNull(config)) {
            config = cJSON_Parse(file_getContent(wifiConfigFile));
        } else {
            config = cJSON_CreateObject();
            cJSON_AddStringToObject(config, "SSID", "");
            cJSON_AddStringToObject(config, "Password", "");
            cJSON_AddStringToObject(config, "Channel", "");
            cJSON_AddStringToObject(config, "RSSI", "");
            cJSON_AddStringToObject(config, "Authenticate Mode", "");

            cJSON_AddStringToObject(config, "IP", "");
            cJSON_AddStringToObject(config, "Netmask", "");
            cJSON_AddStringToObject(config, "Gateway", "");
            file_writeContentInFile(wifiConfigFile, config);
        }
    } else {
        config = cJSON_CreateObject();
        cJSON_AddStringToObject(config, "SSID", "");
        cJSON_AddStringToObject(config, "Password", "");
        cJSON_AddStringToObject(config, "Channel", "");
        cJSON_AddStringToObject(config, "RSSI", "");
        cJSON_AddNumberToObject(config, "Authenticate Mode", -1);

        cJSON_AddStringToObject(config, "IP", "");
        cJSON_AddStringToObject(config, "Netmask", "");
        cJSON_AddStringToObject(config, "Gateway", "");
        file_writeContentInFile(wifiConfigFile, config);
    }

    wifi_init_sta_and_softap();
}

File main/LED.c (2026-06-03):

#include <stdio.h>
#include <string.h>
#include "freertos/FreeRTOS.h"
#include "freertos/FreeRTOSConfig.h"
#include "freertos/task.h"
#include "freertos/semphr.h"

#include "esp_log.h"

#include"LED.h"
#include "main.h"
#include "WLAN.h"

static const char* TAG = "LED";
static int count;

QueueHandle_t xLedStateQueue;
ledStateMessage message;
ledStateMessage tempMessage;

ledProfil redLedProfil;
ledProfil greenLedProfil;
ledProfil yellowLedProfil;
ledProfil blueLedProfil;

ledProfil tempRedLedProfil;
ledProfil tempGreenLedProfil;
ledProfil tempYellowLedProfil;
ledProfil tempblueLedProfil;

static void ledInit(void) {
    // Prepare and then apply the LEDC PWM timer configuration
    ledc_timer_config_t ledRedTimer = {
        .speed_mode       = LEDC_MODE,
        .duty_resolution  = LEDC_DUTY_RES,
        .timer_num        = LEDC_TIMER,
        .freq_hz          = LEDC_FREQUENCY,  // Set output frequency at 4 kHz
        .clk_cfg          = LEDC_AUTO_CLK
    };
    ESP_ERROR_CHECK(ledc_timer_config(&ledRedTimer));

    // Prepare and then apply the LEDC PWM channel configuration
    ledc_channel_config_t ledRedChannel = {
        .speed_mode     = LEDC_MODE,
        .channel        = LED_RED,
        .timer_sel      = LEDC_TIMER,
        .intr_type      = LEDC_INTR_DISABLE,
        .gpio_num       = LED_GPIO_RED,
        .duty           = 0, // Set duty to 0%
        .hpoint         = 0
    };
    ESP_ERROR_CHECK(ledc_channel_config(&ledRedChannel));
    redLedProfil.state = OFF;
    redLedProfil.mode = NORMAL;
    tempRedLedProfil.state = OFF;
    tempRedLedProfil.mode = NORMAL;


    // Prepare and then apply the LEDC PWM timer configuration
    ledc_timer_config_t ledGreenTimer = {
        .speed_mode       = LEDC_MODE,
        .duty_resolution  = LEDC_DUTY_RES,
        .timer_num        = LEDC_TIMER,
        .freq_hz          = LEDC_FREQUENCY,  // Set output frequency at 4 kHz
        .clk_cfg          = LEDC_AUTO_CLK
    };
    ESP_ERROR_CHECK(ledc_timer_config(&ledGreenTimer));

    // Prepare and then apply the LEDC PWM channel configuration
    ledc_channel_config_t ledGreenChannel = {
        .speed_mode     = LEDC_MODE,
        .channel        = LED_GREEN,
        .timer_sel      = LEDC_TIMER,
        .intr_type      = LEDC_INTR_DISABLE,
        .gpio_num       = LED_GPIO_GREEN,
        .duty           = 0, // Set duty to 0%
        .hpoint         = 0
    };
    ESP_ERROR_CHECK(ledc_channel_config(&ledGreenChannel));
    greenLedProfil.state = OFF;
    greenLedProfil.mode = NORMAL;
    tempGreenLedProfil.state = OFF;
    tempGreenLedProfil.mode = NORMAL;


    // Prepare and then apply the LEDC PWM timer configuration
    ledc_timer_config_t ledYellowTimer = {
        .speed_mode       = LEDC_MODE,
        .duty_resolution  = LEDC_DUTY_RES,
        .timer_num        = LEDC_TIMER,
        .freq_hz          = LEDC_FREQUENCY,  // Set output frequency at 4 kHz
        .clk_cfg          = LEDC_AUTO_CLK
    };
    ESP_ERROR_CHECK(ledc_timer_config(&ledYellowTimer));

    // Prepare and then apply the LEDC PWM channel configuration
    ledc_channel_config_t ledYellowChannel = {
        .speed_mode     = LEDC_MODE,
        .channel        = LED_YELLOW,
        .timer_sel      = LEDC_TIMER,
        .intr_type      = LEDC_INTR_DISABLE,
        .gpio_num       = LED_GPIO_YELLOW,
        .duty           = 0, // Set duty to 0%
        .hpoint         = 0
    };
    ESP_ERROR_CHECK(ledc_channel_config(&ledYellowChannel));
    yellowLedProfil.state = OFF;
    yellowLedProfil.mode = NORMAL;
    tempYellowLedProfil.state = OFF;
    tempYellowLedProfil.mode = NORMAL;


    // Prepare and then apply the LEDC PWM timer configuration
    ledc_timer_config_t ledBlueTimer = {
        .speed_mode       = LEDC_MODE,
        .duty_resolution  = LEDC_DUTY_RES,
        .timer_num        = LEDC_TIMER,
        .freq_hz          = LEDC_FREQUENCY,  // Set output frequency at 4 kHz
        .clk_cfg          = LEDC_AUTO_CLK
    };
    ESP_ERROR_CHECK(ledc_timer_config(&ledBlueTimer));

    // Prepare and then apply the LEDC PWM channel configuration
    ledc_channel_config_t ledBlueChannel = {
        .speed_mode     = LEDC_MODE,
        .channel        = LED_BLUE,
        .timer_sel      = LEDC_TIMER,
        .intr_type      = LEDC_INTR_DISABLE,
        .gpio_num       = LED_GPIO_BLUE,
        .duty           = 0, // Set duty to 0%
        .hpoint         = 0
    };
    ESP_ERROR_CHECK(ledc_channel_config(&ledBlueChannel));
    blueLedProfil.state = OFF;
    blueLedProfil.mode = NORMAL;
    tempblueLedProfil.state = OFF;
    tempblueLedProfil.mode = NORMAL;
}

static void saveSettings() {
    // ESP_LOGI(TAG, "Save Settings tempMessage -> LED = %s, State = %s, Mode = %s", tempMessage.led, tempMessage.state, tempMessage.mode);
    // ESP_LOGI(TAG, "Save Settings message -> LED = %s, State = %s, Mode = %s", message.led, message.state, message.mode);
    if (tempMessage.mode != TEST && tempMessage.mode != SINGLETEST) {
        // ESP_LOGI(TAG, "Save Settings message and LEDs");

        message.led = tempMessage.led;
        message.state = tempMessage.state;
        message.mode = tempMessage.mode;

        redLedProfil.state = tempRedLedProfil.state;
        redLedProfil.mode = tempRedLedProfil.mode;

        greenLedProfil.state = tempGreenLedProfil.state;
        greenLedProfil.mode = tempGreenLedProfil.mode;

        yellowLedProfil.state = tempYellowLedProfil.state;
        yellowLedProfil.mode = tempYellowLedProfil.mode;

        blueLedProfil.state = tempblueLedProfil.state;
        blueLedProfil.mode = tempblueLedProfil.mode;
    }
}

static void loadSettings() { 
    tempMessage.led = message.led;
    tempMessage.state = message.state;
    tempMessage.mode = message.mode;

    tempRedLedProfil.state = redLedProfil.state;
    tempRedLedProfil.mode = redLedProfil.mode;

    tempGreenLedProfil.state = greenLedProfil.state;
    tempGreenLedProfil.mode = greenLedProfil.mode;

    tempYellowLedProfil.state = yellowLedProfil.state;
    tempYellowLedProfil.mode = yellowLedProfil.mode;

    tempblueLedProfil.state = blueLedProfil.state;
    tempblueLedProfil.mode = blueLedProfil.mode;
}

static void blink() {
    if(ledc_get_duty(LEDC_MODE, LED_BLUE) > 0) {
        ESP_LOGI(TAG, "Blue LED OFF");
        // Set duty to 50%
        ESP_ERROR_CHECK(ledc_set_duty(LEDC_MODE, LED_BLUE, OFF));
        // Update duty to apply the new value
        ESP_ERROR_CHECK(ledc_update_duty(LEDC_MODE, LED_BLUE));
    } else {
        ESP_LOGI(TAG, "Blue LED ON");
        ESP_ERROR_CHECK(ledc_set_duty(LEDC_MODE, LED_BLUE, ON));
        ESP_ERROR_CHECK(ledc_update_duty(LEDC_MODE, LED_BLUE));
    }
}
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

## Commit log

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2026-06-04 v0.00.001 fix(SHBS-2): Produktname und Hostname auf SmartHome-Basisstation abgestimmt
    [main.c]
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2026-06-04 v0.00.001 fix(SHBS-2): Factory-Partition auf 4-KiB-Grenze ausgerichtet
    [partitions.csv]
2026-06-05 v0.00.001 fix(SHBS-2): WebServer-API und TaskControl-Build-Fehler behoben
    [main.c]
2026-06-05 v0.00.001 fix(SHBS-2): LED-GPIOs auf ESP32-S3-Pinout angepasst
    [LED.h]
2026-06-05 v0.00.001 fix(SHBS-2): Factory-Partition 0x263000 und 16-MB-Flash konfiguriert
    [partitions.csv]
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2026-06-05 v0.00.001 fix(SHBS-2): Produktname und Hostname auf SmartHome-Basisstation vereinheitlicht
    [main.c]
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2026-06-06 v0.00.001 fix: sessionStart-Hook auf PowerShell umgestellt
    Node ist in Cursors Hook-Umgebung unter Windows nicht im PATH; PowerShell-Skript liefert nun zuverlaessig additional_context.
2026-06-07 v0.00.001 fix(SHBS-2): ERC Layout bereinigt — PS2 +VOUT als Power output
    PWR_FLAG-Konflikte (#FLG05/#FLG06) entfernt, +3V3-Versorgung und PWR_FLAG am +12V ergänzt. Pin-Typ +VOUT im Symbol TSR_1-2433E auf Power output gesetzt — ERC /Layout/ ohne Fehler.
    [BasisStation_Layout.kicad_sch]
2026-06-08 v0.00.001 chore: Agent-Report-System, IDE-Toolchain und Layout-Korrekturen
    AGENTS.md um tmp/report/-Workflow (§12) erweitert, Cursor-Rule angepasst.
    VS Code/clangd auf ESP32-S3 und IDF 5.5.2 konfiguriert (.clangd neu).
    KiCad Layout: PS2-Referenz, Footprint-Pfad und Pin-Reihenfolge korrigiert.
    [BasisStation_Layout.kicad_sch]
2026-06-09 v0.00.001 fix(SHBS-7): U6 auf ESP32-S3-WROOM-1U-N16R8-Symbol umgestellt
    Espressif-Stil-Symbol in Bauteile-Bibliothek, sym-lib-table ergänzt.
    Schaltplan, Netlist und PCB-Value für U6 auf N16R8 vereinheitlicht.
    ERC ohne Fehler (ERC.rpt aktualisiert).
    [BasisStation.kicad_pcb, BasisStation_Layout.kicad_sch]
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2026-08-30 v0.00.001 fix: GitHub-MCP-Server auf PAT-Auth statt OAuth umgestellt
    OAuth scheitert an einem bekannten Claude-Code-Bug (Dynamic Client
    Registration wird von api.githubcopilot.com nicht unterstuetzt, betrifft
    auch andere Anbieter wie Slack/Box). Workaround: Authorization-Header mit
    Personal Access Token aus der Umgebungsvariable GITHUB_PAT, kein Secret
    in der committeten Datei.
2026-09-08 v0.00.001 fix(SHBS-4): +3V3 global verbunden, Symbolbibliothek entkoppelt
    Die Projektbibliothek war in sym-lib-table unter dem Nickname "power"
    registriert und verdeckte damit die gleichnamige KiCad-Standardbibliothek.
    power:GND (28x), power:PWR_FLAG und power:+3V3 waren dadurch projektweit
    nicht aufloesbar. Nickname auf "shbs_power" geaendert, lib_id von PS1 und
    J_PWR1 samt ihrer lib_symbols-Cache-Eintraege nachgezogen. Alle uebrigen
    power:*-Referenzen bleiben unveraendert und loesen jetzt gegen die
    KiCad-Standardbibliothek auf.
    Darauf aufbauend: +3V3 lag auf beiden Blaettern als lokales Label vor und
    war damit blattlokal - der Buck-Ausgang erreichte U6 nicht (ERC
    power_pin_not_driven an U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
    [BasisStation_Layout.kicad_sch, Stromversorgung.kicad_sch]
2026-09-08 v0.00.001 fix(SHBS-4): C8 Pin 1 an 3,3-V-Netz angeschlossen
    C8 Pin 1 liegt bei (66,04 / 25,40), der zugehoerige Draht endete bei
    (66,04 / 22,86) - ein Rasterversatz von exakt 2,54 mm (100 mil). Der
    Stuetzkondensator war damit nicht angeschlossen (ERC: pin_not_connected
    an C8 Pin 1, zusaetzlich unconnected_wire_endpoint).
    Drahtsegment (66,04 / 22,86) -> (66,04 / 25,40) ergaenzt. C8 Pin 1 liegt
    jetzt im 3,3-V-Netz von U6 (mit C10, C12, J6, R9).
    [BasisStation_Layout.kicad_sch]
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2026-09-08 v0.00.001 fix(SHBS-4): Fehlende Symbolbibliotheken registriert
    WCAP-FTXX_P10, WCAP-PT5H_6.3X5.2, WL-TMRC_3MM und 1543-650-149 liegen als
    Datei unter pcb/Symbol/ vor, waren aber nicht in sym-lib-table eingetragen.
    Dadurch schlug "Symbole aus Bibliothek aktualisieren" fuer C7, C8, C10, C12,
    D7 und S2 fehl (report.txt) und ERC meldete 6x lib_symbol_issues.
    Vier Eintraege nach dem Muster des bestehenden Espressif-Eintrags ergaenzt.
    Verifiziert: je Eintrag existiert die Datei und enthaelt das gleichnamige
    Symbol. Die uebrigen nicht registrierten Nicknames (Device, Diode,
    Connector, Connector_Generic, Power_Protection, Transistor_BJT, power) sind
    KiCad-Standardbibliotheken und brauchen keinen Pro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
2026-09-08 v0.00.001 fix(SHBS-4): Footprint-Referenzen der Projektsymbole vereinheitlicht
    Die Symboldefinitionen von WCAP-PT5H_6.3X5.2, 1543-650-149 und WL-TMRC_3MM
    verwiesen auf gleichnamige Footprint-Bibliotheken, die nicht existieren -
    fp-lib-table kennt nur "Footprints" (${KIPRJMOD}/../Footprints), wo alle
    .kicad_mod-Dateien liegen. Sichtbar wurde das erst, nachdem die Symbole
    durch 0268e9a aufloesbar wurden (3x footprint_link_issues im ERC).
    Footprint-Feld in den drei .kicad_sym auf Footprints: umgestellt, passend
    zu den Schaltplan-Instanzen von C8, S2 und D7. Damit sind Bibliothek und
    Instanz konsistent und ein kuenftiges "Symbole aus Bibliothek
    aktualisieren" ueberschreibt die Instanz-Referenz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
2026-09-15 v0.00.001 fix(SHBS-4): PWR_FLAG an VBUS, VIN und Buck-Ausgang ergaenzt
    Das Projekt enthielt keine einzige platzierte PWR_FLAG - die bisherige
    Annahme "4x im Layout" zaehlte Treffer in der lib_symbols-Definition,
    nicht Instanzen. Dadurch meldete die ERC power_pin_not_driven an
    J_PWR1.A4 [VBUS] und PS1.5 [VIN].
    Drei Flags noetig statt zwei: F1 und L1 sind passiv und propagieren keine
    Power-Quelle, der 3,3-V-Rail hat gar keinen Power-Output-Pin.
    #FLG01 VBUS vor F1 Stich ab (226,06 / 78,74)
    #FLG02 VIN hinter F1 Stich ab (190,5 / 83,82)
    #FLG03 Buck-Ausgang Stich ab (181,61 / 138,43)
    Per ERC-Lauf 2026-09-15 21:39 bestaetigt: Fehler 4 -> 2, die beiden
    Eingangsfehler entfalle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
    [Stromversorgung.kicad_sch]
2026-09-15 v0.00.001 fix(SHBS-4): shbs_power wiederhergestellt, +3V3 auf U6-Schiene
    Zwei Ursachen, die der ERC-Lauf vom 2026-09-15 offengelegt hat.
    sym-lib-table: Der Merge d7a21e2 hat (name "shbs_power") wieder auf
    (name "power") zurueckgesetzt und damit die Entkopplung von der
    KiCad-Standardbibliothek rueckgaengig gemacht. Folge: power:GND (28x),
    power:+3V3 und power:PWR_FLAG nicht aufloesbar, shbs_power unbekannt fuer
    PS1 und J_PWR1. Zusaetzlich waren WCAP-FTXX_P10, WCAP-PT5H_6.3X5.2,
    WL-TMRC_3MM und 1543-650-149 nie als Symbolbibliotheken registriert.
    Zusammen 42 der 46 Warnungen.
    BasisStation_Layout.kicad_sch: Das Netz an U6 Pin 2 (C8.1, C10.1, C12.1,
    R9.1, J6.2, U6.2 - 15 Draehte) trug weder La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
    [BasisStation_Layout.kicad_sch]
2026-09-15 v0.00.001 fix(SHBS-4): Footprints fuer F1 und R17-R20 zugewiesen
    Pruefung ueber alle Blaetter ergab acht Bauteile ohne Footprint-Feld.
    Ohne Zuweisung uebernimmt der PCB-Abgleich (F8) sie nicht, was den
    anstehenden Netzlisten-Export blockiert haette.
    F1 Fuse:Fuse_1206_3216Metric
    R17-R20 Resistor_SMD:R_0805_2012Metric
    Werte gemaess Stueckliste in docs/project/power_supply.md. J1 bleibt
    offen bis SHBS-6 (Umstellung auf USB-C), ANT1 und ANT2 sind BOM-only
    und bewusst ohne Footprint.
    [Stromversorgung.kicad_sch]
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2026-09-15 v0.00.001 fix(SHBS-4): Buck-Ausgangszweig korrigiert, ERC fehlerfrei
    Der Ausgangszweig des MP2359 war so verdrahtet, dass das Netz mit dem
    +3V3-Label elektrisch der Schaltknoten SW war. D11 lag verpolt hinter L1
    (Anode am Ausgang, Kathode an GND) und haette den Ausgang kurzgeschlossen,
    C15 lag gegen GND statt als Bootstrap zwischen BST und SW, wodurch der
    MP2359 sein High-Side-Gate nicht haette treiben koennen, und C14/R17
    hingen am Schaltknoten statt am geglaetteten Ausgang.
    Korrektur vom Bediener in der KiCad-GUI ausgefuehrt, Vorlage siehe
    tmp/report/2026-09-15_shbs-4-buck-ausgangszweig.md. Netzpruefung aus der
    Schaltplandatei:
    SW PS1.6, C15.2, D11.1 (K), L1.2
    BST PS1.1, C15.1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
    [BasisStation_Layout.kicad_sch, Stromversorgung.kicad_sch]
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2026-09-17 v0.00.001 fix(SHBS-9): LED-Treiber Q1-Q4 mit Basiswiderstaenden und unkritischen GPIOs
    Die Treiberstufen der vier Status-LEDs hingen ohne Basisvorwiderstand
    direkt an den GPIO-Pins des ESP32-S3. Die Basis-Emitter-Strecke klemmt
    den Pin auf ca. 0,7 V, sodass der Pin-Strom nur durch die
    Treiberimpedanz begrenzt wurde.
    - R23-R26 (4,7 kOhm) zwischen GPIO und Basis ergaenzt, Basisstrom nun
    ca. 0,55 mA je Zweig
    - LEDs von den Strapping-Pins GPIO3/45/46 auf GPIO21/38/47/48 umgelegt;
    diese haben keine Strapping-, ADC- oder Touch-Funktion
    - GPIO3, GPIO45 und GPIO46 sind damit frei, GPIO35-37 bleiben fuer das
    Octal-PSRAM des Moduls N16R8 unbeschaltet
    ERC: 0 Fehler, 9 Warnungen (unveraendert zu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
    [BasisStation_Layout.kicad_sch]
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2026-09-17 v0.00.001 refactor(SHBS-12): KiCad-Bibliotheken auf Bauteilordner umgestellt
    Symbol, Footprint und 3D-Modell eines Bauteils lagen bisher in drei
    getrennten Sammelordnern. Jedes Bauteil hat jetzt einen eigenen Ordner
    unter pcb/Bauteile/; pcb/Symbol/, pcb/Footprints/ und pcb/3D-Model/
    entfallen.
    Umfang: 20 Dateien verschoben, 13 verwaiste entfernt, 63 Footprint-
    Referenzen in Schaltplaenen, Netzliste und Board umgeschrieben, 7
    Footprint-Vorgaben in den Symbol-Dateien angepasst.
    Nebenbei behoben:
    - Die 3D-Modelle waren im Board ueber absolute Pfade auf E: und in der
    Netzliste auf C: verdrahtet, funktionsfaehig jeweils nur auf einem
    Rechner. Jetzt durchgaengig ueber ${KIPRJMOD}.
    - Drei Foo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
    [6120XX21621_61200621621.step, 6120XX21621_61201021621.step, BasisStation.kicad_pcb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]
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2026-09-17 v0.00.001 fix(SHBS-6): Debugging-Blatt wiederhergestellt, JTAG-Header entfaellt
    Das Blatt BasisStation_Debugging.kicad_sch war beim Anlegen des neuen
    Ethernet-Blatts ueberschrieben worden und enthielt nur noch einen leeren
    Rumpf. Aus dem letzten Commit zurueckgeholt; J1, U1, R21 und R22 sind
    wieder da. Die interne UUID stimmt mit der Referenz im Wurzelblatt
    ueberein, die Annotation bleibt damit erhalten.
    Der 10-polige JTAG-Header J5 wurde bewusst entfernt: Der ESP32-S3 bringt
    USB-Serial-JTAG im Chip mit, On-Chip-Debugging laeuft ueber J1. Das spart
    einen Steckverbinder und dessen Platinenflaeche.
    Doku nachgezogen: Schnittstellentabelle in hardware.md, Begruendung der
    LED-Pinwahl (GPIO3 ble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
    [BasisStation.kicad_sch, BasisStation_Layout.kicad_sch, ethernet.kicad_sch]
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2026-09-18 v0.00.001 fix(SHBS-5): RX-Pinvertauschung behoben, Schirmung und MDI-Abgleich
    Das selbst erstellte W5500-Symbol hatte die Pinnummern von RXN und RXP
    vertauscht: Das Datenblatt Rev. 1.0.5 nennt Pin 5 als RXN und Pin 6 als
    RXP, im Symbol war es umgekehrt. Wer nach den sichtbaren Pinnamen
    verdrahtet, haette das Empfangspaar verpolt - ERC meldet so etwas nie.
    Korrigiert durch Tausch der Pinnummern statt der Namen, damit die
    bestehende Verdrahtung ohne Umzeichnen richtig wird. Der gecachte
    Symbolabzug im Schaltplan wurde gleich mitgezogen.
    Schirmung fertiggestellt: T1.S1 und T1.S2 auf ein eigenes Netz CHASSIS,
    gekoppelt ueber C28 mit 1 nF/2 kV nach GND, dazu R35 mit 0 Ohm als
    unbestueckte Brueck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
    [ethernet.kicad_sch]
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2026-09-18 v0.00.001 fix(SHBS-5): Footprints ergaenzt, drawio-Diagramm gestrichen
    Die BOM-Auswertung zeigte 13 Kondensatoren ohne Footprint - C16 bis C28.
    Ohne Footprint landen sie beim Uebertragen der Netzliste nicht auf dem
    Board. Alle auf Capacitor_SMD:C_0805_2012Metric gesetzt, ausser C28: Der
    bekommt wegen der 2 kV vorlaeufig 1206, endgueltig nach Auswahl des Typs.
    Damit tragen alle 35 Bauteile des Ethernet-Blatts einen Footprint.
    Das drawio-Architekturdiagramm wurde gestrichen. Es lag in drei Dateien
    vor, war an vier Stellen veraltet - +24V, USB-UART-Bridge, JTAG-Header
    und fehlendes Ethernet - und duplizierte das Textdiagramm in
    architecture.md, das versioniert und im Diff sichtbar ist. Der Ver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
    [BasisStation.csv, BasisStation_Debugging.kicad_sch, BasisStation_Layout.kicad_sch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]
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2026-09-22 v0.00.001 fix(SHBS-14): Verwaiste Schaltplan-Datei BasisStation_architektur entfernt
    BasisStation_architektur.kicad_sch war in der Schaltplan-Hierarchie nicht
    referenziert - weder im Root-Blatt noch in der sheets-Sektion von
    BasisStation.kicad_pro. Die Datei ging damit in kein ERC, keine Netzliste
    und keine Stueckliste ein. Als verwaist erkannt wurde sie bereits am
    2026-09-06 (Befund B6).
    Verifikation: ERC-Report und Netzliste vor und nach dem Loeschen gediffed,
    beide identisch.
    Nebenbefund: Die Schaltplan-Aufzaehlung in docs/project/hardware.md nannte
    Stromversorgung.kicad_sch und ethernet.kicad_sch gar nicht. Die Zeile listet
    jetzt das Root-Blatt mit allen vier Unterblaettern.
    Co-Author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
    [BasisStation_architektur.kicad_sch]
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2026-09-22 v0.00.001 fix(SHBS-14): Leitungsstummel am EN-Netz entfernt
    ERC-Warnung unconnected_wire_endpoint in BasisStation_Layout.kicad_sch: Am
    Netz EN lief eine Leitung von (52,07 / 55,88) nach (62,23 / 55,88), waehrend
    das Label EN bei (59,69 / 55,88) sitzt. Die letzten 2,54 mm standen ins
    Leere.
    Endpunkt auf die Label-Position gezogen. Elektrisch folgenlos - das Netz EN
    war korrekt verbunden.
    Verifikation: ERC von 7 auf 6 Warnungen, keine neue Warnung entstanden.
    Netzliste identisch, /Layout/EN weiterhin J6.1 + S2.2 + U6.3.
    [BasisStation_Layout.kicad_sch]
2026-09-22 v0.00.001 fix(SHBS-14): Symbol-Cache aufgefrischt und ERC-Ausnahmen hinterlegt
    Arbeit des Bedieners in der KiCad-GUI, da beides keinen CLI-Befehl hat.
    Symbol-Cache in BasisStation_Layout.kicad_sch aus den auf KiCad 9 gehobenen
    Bibliotheken neu geschrieben. Damit sind die vier lib_symbol_mismatch-
    Warnungen (S2, C7, C10, C12) abgeraeumt.
    Zwei ERC-Ausnahmen in BasisStation.kicad_pro hinterlegt, jeweils mit
    Begruendung:
    - pin_to_pin an S2/#FLG04 - GND-PWR_FLAG aus SHBS-6, KiCad-Standardweg
    - multiple_net_names GND/EPAD an U6.41 - versteckter EPAD-Pin auf GND
    Verifikation: Konnektivitaet der Netzliste bitweise identisch zum Stand vor
    SHBS-14 (102 Netze), Stueckliste identisch (78 Zeilen) - di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
    [BasisStation_Layout.kicad_sch]
2026-09-22 v0.00.001 docs(SHBS-14): Bestandsaufnahme, Tasks und Folgebefund dokumentiert
    Report tmp/report/2026-09-22_schaltplan-abschluss-bestandsaufnahme.md mit der
    vollstaendigen Bestandsaufnahme des Schaltplans: 0 ERC-Fehler, 102 Netze,
    76 Bauteile alle mit Footprint, ERC-Schweregrade auf KiCad-Standard ohne
    Ausnahmen, 40 Ein-Pin-Netze allesamt automatisch benannte unconnected-*.
    Task 0031: Die Scheinaenderung an ethernet.kicad_sch war kein CRLF-Problem
    im Index, wie zunaechst angenommen, sondern ein veralteter Stat-Cache. HEAD,
    Index und Arbeitsverzeichnis tragen denselben Blob-Hash, .gitattributes ist
    korrekt. Die Task-Datei haelt die Fehldiagnose und ihre Richtigstellung
    fest.
    Task 0037 neu: m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
    [ethernet.kicad_sch]
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2026-09-22 v0.00.001 fix(SHBS-14): U6 Pin 41 von EPAD auf GND umbenannt, ERC sauber auf Null
    Versteckte power_in-Pins verbinden sich in KiCad implizit mit einem globalen
    Netz, das nach dem Pinnamen heisst. U6 Pin 41 hiess EPAD und war zugleich
    explizit auf GND verdrahtet - daraus entstand multiple_net_names.
    KiCad erzeugte davon mehrere Instanzen, die den Pin je nach
    Durchlaufreihenfolge mit unterschiedlichen GND-Power-Symbolen paarten
    (#PWR04, #PWR05, #PWR06). Die in Task 0035 hinterlegte Ausnahme deckte nur
    eine davon ab: Die GUI meldete 0, das CLI weiterhin 1. Ein Ausschluss per
    UUID haette hier nie dauerhaft getragen.
    Behoben an der Wurzel (Option A, vom Bediener entschieden): Pin 41 in
    pcb/Baute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
    [BasisStation_Layout.kicad_sch]
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2026-09-22 v0.00.001 feat(SHBS-15): Stueckliste reproduzierbar erzeugt und mit Mouser-Daten angereichert
    Die Stueckliste entsteht nicht mehr ad hoc, sondern durch ein versioniertes
    Skript unter tmp/bom/ (sexp.py, generate_bom.py, write_xlsx.py).
    Warum nicht kicad-cli sch export bom: Teilenummern liegen im Projekt unter
    uneinheitlichen Feldnamen, je nach Herkunft des Symbols (SnapEDA,
    Wuerth-Generator, handgepflegt) - Manufacturer_Part_Number, MP, Part Number,
    MOUSER_PART_NUMBER. --fields nimmt nur einen festen Namen und liefert fuer
    den Rest still eine leere Spalte. Genau daran scheiterte der erste Export.
    Ergebnis: 46 Positionen ueber 78 bestueckte Referenzen, 15 davon mit Preis
    und Lagerbestand aus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
    [2026-09-22_stueckliste-basisstation.xlsx]
2026-09-23 v0.00.001 fix(SHBS-16): ANT2 auf Seriennachfolger GW.20.A151 umgestellt
    Taoglas GW.20.5150 ist abgekuendigt - der Typ steht nicht mehr im
    Taoglas-Katalog. Ersetzt durch den Seriennachfolger GW.20.A151: form-,
    anschluss- und gewinngleich (2 dBi, 2,4 GHz, RP-SMA(M) gerade).
    Zusaetzlich ist Taoglas bei Mouser auf das 960er-Praefix umgezogen, die
    alten 742er-Nummern liefern keinen Treffer mehr. Sechs Felder in
    BasisStation_Layout.kicad_sch:
    - ANT2 Value und Manufacturer_Part_Number: GW.20.5150 -> GW.20.A151
    - ANT2 Mouser Part Number: 742-GW.20.5150 -> 960-GW.20.A151
    - ANT1 Mouser Part Number: 742-CAB.6061 -> 960-CAB.6061
    - beide Produktlinks auf die aktuellen Seiten
    Kein Footprint betroffen: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
    [2026-09-22_stueckliste-basisstation.xlsx, BasisStation_Layout.kicad_sch]
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2026-09-23 v0.00.001 feat(SHBS-17): PS1 auf AP3211 umgestellt, V_FB-Formel in der Doku korrigiert
    Der MP2359 ist in allen Varianten NRND und ohne Lager. Ersetzt durch den
    pinkompatiblen Diodes AP3211KTR-G1 (SOT-23-6, V_FB 0,81 V, 1,4 MHz,
    asynchron, 1,5 A). Symbol in shbs_power:AP3211 umbenannt, Felder in
    Schaltplan und power.kicad_sym umgestellt; Footprint MP2359DJ passt
    unveraendert. ERC 0 Fehler, Netzliste an PS1 unveraendert. L1-Saettigung
    (4,6 A) gegen Strombegrenzung (max. 2,4 A) geprueft.
    power_supply.md: V_OUT-Formel nannte 0,6 V statt 0,81 V.
    [2026-09-22_stueckliste-basisstation.xlsx, Stromversorgung.kicad_sch]
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2026-09-23 v0.00.001 fix(SHBS-16): D10-Verpolung behoben, LED-Symbole vereinheitlicht, FB1 und J6 bereinigt
    Footprint WL-TMRC_3MM hatte Pad 1 = Anode, Device:LED hat Pin 1 = Kathode: D10 lag mit der Kathode an +3V3 und haette nie geleuchtet. Footprint auf Pad 1 = K / Pad 2 = A umnummeriert (wie WL-TMRW_3MM), Wuerth-Symbol mitgezogen. D7 von WL-TMRC_3MM auf Device:LED, so platziert, dass K/A auf den bisherigen Drahtenden liegen. FB1 auf Device:FerriteBead, J6-Wert auf 61200621621.
    Gegenprobe: ERC 0 Fehler; Netzliste mit gleichen Bauteilen je Netz, nur D7-Pinnummern getauscht; Polaritaet aller vier LEDs auf Pad-Ebene geprueft. Beim naechsten PCB-Abgleich Footprint von D7/D10 aus der Bibliothek aktualisi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
    [2026-09-22_stueckliste-basisstation.xlsx, BasisStation_Layout.kicad_sch, ethernet.kicad_sch]
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2026-09-24 v0.00.001 fix(SHBS-4): 5-V-Schiene von PW_EN in lokale Labels +5V umbenannt, VBUS benannt
    Die 5-V-Schiene hinter F1 hiess nach dem Enable-Pin PS1.4 PW_EN und war als globales Label ausgefuehrt, obwohl beide Labels auf dem Blatt Stromversorgung liegen. Jetzt lokale Labels +5V; das bisher unbenannte Netz vor F1 heisst VBUS. Ein globales Label haette jedes gleichnamige Label auf einem anderen Blatt stillschweigend mit der 5-V-Schiene verbunden.
    Gegenprobe: Netzliste mit identischer Pin-Zuordnung, nur die zwei Netznamen geaendert; ERC 0 Fehler. Task 0001 Punkt B2 erledigt.
    [Stromversorgung.kicad_sch]
2026-09-24 v0.00.001 fix(SHBS-17): Q1-Q4 auf BC33740BU mit geraden Beinen, TA-Variante passte nicht auf TO-92_Inline
    Die Gurt-Variante BC33740TA hat auf 2,54 mm aufgebogene Anschlussbeine, der Footprint TO-92_Inline hat 1,27 mm Raster. Umgestellt auf onsemi BC33740BU (gleiches Datenblatt, gerade Beine, Pinbelegung C-B-E unveraendert). Beim systematischen Footprint-Abgleich aufgefallen: alle anderen 72 Bauteile passen zu ihrem Footprint.
    Gegenprobe: Netzliste identisch, Stueckliste 44 Positionen eindeutig und lieferbar.
    [2026-09-22_stueckliste-basisstation.xlsx, BasisStation_Layout.kicad_sch]
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2026-09-24 v0.00.001 fix(SHBS-20): USB-C J_PWR1 um VBUS-Pins B4/B9 und GND-Pins A12/B12 ergänzt
    Das Symbol shbs_power:USB_C_Receptacle_Power führte nur A1/B1/A4/A9, die
    Pads B4/B9/A12/B12 lagen ohne Netz. Die vier Pins sind jetzt unsichtbar
    und als passive auf A4/A9 bzw. A1/B1 gestapelt (kein versteckter
    power_in). Symbol-Cache im Schaltplan nachgezogen, power_supply.md
    aktualisiert. PCB-Anbindung der Pads siehe c2ccc4a.
    [Stromversorgung.kicad_sch]
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2026-09-29 v0.00.001 fix(SHBS-24): 3D-Modelle für C7/C10/C12, C8, J6, D7–D10 ergänzt
    Vorhandene Hersteller-STEPs für C7/C10/C12 und J6 verknüpft. C8 und die
    LEDs bekommen KiCad-Standardmodelle (180° gedreht, um den halben
    Pin-Abstand versetzt, passend zur Pad-Lage). PS1 von KISYS3DMOD/.wrl auf
    KICAD9_3DMODEL_DIR/SOT-23-6.step. Eintrag in Bibliotheks-Footprints und
    Platine, DRC unverändert. S2 bleibt ohne Modell (Hersteller unbekannt).
    [BasisStation.kicad_pcb]
2026-09-29 v0.00.001 fix(SHBS-24): S2-Modell erstellt, LEDs mit Würth-Originalmodellen, Z-Versatz übernommen
    S2 (Bourns 1543-650-149) hat kein frei verfügbares Herstellermodell; das
    STEP ist aus den Datenblattmaßen mit OpenCascade erzeugt (Gehäuse
    9,8 × 9,8 × 7,3 mm auf 1,0 mm Füßen, Stößel Ø 4,1 mm, Gesamthöhe 14,9 mm).
    D7–D10 nutzen jetzt die vorhandenen Würth-Modelle statt des KiCad-Ersatzes.
    Den vom Bediener gesetzten Z-Versatz (C7/C10/C12 6 mm, J6 4,5 mm) in die
    Bibliotheks-Footprints übernommen. DRC unverändert. Task 0053 abgeschlossen.
    [1543-650-149.step, BasisStation.kicad_pcb]
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2026-09-30 v0.00.001 fix(SHBS-36): Zonen mit KiCad 10 neu gefüllt, Board im KiCad-10-Format
    [BasisStation.kicad_pcb]
2026-09-30 v0.00.001 fix(SHBS-37): Footprint-Felder mit Schaltplan abgeglichen (Datasheet, S2)
    [BasisStation.kicad_pcb]
2026-09-30 v0.00.001 fix(SHBS-38): J1 auf projekteigenes USB-C-Symbol mit Schirm-Pin S1 umgestellt
    [BasisStation_Debugging.kicad_sch]
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2026-09-30 v0.00.001 fix(SHBS-41): LED-Treiberstufe entfernt, Widerstände auf 0805, LEDs liegend
    Q1-Q4 und R23-R26 entfallen, die LEDs hängen direkt am GPIO
    (GPIO -> Vorwiderstand -> LED -> GND). R13-R16 und R9 als 0805,
    R14 (blau) 100 Ohm. D7-D10 mit liegendem Footprint
    LED_D3.0mm_Horizontal_O1.27mm_Z2.0mm. ERC 0/0.
    [BasisStation.csv, BasisStation_Layout.kicad_sch]
2026-09-30 v0.00.001 fix(SHBS-42): Layout an Schaltplan angeglichen und über die Platine verteilt
    Buck-Wandler, C7/C10/C12, R9 und J6 in die untere Hälfte verlegt,
    Mindestabstand der Courtyards 1 mm. LEDs liegend an der Unterkante,
    Linse bündig in der Gehäusewand. Betroffene Netze mit Freerouting
    neu geroutet, GND-Insel unter U7 aufgelöst. DRC mit Schaltplan-
    abgleich 0/0/0, 17 begründete Ausschlüsse.
    [BasisStation.kicad_pcb]
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2026-09-30 v0.00.001 fix(SHBS-52): ESP32-S3 in die rechte Platinenhälfte verlegt
    U6 bei 185/90, um 90 Grad gedreht, U.FL-Stecker zur rechten Wand.
    C8 und C7/R9 über U6 an den Pins, C10/C12 darunter. Netze von U6 neu
    geroutet, GND-Insel an U1 aufgelöst, J6-Pad 4 per Via angebunden.
    DRC mit Schaltplanabgleich 0/0/0.
    [BasisStation.kicad_pcb]
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2026-09-30 v0.00.001 fix(SHBS-45): Platinen-STEP auf Layoutstand SHBS-52 aktualisiert
    - enclosure/reference/basisstation_pcb.step: neu exportiert (U6 rechts auf
    halber Höhe, C7/C10/C12 verschoben)
    - enclosure/basisstation_enclosure.FCStd: Platine neu importiert
    - .gitignore: FreeCAD-Sicherungsdateien (*.FCBak) ignoriert
    [basisstation_enclosure.FCStd, basisstation_pcb.step]
